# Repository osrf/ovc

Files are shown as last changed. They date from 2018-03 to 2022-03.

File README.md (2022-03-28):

# Open Vision Computer (OVC)

Here is an outdated-but-maybe-interesting [overview presentation of the project](https://docs.google.com/presentation/d/1NCimNJTRP6g3ESWhmaqi4t3dOprq7Yvne_JLeCTt3io/edit?usp=sharing) (March 2018).

This repo contains hardware, firmware, and software for an open-source embedded
vision system: the Open Vision Computer (OVC). The goal is to connect state of
the art open hardware with open firmware and software. There are a few revs:

 * ovc0: three Python1300 imagers, an Artix-7 FPGA, DRAM, and USB3 via a Cypress FX3 controller.
 * ovc1: two Python1300 imagers, a Jetson TX2 (6x ARMv8, GPU, etc.) connected to a Cyclone-V GT FPGA over PCIe.
 * [ovc2](doc/ovc2a/README.md): two Python1300 imagers, a Jetson TX2 (6x ARMv8, GPU, etc.) connected to a Cyclone 10 GX FPGA over PCIe Gen 2.0 x4
 * ovc3: three ON Semi AR0144CS imagers, USB Type-C peripheral, Trenz TE0820 module with Xilinx Zynq UltraScale+, RAM, flash, etc. Up to four optional external camera boards, each of which add a pair of AR0144CS imagers.
 * ovc4: A Jetson Xavier NX carrier board with an NXP MCU, USB Type-C interface and six Picam compatible connectors.
 * ovc5 (current work): based on Zynq UltraScale+ modules from Enclustra, with up to six external MIPI camera boards. Both Zynq USB SuperSpeed (5 Gbps) transceivers connect to an onboard USB-SS+ (10 Gbps) hub controller IC, which multiplexes them upstream via a USB type-C connector. Also has three Qwiic/STEMMA connectors and some random FPGA GPIO for low-speed expansion.

# Where do I find stuff

Each camera family has its own directory in this repository that contains its relevant hardware, firmware, and software.

# Hardware Design

We are using the very latest KiCAD: the nightly development builds.
Installation instructions are here: https://www.kicad.org/download/ubuntu/

Once you have installed `kicad-nightly` on your machine, then you will
need to set up the repos as follows:

```
mkdir ~/hw
cd ~/hw
git clone ssh://git@github.com/osrf/osrf_hw
git clone ssh://git@github.com/osrf/ovc
```

Add the following line to your .bashrc file to set the KIWORKSPACE environment variable to point at your hardware folder:

```
export KIWORKSPACE=~/hw
```

Then you should be able to view the latest developments:
```
cd ~/hw/ovc/ovc5/hardware/carrier
kicad-nightly ovc5.kicad_pro
```

---

#### Software License
[Apache Version 2.0](https://github.com/osrf/ovc/blob/master/LICENSE)

#### Hardware License
[CERN-OHL-P](https://github.com/osrf/ovc/blob/master/LICENSE_HARDWARE)

#### Documentation License
<br />This work is licensed under a <a rel="license" href="http://creativecommons.org/licenses/by/4.0/">Creative Commons Attribution 4.0 International License</a>.

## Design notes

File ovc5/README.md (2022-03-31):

# ovc5

The OVC5 is basically a 6 port USB3 Gen 2 (10 Gbps) hub with the following devices:
* 2x USB3 Gen 1 (5 Gbps) ethernet over USB devices, assigned to subnets 10.0.1.x and 10.0.2.x, connected to the Zynq and used to stream the imagers in parallel.
* 2x USB3 Gen 2 (10 Gbps) ports available for connection to third party devices, currently because of hardware quirks they are one USB A (on the top connector) and one USB C.
* 1x USB2 device connected to the onboard FTDI chip for serial debugging of the Zynq.
* 1x unused port (not routed).
* 3x Extra connectors following the STEMMA / QWIIC standard for quick integration of external devices.

It is also fully modular and any configuration of sensors can be plugged to the MIPI connectors, they will be detected at runtime and streamed over USB, provided a driver has been written for them, a reference driver is provided for the PI camera v2 based on IMX219.
The idea is that OVC5 can be a single sensor integration center for mobile robot applications (i.e. robot heads) which can synchronize and stream up to 10 Gbps of heterogeneous data coming from a variety of sensors over a single USB connection. Since OVC5 is a USB hub and exposes two downstream ports while only using one, it actually increases the number of ports available to whatever processing system it connects to, rather than decreasing it.

## Directory Summary
* __Hardware__: PCB schematic and layout is here. This project uses `kicad-nightly`.
* __Firmware__: FPGA source is located here. This project uses the Xilinx Ultrascale+ chipset. Vivado is used to design and export the bitstream that executes on the FPGA.
* __Scripts__: These are convenience scripts for automating large portions of the setup and run-time process.
* __Software__: Software that runs on the host and the arm core to pass sensor information.

## Setup Process
1. After assembling OVC5, use the [provisioning script](https://github.com/osrf/ovc/blob/master/ovc5/scripts/install_sd.sh) to generate an SD card image. This can then be loaded into the OVC5 device port.
2. Connect power and (optionally ethernet) to the device. The ethernet should be connected to the same LAN as your computer.
3. Connect the OVC5 to a USB3 Super Speed (preferably 10Gbps capable) port. This will provide the correct bandwidth for streaming high resolution/framerate images. Because of a quirk in the USB hub chip and its flexconnect feature not quite working yet, you will need to connect using a USB 3 A-A cable to the _bottom_ connector of the USB A stack (the one closer to the PCB).
4. Wait a minute or two and run `ssh root@zynq.local`. You may also attempt to ping it until it responds.
    * The default password, as defined in the provisioning script, is `temppwd`.
5. USB Ethernet should be already up (you can check by running `ip a` on your host machine. If it isn't you can initialize it manually by running the startup script located in the home directory [`startup.sh`](https://github.com/osrf/ovc/blob/master/ovc5/scripts/startup.sh)
6. Use `git` to clone in the latest OVC version. Now compile the [camera device driver](https://github.com/osrf/ovc/tree/master/ovc5/software/camera_device_driver).
7. On the host machine, compile [`libovc`](https://github.com/osrf/ovc/tree/master/ovc5/software/libovc) and the [camera host driver](https://github.com/osrf/ovc/tree/master/ovc5/software/camera_host_driver). This can be accomplished using the [`Makefile`](https://github.com/osrf/ovc/blob/master/ovc5/software/Makefile).
    * __NOTE__: the makefile `all` target compiles the camera driver as well. This is just to sanity check when not editing on an OVC device. Remove `device_driver` from all or install `i2c-tools` to not fail this build step.

## Execution
1. On the host machine, run `make run_host`. This creates a server for OVC5 to connect to.
2. On OVC5 (via ssh), run (from software) `./camera_device_driver/build/ovc5_driver`. This connects to the host server and immediately starts streaming sensor data.
3. To stop execution, use `ctrl + C`. Always stop execution on the device first otherwise sensors will not be reset properly. This can cause abnormal behavior in the following execution (unless power is reset or the script is properly exited in the following execution).

## Renders
ovc5b_rendering

## Pictures
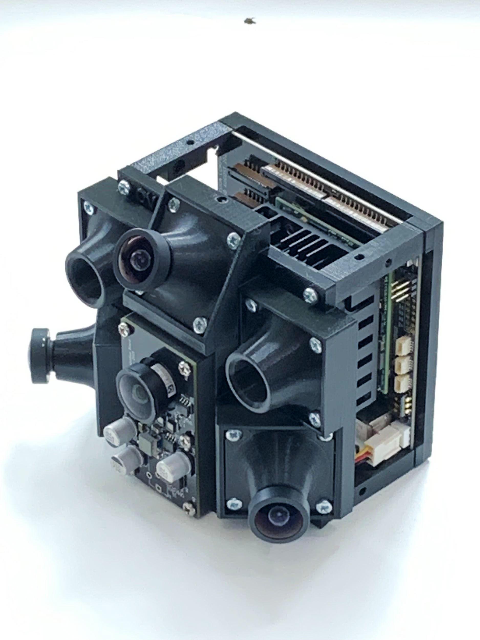
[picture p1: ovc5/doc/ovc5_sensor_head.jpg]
ovc5 sensor_head


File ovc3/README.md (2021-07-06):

# OVC 3 overview
OVC3 includes a Zynq Ultrascale+ SoC, with a quad core ARM application processor, two real time cores and FPGA fabric.
Currently the real time cores are not used, the quad core processor runs a full Ubuntu 18.04 distribution with ROS melodic and the FPGA fabric runs the interfaces to the imagers (through MIPI / I2C), the IMU (SPI) and the DMA to write data to external memory.

# Version notes

There are currently two versions of the OVC3
 - OVC3a: this is the old version of the OVC3. **Do not use unless you know what you are doing**. The firmware does not support this board, and you may damage your hardware.
 - OVC3b: most recent version of the OVC3. Changes compared to OVC3a:
   - Various hardware fixes. See `ovc/ovc3/hardware/ovc3a/ovc3a/camera/FIXME`
   - VectorNav carrier is mounted in the front of the platform.
   - More GPIO for the backpack.

## Setup

OVC 3 is running a full Ubuntu distribution and a ROS node in itself.
On startup, it will configure itself as a USB ethernet gadget with a static IP of 10.0.1.1 and ia DHCP server that will assign an IP of 10.0.1.2 to the connected host, it will then look for a ROS master in 10.0.1.2, once it is found it will start publishing images, IMU data, corner features and calibration data.

**The board should automatically assign an IP to your machine**, however if this doesn't work you can manually configure your PC to have a static IP.
To do so, edit your /etc/network/interfaces file and add the following:

~~~~
allow-hotplug enp9s0u1
iface enp9s0u1 inet static
  address 10.0.1.2
  netmask 255.255.255.0
  mtu 13500
  pre-up sleep 5 # Hack to wait for ovc networking to restart
~~~~

Please note, the name of the interface (enp9s0u1 in the example) might be different on your machine, to find out the interface name plug the OVC, wait for it to boot up and run

`ip a`

on your machine.

## Calibrating the sensor

The OVC is running a camera_info_manager, hence it exposes services to calibrate the camera and store the parameters in non volatile memory (they will be saved in the calibration subfolder of the driver).

To calibrate run the following command for the two monochrome sensors:

`rosrun camera_calibration cameracalibrator.py --size 8x6 --square 0.072 right:=/ovc/right/image_raw left:=/ovc/left/image_raw right_camera:=/ovc/right left_camera:=/ovc/left`

And the following for the RGB sensor:

`rosrun camera_calibration cameracalibrator.py --size 8x6 --square 0.072 image:=/ovc/rgb/image_raw -c rgb camera:=/ovc/rgb`

With the size and square parameters adapted to your checkerboard.

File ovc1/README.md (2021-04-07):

# ovc1

#### Update source tree
```
cd ~/ovc
git pull
```

#### Compile kernel module
```
cd ~/ovc/software/ovc1/ovc_module
make
```

#### Flash FPGA i/o image and reconfigure FPGA
The OVC1 uses a configuration microcontroller to set up the FPGA I/O ring to
allow PCIe-based configuration. This is great because it's super-fast, but it's
a bit more complicated because the FPGA image lives partly in the
microcontroller flash memory, and partly in the TX2 filesystem. As such, there
are a multiple steps to updating the FPGA image. Fortunately, the FPGA I/O
image should only change infrequently. Note that the microcontroller-flash
script only needs to be run when the FPGA I/O image changes; most updates
affect only the FPGA core, not the I/O ring.

```
cd ~/scripts
./flash_fpga_config.sh
./reconfigure_fpga.sh
```

#### Compile ROS package (userland)
```
mkdir -p ~/ros/src
ln -s ~/ovc/software/ovc1/ros/ovc ~/ros/src
cd ~/ros
catkin build
```

# Software development

For a typical software-development session (unless you need to re-flash and reconfigure the FPGA) you just need to load the kernel module. We'll automate this eventually, once it gets more stable, but for now (to avoid boot loops) let's leave the module-loading as a manual step...
```
~/scripts/init_fpga.sh
```
That script will load the OVC kernel module, configure the FPGA core using the blob in `~/ovc/firmware/ovc1/fpga/stable/ovc.core.rbf`, and re-load the OVC module to allocate DMA buffers.

Then, you can run the ROS image streamer and feature-visualizer nodes:

Terminal 1:
```
roscore
```

Terminal 2:
```
cd ~/ros
source devel/setup.bash
rosrun ovc ovc_node
```

Terminal 3:
```
rosrun ovc corner_viewer
```

I'm usually shelling into the camera and run "Terminal 3" on my workstation,
setting `ROS_MASTER_URI` as needed to point to the camera (adjust the camera
hostname as needed, if you have changed it from the default `tegra-ubuntu`):
```
export ROS_MASTER_URI=http://ovc.local:11311
rosrun ovc corner_viewer
```

#### Re-flashing MCU (uncommon)
In the event that the MCU is somehow horribly messed up and needs a total
re-flash, you can do the following actions to restore it, using the handy
`stm32flash` program. Unfortunately, because we're using a relatively new
MCU (STM32L452) we need to build it from souce, but it's not hard:
```
mkdir ~/mcu
cd ~/mcu
git clone https://git.code.sf.net/p/stm32flash/code stm32flash
cd stm32flash
make
```

First, we need to do a "button dance" in order to boot the MCU into its
bootloader. Note that the buttons are tiny. Be sure to ground yourself using
either a wrist-strap or diligently touching the HDMI connector shield before
risking unloading your body's static charge into the tiny components near
the buttons!
 * press and hold the `MCU_RESET` button
 * press and hold the `MCU_BOOT` button
 * release `MCU_RESET`
 * release `MCU_BOOT`
If done correctly, the MCU LED should light up. You can verify that the MCU
is in bootloader mode by querying it with `stm32flash`:
```
~/mcu/stm32flash/stm32flash /dev/ttyTHS1
```
If the MCU is alive and in bootloader mode, that command should print out some
information about the memory banks of the STM32.

Now, we can restore the MCU flash bank. First, make sure your checkout of the
`ovc` repo is up-to-date. On a TX2 shell:
```
cd ~/ovc
git pull
```
There should be a MCU firmware blob sitting in `~/ovc/firmware/ovc1/mcu/stable`
that we will now flash to the MCU:
```
~/mcu/stm32flash/stm32flash -v -w ~/ovc/firmware/ovc1/mcu/stable/ovc1_mcu.bin /dev/ttyTHS1
```
Once that operation has completed, you can push the `MCU_RESET` button and then
flash the FPGA I/O ring configuration:
```
~/ovc/software/ovc1/scripts/flash_fpga_config.sh
```
Then you should be able to configure the FPGA:
```
~/ovc/software/ovc1/scripts/reconfigure_fpga.sh
```
If all goes well, `lspci` should show the FPGA connected as device `1234:5678`

Hooray!

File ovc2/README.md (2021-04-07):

# ovc2

On the OVC2, the TX2 simply configures the FPGA over SPI. Because there are
no flash memories outside the TX2, the update process is considerably simpler
than on the OVC1.

#### Update source tree
```
cd ~/ovc
git pull
```

#### Compile kernel module
```
cd ~/ovc/software/ovc2/modules/ovc2_core
make
cd ~/ovc/software/ovc2/modules/ovc2_cfg
make
```
In case there is a compilation error for ovc2_core, try
```
cd /usr/src/linux-headers-4.4.38-tegra/
sudo make modules_prepare
```

#### Compile ROS package (userland)
```
mkdir -p ~/ros/src
ln -s ~/ovc/software/ovc2/ros/ovc2 ~/ros/src
cd ~/ros
catkin build
```

# how do I run stuff

For convenience, the `~/.bashrc` of the default `nvidia` user adds
`~/ovc/software/ovc2/scripts` to `$PATH`. Create a link for the `ovc2a.rbf` file (located at `~/ovc/firmware/ovc2/stable`) at the home folder.

Typically, all you need to run is the `ovc2_reconfigure` script, which does
the following:
 * unloads modules which use PCIe
 * loads the `ovc2_cfg` module, which creates a device node `/dev/ovc2_cfg` to expose a configuration interface to userland
 * writes the FPGA configuration from userland to the `/dev/ovc2_cfg` device, which in turn uses the TX2 SPI interface to configure the FPGA
 * loads the `pcie_tegra` module, which enumerates the PCIe bus and finds our newly-configured FPGA on it
 * loads the `ovc2_core` module, which provides a userland driver for ovc2 on three device nodes: `/dev/ovc2_core` `/dev/ovc2_cam` `/dev/ovc2_imu`

For a typical software-development session, you typically just type
`ovc2_reconfigure` and it's all automatic.

Then, you can run the ROS image streamer and feature-visualizer nodes:

Terminal 1:
```
roscore
```

Terminal 2:
```
cd ~/ros
source devel/setup.bash
rosrun ovc2 ovc2_node
```

Terminal 3:
```
rosrun ovc2 corner_viewer
```

I'm usually shelling into the camera, so "Terminal 1" and "Terminal 2" are
remote shells on the camera, and "Terminal 3" is running locally on my
workstation, setting `ROS_MASTER_URI` as needed to point to the camera (adjust
the camera hostname as needed):

```
export ROS_MASTER_URI=http://ovc2a3.local:11311
rosrun ovc corner_viewer
```

#### Powering Down

For reasons unknown at the moment, if you try to power down the TX2 without
first unloading the `ovc2_core` kernel module, the system will hang during
the shutdown process, requiring you to then hold the TX2 power button down
until the PMIC finally does a hard-shutdown.

If you run this script instead:
```
ovc2_poweroff
```
It will first unload the `ovc2_core` module and then run `poweroff`. It just
saves one step to type `ovc2_poweroff` instead.

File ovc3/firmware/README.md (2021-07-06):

## Getting started
In order to get the OVC up and running you will need to set up the boot medium, choosing between eMMC and SD card. We have observed better performance and reliability from the embedded eMMC module so it is suggested. SD boot should be used for the first setup and eventual recovery if it becomes impossible to boot from eMMC.

The first step suggested is to create an Ubuntu SD card that can be used to boot the module, and to flash the eMMC and onboard QSPI flash.
All the necessary files can be found [here](https://drive.google.com/drive/u/0/folders/1-6HdKNJr4VVOgUUyit0nssR-HQKv6Tt5). You will need the files:
- `SD images/image.ub`
- `SD images/boot.bin`
- `Flash images/rootfs.tar.gz`

### Creating the recovery SD card
* Follow the [Xilinx guide](https://xilinx-wiki.atlassian.net/wiki/spaces/A/pages/18841655/Prepare+Boot+Medium) to partition the SD card, then copy the image.ub and BOOT.bin files in the SD images into the boot partition.
* Extract the rootfs.tar.gz archive into the root partition (assuming the root was mounted under /media):
`tar -xvpzf rootfs.tar.gz -C /media/root --numeric-owner`.

Now it should be possible to boot through the SD card.

### Flashing the QSPI and eMMC
The rootfs image includes a script that will run on boot and will check the position of the user DIP switches and, if the flashing configuration is selected (booting from SD card - pin 2 HIGH and flashing enabled, pin 4 LOW) it will flash the eMMC with the latest bootable images available in the shared folder.
For the process to be successful, it is necessary that the OVC is connected to the internet, it is configured for DHCP on the ethernet port so connecting the Ethernet port to your router should be enough.

On SD boot the LEDs next to the RGB camera will be used to communicate to the user the status of the update in the following sequence:
1. Only red LED turned on: Flashing mode was detected, waiting for internet connection and downloading files from shared folder.
2. Red and green LEDs turned on: Images downloaded, flashing. Can take quite long (up to 30 minutes in our experiments).
3. Only green LED turned on: Flashing completed, when this happens flip the switch 4 back to HIGH and the board should poweroff (green LED turning off).

### Booting from eMMC
If the above process is successful it should be possible to boot from the onboard QSPI and eMMC without the need to have an SD card. Remove the SD card, flip switch 2 for eMMC boot (LOW) and turn on the board.
If the red LED on the trenz module turns off boot was successful and it should be possible to use the module.

Keep an eye on the shared drive for changes in boot images and rootfs for new features!

## Accessing the board
If anything goes wrong it might be useful to access the board, this can be done in two ways: 
 - Through the root linux console (exposed in the expansion pin header in the back of the board). You may use the `vectornav_carrier` board, which already has a USB-UART bridge.
 **Important: do not start the OVC with the root console connection enabled. It may halt the FSBL. Connect the USB after booting the OVC**.
 - Through SSH
   1. SSH from the usb ethernet interface: `ssh ubuntu@10.0.1.1`
   2. Connect the board to your router and ssh through host name `ssh ubuntu@arm.local`
   3. Same as above but use the IP that you should be able to see in your router control panel.

## Hacking the board and firmware generation
This folder contains all the source files needed to build the project, except the root file system itself (which is a custom version of Ubuntu 18.04 for the armv7 architecture and is only available in the shared drive).

The Vivado project including all the FPGA design can be found in the `test_board` folder, while the Petalinux project containing the kernel and device-tree customizations can be found in the `os` folder. Follow the instructions in `test_board/README.md` to generate the images.

## Board version pinout
**The pinout of the OVC3a is incompatible with the pinout of the OVC3b**. The
table below explains the differences:

|PIN |TE0820 PIN|FPGA PIN|OVC 3A |OVC 3B |
|---|---|---|---|---|
|JB1.69|B66 L24 P |C9 |BONUS1_RESET  |BONUS4_EXTCLK |
|JB1.71|B66 L24 N |B9 |BONUS1_FLASH  |BONUS4_SCL0 |
|JB1.79|B66 L21 P |A7 |AUX0 |BONUS4_SDA0 |
|JB1.81|B66 L21 N |A6 |AUX1 |BONUS4_SCL1 |
|JB1.85|B66 L19 N |A5 |NC |BONUS4_SDA1 |
|JB1.87|B66 L19 P |B5 |NC |BONUS4_FLASH  |
|JB1.97|B66 L9 N  |A3 |AUX2 |BONUS4_RESET  |
|JB1.99|B66 L9P |B3 |AUX 3 |BONUS4_TRIGGER|
|JB2.76|B64 L10 P |AG6 |BONUS4_EXTCLK |BONUS1_RESET  |
|JB2.78|B64 L10 N |AG5 |BONUS4_SCL0 |BONUS1_FLASH  |
|JB2.85|B64 L6 P  |AB6 |BONUS4_SDA0 |FRONT_AUX0 |
|JB2.87|B64 L6 N  |AC6 |BONUS4_SCL1 |FRONT_AUX1 |
|JB2.90|B64 T0 |AD6 |BONUS4_SDA1 |FRONT_AUX5 |
|JB2.91|B64 L24 P |AF1 |BONUS4_RESET  |FRONT_AUX2 |
|JB2.93|B64 L24 N |AG1 |BONUS4_FLASH  |FRONT_AUX3 |
|JB2.99|B64_T1 |AH6 |BONUS4_TRIGGER|FRONT_AUX4 |
|JB3.41|B65 L5 P  |R7 |NC |GPIO18 |
|JB3.43|B65 L5 N  |T7 |NC |GPIO19 |

## GPIO exposed in Linux
GPIO are exposed in Linux, and may be modified using the `/sys/class/gpio/`
folder. **GPIO start with 338**. See [this
page](https://xilinx-wiki.atlassian.net/wiki/spaces/A/pages/18842398/Linux+GPIO+Driver). 
There are two GPIOs: MIO and EMIO.

### MIO
MIO starts at 26. For our board, this corresponds to 364.

The following table provides the mapping between the MIO GPIO and the exposed
Linux system file.

|ZYNQ PIN|Linux GPIO|I/O |FPGA PIN |
|---|---|---|---|
|MIO26 |gpio364 |IO Pullup |LED1 |
|MIO27 |gpio365 |IO Pullup |LED0 |
|MIO28 |gpio366 |IO Pullup |LED3 |
|MIO29 |gpio367 |IO Pullup |LED2 |
|MIO30 | |IO Pullup |ROOT RX |
|MIO31 | |IO Pullup |ROOT TX |
|MIO32 | |IO Pullup |USB SCL - STUSB4500  |
|MIO33 | |IO Pullup |USB SDA - STUSB4500  |
|MIO38 | |IO Pullup |USB SCL - SI5338 |
|MIO39 | |IO Pullup |USB SDA - SI5338 |

### EMIO
EMIO starts at 78. For our board thus, GPIO[0] corresponds to gpio416.

The following table provides the mapping between the EMIO GPIO and the exposed
Linux system file, as well as the current mapping for OVC3B.

|ZYNQ PIN|Linux GPIO|I/O |FPGA PIN |
|---|---|---|---|
|EMIO0 |gpio416 |Input |DIP_SWITCH |
|EMIO1 |gpio417 |Input |FRONT_AUX4 (VN sync) |
|EMIO2 |gpio418 |Input |GPIO0 |
|EMIO3 |gpio419 |Input |GPIO2 |
|EMIO4 |gpio420 |Input |GPIO3 |
|EMIO5 |gpio421 |Output  |GPIO6 |
|EMIO6 |gpio422 |Output  |GPIO4 |
|EMIO7 |gpio423 |Output  |GPIO5 |
|EMIO8 |gpio424 |Output  |GPIO10 |
|EMIO9 |gpio425 |Output  |GPIO12 |
|EMIO10  |gpio426 |Output  |GPIO13[3] |
|EMIO11  |gpio427 |Output  |GPIO13[2] |
|EMIO12  |gpio428 |Output  |GPIO13[1] |
|EMIO13  |gpio428 |Output  |GPIO13[0] |

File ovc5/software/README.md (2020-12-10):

# OVC5 software

The first quest is to set up a microSD card to boot the Zynq chip.
Because the Zynq has a complex many-tiered boot process that starts with on-chip ROM, the microSD card must be set up very carefully to match what the first-stage ROM loader needs to see when it boots.
The following sections will walk through all of these steps exactly.

## Set up microSD card partitions

This guide follows along a [Xilinx guide](https://xilinx-wiki.atlassian.net/wiki/spaces/A/pages/18841655/Prepare+Boot+Medium) which has more details.

First make very very very very sure that you know the device name of your SD card when it's plugged into your host machine.
Mine shows up as `/dev/sdc` but this will depend on how many disks are in your machine.
These instructions will use `/dev/sdX` to prevent accidental copy-paste-pray from utterly destroying your filesystem; you must replace `/dev/sdX` with the actual device name for your microSD card.
The easiest way is usually to insert the card, then run `dmesg | tail` and read a few lines to see what's going on.

Let's blow away the partition table:

```
sudo dd if=/dev/zero of=/dev/sdX bs=1024 count=1
```

Now let's create some partitions:
```
sudo fdisk /dev/sdX
```

Here are the steps within `fdisk` to create the partitions we need:
* `n` create new partition
* `p` primary partition
* `1` first partition
* `[ENTER]` select automatic first available starting position for this partition
* `+200M` set size to 200 megabytes

* `n` create another new partition
* `p` primary parition
* `2` second partition
* `[ENTER]` select automatic next available starting position for this partition
* `[ENTER]` select automatic maximum available size for this partition

* `a` toggle bootable flag
* `1` partition 1

* `t` change partition type
* `1` partition 1
* `c` set to FAT32 (LBA)

* `t` change partition type
* `2` partition 2
* `83` the magic number for a Linux partition

Now you can type `p` in the `fdisk` terminal to print the partition table.
It should look something like this, but depending on the size of your microSD card, the numbers may vary somewhat:
```
Command (m for help): p
Disk /dev/sdc: 29.74 GiB, 31914983424 bytes, 62333952 sectors
Disk model: SD/MMC
Units: sectors of 1 * 512 = 512 bytes
Sector size (logical/physical): 512 bytes / 512 bytes
I/O size (minimum/optimal): 512 bytes / 512 bytes
Disklabel type: dos
Disk identifier: 0xb5acc679

Device     Boot  Start      End  Sectors  Size Id Type
/dev/sdc1  *      2048   411647   409600  200M  c W95 FAT32 (LBA)
/dev/sdc2       411648 62333951 61922304 29.5G 83 Linux
```

If all looks well, type `w` to write the partition table and exit `fdisk`

## Set up microSD card filesystems

As before, you'll need to substitute the exact device name on your system in place of `/dev/sdX` in the following terminal snippets.

First, a FAT32 filesystem named `boot` in the first partition:
```
sudo mkfs.vfat -F 32 -n boot /dev/sdX1
```

Next, an `ext4` filesystem named `root` in the second partition:
```
sudo mkfs.ext4 -L root /dev/sdX2
```

## Populate the boot partition
Mount the boot partition and copy in the magic `boot.bin` file, which contains the first stage (FSBL) and second stage (u-boot) bootloader images and various helper files.
Then we'll install the u-boot script `boot.scr` and finally the actual kernel image `image.ub`
Adjust paths/filenames as needed for your setup:
```
sudo mkdir -p /mnt/boot
sudo mount /dev/sdX1 /mnt/boot
sudo cp boot.bin /mnt/boot/
sudo cp boot.scr /mnt/boot/
sudo cp image.ub /mnt/boot/
sudo umount /mnt/boot
```

## Create root filesystem
Let's create a debian userland:
```
sudo mount /dev/sdX2 /mnt/zynqroot
sudo apt install qemu-user-static debootstrap debian-archive-keyring schroot
sudo apt-key add /usr/share/keyrings/debian-archive-keyring.gpg
sudo qemu-debootstrap --arch=arm64 --keyring /usr/share/keyrings/debian-archive-keyring.gpg --variant=buildd buster /mnt/zynqroot http://ftp.debian.org/debian
```

Now we need to go inside the userland and configure some stuff.
We'll use `schroot` following along from [this doc](http://logan.tw/posts/2017/01/21/introduction-to-qemu-debootstrap/)
```
echo "[arm64-debian]
description=Debian Buster (arm64)
directory=/mnt/zynqroot
root-users=$(whoami)
users=$(whoami)
type=directory" | sudo tee /etc/schroot/chroot.d/arm64-debian
```
IMPORTANT!!! You have to go into `/etc/schroot/default/nssdatabases` and comment out the following lines, in order to be able to set root password, create user, etc., inside the chroot:
```
#passwd
#shadow
#group
```

Now, let's enter the debian userland we're creating and install some stuff:
```
schroot -c arm64-debian -u root
echo zynq > /etc/hostname
passwd  # now enter a root password
apt install vim locales openssh-server ifupdown net-tools iputils-ping avahi-autoipd avahi-daemon haveged i2c-tools rsyslog
dpkg-reconfigure locales  # this is interactive; en_US.UTF-8 was number 158 for me
# append ttyPS0 to /etc/securetty
# append this to /etc/network/interfaces:
#   auto lo eth0
#   allow-hotplug eth0
#   iface lo inet loopback
#   iface eth0 inet dhcp
```

Allow root login via password by editing this file:
```
vim /etc/ssh/sshd_config
```
Change the line `PermitRootLogin` so that it looks like:
```
PermitRootLogin yes
```
Also, must uncomment `PasswordAuthentication yes`
```
PasswordAuthentication yes
```

Now exit `schroot`:
```
exit
```

Unmount the rootfs:
```
sudo umount /mnt/zynqroot
```

You should now be able to put the microSD card in the ST1 board and it should boot to a working userland.

TODO: fix a few minor things at some point:
* `/etc/debian_chroot` should probably be removed from the filesystem
* `/etc/hosts` should have an entry for the hostname (zynq)

## Installing OVC5 software

Let's create a user account on the device (substitute your desired username for USERNAME):
```
ssh root@zynq.local
apt install sudo
adduser USERNAME
usermod -aG adm,sudo,plugdev,i2c USERNAME
exit
ssh-copy-id USERNAME@zynq.local
```

Now we can shell into our new user account, create some keys, and install things:
```
ssh USERNAME@zynq.local
apt install python3-smbus git
ssh-keygen
cat ~/.ssh/id_rsa.pub
# log in to GitHub and add this key to your account, if you like convenience
git clone ssh://git@github.com/osrf/ovc
```

## Petalinux magic

```
# change system block diagram as needed
# run synthesis
# open schematic as needed and map schematic pins to physical pins
# File->Export->Hardware... then choose "Pre-Synthesis" (the default)
# copy hardware description into petalinux project directory
# otherwise, if you actually have a template: petalinux-create -t project -n awesome --template TEMPLATE.bsp
petalinux-config --get-hw-description
petalinux-build
```

#### fix for u-boot failures due to old template

Just for now... we have to edit the u-boot emmc.patch to allow the patch to succeed for drivers/mmc/sdhci.c  as a temporary workaround, just copy the expected line in the patch file into the source line in sdhci.c, which will allow the patch to succeed (with a warning).

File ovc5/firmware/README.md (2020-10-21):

# OVC5

Currently this concept is based on an Enclustra Mercury+ [XU9](https://www.enclustra.com/en/products/system-on-chip-modules/mercury-xu9/) module:
* Xilinx [XCZU4CG-1FBVB900E](https://www.xilinx.com/products/silicon-devices/soc/zynq-ultrascale-mpsoc.html) UltraScale+ MPSoC FPGA
  * dual-core ARM Cortex-A53 (64-bit)
  * dual-core ARM Cortex-R5 (32-bit)
  * two GbE interfaces
  * two USB 3.0 interfaces
  * two USB 2.0 interfaces (dual-role)
  * lots of low-speed peripherals for the ARM cores
  * 16 high-speed GTH transceivers (16 Gbit)
* 2 GB DDR4 ECC SDRAM for FPGA PS, 72-bit width
* 2 GB DDR4 SDRAM for FPGA PL, 64-bit width
* lots of "normal" I/O
* 64 MB QSPI flash
* 16 GB eMMC flash

### MIPI RX
The XU9 module's Zynq UltraScale+ FPGA is capable of "native" MIPI CSI reception without needing any external resistor networks.

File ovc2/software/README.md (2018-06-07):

IMU UART shows up in TX2 userland as /dev/ttyTHS2

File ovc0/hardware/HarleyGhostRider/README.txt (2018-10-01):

Project: harley_ghost_rider, rev. A
=====================
PCB Fabrication notes:
=====================
* Lead time: 4 days
* Fab quantity: full panel yield (presumably this will be 20 or so?)
* Board outline is a rectangle, 1.301" x 1.397"
* 10 layers
* micro-vias between the outermost layers (layers 1+2, and layer 9+10).
* All other vias are through-vias.
* 62 mil PCB thickness
* Copper weights are not critical (everything is relatively low-power). However, impedances are important due to DDR3 and other high-speed traces.
* stackup was started using the included "stackup.pdf" report generated by Sierra's "HDI Stackup Planner" website. We do require the following impedances for these trace widths and layer pairs (+/- 10%)
  * layer 1:  signal, 5mil traces => 50 ohm
  * layer 2:  solid ground plane
  * layer 3:  signal, 5mil traces => 50 ohm
  * layer 4:  signal, 5mil traces => 50 ohm
  * layer 5:  split power planes
  * layer 6:  split power planes
  * layer 7:  some planes and some 5mil traces => 50 ohm
  * layer 8:  signal, 5mil traces => 50 ohm
  * layer 9:  solid ground plane
  * layer 10: signal, 5mil traces => 50 ohm

* Minimum trace/space is 5mil.
* All holes plated
* Minimum via-drill 7 mil, minimum via-pad 13 mil
* Minimum micro-via drill 6 mil, minimum micro-via pad 13 mil
* FR4 material
* HASL finish
* Green soldermask both sides
* White silkscreen both sides

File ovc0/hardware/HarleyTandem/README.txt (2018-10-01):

Project: harley_tandem, rev. B
(This is a trinocular camera sensor board.)

=============================
PCB Fabrication notes:
=============================
* Lead time: 4 days
* Board outline is a rectangle with a rectangular protrusion on the north side.
* Bounding box is 9.40" x 1.54"
* 6 layers:
  * layer 1 = signal with 7-mil 50-ohm traces relative to layer 2
  * layer 2 = full plane
  * layer 3 = mixed (signal and partial planes)
  * layer 4 = mixed (signal and partial planes)
  * layer 5 = full plane
  * layer 6 = signal with 7-mil 50-ohm traces relative to layer 5
* Controlled stackup, using the included "harley_tandem_stackup_rev_b.pdf" report
  generated by Sierra's "HDI Stackup Planner" website. PLEASE NOTE however that
  I was unable to generate the report I wanted from the website; we want 7-mil
  traces on the outer layers (1 & 6) to be 50 ohm +/- 10% with respect to the
  planes on layers 2 & 5. This will likely need a slightly different stackup
  than that shown on the report.
  * 61mil PCB thickness.
  * 7mil traces on outer layer (1 & 6) need to be 50 ohm +/- 10% with respect to
    the planes on layers 2 & 5. The dielectric thickness between
    layers 1&2 and 5&6 will likely need to be slightly thicker than shown on
    the report to get within 10% (or better) of 50mil impedance.
* Layer thicknesses as specified in the stackup report: { 1, 1, 0.5, 0.5, 1, 1 }
* Minimum trace/space is 5mil.
* All holes plated
* Minimum via-drill 8 mil, minimum via-pad 16 mil. Most vias are >= 24mil
* FR4 material
* HASL finish
* Green soldermask both sides
* White silkscreen both sides
* RoHS processing is fine but not necessary; these are laboratory prototypes.

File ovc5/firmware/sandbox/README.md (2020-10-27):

# Prerequisites

Download Xilinx Vivado WebPack 2020.1:
https://www.xilinx.com/support/download.html

On Ubuntu 20.04, you have to play some games to install Vivado.
[This forum thread](https://forums.xilinx.com/t5/Installation-and-Licensing/Xilinx-Unified-Installer-2020-1-Exception-in-thread-quot-SPLASH/td-p/1114416) describes the issue and what to (temporarily) stuff in `/etc/os-release` so that the installer doesn't crash.
This will be fixed in Vivado 2020.2, but anyway for the time being, this somewhat "interesting" method of temporarily faking `/etc/os-release` works to get it installed on Ubuntu 20.04.

I found it necessary to install this on my machine. YMMV:
```
sudo apt install libtinfo5
```

Install cable drivers (substitute your Xilinx location as needed)
```
cd $HOME/xilinx/Vivado/2020.1/data/xicom/cable_drivers/lin64/install_script/install_drivers
sudo cp *.rules /etc/udev/rules.d
```

Now let's install `nMigen` to make our lives more joyous:
```
pip3 install --user 'git+https://github.com/nmigen/nmigen.git#egg=nmigen[builtin-yosys]'
```

And some analysis stuff:
```
sudo apt install iverilog gtkwave
```

# Goal

Use nMigen to create a minimal MAC that blasts 10G UDP broadcast packets out a SFP+ interface.

```
git submodule init
git submodule update
```

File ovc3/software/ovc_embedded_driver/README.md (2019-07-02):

# ovc_embedded_driver

This is the ROS node that runs on the embedded Ubuntu on the OVC3 to interface between imagers / IMU and any additional hardware and the host system.
Currently it offers the following capabilities:

* Configuration and initialization of ICM-20948 IMU through SPI.
* Configuration of imagers through I2C.
* Synchronization between the two and timestamping.
* Configuration of FAST FPGA corner detector.
* Streaming of all data to ROS topics (IMU, images and corners).

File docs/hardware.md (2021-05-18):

---
layout: default
---

## Hardware and Firmware

The design files for both hardware and firmware can be found in the [main OVC repository](https://github.com/osrf/ovc).

Each OVC version has its own subdirectory with firmware, hardware and software, for example OVC5 files can be found [here](https://github.com/osrf/ovc/tree/master/ovc5).

[KiCad](http://kicad-pcb.org/) is recommended for the hardware schematics files.

[back](./)

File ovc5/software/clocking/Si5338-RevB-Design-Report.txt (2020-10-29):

Overview
========
Part:               Si5338
Project File:
Created By:         ClockBuilder Pro v2.45 [2020-07-16]
Timestamp:          2020-10-29 15:34:49 GMT+08:00

Design Rule Check
=================
Errors:
- No errors

Warnings:
- No warnings

Design
======
Universal Hardware Input Pins:
   P3: CLKIN
   P4: I2C_LSB

Inputs:
    IN3: 100 MHz Single-Ended

Outputs:
   CLK0: Unused
   CLK1: Unused
   CLK2: Unused
   CLK3: 156.25 MHz LVDS 3.3 V 

Frequency Plan
==============
Fpfd = 25 MHz
Fvco = 2.5 GHz

P dividers:
   P0  = 4
   P1  = Unused
M = 100
N dividers:
   N0:
      Unused
   N1:
      Unused
   N2:
      Unused
   N3:
      Value: 16
      CLK3: 156.25 MHz [ 156 + 1/4 MHz ], Error: 0 ppm

R dividers:
   R0 = Unused
   R1 = Unused
   R2 = Unused
   R3 = 1

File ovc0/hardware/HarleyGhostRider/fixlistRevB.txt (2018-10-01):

**Design**
 * LDO footprint is wrong. Chose one of the 6 different suitable components and retroute accordingly
 * FX3 RST RC couple is wrong. Move C from 2.5V to GND
 * Swap I2C lines for flash memory
 * create cutout in ground plane underneath FX3 SS capacitors, as described on p.17 here: 
   http://www.cypress.com/file/139936/download   consider tweaking layout on the east side
   of the capacitors to try to balanace lengths a bit more, if possible... but there is a
   tradeoff between length-skew matching and the number of bends, and I'm not sure which
   is more important in a case like this. I suspect length matching might be more important
   because on p.18 of that document they say that the SS lines need to be within 0.12mm (!),
   which is sort of amazing.
 * check USB-HS lines; p.20 of that document seems to want somewhat different rules than we have
   currently implemented on the USB-HS traces, such as 90-ohm differential trace impedances.
   Not sure though.
 * that document also says to use an "LC circuit" to connect USB3 cable shield to GND. The FX3
   development kit (DVK) schematics show an 0805 ferrite bead BLM21PG221SN1D being used in series
   with the inbound +5V line, which might help reduce noise somewhat. Also, they show a 100nF
   capacitor in parallel with another BLM21PG221SN1D to connect the shield to GND. I guess that's
   the LC circuit they were describing.
 * debug header test points for MONITOR1 would be nice (for dual/triple-slope timing). Doesn't
   need to go back to GhostRider; just oscilloscope probe points on the imager board

**BOM only**
 * Change oscillator frequency from 48MHz to 100MHz (ASMB-100-LY-T) https://github.com/osrf/opencam/blob/master/hardware/Harley/HarleyGhostRider/HarleyGhostRider.csv#L45

**HarleyTandem**
 * series termination resistor needed for the SCLK tree leaving the translator IC. 50 ohm seemed to work OK. Not sure what it should really be.
 * add local LDO's for the imagers to reduce noise. Might need/want a 4v switching supply to feed the LDO's to save some power consumption.

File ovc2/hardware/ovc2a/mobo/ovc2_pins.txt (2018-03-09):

PCIE x2 = 4 pairs + clock pair = 10 wires
5 Passive Serial config = { DCLK, DATA, nCONFIG, nSTATUS, CONF_DONE }
20 power/ground = at least 10 ground, 4 12VDC, 2x 5VDC, 1x 1v8, 2x 3v3
misc i/o: power-good (enable), discharge

need at least 35. Let's go with 40

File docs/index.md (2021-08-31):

---
layout: default
---

# The Open Vision Computer

The Open Vision Computer (OVC) was designed to support high speed, vision
guided autonomous drone flight. In particular our aim was to develop a system
that would be suitable for relatively small-scale flying platforms where size,
weight, power consumption and computational performance were all important
considerations. Our recently submitted manuscript describes the primary features of our OVC
system and explains how they are used to support fully autonomous indoor
and outdoor exploration and navigation operations on our Falcon 250
quadrotor platform. This manuscript can be found on
[arXiv](https://arxiv.org/abs/1809.07674v1).

## OVC1
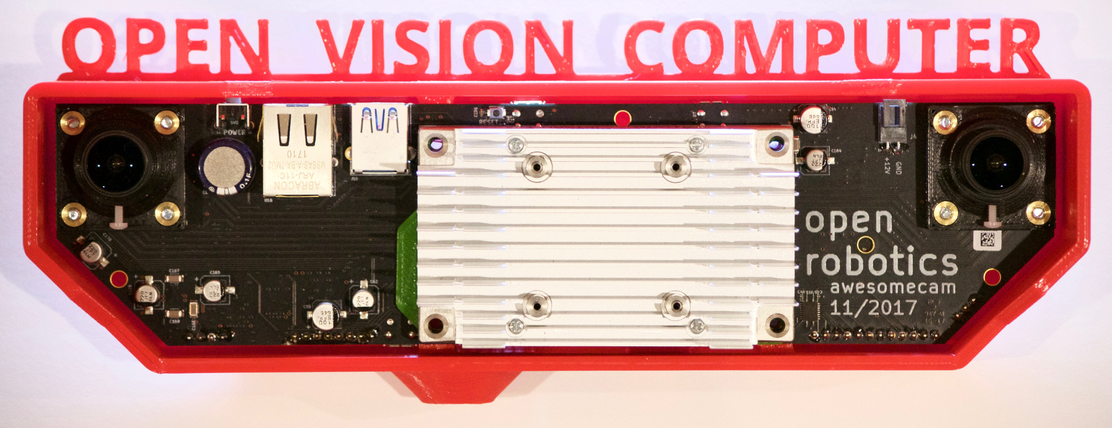
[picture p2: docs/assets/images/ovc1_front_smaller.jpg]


## OVC2
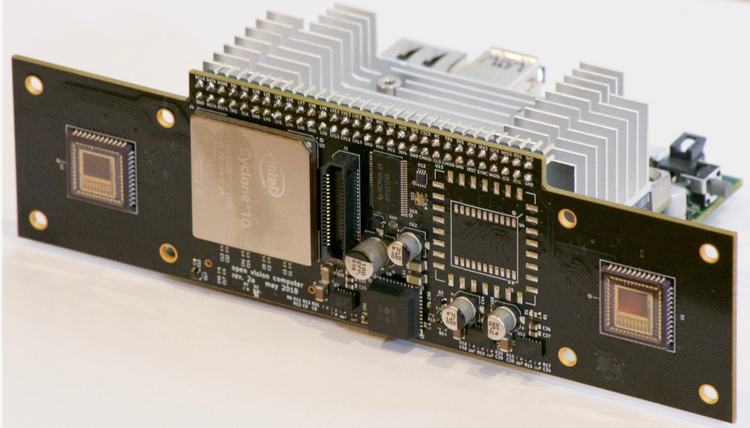
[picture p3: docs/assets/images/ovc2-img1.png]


## OVC3
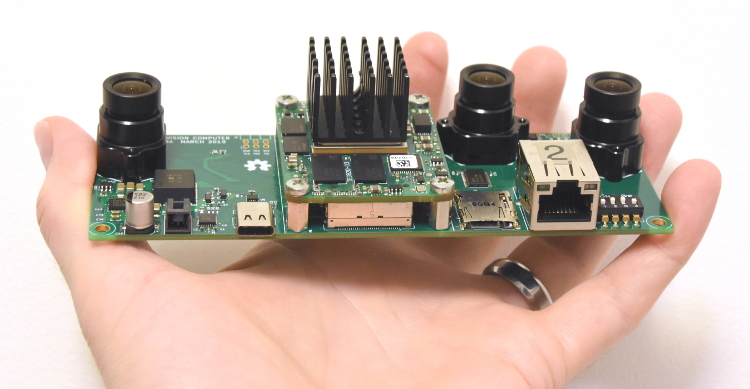
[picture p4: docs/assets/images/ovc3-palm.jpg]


## OVC4
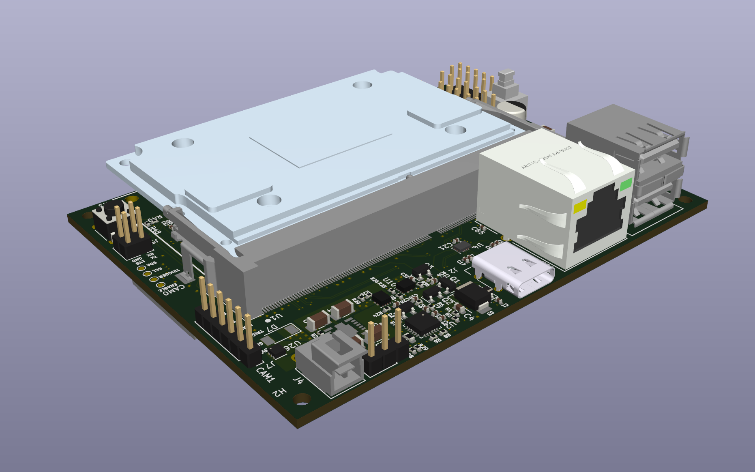
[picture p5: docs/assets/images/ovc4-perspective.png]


## OVC5
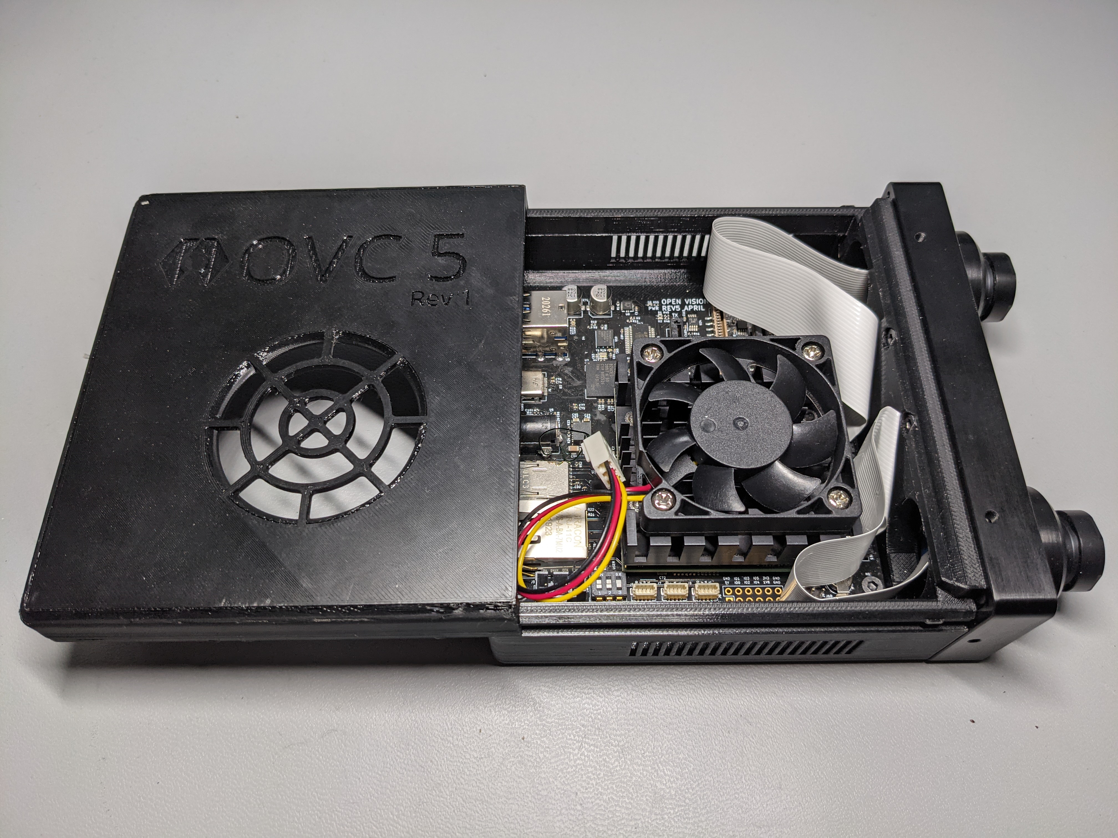
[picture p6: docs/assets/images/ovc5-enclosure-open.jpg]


## [Software Resources](./software.html)

We have made many of our software repositories publicly available, and have been
successfully used on our OVC platforms. We currently have many vision related
tools such as stereo camera rectification, GPU accelerated depth estimation,
deep learning based object segmentation etc.

## [Hardware Resources](./hardware.html)

All resources required to manufacture and assemble these devices is publicly
available on our GitHub repository.

## Media

#### The Open Vision Computer
A brief walkthrough video of the features of the OVC, and it's application to
unmanned aerial vehicles such as the Fast Lightweight Autonomy Falcon 250.
(https://www.youtube.com/watch?v=dMxgNf8cXkI)

#### DARPA Fast Lightweight Autonomy
Project overview of the DARPA Fast Lightweight Autonomy programme, featuring our
unmanned aerial vehicle platform powered by the Open Vision Computer.
(https://www.youtube.com/watch?v=vDYy3L9nvLk)

### Falcon 250 with the OVC
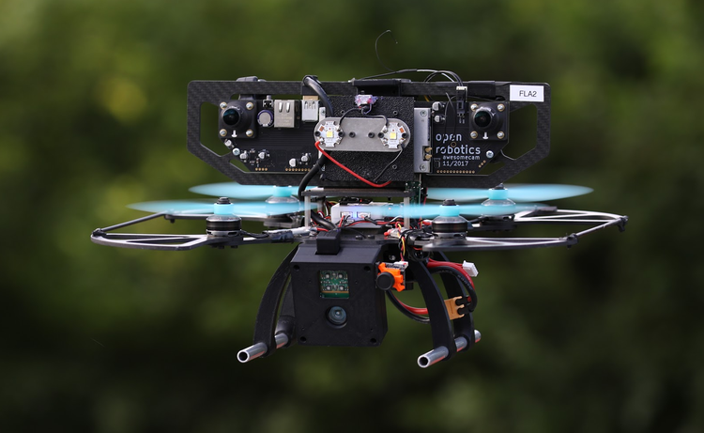
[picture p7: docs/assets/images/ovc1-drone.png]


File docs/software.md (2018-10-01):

---
layout: default
---

## Software

We have a collection of repositories to support the OVC for various computer
vision and robotics related tasks,

### Real-time Semantic Segmentation
<ul>
<li><a href="https://github.com/ShreyasSkandanS/ss_segmentation.git">GitHub</a></li>
<li>Type: ROS | Python | PyTorch</li>
<li>Details: This package is based on ERFNet, a semantic segmentation deep learning
network architecture. We have packaged together a quick and simple way to train
this model on two classes for fast and accurate object segmentation. This
package is designed to work on the OVC platform and we have achieved accurate
object detection results at 10Hz at half the original camera resolution.</li>
</ul>

### Stereo Image Splitter
<ul>
<li><a
href="https://github.com/ShreyasSkandan/splitter.git">GitHub</a></li>
<li>Type: ROS | C++ | OpenCV</li>
<li>Details: This is a simple but useful ROS node to de-couple the single
stacked, synchronized images into two individual synchronized image streams for
both individual imagers.</li>
</ul>

### Stereo Image Rectifier
<ul>
<li><a href="https://github.com/ShreyasSkandanS/stereo_fisheye_rectify.git">GitHub</a></li>
<li>Type: ROS | C++ | OpenCV</li>
<li>Details: For our robotics related applications, we use a pair of wide-angle
lenses for our cameras. This package performs a fisheye rectification of input
images, either in the vertically concatenated stacked format or as synchronized
separate image streams.</li>
</ul>

### GPU Accelerated Dense Stereo Disparity Estimation
<ul>
<li><a
href="https://github.com/ShreyasSkandanS/cuda_sgm_ros.git">GitHub</a></li>
<li>Type: ROS | C++ | OpenCV</li>
<li>Details: A ROS node of the Semi-Global Matching algorithm implemented originally by
Hernandez et. al with a few modifications and a ROS front-end. Performs dense
stereo depth estimation, with point cloud, disparity image and regular 8bit
disparity image topics.</li>
</ul>

### Stereo Visual Inertial Odometry

<ul>
<li>Coming soon..</li>
</ul>

### Multicamera Calibration
<ul>
<li>Coming soon..</li>
</ul>

[back](./)

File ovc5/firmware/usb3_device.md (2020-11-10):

# USB3 SuperSpeed device mode on XU9

There's a lot going on here.
The USB3 device (Type B) connector is J600 on the ST1 board.
The SuperSpeed lanes are routed through a pair of MUXes, U700 and U703, which are controlled by the `USB_MODE0` and `USB_MODE1` DIP switches, respectively.

### `USB_MODE0` set to OFF
With `USB_MODE0` set to `OFF`, the `USB_MODE0` signal is HIGH, which means that the `USBD_SS*` lanes route to port C on U700, which is called `USBMOD_SS*`.
This becomes module pins A136/A140 (TX) and A137/A141 (RX).
These pins are unconnected on the XU9 module.

### `USB_MODE0` set to ON
With `USB_MODE0` set to `ON`, the `USB_MODE0` signal is LOW, which means that the `USBD_SSTX` lanes route to port B on U700, which is called `USBD0_SSTX`.
The `USBD0_SS*` lanes then route to U703.

#### `USB_MODE1` set to OFF
If the `USB_MODE1` DIP switch is OFF, then those signals become `USB0_SS*` and route to the module on pins B32/B36 (RX) and B29/B33 (TX).
Those module pins become FPGA pins H27/H28 (`MGTPS_RX2`) and J25/J26 (`MGTPS_TX2`)

#### `USB_MODE1` set to ON
TBD...

### Clocking
There is a 100 MHz GTR clock on K23/K24 this is `PS_MGTREFCLK2`.

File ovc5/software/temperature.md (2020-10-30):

# temperature notes

raw = `cat /sys/bus/iio/devices/iio\:device0/in_temp0_ps_temp_raw`
offset = `cat /sys/bus/iio/devices/iio\:device0/in_temp0_ps_temp_offset`
scale = `cat /sys/bus/iio/devices/iio\:device0/in_temp0_ps_temp_scale`

temperature = (raw + offset) * scale / 1000

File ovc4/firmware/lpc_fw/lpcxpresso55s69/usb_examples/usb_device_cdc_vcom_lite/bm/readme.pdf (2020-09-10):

## Overview

The Virtual COM project is a simple demonstration program based on the MCUXpresso SDK. It is enumerated as a COM port, which the users can open using terminal tools, such as TeraTerm. The demo echoes back any character it receives. The purpose of this demo is to show how to build a device of USB CDC class and to provide a simple project for further development.

## System Requirement

Hardware requirements

- Mini/micro USB cable
- USB A to micro AB cable
- Hardware (Tower module/base board, and so on) for a specific device
- Personal Computer

Software requirements

- The project files are in:

<MCUXpresso_SDK_Install>/boards/<board>/usb_examples/usb_device_cdc_vcom/<rtos>/<toolchain>.

For lite version, the project files are in:

<MCUXpresso_SDK_Install>/boards/<board>/usb_examples/usb_device_cdc_vcom_lite/<rtos>/<toolchain>.

Note

The <rtos> is Bare Metal or FreeRTOS OS.

## Getting Started

Hardware Settings

Note

Set the hardware jumpers (Tower system/base module) to default settings.

Prepare the example

1. Download the program to the target board.
2. Connect the target board to the external power source (the example is self-powered).
3. Either press the reset button on your board or launch the debugger in your IDE to begin running the demo.
4. Connect a USB cable between the PC host and the USB device port on the board.

Note

For detailed instructions, see the appropriate board User’s Guide.

## Run the example in Windows

1. A COM port is enumerated in the Device Manager. If it prompts for CDC driver installation, see the next chapter to install the CDC driver.
2. Open the COM port in a terminal tool, such as Tera Term.

3. Type characters. The characters are echoed back from the COM port.

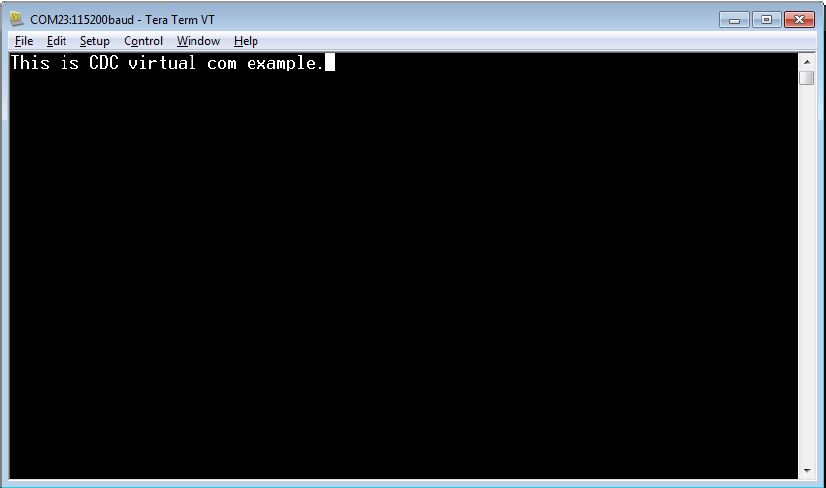
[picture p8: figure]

Figure 1: Run virtual com example

Note

- Because there is no dynamic detection between the host and the device, the COM port must be closed from the terminal tool prior to unplugging the CDC device. Otherwise, the CDC device won’t get recognized next time when plugging in with the COM port still opened.
- If no HW FLOW CONTROL is needed, let the variable start_transactions always be TRUE.
- If the terminal shows ’serial port number failure’, check the ’DTR’ item in terminal configuration window or set the variable s_cdcVcom.startTransactions always be true in code.

## Run the example in Linux/Android

Ubuntu X86 Linux PC

Steps:

1. Connect CDC device to the PC.
2. In the terminal window, run

# ls /dev/tty∗

Then ’/dev/ttyACM0’ is found.

3. In the terminal window, run

# minicom -s

4. To configure the ttyACM0 as the default console and other configurations, run

# minicom

The ttyACM0 can be opened successfully and user can input characters by using the minicom.

i.MX 6DQ board with Yocto rootfs

Steps:

1. Enable the ACM feature and rebuild the kernel.
| Symbol: | USB_ACM [=y] |
| Type : | tristate |
| Prompt: | USB Modem (CDC ACM) support |
| Location: | |

| -> Device Drivers |

| -> USB support (USB_SUPPORT [=y]) |

| (1) -> Support for Host-side USB (USB [=y])

2. Bring up i.MX board with the rebuilt kernel.
3. Plug in the CDC device to the i.MX board.
4. In the i.MX board.

# ls /dev/tty∗

The /dev/ttyACM0 is found.

5. In the i.MX board, a pipe is used to read and write to ttyACM0 because the minicom is not available for yactor rootfs.

# cat /dev/ttyACM0 >> read1 &

# echo "Hello World" > /dev/ttyACM0

# fg

Ctrl+c to interrupt the progress

# vi read1

Result: "Hello world" is in read1.

## Keep alive feature

For SOCs which support the keep alive feature, this example can also be used to demonstrate such feature.
The following steps show how to run it on Windows OS.
1. Check the FSL_FEATURE_USB_KHCI_KEEP_ALIVE_ENABLED macro in <soc>_feature.h to see if the SOC support the keep alive feature.
2. Define USB_DEVICE_CONFIG_KEEP_ALIVE_MODE to 1 in usb_device_config.h.
3. Build the example and run.
4. Open the Debug UART port and Virtual Com port.
5. Wait for a while to ensure that the device has entered into low power mode.
6. Type some characters in the Virtual Com port to exit from the low power mode.

Below is the run-time picture of the keep alive example.

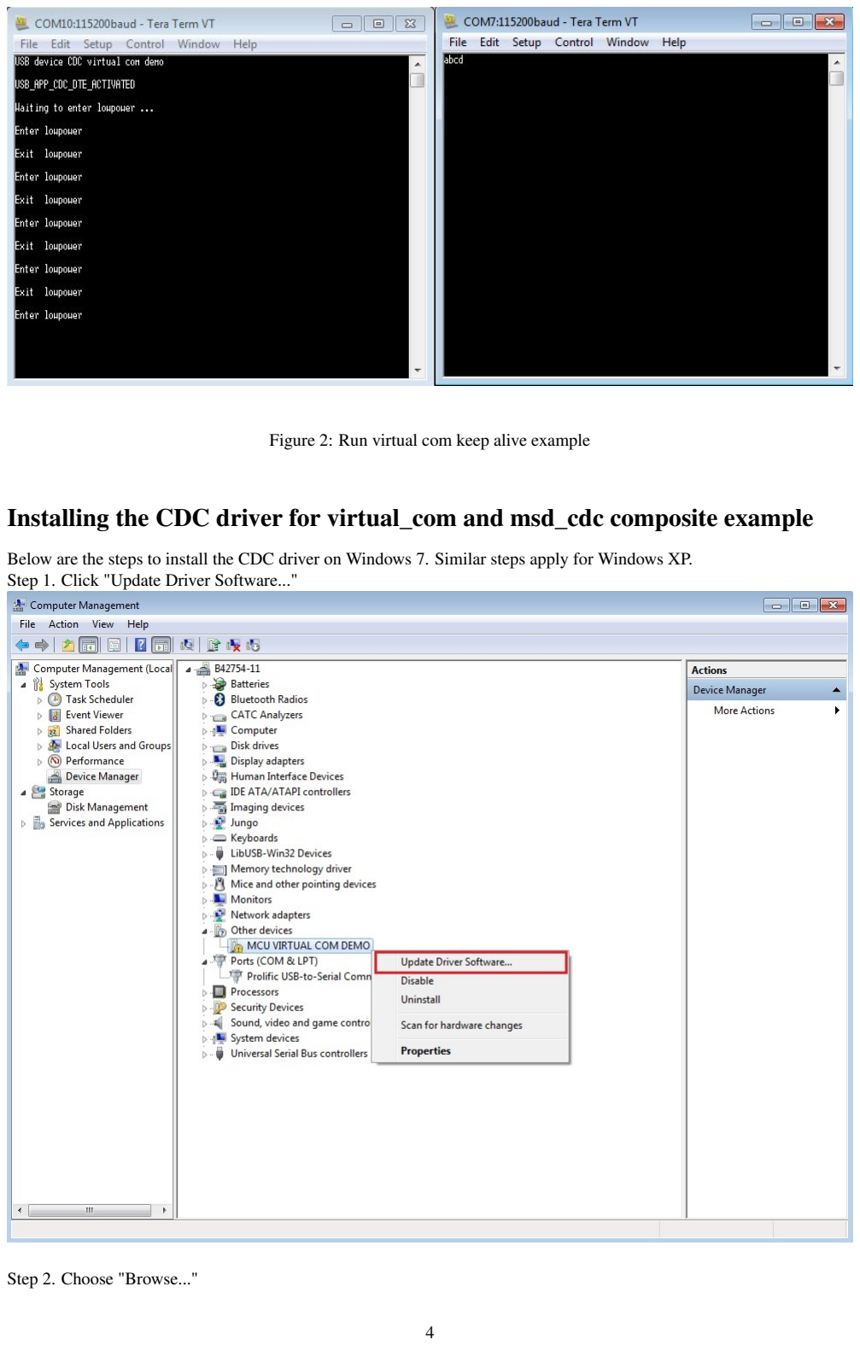
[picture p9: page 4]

Figure 2: Run virtual com keep alive example

## Installing the CDC driver for virtual_com and msd_cdc composite example

Below are the steps to install the CDC driver on Windows 7. Similar steps apply for Windows XP.
Step 1. Click "Update Driver Software..."
Step 2. Choose "Browse..."

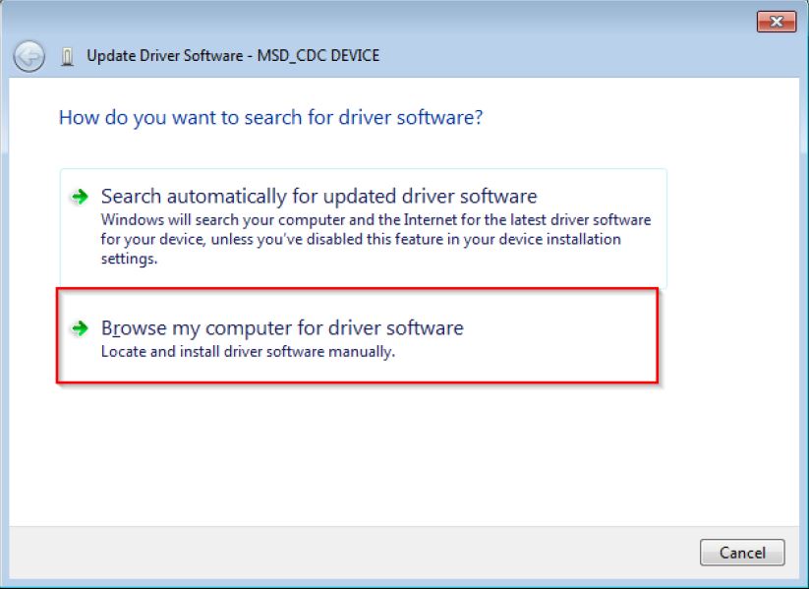
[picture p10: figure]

Step 3. Select "Let me pick..."

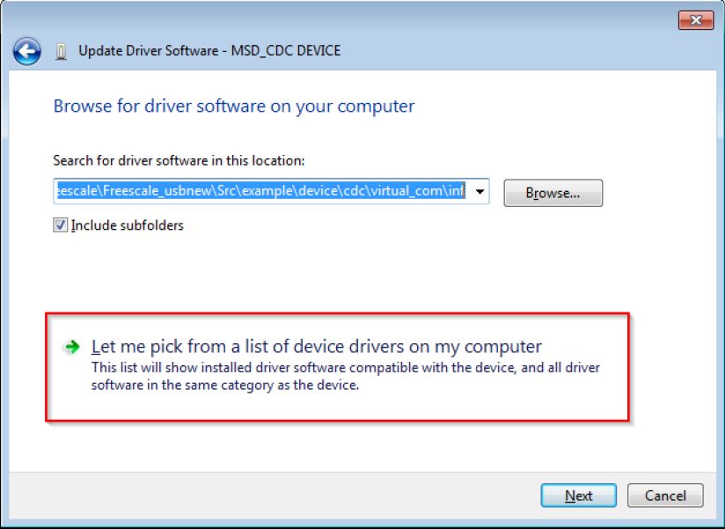
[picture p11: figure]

Step 4. Navigate to your CDC driver location. <install_dir>\boards\<board>\usb_examples\usb_device_cdc_vcom\inf or
<install_dir>\boards\<board>\usb_examples\usb_device_cdc_vcom_lite\inf

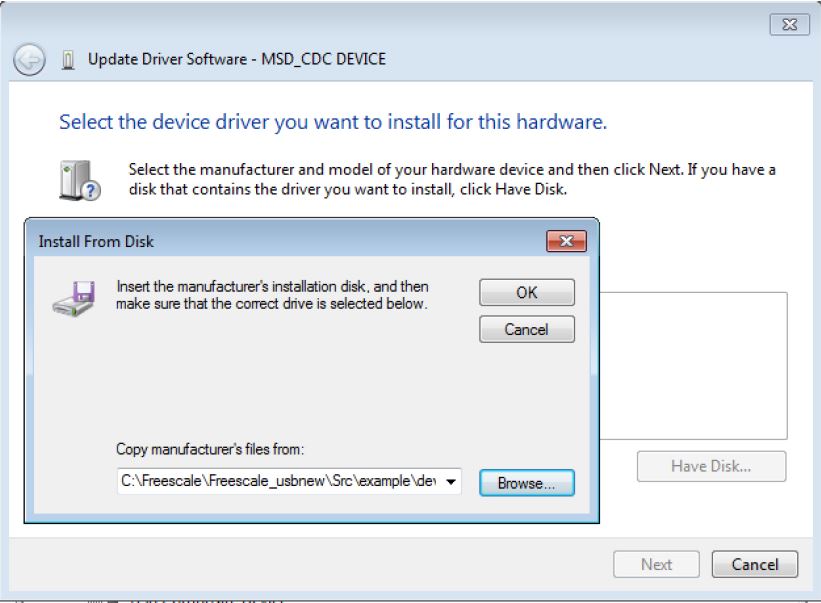
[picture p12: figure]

Step 5. Press "Next".

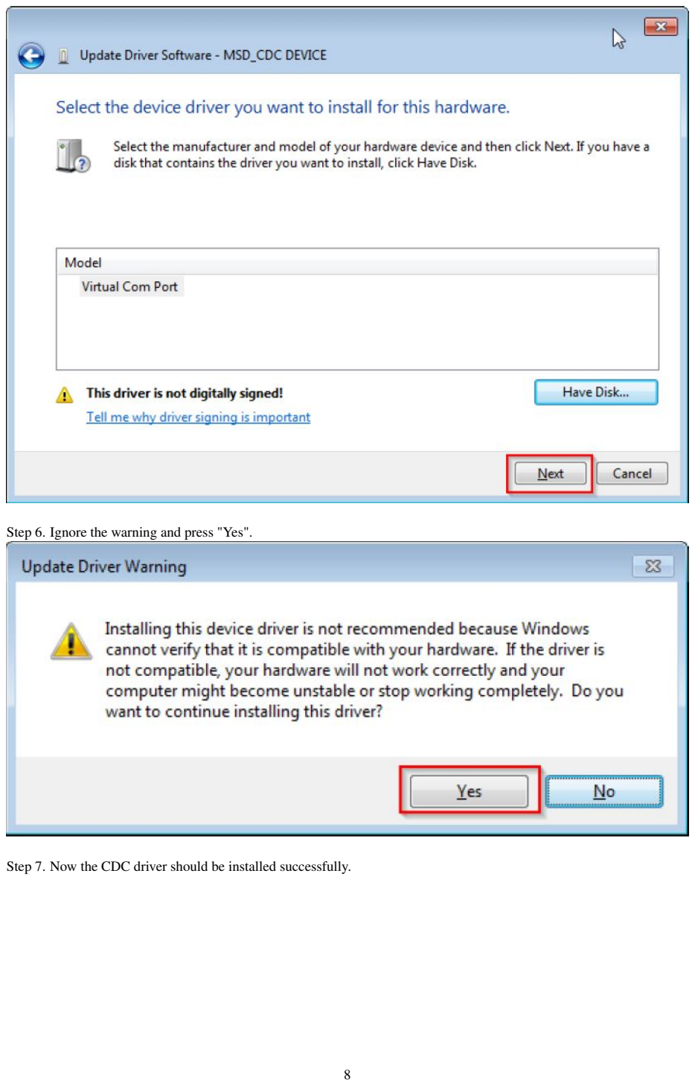
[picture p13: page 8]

Step 6. Ignore the warning and press "Yes".
Step 7. Now the CDC driver should be installed successfully.

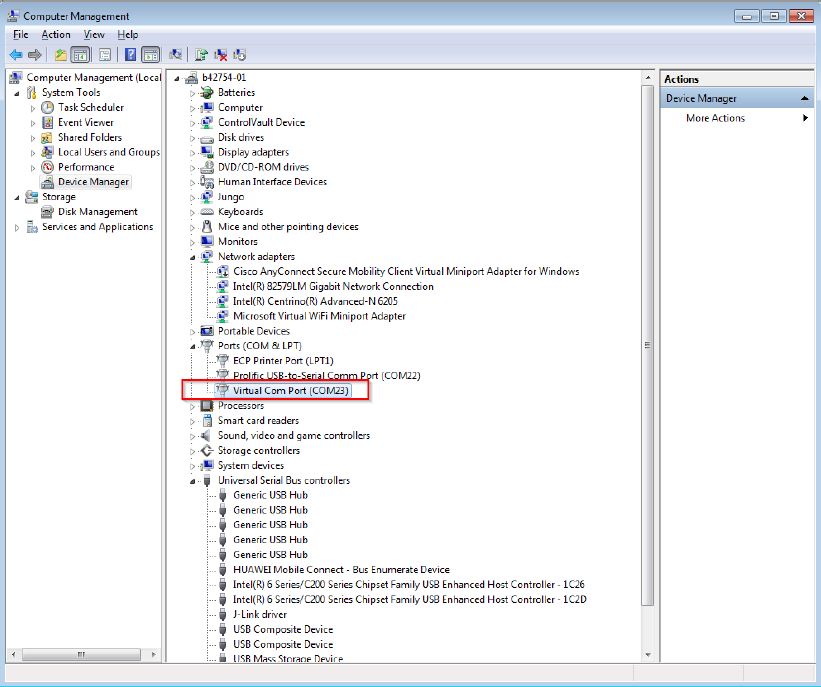
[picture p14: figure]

- If a driver signature issue occurs on Windows 8 OS, see the link,

Disabling Driver Signature on Windows 8 (https://learn.sparkfun.com/tutorials/disabling-driver-signature-on-windows-8/disabling-signed-driver-enforcement-on-windows-8)

- To enable driver signing on Windows OS, see the link,

– Driver Signing

– Practical Windows Code and Driver Signing (http://www.davidegrayson.com/signing/#howto)

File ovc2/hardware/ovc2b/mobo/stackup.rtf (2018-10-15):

Stack up
| Layer | Info | Thickness
| TOP | ====================================== | 0.5+Plating
| | PP IT-158B 106+1080 | 5.272(mil)
| L2 | ====================================== | 1 Oz
| | Core IT-158 0.45 | 17.716(mil)
| L3 | ====================================== | 1 Oz
| | PP IT-158B 1080+2116 | 6.664 (mil)
| L4 | ====================================== | 1 Oz
| | Core IT-158 0.45 | 17.716(mil)
| L5 | ====================================== | 1 Oz
| | PP IT-158B 106+1080 | 5.272(mil)
| L6 | ====================================== | 0.5+Plating
111
Finish thickness: | 62.992(6.299/-6.299) mil | 1.6(+0.16/-0.16) MM
Press thickness: | 59.016mil | 1.499 MM
Material: | IT-158 | IT-158
| Layer | Ref. layer | Impedance Performance | Width/space | Impedance value by client(OHM) | Adjustment width/space | Impedance value(OHM) | H1 | Er1 | H2 | Er2
| L1/L6 | L2/L5 | Difference | 7/8 | 100+/-10% | 6.8/8.2 | 98.2 | 5.272 | 4.1
| L1/L6 | L2/L5 | Difference | 8/6 | 85+/-10% | 7.7/6.3 | 86.6 | 5.272 | 4.1

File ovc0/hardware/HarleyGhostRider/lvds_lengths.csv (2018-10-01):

Signal name | Length on GhostRider | Length on sensor board | Total trace length(mm)
Python3_clk_return+ | 9.729 | 154.318 | 164.047
Python3_clk_return- | 9.738 | 154.318 | 164.056
Python3_DOUT1+ | 12.244 | 155.804 | 168.048
Python3_DOUT1- | 12.249 | 155.804 | 168.053
Python3_DOUT0+ | 9.292 | 163.617 | 172.909
Python3_DOUT0- | 9.292 | 163.617 | 172.909
Python3_DOUT3- | 6.78 | 147.153 | 153.933
Python3_DOUT3+ | 6.744 | 147.153 | 153.897
Python3_SYNC- | 7.752 | 144.342 | 152.094
Python3_SYNC+ | 7.752 | 144.342 | 152.094
Python3_DOUT2+ | 5.71 | 149.319 | 155.029
Python3_DOUT2- | 5.71 | 149.319 | 155.029
Python2_clk_return- | 10.571 | 73.762 | 84.333
Python2_clk_return+ | 10.644 | 73.762 | 84.406
Python2_SYNC- | 12.318 | 82.098 | 94.416
Python2_SYNC+ | 12.333 | 82.098 | 94.431
Python2_DOUT2+ | 12.39 | 81.039 | 93.429
Python2_DOUT2- | 12.41 | 81.039 | 93.449
Python2_DOUT0- | 14.856 | 82.017 | 96.873
Python2_DOUT0+ | 14.785 | 82.017 | 96.802
Python2_DOUT1- | 10.105 | 80.674 | 90.779
Python2_DOUT1+ | 10.105 | 80.674 | 90.779
Python2_DOUT3- | 8.712 | 75.303 | 84.015
Python2_DOUT3+ | 8.668 | 75.303 | 83.971
Python1_clk_return- | 8.155 | 58.684 | 66.839
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

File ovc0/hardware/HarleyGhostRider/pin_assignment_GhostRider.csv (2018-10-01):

Python3_clk_return+ | R15
Python3_clk_return- | P15
Python3_DOUT1+ | L13
Python3_DOUT1- | M13
Python3_DOUT0+ | L16
Python3_DOUT0- | L15
Python3_DOUT3- | T18
Python3_DOUT3+ | R18
Python3_SYNC- | U17
Python3_SYNC+ | U18
Python3_DOUT2+ | L18
Python3_DOUT2- | M18
Python3_CS# | B12
Python2_clk_return- | G16
Python2_clk_return+ | H16
Python2_SYNC- | J14
Python2_SYNC+ | H15
Python2_DOUT2+ | H17
Python2_DOUT2- | G17
Python2_DOUT0- | J13
Python2_DOUT0+ | K13
Python2_DOUT1- | J18
Python2_DOUT1+ | J17
Python2_DOUT3- | F18
Python2_DOUT3+ | G18
Python2_CS# | A11
Python1_clk_return- | F16
Python1_clk_return+ | F15
Python1_DOUT3+ | A16
Python1_DOUT3- | A15
Python1_DOUT2+ | B18
Python1_DOUT2- | A18
Python1_DOUT1+ | B16
Python1_DOUT1- | B17
Python1_DOUT0+ | E18
Python1_DOUT0- | D18
Python1_SYNC+ | A14
Python1_SYNC- | A13
Python1_CS# | B14
Python_RST# | D9 | #reset for all imagers
Python_Trigger | C15 | #trigger for all imagers
Python_lvds_clk- | C14
Python_lvds_clk+ | D14
FPGA_Signal1 | D17
FPGA_Signal2 | E16
FPGA_Signal3 | C17
FPGA_Signal4 | D15
FPGA_Signal5 | F14
FPGA_Signal6 | C10
FPGA_Signal7 | C12
IMU_TX1 | A8
IMU_RX1 | B8

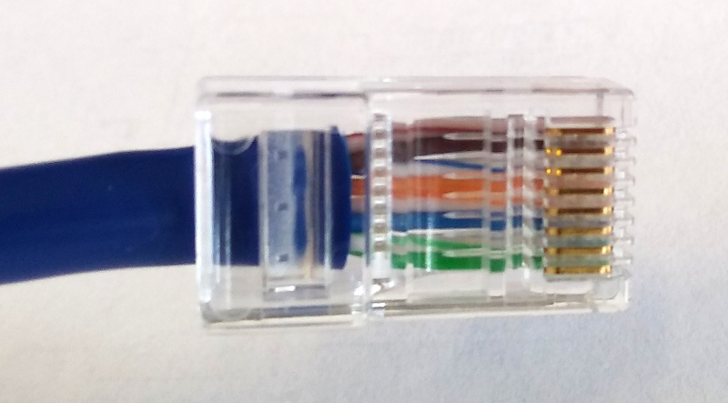
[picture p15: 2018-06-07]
ovc2/doc/ovc2a/ovc2a_non_standard_ethernet_pinout.jpg

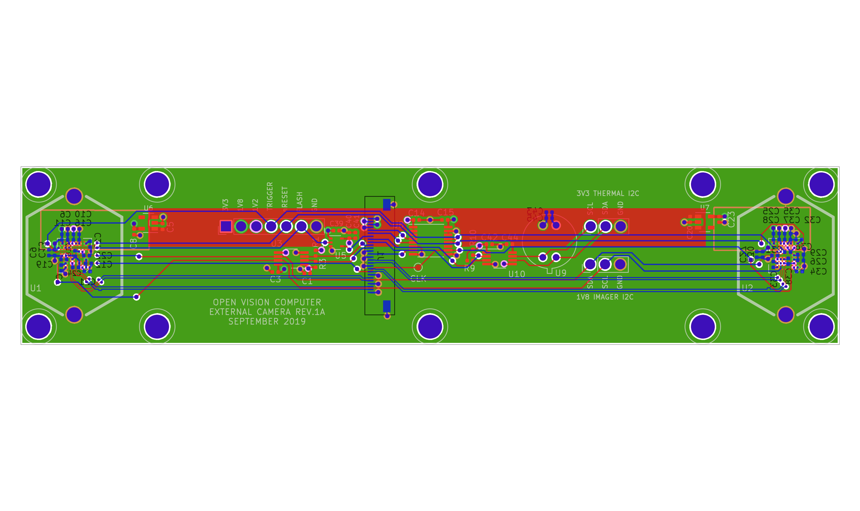
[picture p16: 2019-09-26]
ovc3/hardware/ovc3a/ovc3a/external_camera/external_camera_2d.png

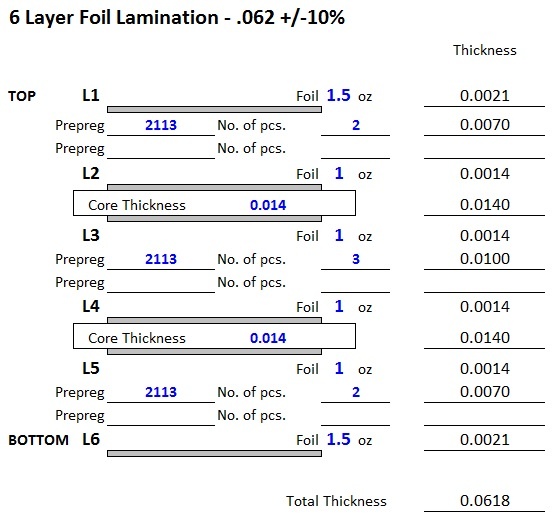
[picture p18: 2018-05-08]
ovc2/hardware/ovc2a/mobo/stackup.jpg

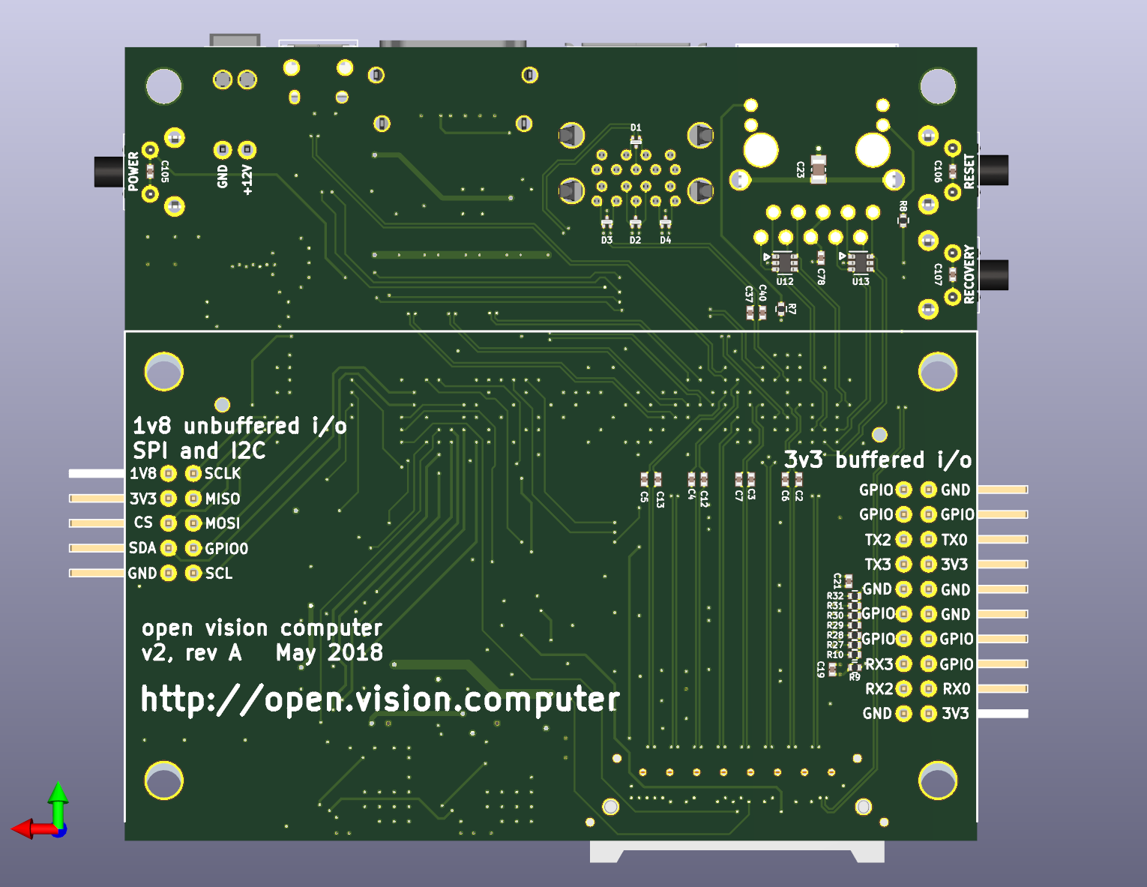
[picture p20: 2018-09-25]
ovc2/doc/ovc2a/ovc2a_mobo_bottom.png

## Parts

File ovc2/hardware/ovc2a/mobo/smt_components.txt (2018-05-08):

1nf 0402: KEMET C0402C102K5RACTU digikey # 399-1032
10nf 0402: TDK C1005X7S2A103K050BB digikey # 445-5199
100nf 0402: Taiyo Yuden TMK105BJ104KV-F  digikey # 587-1456
100nf 0603: KEMET C0603X104M3RACTU  mouser #
1uf 0402: Taiyo Yuden LMK105BJ105KV-F  digikey # 587-1454
10uf 0603: Murata ZRB18AR61E106ME01L  digikey # 490-10991
33uf 1206: TDK C3216X5R1C336M160AB  digikey #445-6002

0 ohm 0402: Panasonic ERJ-2GE0R00X  digikey # P0.0J
10 ohm 0402: Panasonic ERJ-2RKF10R0X  digikey # P10.0L
499 ohm 0402: Panasonic ERJ-2RKF4990X digikey # P499L
10k ohm 0402: Panasonic ERJ-2RKF1002X digikey # P10.0KL
100k ohm 0402: Panasonic ERJ-2RKF1003X digikey # P100KL
10M ohm 0402: Panasonic ERJ-2GEJ106X  digikey # P10MJ

600 ohm 0402 ferrite: Murata BLM15AG601SN1D  digikey # 490-1006

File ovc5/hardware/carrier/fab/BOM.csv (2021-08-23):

Component | References | Value | Footprint | D1N | D1PN | MFN | MPN | Quantity Per PCB
1 | C1 C8 C10 C18 C19 C25 C26 C27 C32 C33 C34 C35 C40 C41 C42 C43 C44 C49 C50 C51 C68 C70 C74 C75 C76 C77 C78 C79 C80 C81 C82 C83 C84 C85 C86 C87 C88 C89 C91 C92 C98 C101 C107 C116 C118 C119 C120 | 100n | C_0201_0603Metric | Digikey | 1292-1161-1-ND | Walsin | 0201X104K160CT | 47
2 | C4 | 10p | C_0402_1005Metric | Digikey | 587-1947-1-ND | Taiyo Yuden | UMK105CG100DV-F | 1
3 | C93 C94 | 10u | C_1206_3216Metric | Digikey | 1276-6736-1-ND | Samsung | CL31A106MBHNNNE | 2
4 | C69 C71 | 150u | C_Elec_6.3x7.7 | Digikey | EEE-FN1C151UP | Panasonic | 10-EEE-FN1C151UPCT-ND | 2
5 | C22 C24 C28 C29 C30 C31 C36 C37 C38 C39 C45 C46 C47 C48 C52 C53 C54 | 1n | C_0201_0603Metric | Digikey | 490-16360-1-ND | Murata Electronics | GRM033R71E102JA01D | 17
6 | C2 C9 C90 C121 | 1u | C_0402_1005Metric | Digikey | 1276-1076-1-ND | Samsung | CL05A105KP5NNNC | 4
7 | C3 C5 C6 C7 C23 C72 C73 C95 C96 C97 | 22u | C_0603_1608Metric | Digikey | 1276-6504-1-ND | Samsung | CL10A226MPCNUBE | 10
8 | C102 C103 | 2n2 | C_0402_1005Metric | Digikey | 1276-1532-1-ND | Samsung | CL05B222JB5NNNC | 2
9 | C20 C21 | 4u7 | C_0402_1005Metric | Digikey | 587-3408-1-ND | Taiyo Yuden | LMK105BBJ475MVLF | 2
10 | CONN1 CONN2 | Conn_Dummy |  | Digikey | H122323-ND | Hirose | FX10A-168P-SV(71) | 2
11 | D3 D4 D5 | D_TVS_Dual_AAC | TPD2EUSB30x | Digikey | 296-25509-1-ND | TI | TPD2EUSB30DRTR | 3
12 | D1 D8 | LED_Small | LED_0402_1005Metric | Digikey | 475-3445-1-ND | OSRAM | LT VH9G-Q2OO-25-1 | 2
13 | D2 D6 | LED_Small | LED_0402_1005Metric | Digikey | 475-3112-1-ND | OSRAM | LB QH9G-N1OO-35-1 | 2
14 | D7 | LED_Small | LED_0402_1005Metric | Digikey | 475-3429-1-ND | OSRAM | LR VH9F-P2R1-1-Z | 1
15 | FB1 FB2 | MH2029-100Y | L_0805_2012Metric | Digikey | MH2029-100YCT-ND | Bourns | MH2029-100Y | 2
16 | J2 | AUX_PWR | BarrelJack_CUI_PJ-102AH_Horizontal | Digikey | CP-102AH-ND | CUI Devices | PJ-102AH | 1
17 | J10 | Conn_01x02 | ELNA_DSK-3R3H224U-HL | Digikey | 604-1020-1-ND | Elna | DSK-3R3H224U-HL | 1
18 | J11 | Conn_01x03 | PinHeader_1x03_P2.54mm_Vertical | Digikey | 732-5316-ND | Würth Elektronik | 61300311121 | 1
19 | J9 | Conn_01x03 | Molex_KK-254_AE-6410-03A_1x03_P2.54mm_Vertical | Digikey | WM4201-ND | Molex | 22232031 | 1
20 | J5 J7 J8 | Conn_01x04 | JST_SH_BM04B-SRSS-TB_1x04-1MP_P1.00mm_Vertical | Digikey | 455-1790-1-ND | JST | BM04B-SRSS-TB(LF)(SN) | 3
21 | J6 | Conn_02x06_Odd_Even | PinHeader_2x06_P2.54mm_Vertical | DNP | DNP | DNP | DNP | 1
22 | J4 | JTAG | PinHeader_2x03_P2.54mm_Vertical | Digikey | 1849-PR20203VBDN-ND | METZ Connect | PR20203VBDN | 1
23 | J3 | Micro_SD_Card_Det_Hirose_DM3AT | microSD_HC_Hirose_DM3AT-SF-PEJM5 | Mouser | 798-DM3AT-SF-PEJM540 | Hirose | DM3AT-SF-PEJM5(40) | 1
24 | J1 | USB_C_Receptacle | Amphenol_12402056E512A | Digikey | 732-9618-1-ND | Wurth | 632723300011 | 1
25 | LOGO1 | Logo_Open_Hardware_Large | OSHW-Symbol_13.4x12mm_SilkScreen | DNP | DNP | DNP | DNP | 1
26 | Q1 | Q_NMOS_GSD | SOT-23 | Digikey | SSM3K2615RLFCT-ND | Toshiba Semiconductor and Storage | SSM3K2615R,LF | 1
27 | R57 R58 R59 R70 | 100k | R_0402_1005Metric | Digikey | YAG3515CT-ND | Yageo | YAG3515CT-ND | 4
28 | R17 R23 R26 R28 R52 R61 R62 R63 R64 R67 R68 R69 | 10k | R_0402_1005Metric | Digikey | YAG3436CT-ND | Yageo | AC0402FR-0710KL | 12
29 | R21 R22 | 110R | R_0603_1608Metric | Digikey | P110JCT-ND | Panasonic | ERJ-2GEJ111X | 2
30 | R65 | 12k | R_0402_1005Metric | Digikey | YAG3441CT-ND | Yageo | AC0402FR-0712KL | 1
31 | R20 R42 R43 R44 R60 | 200k | R_0201_0603Metric | Digikey | YAG5170CT-ND | Yageo | AC0201FR-07200KL | 5
32 | R5 R29 | 20k | R_0402_1005Metric | Digikey | 311-20.0KLRCT-ND | Yageo | RC0402FR-0720KL | 2
33 | R45 R46 R53 R54 R55 | 220R | R_0402_1005Metric | Digikey | 541-10394-1-ND | Vishay Dale | RCS0402220RFKED | 5
34 | R18 R24 | 2k4 | R_0402_1005Metric | Digikey | P2.4KDECT-ND | Panasonic | ERA-2AED242X | 2
35 | R30 R31 R32 R33 R34 R35 | 2k4 | R_0402_1005Metric | Digikey | P2.4KDECT-ND | Panasonic | ERA-2AED242X | 6
36 | R36 R37 R38 R39 R40 R41 | 2k4 | R_0402_1005Metric | Digikey | P2.4KDECT-ND | Panasonic | ERA-2AED242X | 6
37 | R47 R48 R49 R50 R51 | 2k4 | R_0402_1005Metric | Digikey | P2.4KDECT-ND | Panasonic | ERA-2AED242X | 5
38 | R2 | 348k | R_0402_1005Metric | Digikey | 2019-RK73H1ETTP3483FCT-ND | KOA Speer | RK73H1ETTP3483F | 1
39 | R3 | 357k | R_0402_1005Metric | Digikey | YAG3129CT-ND | YAGEO | RC0402FR-07357KL | 1
40 | R6 R7 R10 R19 | 4.7k | R_0402_1005Metric | Digikey | P17228CT-ND | Panasonic Electronic Components | ERJ-PA2F4701X | 4
41 | R13 R15 | 43k | R_0402_1005Metric | Digikey | 311-2291-1-ND | Yageo | RT0402DRE0743KL | 2
42 | R1 R4 R9 R11 R25 R27 | 47k | R_0402_1005Metric | Digikey | 311-47.0KLRCT-ND | Yageo | RC0402FR-0747KL | 6
43 | R14 R16 | 49.9k | R_0402_1005Metric | Digikey | 311-2296-1-ND | Yageo | RT0402DRE0749K9L | 2
44 | R8 | JMP | R_0603_1608Metric | Digikey | 541-0.0SBCT-ND | Vishay Dale | CRCW06030000Z0EAHP | 1
45 | SW2 | Reset_Hardware | SW_SPST_EVQP7C | Digikey | P16765CT-ND | Panasonic Electronic Components | EVQ-P7C01P | 1
46 | SW3 | Reset_Software | SW_SPST_EVQP7C | Digikey | P16765CT-ND | Panasonic Electronic Components | EVQ-P7C01P | 1
47 | SW1 | SW_DIP_x03 | SW_DIP_SPSTx03_Slide_6.7x9.18mm_W6.73mm_P2.54mm_LowProfile_JPin | Digikey | 563-CFS-0300TACT-ND | Nidec Copal Electronics | CFS-0300TA | 1
48 | U11 | ARJ11C-MBSAS-A-BA-7MU2 | ARJ11C-MBSAS-A-BA-7MU2 | Digikey | ARJ11C-MBSAS-A-BA-7MU2-ND | Abracon | ARJ11C-MBSAS-A-BA-7MU2 | 1
49 | U18 | EMC2101-ACZL-TR | TSSOP-8_3x3mm_P0.65mm | Digikey | EMC2101-ACZL-CT-ND | Microchip Technology | EMC2101-ACZL-TR | 1
50 | U9 | EN5339QI | Converter_DCDC_Intel_QFN-24_4x6mm_P0.65mm_ThermalVias | Digikey | 544-2854-1-ND | Intel | EN5339QI | 1
51 | U12 | FT231XQ | QFN-20-1EP_4x4mm_P0.5mm_EP2.5x2.5mm | RS | 7570045P | FTDI Chip | FT231XQ-R | 1
52 | U1 | Mercury_XU5_4CG-4EV-5EV | Mercury_XU5 | DNP | DNP | DNP | DNP | 1
53 | U3 U4 U15 | PICAM_Expandable_Reversed | AMPHENOL_SFW22S | Digikey | 609-1158-1-ND | Amphenol | SFW22S-2STE1LF | 3
54 | U14 U16 U17 | PICAM_Reversed | AMPHENOL_SFW15S | Digikey | 609-1148-1-ND | Amphenol | SFW15S-2STE1LF | 3
55 | U6 | TPS2121 | Texas_VQFN-HR-12_2x2.5_Pitch0.5mm | Digikey | 296-53410-1-ND | TI | TPS2121RUXR | 1
56 | U8 | TPS2561 | VSON-10-1EP_3x3mm_P0.5mm_EP1.65x2.4mm_ThermalVias | Digikey | 296-37670-1-ND | TI | TPS2561DRCR | 1
57 | U7 | TPSM53604RDA | Texas_B3QFN-14-1EP_5x5.5mm_P0.65mm_ThermalVia | Digikey | 296-TPSM53604RDARCT-ND | TI | TPSM53604RDAR | 1
58 | U13 | TXS02612 | TI_RTW0024B | Digikey | 296-23869-1-ND | TI | TXS02612RTWR | 1
59 | U5 | USB3_A_Dual_Stacked | USB3_A_Dual_Stacked | Digikey | WM10420-ND | Molex | 484060003 | 1
60 | U21 | USB7216C | Microchip_USB7216C | Digikey | 150-USB7216C/KDX-ND | Microchip Technology | USB7216C/KDX | 1
61 | X1 | ASCO | Oscillator_SMD_Abracon_ASCO-4Pin_1.6x1.2mm | Digikey | 535-12075-1-ND | Abracon LLC | ASCO-25.000MHZ-EK-T3 | 1
Component Groups: | 61
Component Count: | 200
Fitted Components: | 200
Number of PCBs: | 1
Total components: | 200
Schematic Version:
Schematic Date:
PCB Variant: | ['default']
BoM Date: | Wed 18 Aug 2021 02:23:01 PM PDT
Schematic Source: | ovc5.kicad_sch
KiCad Version: | Eeschema 5.99.0-unknown-ca42f31bb5~131~ubuntu20.04.1

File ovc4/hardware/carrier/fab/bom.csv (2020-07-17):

Component | Quantity Per PCB | References | Value | Footprint | MFN | MPN | D1N | D1PN | voltage
1 | 41 | C9 C10 C11 C12 C13 C15 C16 C17 C18 C19 C20 C21 C28 C32 C33 C34 C37 C38 C39 C42 C44 C46 C47 C48 C49 C50 C51 C52 C53 C54 C56 C58 C59 C60 C61 C65 C69 C70 C71 C72 C73 | 100n | C_0402_1005Metric | Samsung | CL05F104ZO5NNNC | Digikey | 1276-1004-1-ND
2 | 4 | C23 C24 C35 C36 | 100u | C_1206_3216Metric | TDK | C3216X5R1A107M160AC | Digikey | 445-6007-1-ND
3 | 2 | C25 C27 | 10u | C_1206_3216Metric | KEMET | C1206C106M3PACTU | Digikey | 399-8153-1-ND
4 | 2 | C30 C67 | 10u | C_0805_2012Metric | Kemet | C0805C106K8PACTU | Digikey | 399-4925-1-ND
5 | 2 | C43 C57 | 10u | C_0603_1608Metric | Murata | GRM188R61A106KE69J | Digikey | 490-14372-1-ND
6 | 1 | C8 | 10u | C_0402_1005Metric | Murata | GRM155C80J106ME11J | Digikey | 490-18210-1-ND
7 | 4 | C5 C6 C40 C41 | 18p | C_0402_1005Metric | Yageo | CC0402JRNPO9BN180 | Digikey | 311-1415-1-ND
8 | 9 | C1 C2 C3 C7 C14 C22 C26 C29 C66 | 1u | C_0402_1005Metric | Samsung | CL05A105KA5NQNC | Digikey | 1276-1445-1-ND
9 | 1 | C62 | 2u2 | C_0402_1005Metric | Murata | GRM155R61A225KE95D | Digikey | 490-10451-1-ND
10 | 1 | C63 | 470u | CP_Elec_6.3x7.7 | Panasonic | EEE-FTJ471XAP | Digikey | P15096CT-ND
11 | 1 | C45 | 47p | C_0402_1005Metric | Kemet | C0402C470K5GACTU | Digikey | 399-7796-1-ND
12 | 4 | C31 C55 C64 C68 | 47u | C_1206_3216Metric | Murata | GRM31CR61A476KE15L | Digikey | 490-9673-1-ND
13 | 1 | C4 | 4u7 | C_0603_1608Metric | Samsung | CL10A475KA8NQNC | Digikey | 1276-1900-1-ND | 25V
14 | 6 | CAM0 CAM1 CAM2 CAM3 CAM4 CAM5 | PICAM | AMPHENOL_SFW15R | Amphenol | SFW15R-1STE1LF | Digikey | 609-1905-1-ND
15 | 1 | D6 | D | D_0402_1005Metric | Comchip | CDBQR0130L | Digikey | 641-1271-1-ND
16 | 2 | D4 D5 | D_TVS_x2_AAC | TPD2EUSB30x | TI | TPD2EUSB30DRTR | Digikey | 296-25509-1-ND
17 | 1 | D2 | ESDA25W | SOT-23 | ST | ESDA25W | Digikey | 497-6689-1-ND
18 | 1 | D7 | PMEG3030EP,115 | D_SOD-128 | Nexperia | PMEG3030EP,115 | Digikey | 1727-5324-1-ND
19 | 1 | D1 | SDMK0340L-7-F | D_SOD-323 | Diodes Inc | SDMK0340L-7-F | Digikey | SDMK0340L-FDICT-ND
20 | 1 | D3 | SMBJ22A | D_SMB | Bourns | SMBJ22A | Digikey | SMBJ22ABCT-ND
21 | 1 | J10 | Conn_01x02 | ELNA_DSK-3R3H224U-HL | Elna | DSK-3R3H224U-HL | Digikey | 604-1020-1-ND
22 | 1 | J3 | Conn_01x02 | PinHeader_1x02_P2.54mm_Vertical | Harwin | 952-2262-ND | Digikey | 952-2262-ND
23 | 1 | J4 | Conn_01x02 | Molex_Nano-Fit_105313-xx02_1x02_P2.50mm_Horizontal | Molex | 1053131302 | Digikey | WM15141-ND
24 | 3 | J1 J6 J9 | Conn_01x03 | PinHeader_1x03_P2.54mm_Vertical | Wurth | CONN HEADER VERT 3POS 2.54MM | Digikey | 732-5316-ND
25 | 1 | J11 | Conn_01x04 | PinHeader_1x04_P1.27mm_Vertical | Adam Tech | HPH1-B-04-UA | Digikey | 2057-HPH1-B-04-UA-ND
26 | 1 | J12 | Conn_01x04 | PinHeader_1x04_P2.54mm_Vertical | Wurth | 61300411121 | Digikey | 732-5317-ND
27 | 1 | J7 | Conn_01x06 | PinHeader_1x06_P2.54mm_Vertical | Amphenol | 68000-406HLF | Digikey | 609-3263-ND
28 | 1 | J8 | Conn_02x05_Odd_Even | PinHeader_2x05_P2.54mm_Vertical | Sullins | PPTC052LFBN-RC | Digikey | S6105-ND
29 | 1 | J5 | ISP_UART | PinHeader_2x02_P2.54mm_Vertical | Harwin | M20-9760246 | Digikey | 952-1772-ND
30 | 1 | J2 | USB_C_Receptacle | USB_C_Receptacle_Wurth_632723300011 | Wurth | 632723300011 | Digikey | 732-9618-1-ND
31 | 3 | L3 L4 L5 | 4u7 | L_0805_2012Metric | Murata | LQM2MPN4R7MG0L | Digikey | 490-12073-1-ND
32 | 1 | LOGO1 | Logo_Open_Hardware_Large | OSHW-Logo2_7.3x6mm_SilkScreen
33 | 1 | MCU_SWD1 | Conn_ARM_JTAG_SWD_10 | PinHeader_2x05_P1.27mm_Vertical | Amphenol | 20021111-00010T4LF | Digikey | 609-3712-ND
34 | 2 | Q3 Q4 | 2N7002 | SOT-23 | Nexperia | 2N7002,215 | Digikey | 1727-2764-1-ND
35 | 2 | Q1 Q2 | SI2369DS | SOT-23 | Vishay | SI2369DS-T1-GE3 | Digikey | SI2369DS-T1-GE3CT-ND
36 | 1 | R9 | 100R | R_0402_1005Metric | Panasonic | ERA-2AED101X | Digikey | P100DECT-ND
37 | 7 | R3 R5 R7 R8 R13 R15 R39 | 100k | R_0402_1005Metric | Panasonic | ERA-2AED104X | Digikey | P100KDECT-ND
38 | 9 | R11 R12 R14 R18 R19 R22 R31 R37 R38 | 10k | R_0402_1005Metric | Panasonic | ERA-2AED103X | Digikey | P10KDECT-ND
39 | 2 | R32 R33 | 110R | R_0603_1608Metric | Panasonic | ERA-3AEB111V | Digikey | P110DBCT-ND
40 | 1 | R36 | 162k | R_0402_1005Metric | Panasonic | ERJ-2RKF1623X | Digikey | P162KLCT-ND
41 | 1 | R34 | 1M | R_0402_1005Metric | Yageo | RC0402FR-071ML | Digikey | 311-1.00MLRCT-ND
42 | 1 | R10 | 1k | R_0603_1608Metric | Rohm | ESR03EZPJ102 | Digikey | RHM1.0KDCT-ND
43 | 1 | R2 | 1k | R_0402_1005Metric | Panasonic | ERJ-2RKF1001X | Digikey | P1.00KLCT-ND
44 | 3 | R20 R25 R27 | 20k | R_0402_1005Metric | Panasonic | ERA-2AED203X | Digikey | P20KDECT-ND
45 | 3 | R6 R24 R30 | 22k | R_0402_1005Metric | Panasonic | ERJ-2RKF2202X | Digikey | P22.0KLCT-ND
46 | 15 | R23 R28 R29 R40 R41 R42 R43 R44 R45 R46 R47 R48 R49 R50 R51 | 2k4 | R_0402_1005Metric | Panasonic | ERA-2AED242X | Digikey | P2.4KDECT-ND
47 | 1 | R35 | 340k | R_0402_1005Metric | Panasonic | ERJ-2RKF3403X | Digikey | P340KLCT-ND
48 | 1 | R1 | 470R | R_0402_1005Metric | Panasonic | ERJ-2RKF4700X | Digikey | P470LCT-ND
49 | 2 | R21 R26 | 4k7 | R_0402_1005Metric | Panasonic | ERJ-2RKF4701X | Digikey | P4.70KLCT-ND
50 | 1 | R4 | 649R | R_0402_1005Metric | Panasonic | ERA-2AEB6490X | Digikey | P649DCCT-ND
51 | 1 | SW1 | SW_DPDT_x2 | TL2230 | E-Switch | TL2230OAF140 | Digikey | EG6032-ND
52 | 1 | SW2 | SW_Push | SW_PUSH_6mm_H5mm | TE Connectivity | 1825910-7 | Digikey | 450-1804-ND
53 | 1 | U6 | 74AHC1G08 | SOT-353_SC-70-5 | TI | SN74AHC1G08DCKR | Digikey | 296-8743-1-ND
54 | 1 | U22 | 74LVC1G34 | SOT-23-5 | TI | SN74LVC1G34DBVR | Digikey | 296-17893-1-ND
55 | 1 | U21 | ARJ11C-MBSAS-A-BA-7MU2 | ARJ11C-MBSAS-A-BA-7MU2 | Abracon | ARJ11C-MBSAS-A-BA-7MU2 | Digikey | ARJ11C-MBSAS-A-BA-7MU2-ND
56 | 1 | U3 | CY7C65642-28LTXC | QFN-28-1EP_5x5mm_P0.5mm_EP3.35x3.35mm | Cypress | CY7C65642-28LTXC | Digikey | 428-3149-ND
57 | 2 | U9 U11 | EN5322QI | Converter_DCDC_Intel_QFN-24_4x6mm_P0.65mm_ThermalVias | Intel | EN5322QI | Digikey | 544-2849-1-ND
58 | 1 | U4 | HD3SS3202 | TI_R_PUQFN_N16 | TI | HD3SS3202IRSVT | Digikey | 296-52295-1-ND
59 | 1 | U25 | ICM42688 | LGA-14_3x2.5mm_P0.5mm_LayoutBorder3x4y | TDK Invensense | ICM-42688-P | Digikey | 1428-ICM-42688-PCT-ND
60 | 1 | U1 | Jetson_Nano | TE_2309413-1 | TE Connectivity | 2309413-1 | Digikey | A126764CT-ND
61 | 1 | U5 | LM3526-L | SO-8_3.9x4.9mm_P1.27mm | TI | LM3526MX-L/NOPB | Digikey | LM3526MX-L/NOPBCT-ND
62 | 1 | U20 | LPC55S66JBD100 | QFP-100-1EP_3.21x3.21mm_14x14_Pitch0.5mm | NXP | LPC55S69JBD100K | Digikey | 568-15313-ND
63 | 1 | U24 | SN74AUP1T34DCK | SOT-353_SC-70-5 | TI | SN74AUP1T34DCKR | Digikey | 296-34900-1-ND
64 | 1 | U23 | SN74LVC1G04 | SOT-353_SC-70-5 | TI | SN74LVC1G04DCKR | Digikey | 296-11600-1-ND
65 | 2 | U12 U19 | SN74LVC1T45DBV | SOT-23-6 | TI | SN74LVC1T45DBVR | Digikey | 296-16843-1-ND
66 | 1 | U2 | STUSB4500 | QFN-24-1EP_4x4mm_P0.5mm_EP2.7x2.7mm | ST | STUSB4500LQTR | Digikey | 497-STUSB4500LQCT-ND
67 | 2 | U8 U10 | TPS2121 | Texas_VQFN-HR-12_2x2.5_Pitch0.5mm | TI | TPS2121RUXR | Digikey | 296-53410-1-ND
68 | 1 | U7 | TPSM53604 | TI_B3QFN | TI | TPSM53604RDAR | Digikey | 296-TPSM53604RDARCT-ND
69 | 1 | U26 | TVS2200DRV | WSON-6-1EP_2x2mm_P0.65mm_EP1x1.6mm | TI | TVS2200DRVR | Mouser | 595-TVS2200DRVR
70 | 1 | U18 | USBA_DUAL | USBA_DUAL_HOR | Amphenol | 72309-8034BLF | Digikey | 609-1040-ND
71 | 1 | Y1 | 12MHz | Crystal_SMD_5032-2Pin_5.0x3.2mm | Kyocera | CX5032GB12000H0HPQZ1 | Digikey | 1253-1375-1-ND
72 | 1 | Y2 | 16MHz | Crystal_SMD_5032-2Pin_5.0x3.2mm | Kyocera | CX5032GB16000H0PESZZ | Digikey | 478-4362-1-ND
Component Groups: | 72
Component Count: | 181
Fitted Components: | 181
Number of PCBs: | 1
Total components: | 181
Schematic Version:
Schematic Date:
PCB Variant: | ['default']
BoM Date: | Mon Jun 22 18:16:15 2020
Schematic Source: | ovc4.kicad_sch
KiCad Version: | Eeschema 5.99.0-unknown-ad69e44~101~ubuntu18.04.1

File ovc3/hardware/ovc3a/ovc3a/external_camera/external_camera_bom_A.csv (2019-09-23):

Component | Quantity Per PCB | References | Value | Footprint | MFN | MPN | D1N | D1PN
1 | 29 | C1 C3 C11 C12 C13 C14 C15 C16 C17 C18 C19 C21 C22 C24 C28 C29 C30 C32 C33 C34 C35 C36 C37 C38 C39 C40 C42 C43 C44 | 100n | C_0402_1005Metric | Samsung | CL05F104ZO5NNNC | Digikey | 1276-1004-1-ND
2 | 9 | C6 C7 C9 C10 C25 C26 C27 C31 C41 | 10u | C_0402_1005Metric | Samsung | CL05A106MP8NUB8 | Digikey | 1276-6830-1-ND
3 | 5 | C5 C8 C20 C23 C45 | 1u | C_0402_1005Metric | Samsung | CL05A105KA5NQNC | Digikey | 1276-1445-1-ND
4 | 2 (DNF) | J2 J3 | DNP | LENS_HOLDER_20MM_PT-LH010M | DNP | DNP | DNP | DNP
5 | 1 (DNF) | J4 | DNP | PinHeader_1x07_P2.54mm_Vertical | DNP | DNP | DNP | DNP
6 | 2 (DNF) | J5 J6 | DNP | PinHeader_1x03_P2.54mm_Vertical | DNP | DNP | DNP | DNP
7 | 1 | J1 | FFC | MOLEX_505110_2691 | Molex | 5051102691 | Digikey | WM24281CT-ND
8 | 4 | R1 R3 R9 R10 | 2k2 | R_0402_1005Metric | Yageo | RC0402FR-072K2L | Digikey | 311-2.20KLRCT-ND
9 | 2 | U1 U2 | AR0144CS | BGA-72_9x8_5.545x5.565mm | ON Semiconductor | AR0144CSSC00SUKA0-CPBR2 | Digikey | AR0144CSSC00SUKA0-CPBR2OS-ND
10 | 1 (DNF) | U9 | DNP | Melexis_TO-39 | DNP | DNP | DNP | DNP
11 | 2 | U6 U7 | LP5907MFX-2.8 | SOT-23-5 | Texas Instruments | LP5907MFX-2.8/NOPB | Digikey | 296-39063-1-ND
12 | 1 | U5 | SN74AUP1T34DCK | SOT-353_SC-70-5 | Texas Instruments | SN74AUP1T34DCKR | Digikey | 296-34900-1-ND
13 | 1 | U8 | SN74AXC4T245PWR | TSSOP-16_4.4x5mm_P0.65mm | Texas Instruments | SN74AXC4T245PWR | Digikey | 296-53472-1-ND
14 | 2 | U3 U10 | TCA9803 | VSSOP-8_3.0x3.0mm_P0.65mm | Texas Instruments | TCA9803DGKR | Digikey | 296-47829-1-ND
Component Groups: | 14
Component Count: | 62
Fitted Components: | 56
Number of PCBs: | 1
Total components: | 56
Schematic Version: | A
Schematic Date: | 2019-07-10
PCB Variant: | ['default']
BoM Date: | Mon 23 Sep 2019 04:11:05 PM +08
Schematic Source: | /home/luca/hw/ovc/hardware/ovc3a/external_camera/external_camera.sch
KiCad Version: | Eeschema 5.99.0-unknown-bba949c~100~ubuntu18.04.1

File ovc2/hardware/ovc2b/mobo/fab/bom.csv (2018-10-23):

# Bill of Materials for 'ovc2_mobo' rev.B
# Schematic date: Mon 15 Oct 2018 12:31:14 PM +08
Line Item | Quantity | Designator | Value | Tolerance | Thermal | Voltage | Manufacturer | Manufacturer Part Number | Distributor | Distributor Part Number | Substitution OK?
1 | 1 | C1 | 80m | 20% |  |  | Seiko | XH414HG-IV01E | digikey | 728-1050 | no
2 | 36 | C2,C3,C4,C5,C6,C7,C8,C11,C12,C13,C18,C19,C20,C21,C25,C26,C27,C28,C29,C30,C31,C32,C34,C36,C37,C40,C42,C48,C51,C56,C57,C58,C59,C105,C106,C107 | 100n | 20% | X5R | 25 V | TDK | C1005X5R1E104K050BC | Element14 | 2525021 | yes
3 | 12 | C9,C24,C49,C91,C92,C93,C96,C97,C98,C99,C103,C104 | 10u | 20% | X5R | 25 V | Murata | ZRB18AR61E106ME01L | Element14 | 2469398 | yes
4 | 2 | C10,C50 | 68u | 20% | JB | 10 V | TDK | C3216JB1A686M160AC | digikey | 445-11687 | yes
5 | 2 | C14,C16 | 33u | 20% | JB | 25 V | TDK | CL31X226KAHN3NE | digikey | 445-11710 | yes
6 | 8 | C15,C17,C41,C44,C47,C52,C55,C162 | 22u | 20% | X5R | 25 V | TDK | C2012X5R1E226M125AC | Element14 | 2525137 | yes
7 | 5 | C22,C33,C35,C43,C102 | 1u | 10% | X5R | 25 V | TDK | C1005X5R1E105K050BC | digikey | 445-9066 | yes
8 | 1 | C23 | 100p | 10% | X7R | 1000 V | KEMET | C0805X101KDRACTU | digikey | 399-5825 | yes
9 | 2 | C38,C45 | 470p | 10% | C0G | 50 V | TDK | CGA2B2C0G1H471J050BA | digikey | 445-5604 | yes
10 | 2 | C39,C46 | 22p | 10% | C0G | 50 V | Kemet | C0402C220K5GACTU | Element14 | 2581028 | yes
11 | 1 | C53 | 1u | 10% | X7S | 100 V | TDK | C2012X7S2A105K125AB | digikey | 445-5205 | yes
12 | 1 | C54 | 47n | 10% | X7R | 25 V | TDK | C1005X7R1E473K050BC | Element14 | 1907263 | yes
13 | 1 | C78 | 10n | 10% | X7S | 100 V | TDK | C1005X7S2A103K050BB | Element14 | 2525065 | yes
14 | 1 | C94 | 100u | 20% |  | 25 V | Nichicon | UCL1E101MCL1GS | digikey | 493-3937 | yes
15 | 1 | C101 | 2u2 | 10% | X5R | 25 V | Taiyo Yuden | TMK107ABJ225KA-T | digikey | 587-2909 | yes
16 | 6 | D1,D2,D3,D4,D5,D6 | TPD2EUSB30A |  |  |  | TI | TPD2EUSB30ADRTR | digikey | 296-28153 | yes
17 | 2 | D7,D8 | LED_Small |  |  |  | ON Semi | ESD9X5.0ST5G | digikey | ESD9X5.0ST5GOS | yes
18 | 1 | D10 | BAT54ALT1G |  |  |  | ON Semi | BAT54ALT1G | digikey | BAT54ALT1GOS | yes
19 | 1 | D11 | BAT54CW-7-F |  |  |  | Diodes Inc | BAT54CW-7-F | digikey | BAT54CW-FDI | yes
20 | 2 | FB1,FB12 | 220 |  |  |  | Murata | BLM18KG221SN1D | digikey | 490-5255 | yes
21 | 8 | FB3,FB4,FB5,FB6,FB7,FB8,FB9,FB10 | 600 | 1% |  |  | Panasonic | BLM15AG601SN1D | digikey | 490-1006 | yes
22 | 3 | FB19,FB20,FB21 | 30 |  |  |  | TDK | MPZ1608S300ATAH0 | digikey | 445-1562 | yes
23 | 1 | J1 | SPI/I2C |  |  |  | Amp FCI | 68021-210HLF | digikey | 609-3410 | yes
24 | 1 | J2 | SAMTEC QRF8-RA |  |  |  | Samtec | QRF8-026-01-L-RA-GP | digikey | SAM9773 | no
25 | 1 | J3 | USB_OTG |  |  |  | Amp FCI | 10103594-0001LF | digikey | 609-4050 | yes
26 | 1 | J4 | POWER |  |  |  | Molex | 105313-1302 | digikey | WM15141 | no
27 | 1 | J5 | GPIO |  |  |  | Amp FCI | 68021-220HLF | digikey | 609-3347 | yes
28 | 1 | J6 | HDMI_TYPE_A |  |  |  | Amp FCI | 10029449-111RLF | digikey | 609-4614 | no
29 | 1 | J7 | USB |  |  |  | Molex | 48406-0003 | digikey | WM10420 | no
30 | 1 | J8 | FAN |  |  |  | Molex | 53047-0410 | digikey | WM1733 | yes
31 | 1 | J11 | Micro_SD_Card_Det_Hirose_DM3AT |  |  |  | Hirose | DM3AT-SF-PEJM5 | digikey | HR1964 | yes
32 | 2 | Q1,Q2 | Q_NMOS_GSD |  |  |  | Diodes Inc | DMN2041L-7 | digikey | DMN2041L-7DI | yes
33 | 3 | Q3,Q10,Q11 | NTR4003NT1G |  |  |  | ON Semi | NTR4003NT1G | digikey | NTR4003NT1GOS | yes
34 | 3 | Q4,Q7,Q8 | NTS4001NT1G |  |  |  | ON Semi | NTS4001NT1G | digikey | NTS4001NT1GOS | yes
35 | 1 | Q6 | MMBT4403 |  |  |  | ON Semi | KST4403MTF | digikey | KST4403MTF | yes
36 | 15 | R1,R9,R10,R11,R27,R28,R29,R30,R31,R32,R33,R41,R46,R47,R48 | 10k | 1% |  |  | Panasonic | ERJ-2RKF1002X | digikey | P10.0KL | yes
37 | 2 | R2,R4 | 51k | 1% |  |  | Panasonic | ERJ-2RKF5102X | digikey | P51.0KL | yes
38 | 1 | R3 | 11k3 | 1% |  |  | Panasonic | ERJ-2RKF1132X | digikey | P11.3KL | yes
39 | 1 | R5 | 6k98 | 1% |  |  | Panasonic | ERJ-2RKF6981X | digikey | P6.98KL | yes
40 | 2 | R6,R56 | 47 |  |  |  | Panasonic | ERJ-3EKF47R0V | digikey | P47.0H | yes
41 | 2 | R7,R8 | 681 | 1% |  |  | Panasonic | ERJ-2RKF6810X | digikey | P681L | yes
42 | 8 | R12,R13,R14,R15,R16,R17,R18,R19 | 499 | 1% |  |  | Panasonic | ERJ-2RKF4990X | digikey | P499L | yes
43 | 1 | R20 | 0 | 1% |  |  | Panasonic | ERJ-2GE0R00X | digikey | P0.0J | yes
44 | 5 | R21,R22,R23,R24,R25 | 10 | 1% |  |  | Panasonic | ERJ-2RKF10R0X | digikey | P10.0L | yes
45 | 3 | R26,R38,R51 | 47k | 1% |  |  | Panasonic | ERJ-2RKF4702X | digikey | P47.0KL | yes
46 | 2 | R34,R35 | 4R99 | 1% |  |  | Vishay | CRCW08054R99FKEAHP | digikey | 541-4.99T | yes
47 | 1 | R36 | 487k | 1% |  | 100 V | Panasonic | ERJ-6ENF4873V | digikey | P487KC | yes
48 | 1 | R37 | 18k9 | 1% |  |  | Panasonic | ERJ-2RKF1872X | digikey | P18.7KL | yes
49 | 1 | R39 | 402k | 1% |  |  | Panasonic | ERJ-2RKF4023X | digikey | P402KL | yes
50 | 1 | R40 | 5k6 | 1% |  |  | Panasonic | ERJ-2RKF5601X | digikey | P5.60KL | yes
51 | 1 | R42 | 100 | 1% |  |  | Panasonic | ERJ-2RKF1000X | digikey | P100L | yes
52 | 4 | R43,R49,R52,R53 | 100k | 1% |  |  | Panasonic | ERJ-2RKF1003X | digikey | P100KL | yes
53 | 1 | R44 | 330 | 1% |  |  | Panasonic | ERJ-2RKF3300X | digikey | P330L | yes
54 | 1 | R50 | 10M | 1% |  |  | Panasonic | ERJ-2GEJ106X | digikey | P10MJ | yes
55 | 1 | R55 | 100 |  |  |  | Panasonic | ERJ-3EKF1000V | digikey | P100H | yes
56 | 2 | U1,U14 | MPM3630 |  |  |  | Monolithic Power | MPM3630GQV-P | digikey | 1589-1253 | no
57 | 1 | U2 | TPS26600PWP |  |  |  | TI | TPS26600PWP | digikey | 296-47292 | no
58 | 1 | U3 | Jetson |  |  |  | Samtec | SEAM-50-03.5-S-08-2-A-K-TR | samtec | SEAM-50-03.5-S-08-2-A-K-TR | no
59 | 2 | U4,U5 | SN74AVC8T245 |  |  |  | TI | SN74AVC8T245PWR | digikey | 296-19100 | no
60 | 1 | U6 | TLV733P |  |  |  | TI | TLV73318PDBVR | digikey | 296-40669 | yes
61 | 1 | U7 | NCP380LSN10AAT1G |  |  |  | ON Semi | NCP380LSN05AAT1G | digikey | NCP380LSN05AAT1GOS | yes
62 | 1 | U8 | IP4786CZ32 |  |  |  | Nexperia | IP4786CZ32Y | digikey | 1727-2149 | no
63 | 1 | U9 | TXS0108EPW |  |  |  | TI | TXS0108EPWR | digikey | 296-23011 | no
64 | 2 | U10,U11 | TPS2069C |  |  |  | TI | TPS2069CDBVT | digikey | 296-35605 | yes
65 | 2 | U12,U13 | SP3002-04JTG |  |  |  | Littelfuse | SP3002-04JTG | digikey | F2916 | yes
66 | 1 | U18 | ARJ11C-MBSAS-A-BA-7MU2 |  |  |  | Abracon | ARJ11C-MBSAS-A-BA-7MU2 | digikey | ARJ11C-MBSAS-A-BA-7MU2 | no
67 | 2 | SW1,SW3 | SW_Push |  |  |  | OMRON | B3U-3000P-B | Element14 | 1333656 | yes
68 | 1 | SW2 | SW_Push |  |  |  | C&K | PTS645VH58-2LFS | digikey | CKN9120 | yes

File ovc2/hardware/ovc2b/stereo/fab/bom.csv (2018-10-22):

# Bill of Materials for 'ovc2_stereo' rev.2b
# Schematic date: Mon 22 Oct 2018 04:51:45 PM +08
Line Item | Quantity | Designator | Footprint | Value | Tolerance | Thermal | Voltage | Manufacturer | Manufacturer Part Number | Distributor | Distributor Part Number | Substitution OK?
1 | 53 | C1,C2,C3,C6,C12,C13,C14,C16,C17,C22,C27,C28,C41,C45,C46,C47,C48,C49,C50,C51,C61,C77,C78,C79,C80,C81,C82,C83,C84,C85,C86,C87,C88,C89,C91,C92,C93,C94,C95,C96,C121,C123,C125,C126,C128,C129,C131,C146,C147,C154,C155,C183,C184 | Capacitor_SMD:C_0402_1005Metric | 100n | 20% | X5R | 25 V | TDK | CGA2B3X7R1E104K050BB | digikey | 445-6902 | yes
2 | 4 | C4,C7,C38,C60 | Capacitor_SMD:C_1206_3216Metric | 22u | 10% | X5R | 25 V | Samsung | CL31A226KAHNNNE | digikey | 1276-3047 | yes
3 | 1 | C5 | Capacitor_SMD:C_0402_1005Metric | 100n | DNP | DNP | DNP | DNP | DNP | DNP | DNP | DNP
4 | 3 | C8,C34,C39 | Capacitor_SMD:C_0402_1005Metric | 470p | 10% | X5R | 50 V | Yageo | CC0402KRX7R9BB471 | digikey | 311-1028 | yes
5 | 3 | C9,C35,C40 | Capacitor_SMD:C_0402_1005Metric | 22p | 10% | C0G | 16 V | Kemet | C0402C220K5GACTU | digikey | 399-7775 | yes
6 | 10 | C10,C11,C15,C19,C36,C37,C42,C43,C52,C188 | Capacitor_SMD:C_0603_1608Metric | 22u | 20% | X5R | 6.3 V | Samsung | CL10A226MQ8NRNC | digikey | 1276-1193 | yes
7 | 4 | C18,C75,C118,C143 | Capacitor_SMD:C_0402_1005Metric | 10n | 20% | X5R | 25 V | Samsung | CL05B103KA5NNNC | digikey | 1276-1057 | yes
8 | 12 | C20,C21,C23,C24,C137,C138,C139,C140,C141,C142,C153,C182 | Capacitor_SMD:C_0402_1005Metric | 22n | 10% | X7R | 16 V | Taiyo Yuden | EMK105B7223KV-F | digikey | 587-1224 | yes
9 | 4 | C25,C26,C144,C145 | Capacitor_SMD:C_0402_1005Metric | 47n | 10% | X7R | 25 V | Murata | GCM155R71C473KA37D | digikey | 490-6042 | yes
10 | 4 | C29,C148,C156,C185 | Capacitor_SMD:C_0402_1005Metric | 220n | 10% | X7R | 6.3 V | Taiyo Yuden | JMK105B7224KV-F | digikey | 587-2475 | yes
11 | 4 | C30,C149,C157,C186 | Capacitor_SMD:C_0402_1005Metric | 470n | 10% | X5R | 6.3 V | TDK | CGA2B3X7S1A474M050BB | digikey | 445-16101 | yes
12 | 13 | C31,C66,C67,C68,C69,C90,C130,C132,C133,C134,C150,C158,C187 | Capacitor_SMD:C_0402_1005Metric | 1u | 20% | X5R | 10 V | Samsung | CL05A105MP5NNNC | digikey | 1276-1448 | yes
13 | 16 | C32,C33,C55,C56,C57,C65,C74,C76,C116,C117,C119,C120,C124,C127,C151,C152 | Capacitor_SMD:C_0402_1005Metric | 4u7 | 10% | X5R | 6.3 V | TDK | C1005X5R0J475K050BC | digikey | 445-5947 | yes
14 | 3 | C44,C62,C168 | Capacitor_SMD:CP_Elec_5x5.9 | 220u | 20% |  | 6.3 V | Panasonic | EEE-FT0J221AR | digikey | P15078 | yes
15 | 7 | C53,C54,C63,C64,C111,C114,C159 | Capacitor_SMD:C_1206_3216Metric | 100u | 20% | X5R | 6.3 V | Murata | GRM31CR60J107ME39L | digikey | 490-4539 | yes
16 | 1 | C58 | Capacitor_SMD:C_0402_1005Metric | 3n3 | 5% | X7R | 25 V | Samsung | CL05B332JA5NNNC | digikey | 1276-1547 | yes
17 | 1 | C59 | Capacitor_SMD:CP_Elec_6.3x7.7 | 100u | 20% |  | 25 V | Panasonic | EEE-FPE101XAP | digikey | PCE4546 | yes
18 | 8 | C70,C71,C72,C73,C110,C112,C113,C115 | Capacitor_SMD:C_0402_1005Metric | 10u | 20% | X5R | 6.3 V | Samsung | CL05A106MQ5NUNC | digikey | 1276-1451 | yes
19 | 1 | D1 | LED_SMD:LED_0402_1005Metric | LED_Green |  |  |  | Kingbright | APHHS1005LCGCK | digikey | 754-2121 | yes
20 | 1 | D2 | LED_SMD:LED_0402_1005Metric | LED_Red |  |  |  | Kingbright | APHHS1005SURCK | digikey | 754-1104 | yes
21 | 1 | D3 | Diode_SMD:D_0402_1005Metric | ESD9X5.0ST5G |  |  |  | ON Semi | ESD9X5.0ST5G | digikey | ESD9X5.0ST5GOSDKR | no
22 | 9 | FB1,FB2,FB11,FB13,FB22,FB23,FB24,FB25,FB26 | Resistor_SMD:R_0402_1005Metric | 60 |  |  |  | Murata | BLM15PX600SN1D | digikey | 490-11023 | yes
23 | 1 | J1 | Connectors_OSRF:SAMTEC_ERF8-020 | HIGH-SPEED EXP |  |  |  | Samtec | ERF8-020-05.0-S-DV-K | digikey | SAM8619 | no
24 | 1 | J2 | Samtec:SAMTEC_QRM8-026-02.0-L-D-A-GP | Samtec QRM8 |  |  |  | Samtec | QRM8-026-02.0-L-D-A-GP | digikey | SAM11585 | no
25 | 10 | J3,J4,J5,J6,J7,J8,J9,J10,J12,J13 | Connector_PinHeader_2.54mm:PinHeader_1x05_P2.54mm_Vertical | AUXIO |  |  |  | DNP | DNP | DNP | DNP | DNP
26 | 1 | J11 | Connector_Molex:Molex_PicoBlade_53047-0810_1x04_P1.25mm_Vertical | FAN |  |  |  | Molex | 530470410 | digikey | WM1733 | yes
27 | 7 | Q1,Q2,Q3,Q4,Q5,Q6,Q14 | Package_TO_SOT_SMD:SOT-323_SC-70 | NTS4001NT1G |  |  |  | ON Semi | NTS4001NT1G | digikey | NTS4001NT1GOS | no
28 | 2 | R1,R7 | Resistor_SMD:R_0402_1005Metric | 470 | 1% |  |  | Panasonic | ERJ-2RKF4700X | digikey | P470L | yes
29 | 12 | R2,R3,R4,R5,R6,R8,R14,R22,R23,R24,R26,R30 | Resistor_SMD:R_0402_1005Metric | 10k | 1% |  |  | Panasonic | ERJ-2RKF1002X | digikey | P10.0KL | yes
30 | 1 | R9 | Resistor_SMD:R_0402_1005Metric | 1M | 1% |  |  | Panasonic | ERJ-2RKF1004X | digikey | P1.00ML | yes
31 | 1 | R10 | Resistor_SMD:R_0402_1005Metric | 2k87 | 0.1% |  |  | Panasonic | ERA-2AEB2871X | digikey | P2.87KDC | yes
32 | 4 | R11,R12,R15,R18 | Resistor_SMD:R_0402_1005Metric | 51k | 0.1% |  |  | Panasonic | ERA-2AEB513X | digikey | P51KDC | yes
33 | 1 | R13 | Resistor_SMD:R_0402_1005Metric | 71k5 | 0.1% |  |  | Panasonic | ERA-2AEB7152X | digikey | P71.5KDC | yes
34 | 1 | R16 | Resistor_SMD:R_0402_1005Metric | 11k3 | 0.1% |  |  | Panasonic | ERA-2AEB1132X | digikey | P11.3KDC | yes
35 | 3 | R17,R20,R21 | Resistor_SMD:R_0805_2012Metric | 5R1 | 1% |  |  | Vishay | CRCW08054R99FKEAHP | digikey | 541-4.99T | yes
36 | 1 | R19 | Resistor_SMD:R_0402_1005Metric | 25k5 | 0.1% |  |  | Panasonic | ERA-2AEB2552X | digikey | P25.5KDC | yes
37 | 3 | R25,R32,R61 | Resistor_SMD:R_0402_1005Metric | 100 | 1% |  |  | Panasonic | ERJ-2RKF1000X | digikey | P100L | yes
38 | 1 | R27 | Resistor_SMD:R_0402_1005Metric | 100k | 1% |  |  | Panasonic | ERJ-2RKF1003X | digikey | P100KL | yes
39 | 2 | R31,R39 | Resistor_SMD:R_0402_1005Metric | 2k | 1% |  |  | Panasonic | ERJ-2RKF2001X | digikey | P2.00KL | yes
40 | 2 | R34,R36 | Resistor_SMD:R_0402_1005Metric | 1k | 1% |  |  | Panasonic | ERJ-2RKF1001X | digikey | P1.00KL | yes
41 | 2 | R35,R62 | Resistor_SMD:R_0402_1005Metric | 47k | 1% |  |  | Panasonic | ERJ-2RKF4702X | digikey | P47.0KL | yes
42 | 2 | R56,R57 | Resistors_SMD:R_0603 | 47 |  |  |  | Yageo | RC0603FR-0747RL | digikey | 311-47.0HR | yes
43 | 2 | R58,R60 | Resistors_SMD:R_0603 | 1k |  |  |  | Yageo | ERJ-3EKF1001V | digikey | P1.00KH | yes
44 | 2 | U1,U2 | ONSemi:ONSEMI-LCC48-1.016 | NOIP1SN1300A-QDI |  |  |  | ON Semi | NOIP1SN1300A | Avnet | NOIP1SN1300A-QTI | no
45 | 1 | U3 | BGA:INTEL_F672 | 10CXyyy_F672 |  |  |  | Intel | 10CX220YF672E6G | digikey | 544-3426 | no
46 | 2 | U4,U15 | IMU:VN-100 | VN-100 |  |  |  | DNP | DNP | DNP | DNP | DNP
47 | 5 | U5,U10,U12,U18,U19 | Housings_SSOP:VSSOP-8_2.3x2mm_Pitch0.5mm | SN74LVC2T45 |  |  |  | TI | SN74LVC2T45DCUR | digikey | 296-17014 | no
48 | 3 | U6,U7,U16 | DCDC:MPM3630 | MPM3630 |  |  |  | Monolithic Power | MPM3630GQV-P | digikey | 1589-1253 | no
49 | 1 | U8 | DCDC:TI_RVQ_42 | LMZ31707 |  |  |  | TI | LMZ31707RVQT | digikey | 296-37136 | no
50 | 1 | U9 | Sensor_Motion:InvenSense_QFN-24_3x3mm_P0.4mm | ICM20948 |  |  |  | TDK | ICM-20948 | digikey | 1428-1123 | no
51 | 1 | U11 | LED_RGB:APA102_2020 | led_dotstar_micro |  |  |  | Adafruit | 3341 | digikey | 1528-1826 | no
52 | 2 | U13,U20 | Package_SO:TSSOP-24_4.4x7.8mm_P0.65mm | SN74AVC8T245 |  |  |  | TI | SN74AVC8T245PWR | digikey | 296-19100 | no
53 | 1 | U14 | Housings_SSOP:TSSOP-16_4.4x5mm_Pitch0.65mm | SN74AVC4T245 |  |  |  | TI | SN74AVC4T245PWR | digikey | 296-18056 | no
54 | 1 | U17 | TO_SOT_Packages_SMD:SOT-353_SC-70-5 | 74LVC1G34 |  |  |  | TI | SN74LV1T34DCKR | digikey | 296-37177 | no
55 | 1 | X1 | Oscillators:Oscillator_SMD_Abracon_ASE-4pin_3.2x2.5mm | ASEMB-100MHz |  |  |  | Abracon | ASEMB-100.000MHZ-LY-T | digikey | 535-11083 | no

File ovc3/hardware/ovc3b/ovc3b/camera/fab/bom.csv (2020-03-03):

# Bill of Materials for 'ovc3' rev.a
# Schematic date: Tue Mar 3 14:26:17 2020
Line Item | Quantity | Designator | Footprint | Value | Tolerance | Thermal | Voltage | Manufacturer | Manufacturer Part Number | Distributor | Distributor Part Number | Substitution OK?
1 | 9 | C1,C2,C3,C16,C17,C20,C21,C52,C67 | Capacitor_SMD:C_0402_1005Metric | 1u |  |  |  | Samsung | CL05A105KA5NQNC | Digikey | 1276-1445-1-ND
2 | 55 | C4,C5,C6,C7,C8,C10,C11,C12,C13,C14,C15,C26,C27,C28,C29,C30,C31,C36,C37,C38,C39,C40,C41,C44,C47,C48,C49,C50,C51,C53,C54,C55,C56,C57,C58,C59,C60,C61,C62,C63,C64,C65,C66,C69,C70,C71,C72,C73,C74,C80,C81,C84,C85,C86,C87 | Capacitor_SMD:C_0402_1005Metric | 100n |  |  |  | Murata | GRM155R61H104KE19D | Digikey | 490-11917-1-ND
3 | 1 | C9 | Capacitor_SMD:C_0402_1005Metric | 3n3 |  |  |  | Samsung | CL05B332KB5NNNC | Digikey | 1276-1552-1-ND
4 | 1 | C18 | Capacitor_SMD:CP_Elec_6.3x7.7 | 680u |  |  |  | Panasonic | EEE-FTJ681XAP | Digikey | P15097TR-ND
5 | 1 | C19 | Capacitor_SMD:C_0603_1608Metric | 4u7 |  |  |  | Samsung | CL10A475KA8NQNC | Digikey | 1276-1900-1-ND
6 | 13 | C22,C23,C24,C25,C32,C33,C34,C35,C42,C43,C45,C46,C68 | Capacitor_SMD:C_0402_1005Metric | 10u |  |  |  | Samsung | CL05A106MP8NUB8 | Digikey | 1276-6830-1-ND
7 | 2 | C75,C76 | Capacitor_SMD:C_0603_1608Metric | 22u |  |  |  | Murata | GRM188R60J226MEA0D | Digikey | 490-7611-1-ND
8 | 1 | C77 | Capacitor_SMD:C_1206_3216Metric | 100u |  |  |  | Murata | GRM31CR60J107ME39K | Digikey | 490-7217-1-ND
9 | 2 | C78,C82 | Capacitor_SMD:C_1206_3216Metric | 22u |  |  |  | Samsung | CL31A226KAHNNNE | Digikey | 1276-3047-1-ND
10 | 2 | C79,C83 | Capacitor_SMD:C_1206_3216Metric | 47u |  |  |  | Samsung | CL31A476MQHNNNE | Digikey | 1276-1167-1-ND
11 | 2 | D1,D7 | LED_SMD:LED_0402_1005Metric | LED |  |  |  | Vishay | VLMS1500-GS08 | Digikey | VLMS1500-GS08CT-ND
12 | 3 | D2,D3,D8 | LED_SMD:LED_0402_1005Metric | LED |  |  |  | Lumex Opto | SML-LX0402SUGC-TR | Digikey | 67-1881-1-ND
13 | 1 | D4 | Package_TO_SOT_SMD:SOT-23 | ESD7002WTT1G |  |  |  | ON Semiconductor | ESD7002WTT1G | Digikey | ESD7002WTT1GOSCT-ND
14 | 1 | D5 | Diode_SMD:D_SMB | SMBJ22A |  |  |  | Bourns | SMBJ22A | Digikey | SMBJ22ABCT-ND
15 | 1 | D6 | Diode_SMD:D_SOD-323 | SDMK0340L-7-F |  |  |  | Diodes Inc | SDMK0340L-7-F | Digikey | SDMK0340L-FDICT-ND
16 | 1 | D9 | Diode_SMD:D_SOD-128 | PMEG3030EP | 115 |  |  |  | Nexperia | PMEG3030EP | 115 | Digikey | 1727-5324-1-ND
17 | 6 | J1,J2,J4,J5,J11,J12 | LensHolder:LENS_HOLDER_20MM_PT-LH010M | MIDDLE_LENS |  |  |  | DNP | DNP | DNP | DNP
18 | 1 | J3 | USB:USB_C_Receptacle_Wurth_632723300011 | USB_C_Receptacle |  |  |  | Wurth | 632723300011 | Digikey | 732-9618-1-ND
19 | 1 | J6 | Connector_PinHeader_2.00mm:PinHeader_2x08_P2.00mm_Vertical | FRONT_PACK |  |  |  | NRPN082PAEN-RC | Sullins | Digikey | S5801-08-ND
20 | 1 | J7 | Connector_Card:microSD_HC_Hirose_DM3BT-DSF-PEJS | Micro_SD_Card_Det_Hirose_DM3BT |  |  |  | Hirose | DM3BT-DSF-PEJS | Digikey | HR1942CT-ND
21 | 1 | J8 | Connector_Molex:Molex_Nano-Fit_105313-xx02_1x02_P2.50mm_Horizontal | AUX_PWR |  |  |  | Molex | 1053131302 | Digikey | WM15141-ND
22 | 4 | J9,J10,J13,J14 | Connectors_OSRF:MOLEX_505110_2691 | BONUS1 |  |  |  | Molex | 5051102691 | Digikey | WM24281CT-ND
23 | 1 | CONN1 | undefined | Trenz_conn_dummy |  |  |  | Samtec | LSHM-130-04.0-L-DV-A-S-K-TR | Digikey | SAM9034CT-ND
24 | 2 | CONN2,CONN3 | undefined | Trenz_conn_dummy |  |  |  | Samtec | LSHM-150-04.0-L-DV-A-S-K-TR | Digikey | SAM9033CT-ND
25 | 2 | Q1,Q2 | Package_TO_SOT_SMD:SOT-23 | SI2369DS |  |  |  | Vishay | SI2369DS-T1-GE3 | Digikey | SI2369DS-T1-GE3CT-ND
26 | 3 | R1,R4,R6 | Resistor_SMD:R_0402_1005Metric | 100k |  |  |  | Panasonic | ERA-2AED104X | Digikey | P100KDECT-ND
27 | 9 | R2,R3,R12,R13,R21,R22,R26,R32,R34 | Resistor_SMD:R_0402_1005Metric | 10k |  |  |  | Panasonic | ERA-2AED103X | Digikey | P10KDECT-ND
28 | 2 | R5,R28 | Resistor_SMD:R_0402_1005Metric | 22k |  |  |  | Panasonic | ERJ-2RKF2202X | Digikey | P22.0KLCT-ND
29 | 1 | R7 | Resistor_SMD:R_0402_1005Metric | 100R |  |  |  | Panasonic | ERA-2AED101X | Digikey | P100DECT-ND
30 | 1 | R8 | Resistor_SMD:R_0603_1608Metric | 1k |  |  |  | Panasonic | ERJ-PA3F1001V | Digikey | P1.0KBYCT-ND
31 | 6 | R9,R16,R17,R18,R19,R20 | Resistor_SMD:R_0402_1005Metric | 2k2 |  |  |  | Panasonic | ERJ-2RKF2201X | Digikey | P2.20KLCT-ND
32 | 1 | R10 | Resistor_SMD:R_0402_1005Metric | 90k9 |  |  |  | Panasonic | ERA-2AEB9092X | Digikey | P90.9KDCCT-ND
33 | 1 | R11 | Resistor_SMD:R_0402_1005Metric | 316R |  |  |  | Panasonic | ERJ-2RKF3160X | Digikey | P316LCT-ND
34 | 5 | R14,R15,R23,R29,R30 | Resistor_SMD:R_0402_1005Metric | 330R |  |  |  | Panasonic | ERJ-2GEJ331X | Digikey | P330JCT-ND
35 | 1 | R24 | Resistor_SMD:R_0402_1005Metric | 470 |  |  |  | Panasonic | ERJ-2RKF4700X | Digikey | P470LCT-ND
36 | 2 | R25,R27 | Resistor_SMD:R_0402_1005Metric | 1k |  |  |  | Panasonic | ERJ-2RKF1001X | Digikey | P1.00KLCT-ND
37 | 2 | R31,R33 | Resistor_SMD:R_0402_1005Metric | 143k |  |  |  | KOA Speer | RN73H1ETTP1433B50 | Digikey | 2019-RN73H1ETTP1433B50CT-ND
38 | 2 | U1,U2 | ONSemi:BGA-72_9x8_5.545x5.565mm | AR0144CS |  |  |  | ON Semiconductor | AR0144CSSM00SUKA0-CPBR2 | Digikey | AR0144CSSM00SUKA0-CPBR2OS-ND
39 | 1 | U3 | Sensor_Motion:InvenSense_QFN-24_3x3mm_P0.4mm | ICM-20948 |  |  |  | TDK InvenSense | ICM-20948 | Digikey | 1428-1123-1-ND
40 | 1 | U4 | ONSemi:BGA-72_9x8_5.545x5.565mm | AR0144CS |  |  |  | ON Semiconductor | AR0144CSSC00SUKA0-CPBR2 | Digikey | AR0144CSSC00SUKA0-CPBR2OS-ND
41 | 1 | U5 | Package_DFN_QFN:QFN-24-1EP_4x4mm_P0.5mm_EP2.7x2.7mm | STUSB4500 |  |  |  | STMicroelectronics | STUSB4500QTR | Mouser | 511-STUSB4500QTR
42 | 1 | U6 | USB:TI_R_PUQFN_N16 | HD3SS3202 |  |  |  | Texas Instruments | HD3SS3202IRSVR | Digikey | 296-51121-1-ND
43 | 1 | U7 | DCDC:TI_RVQ_42 | LMZ31707 |  |  |  | Texas Instruments | LMZ31707RVQR | Digikey | 296-37921-1-ND
44 | 1 | U8 | Package_SO:TSSOP-16_4.4x5mm_P0.65mm | SN74AXC4T245 |  |  |  | Texas Instruments | SN74AXC4T245PWR | Digikey | 296-53472-1-ND
45 | 1 | U9 | Ethernet:ARJ11C-MBSAS-A-BA-7MU2 | ARJ11C-MBSAS-A-BA-7MU2 |  |  |  | Abracon | ARJ11C-MBSAS-A-BA-7MU2 | Mouser | 815-RJ1CMBSASABA7MU2
46 | 2 | U10,U12 | Package_TO_SOT_SMD:SOT-23-5 | LP5907MFX-2.8 |  |  |  | Texas Instruments | LP5907MFX-2.8/NOPB | Digikey | 296-39063-1-ND
47 | 1 | U11 | TI:Texas_VQFN-HR-12_2x2.5_Pitch0.5mm | TPS2121 |  |  |  | Texas Instruments | TPS2121RUXR | Digikey | 296-53410-1-ND
48 | 1 | U13 | WQFN:TI_RTW0024B | TXS02612 |  |  |  | Texas Instruments | TXS02612RTWR | Digikey | 296-23869-1-ND
49 | 1 | U14 | Package_SON:WSON-6-1EP_2x2mm_P0.65mm_EP1x1.6mm | TVS1800DRV |  |  |  | TI | TVS1800DRVR | Digikey | 296-52186-1-ND
50 | 1 | U15 | DCDC:Converter_DCDC_Intel_QFN-24_4x6mm_P0.65mm_ThermalVias | EN5322QI |  |  |  | Intel | EN5322QI | Digikey | 544-2849-1-ND
51 | 1 | U16 | Package_SO:TSSOP-24_4.4x7.8mm_P0.65mm | SN74AXCH8T245 |  |  |  | Texas Instruments | SN74AXCH8T245PWR | Digikey | 296-50281-1-ND
52 | 2 | U17,U18 | Package_SO:VSSOP-8_3.0x3.0mm_P0.65mm | TCA9803 |  |  |  | Texas Instruments | TCA9803DGKR | Digikey | 296-47829-1-ND
53 | 1 | SW1 | Button_Switch_SMD:SW_DIP_SPSTx04_Slide_6.7x11.72mm_W8.61mm_P2.54mm_LowProfile | SW_DIP_x04 |  |  |  | Wurth | 418121270804 | Digikey | 732-6963-1-ND

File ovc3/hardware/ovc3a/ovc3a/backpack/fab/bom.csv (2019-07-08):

# Bill of Materials for 'OVC BACKPACK' rev.A
# Schematic date: Mon Jul 8 23:24:45 2019
Line Item | Quantity | Designator | Footprint | Value | Manufacturer | Manufacturer Part Number
1 | 5 | C1,C4,C5,C8,C23 | Capacitor_SMD:C_0603_1608Metric | 10u | Murata | GRM188R61A106KE69D
2 | 19 | C2,C3,C6,C7,C9,C10,C11,C12,C13,C14,C15,C16,C17,C18,C19,C21,C24,C25,C26 | Capacitor_SMD:C_0603_1608Metric | 100n | Samsung | CL10B104KO8NNNC
3 | 2 | C20,C22 | Capacitor_SMD:C_0603_1608Metric | 47p | Murata | GCM1885C2A470JA16D
4 | 1 | D1 | LED_SMD:LED_0603_1608Metric | RXLED | Lite-On | LTST-C191KRKT
5 | 1 | D2 | LED_SMD:LED_0603_1608Metric | TXLED | Lite-On | LTST-C191KGKT
6 | 2 | FB1,FB2 | Resistor_SMD:R_0603_1608Metric | ferrite | Murata | BLM18KG601SN1D
7 | 1 | J1 | Connector_Molex:Molex_Nano-Fit_105313-xx05_1x05_P2.50mm_Horizontal | GPIO1 | Molex | WM15144-ND
8 | 1 | J2 | Connector_PinHeader_1.27mm:PinHeader_2x15_P1.27mm_Vertical | TO_CAMERA | Amphenol/FCI | 20021111-00030T4LF
9 | 5 | J3,J6,J7,J8,J9 | DNP | DNP | DNP | DNP
10 | 1 | J4 | Connector_Molex:Molex_Nano-Fit_105313-xx03_1x03_P2.50mm_Horizontal | RS232 | Molex | WM15142-ND
11 | 1 | J5 | Connector_USB:USB_Micro-B_Wuerth_629105150521_CircularHoles | USB_B_Micro | Wurth | 629105150521
12 | 2 | R1,R2 | Resistor_SMD:R_0603_1608Metric | 27R | Yageo | RC0603FR-0727RL
13 | 2 | R3,R4 | Resistor_SMD:R_0603_1608Metric | 270R | Yageo | RC0603FR-07270RL
14 | 2 | R5,R6 | Resistor_SMD:R_0603_1608Metric | 10k | Yageo | RC0603FR-0710KL
15 | 2 | U1,U9 | DNP | DNP | DNP | DNP
16 | 2 | U2,U3 | Package_SO:SOIC-16W_7.5x10.3mm_P1.27mm | ISOW7842 | Texas Instruments | ISOW7842DWER
17 | 1 | U4 | Package_SO:TSSOP-16_4.4x5mm_P0.65mm | MAX3221E | Texas Instruments | MAX3221EIPWR
18 | 2 | U5,U6 | Package_SO:TSSOP-24_4.4x7.8mm_P0.65mm | SN74AXCH8T245 | Texas Instruments | SN74AXCH8T245PWR
19 | 1 | U7 | Package_SO:VSSOP-8_2.3x2mm_P0.5mm | SN74AVCH2T45 | Texas Instruments | SN74AVCH2T45DCUT
20 | 1 | U8 | Package_SO:SSOP-16_3.9x4.9mm_P0.635mm | FT230XS | FTDI | FT230XS-R

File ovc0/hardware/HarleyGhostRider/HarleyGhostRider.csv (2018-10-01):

Line item # | Qty | Designator | Value | MFN | MFP | D1 | D1PN | D1PL | D2 | D2PN | D2PL
1 | 1 | U1 | xc7a100tcsg324pkg | Xilinx | XC7A100T-2CSG324I | digikey | 122-1881 | http://www.digikey.com/product-detail/en/XC7A100T-2CSG324I/122-1881-ND/3925808 | _ | _ | _
2 | 1 | U3 | TPS72718DSET | Texas Instruments | TPS72718DSET | digikey | 296-25192 | http://www.digikey.com/product-detail/en/texas-instruments/TPS72718DSET/296-25192-1-ND/2171357 | mouser | _ | _
3 | 1 | U8 | IC10pins | Littelfuse Inc | SP3010-04UTG | digikey | F3507 | http://www.digikey.com/product-detail/en/SP3010-04UTG/F3507CT-ND/2297266 | mouser | _ | _
4 | 1 | U6 | MT41K128M16 | Micron | MT41K128M16JT-125:K | arrow | MT41K128M16JT-125:K | https://www.arrow.com/en/products/mt41k128m16jt-125ktr/micron-technology | mouser | _ | _
5 | 4 | FB1;FB2;FB3;FB4 | 600 | TDK | MPZ1608S601ATA00 | digikey | 445-2205 | http://www.digikey.com/product-detail/en/MPZ1608S601ATA00/445-2205-1-ND/765103 | mouser | _ | _
6 | 2 | U2;U7 | LTM4622 | Linear | LTM4622EY#PBF | digikey | LTM4622EY#PBF | http://www.digikey.com/product-detail/en/LTM4622EY%2523PBF/LTM4622EY%2523PBF-ND/5965236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 | mouser | _ | _
7 | 1 | J1 | USB_3.1_microB | Amphenol Commercial Products | GSB443133HR | digikey | GSB443133HR | http://www.digikey.com/product-detail/en/GSB443133HR/GSB443133HRCT-ND/4936161 | mouser | _ | _
8 | 1 | R2 | 80.6 | Panasonic | ERJ-1GEF80R6C | digikey | P80.6AB | http://www.digikey.com/product-detail/en/ERJ-1GEF80R6C/P80.6ABCT-ND/1467375 | mouser | _ | _
9 | 1 | R15 | 6.04k | Panasonic | ERJ-1GEF6041C | digikey | P6.04KABTR | https://www.digikey.com/product-detail/en/ERJ-1GEF6041C/P6.04KABTR-ND/1467094 | mouser | _ | _
10 | 1 | R11 | 240 | Panasonic | ERJ-1GEF2400C | digikey | P240AB | http://www.digikey.com/product-detail/en/ERJ-1GEF2400C/P240ABDKR-ND/575358 | mouser | _ | _
11 | 1 | J3;P2 | CONN_02X02 | DNP | DNP | digikey | DNP | DNP | mouser | DNP | DNP
12 | 2 | R24;R25 | R | DNP | DNP | digikey | DNP | DNP | mouser | _ | _
13 | 1 | P1 | CONN_02X50 | Hirose | DF40C-100DP-0.4V(51) | digikey | H11614 | http://www.digikey.com/product-detail/en/DF40C-100DP-0.4V%2851%29/H11614CT-ND/1969494 | mouser | 798-DF40C100DP0.4V51 | http://www.mouser.com/ProductDetail/Hirose-Electric/DF40C-100DP-04V51/
14 | 1 | U9 | CYUSB3014 | Cypress | CYUSB3014-BZXC | digikey | 428-3182 | http://www.digikey.com/product-detail/en/CYUSB3014-BZXC/428-3182-ND/3679585 | mouser | 727-CYUSB3014-BZXC | http://www.mouser.fr/ProductDetail/Cypress-Semiconductor/CYUSB3014-BZXC/?qs=xP2cAaN2A3Wt%252bQariFLwRg%3d%3d
15 | 1 | R10 | 90.9k | Vishay | CRCW040290K9FKED | digikey | 541-90.9KL | http://www.digikey.com/product-detail/en/CRCW040290K9FKED/541-90.9KLCT-ND/1183346 | mouser | _ | _
16 | 1 | R13 | 60.4k | Vishay | CRCW040260K4FKED | digikey | 541-60.4KL | http://www.digikey.com/product-detail/en/CRCW040260K4FKED/541-60.4KLCT-ND/1183326 | mouser | _ | _
17 | 1 | R8 | 48.7k | Vishay | CRCW040248K7FKED | digikey | 541-48.7KL | http://www.digikey.com/product-detail/en/CRCW040248K7FKED/541-48.7KLCT-ND/1183315 | mouser | _ | _
18 | 2 | R20;R22 | 200 | Vishay | CRCW0402200RFKED | digikey | 541-200L | http://www.digikey.com/product-detail/en/CRCW0402200RFKED/541-200LCT-ND/1183041 | mouser | _ | _
19 | 1 | R9 | 19.1k | Vishay | CRCW040219K1FKED | digikey | 541-19.1KL | http://www.digikey.com/product-detail/en/CRCW040219K1FKED/541-19.1KLTR-ND/1178151 | mouser | _ | _
20 | 3 | R1;R19;R21 | 4.7k | Vishay | CRCW02014K70FKED | digikey | 541-4.70KAAB | http://www.digikey.com/product-detail/en/CRCW02014K70FKED/541-4.70KAABCT-ND/1968253 | mouser | _ | _
21 | 1 | R12 | 2k | Vishay | CRCW02012K00FNED | digikey | 541-2.00KAB | http://www.digikey.com/product-detail/en/CRCW02012K00FNED/541-2.00KABCT-ND/2720672 | mouser | _ | _
22 | 1 | R16 | 200 | Vishay | CRCW0201200RFKED | digikey | 541-200AAB | http://www.digikey.com/product-detail/en/CRCW0201200RFKED/541-200AABCT-ND/1968199 | mouser | _ | _
23 | 1 | R23 | 1M | Vishay | CRCW02011M00FNED | digikey | 541-1.00MAB | http://www.digikey.com/product-detail/en/CRCW02011M00FNED/541-1.00MABTR-ND/1178507 | mouser | _ | _
24 | 2 | R6;R7 | 1k | Vishay | CRCW02011K00FNED | digikey | 541-1.00KAB | http://www.digikey.com/product-detail/en/CRCW02011K00FNED/541-1.00KABCT-ND/1183599 | mouser | _ | _
25 | 3 | R3;R17;R18 | 10k | Vishay | CRCW020110K0FNED | digikey | 541-10.0KABTR | http://www.digikey.com/product-detail/en/CRCW020110K0FNED/541-10.0KABTR-ND/1178493 | mouser | _ | _
26 | 1 | C104 | 100u | TDK | C3216X5R0J107M160AB | digikey | 445-6008 | http://www.digikey.com/product-detail/en/C3216X5R0J107M160AB/445-6008-1-ND/2444049 | mouser | _ | _
27 | 8 | C29;C33;C64;C65;C105;C118;C131;C148 | 47u | TDK | C2012X5R1A476M125AC | digikey | 445-8239 | http://www.digikey.com/product-detail/en/C2012X5R1A476M125AC/445-8239-1-ND/2812081 | mouser | _ | _
28 | 4 | C61;C74;C82;C102 | 22u | TDK | C2012X5R0J226K125AB | digikey | 445-7679 | http://www.digikey.com/product-detail/en/C2012X5R0J226K125AB/445-7679-1-ND/2733751 | mouser | _ | _
29 | 2 | C2;C47 | 10u | TDK | C1608X5R1A106M080AC | digikey | 445-6853 | http://www.digikey.com/product-detail/en/tdk-corporation/C1608X5R1A106M080AC/445-6853-1-ND/2619215 | mouser | _ | _
30 | 1 | C126 | 4.7n | TDK | C1005X7S2A472K050BB | digikey | 445-6026 | http://www.digikey.com/product-detail/en/C1005X7S2A472K050BB/445-6026-1-ND/2444067 | mouser | _ | _
31 | 5 | C1;C3;C44;C48;C160 | 10n | TDK | C1005X7R1C103K050BA | digikey | 445-1262 | http://www.digikey.com/product-detail/en/C1005X7R1C103K050BA/445-1262-1-ND/567728 | mouser | _ | _
32 | 16 | C106;C107;C109;C110;C113;C114;C127;C129;C132;C133;C141;C142;C143;C145;C152;C154 | 4.7u | TDK | C1005X5R0J475K050BC | digikey | 445-5947 | http://www.digikey.com/product-detail/en/C1005X5R0J475K050BC/445-5947-1-ND/2443987 | avnet | 810-C1005X5R0J475K | http://www.mouser.fr/ProductDetail/TDK/C1005X5R0J475K050BC/?qs=NRhsANhppD%2frOmlfBttPRA%3d%3d
33 | 1 | C90 | 2.2u | TDK | C1005X5R0J225K050BC | digikey | 445-6847 | http://www.digikey.com/product-detail/en/C1005X5R0J225K050BC/445-6847-1-ND/2619209 | mouser | _ | _
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

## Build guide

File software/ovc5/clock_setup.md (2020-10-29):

# Clocking

### 10G PCS/PMA reference clock

We need a 156.25 MHz clock for the XGMII transceiver logic, which eventually feeds high-speed serial lanes from MGT BB TX3/RX3 on FPGA pins K6P/K5N (TX) and J4P/J3N (RX) to the SFP+ connector on the ST1 carrier board via module pins C63/C65 and C66/C68.
The XU9 module itself doesn't have an oscillator connected to the UltraScale+ GTH reference clock pins; instead, they bring those pins down to the carrier board.
On the ST1 carrier board, there is a [Si5338B-B-GMR](https://www.silabs.com/documents/public/data-sheets/Si5338.pdf) clock generator IC that has a single-ended 100M clock feeding pin `IN3`.
We need to generate a 156.25 Mhz differential clock on the Si5338B `CLK3 A/B` pins, which become `CLK_REF2 P/N` on the ST1, which becomes `MGT_BB_REFCLK0` on the XU9 board, finally going to FPGA pins L8P/L7N.

The Si5338B `I2C_LSB` pin is LOW on the ST1 board.

The chip is complex and generating a register set is most easily done with their GUI, [ClockBuilder Pro](https://www.silabs.com/products/development-tools/software/clockbuilder-pro-software) but unfortunately SiLabs has chosen (bizarrely) not to make a Linux version of this program, at least at time of writing in October 2020.
I made a noble attempt to get it working under `wine` with various combinations of Windows architecture (32/64 bit) and emulated Windows versions, but it would crash whenever you tried to actually open up a wizard and set inputs/outputs, etc., and I gave up. Great sadness.

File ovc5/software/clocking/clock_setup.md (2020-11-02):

# Clocking

### 10G PCS/PMA reference clock

We need a 156.25 MHz clock for the XGMII transceiver logic, which eventually feeds high-speed serial lanes from MGT BB TX3/RX3 on FPGA pins K6P/K5N (TX) and J4P/J3N (RX) to the SFP+ connector on the ST1 carrier board via module pins C63/C65 and C66/C68.
The XU9 module itself doesn't have an oscillator connected to the UltraScale+ GTH reference clock pins; instead, they bring those pins down to the carrier board.
On the ST1 carrier board, there is a [Si5338B-B-GMR](https://www.silabs.com/documents/public/data-sheets/Si5338.pdf) clock generator IC that has a single-ended 100M clock feeding pin `IN3`.
We need to generate a 156.25 Mhz differential clock on the Si5338B `CLK3 A/B` pins, which become `CLK_REF2 P/N` on the ST1, which becomes `MGT_BB_REFCLK0` on the XU9 board, finally going to FPGA pins L8P/L7N.

The Si5338B `I2C_LSB` pin is LOW on the ST1 board.

The chip is complex and generating a register set is most easily done with their GUI, [ClockBuilder Pro](https://www.silabs.com/products/development-tools/software/clockbuilder-pro-software) but unfortunately SiLabs has chosen (bizarrely) not to make a Linux version of this program, at least at time of writing in October 2020.
I made a noble attempt to get it working under `wine` with various combinations of Windows architecture (32/64 bit) and emulated Windows versions, but it would crash whenever you tried to actually open up a wizard and set inputs/outputs, etc., and I gave up. Great sadness. Fortunately a kind colleague with a Windows machine loaded up ClockBuilder Pro and generated the registers.

### instantiating the PCS/PMA subsystem
Unfortunately the clock routes for this output of the clock generator on the ST1 are fully buried underneath the XU9 module, so it seems that we have to instantiate the PCS/PMA subsystem on the Zynq in order to route it back out another pin.
The SFP+ interface goes to FPGA transceiver pads K6/K5 and J3/J4, which is labeled as "Quad 224" in the pinout PDF. Our clock in L7/L8 also goes to this quad.
The 10G/25G block IP configuration tool wants the quad defined in XY, not quad number.
If I'm parsing Figure 1-8 correctly in UG1075 (page 48), it appears that Quad 224 is Quad X0Y1, with channels X0Y4-X0Y7, so TX3/RX3 in that quad is X0Y7.

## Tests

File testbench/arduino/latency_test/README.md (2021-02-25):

# latency tester

This is a little Arduino gadget using the [Adafruit Feather M4 Express board](https://learn.adafruit.com/adafruit-feather-m4-express-atsamd51)

It just measures the time between and stop triggers, and prints the elapsed number of milliseconds to the virtual serial port.
The start trigger can be any of:
 * sending the character `A` (upper-case `A`) from the host to the device over the virtual serial port (for example, `/dev/ttyACM0`)
 * voltage on the `A0` pin above 1.0v (do not exceed the chip's max voltage of 3.3v)

The stop trigger is:
 * sending the character `a` (lower-case `a`) from the host to the device over the virtual serial port.

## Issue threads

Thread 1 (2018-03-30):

Data Samples / Further Documentation

mjshiggins, 2018-03-30:
Hello! I'm sorry to leave this as an issue, but it seems like it might be the best place for others to find information if they are searching later, rather than resorting to email.

Are there any ROS bags available for download with captured data from the OVC2? I'm extremely interested in exploring this platform. I've looked through the OSRF website and other standard places, but I can't seem to find more info.

codebot, 2018-03-30:
Greetings, thanks for getting in touch.

I just added a [link to an overview presentation](https://docs.google.com/presentation/d/1NCimNJTRP6g3ESWhmaqi4t3dOprq7Yvne_JLeCTt3io/edit?usp=sharing) from last week to the README doc.

The device is very very fresh, so we haven't published any representative datasets yet. What kind of data would you like to see? Car, drone, etc.?

mjshiggins, 2018-03-30:
Thank you for the presentation, it's massively helpful to understand where the project is at now. Would I be correct in assuming the future direction is to integrate the IMU data to publish odometry and/or point clouds natively, similar to the ZED or the VI-Sensor (before they took it off the market when they were acquired)? Or is it meant to be a testbed for more traditional CV tasks, implemented on the FPGA?

codebot, 2018-03-30:
I'd say both :+1:

We're certainly interested in getting visual-inertial odometry running on the device, as well as publishing point clouds (i.e. ROS PointCloud2 messages). And yes over time, after careful profiling, deciding what steps of common pipelines can be ported over to the FPGA. This is a relatively painful process, so we're trying to be deliberate about choosing what to port.

We did AST corner detection first just because it's used in lots of software algorithms and was one of the longest processing steps in our pipeline (even with clever implementations like in OpenCV). Other upcoming candidates include image pyramid and gradients. Basically stuff that touches every pixel and only requires "local" buffering (e.g., AST only requires a 7-row rolling buffer) are good candidates, since FPGA's are relatively limited in SRAM... at least when compared to the GB's of DRAM available on a beefy computer module like the TX2.

To help both of these factors, we're considering bumping up to the new Cyclone 10 GX FPGA for the next rev, ideally over PCIe x4. That should give enough memory bandwidth to allow simultaneously writing the raw images, scaling pyramid, and horizontal/vertical gradients. That chip also has fun new features like hardware 32-bit floating-point support in the DSP blocks. But we're still working through all the ramifications of using it; it's pretty different in some ways (i/o banks, etc.) and going to a x4 link would require a relatively big 27mm FPGA package, which is kind of a bummer.

mjshiggins, 2018-03-30:
Awesome. Very, very cool. I'll stop littering your issue board with discussion, and I'll keep a close eye on this! I've been waiting for a VI successor for far too long.

Closed 2018-03-30.

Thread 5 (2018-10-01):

Manufacturing

andre-nguyen, 2018-10-01:
Hi there,

Are there any plans for osrf to have a manufacturing partner to build/sell/distribute this project? Alternatively, is anyone here looking into manufacturing these?

Cheers,

codebot, 2018-10-01:
Greetings

At the moment we are currently fixing a few known bugs in the design that we discovered in the "A" revision of ovc2. We will probably make a few to verify that those bugs are fixed and no further rework is required. Currently working on the longer-range plans; nothing is fully decided yet. Cheers

Closed 2018-10-01.

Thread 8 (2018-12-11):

oh noes, error reading IMU!

chenste, 2018-12-11:
Hello,

We are getting the following error from the OVC1 when we are trying to launch the driver:

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

We have not seen this error before. Do you have any idea on what would be causing it?

Best,
Steven

codebot, 2018-12-11:
Only on a single device? Happens every time or only sometimes? Happens even
after a full cold boot?

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

chenste, 2018-12-12:
Thanks for the response. It happened when we plugged in a VLP-16 into it, and also by itself. This also happens after a full cold boot.

We originally did not have this problem and was able to launch the driver, but had to replace the lens mounts. After we replaced the lens mounts, we now get this error every time. We have run the reconfigure_fpga.sh and init_fpga.sh scripts in separate boots but still have this error.

codebot, 2018-12-12:
Interesting. Was it powered when the VLP-16 was pluged in, or unpowered? I'm hoping static discharge didn't zap anything during the lens mount exchange, but it sounds suspicious.

Any chance that the new lens mounts or VLP wiring could be somehow shorting some pins or connector headers? If everything other than power+ethernet is unplugged, does anything change? If not, how about removing lens mounts?

Otherwise, the next level of debug would be to probe the IMU header (on bottom edge of board, underneath "AWESOMECAM") with a logic analyzer or oscilloscope and see if stuff is happening there. During the driver node startup, you should see some SPI traffic as it configures a few register settings, and after driver node startup, ideally you would see a 200 Hz pulse train on the `SYNC_OUT` pin and regular SPI traffic on {CS, SCK, MOSI, MISO} as it polls the readings.

The goal is just to try to figure out if the problem is "upstream" or "downstream" of the IMU.

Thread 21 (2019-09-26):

irregular IMU time stamps on ovc 0 and ovc 1

berndpfrommer, 2019-09-26:
When looking over the imu time stamps recorded for a data set, it looks like the time stamps are not all equally spaced. The IMU ran at 200Hz, so one would expect 0.005s between consecutive imu messages. But that's not what we are seeing.

For the Falcam, the recording was done on an Intel i5 laptop. It was reasonably busy, but not excessively, and I don't recall warnings about message drops from the rosbag record. Drivers and rosbag record were all running on the same host.

These are the timestamp-to-timestamp differences observed for the Falcam, aka ovc 0

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

Same, but now for the OVC1. Here, the driver was running on the TX2 which was connected via ethernet cable to the recording laptop.

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

Do you have any explanation as to why we are seeing time stamps like this? Could it be CPU load on the host that is running the driver? The OVC1 data is harder to explain, with what appears to be 400Hz spacing between some data.

codebot, 2019-09-26:
That's surprising. For the ovc0 case, I don't really know what's going on since I haven't been in that codebase for a while. If the host machine is fully unloaded, does this still occur? If you increase the priority of the driver-node process, does it get better performance?

For the ovc1 case, I haven't gathered data in that specific configuration before (usually I've saved the rosbags right on the TX2) but I suspect that at least some of the issues could be due to the ROS1 publisher missing messages. To bound the problem a bit, it would be interesting to try the experiment again on a fully unloaded recording laptop and see if anything is different. The publishers in that node currently only have a queue size of 2, since it was assumed that having "fresher" data is better than (eventually) getting all samples: https://github.com/osrf/ovc/blob/master/software/ovc1/ros/ovc/ovc_node.cpp#L138  You could try increase the queue to say 10 or 20 and see if you have fewer drops.

The really-small timesteps might be due to race conditions when the driver node adjusts the FPGA clock offset every second. Since the FPGA clock is not synced to the host clock, every 1 second the host driver adjusts its offset, and in between those 1-second steps it uses the FPGA clock to interpolate:
https://github.com/osrf/ovc/blob/master/software/ovc1/ros/ovc/ovc.cpp#L547-L550
We could be smarter in there about being more careful with time jumps. I thought this was working OK, but perhaps there are gremlins lurking in here:
https://github.com/osrf/ovc/blob/master/software/ovc1/ros/ovc/ovc.cpp#L728-L737

I am surprised at the number of 400 Hz offsets. I don't really have a good guess as to what's happening there, since the IMU is configured at startup to 200 Hz mode:
https://github.com/osrf/ovc/blob/master/software/ovc1/ros/ovc/ovc.cpp#L143

On another front, we are hoping that ovc3 can "fix" many/most of these problems because of the much tighter coupling between Linux and the FPGA portion on the Zynq chip. Is that data looking better?

berndpfrommer, 2019-09-26:
Morgan, super fast reply as always :)

As I no longer work at UPenn, doing more experiments with the ovcs is not easy. But luckily I have some bags for IMU calibration that have zero load (just recorded /imu). They also run a lot longer (one is 10h+).

For the Falcam, drivers and recording where obviously run on the laptop. The picture looks very different now (notice different y-range!): no more skips, but a few that are close to to 133Hz (0.0075). It's basically again 0.005 + 0.0025

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

For the OVC1, I happened to record on the TX2 as well, i.e. no load on the ethernet during recording, just on the SSD. Again, a totally different picture then before.

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

Not sure what to say other than "it's caused by load". Looking back over the ovc1 data from my first post: I forgot to mention that the TX2 in this scenario was running VIO and the fairly CPU greedy picoflexx driver, but not the planner. Still it's fair to say that the CPU was loaded probably around 3+ cores average.

BTW the VIO seemed to not care much about the noisy/missing time stamps, which is why I didn't notice them in the first place.

graphic-zhang, 2019-12-06:
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

HI, have you successful run VIO on this ovc, is this the best device for VIO ?

berndpfrommer, 2019-12-06:
Yes, the VIO works great on the ovc. You can find datasets and examples here:

https://daniilidis-group.github.io/grasp_multicam/

All taken with either the Falcam (ovc 0) or OVC 1.

graphic-zhang, 2019-12-07:
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
awesome,thank you very much.

Closed 2020-03-02.

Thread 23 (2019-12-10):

mechanical design files (ovc3a)

jpaulos, 2019-12-10:
Do simple mechanical drawings (dimensions, camera centers, hole placement) exist for either the ovc3a board or perhaps a reference design housing which would have the same information?

I can manually click around and extract this information from the KiCAD project -- is there a better way?

If such a document were created, where should it live in the repository?

luca-della-vedova, 2019-12-12:
Hi @jpaulos !

For now there is no such document. I think the easiest way to get basic information about the board (dimensions, hole placement, cameras baseline etc.) is to use the "Add dimension" feature of kicad.
If you wanted to create a document for this I would probably add all the dimensions to a custom layer then print the PCB by excluding all the unnecessary ones (i.e. copper), you should get a reasonable 2d drawing.

If you want 3d information instead, you might want to export the 3d model of the board as a step file and use a CAD software to edit it (i.e. freecad). We used the latter way in the past to verify board stacks and it works quite well.

Cheers,
/Luca

jpaulos, 2019-12-13:
Thanks for the tip about the "Add dimension" tool, through it seems like the ability to snap to centers that aren't on-grid is limited. I ended up doing this with a pencil.

Closed 2020-04-13.

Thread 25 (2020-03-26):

Some problems about ovc3b

ZiwangZhang, 2020-03-26:
Hi,
We want to reproduce the ovc3b but I have some problem on the hardware of ovc3b as following. I need your help.
1. I can not open the kiCAD project of ovc3b. It report that the project file is created by a newer version kiCAD. However, my kiCAD is the newest version.
2. The project lack of libraries. Can you provide all files, including PCB files, schematic diagram and libraries?

Thanks for your responding.

luca-della-vedova, 2020-03-26:
Hi!

We use kicad-nightly and you would also need to add the osrf_hw repository, the instructions on the bottom of the readme under Hardware should be up to date, did you try them?
I noticed that we forgot to add a step to add the KIWORKSPACE environment variable, just fixed it.

Cheers,
/Luca

ZiwangZhang, 2020-03-28:
Hi Luca,
Thanks for your suggestions again. I solve my problem. I still have two problem and need your answer.

1. I want to know that if there are some special requirement on the production process of PCB?
2. How can I get the plate layer order from PCB file to provide for manufacturer?

luca-della-vedova, 2020-03-29:
Hi Ziwang,

The main requirements (i.e. minimum via size, trace width etc.) are in the README in the fab subfolder of every archive. You can get the layer order from the kicad project (the layers are ordered in it).

Jingjing1219, 2020-03-29:
Hi Luca,

I have a question, there are two PCB board folders under the ovc3b folder, and there is no fab subfolder in the vectornav_carrier file, so how do we know the main requirements of vectornav_carrier board?

codebot, 2020-03-29:
We did not (yet) fabricate the `vectornav_carrier` board. It is much, much simpler than the "main" camera board. It's only needed if you want a "standard" Xilinx JTAG header, a VectorNav IMU, and a built-in USB-UART chip for the Linux root console. You can use hand-made adapters in the meantime.

I would suggest first just fabricating the `camera` board and only making `vectornav_carrier` after working out the bugs on the `camera` board, in case the bug-fixing requires major changes that could cascade into the `vectornav_carrier` board. I don't expect that to be the case, but hardware development is always tricky to predict.

Jingjing1219, 2020-03-30:
Hi,
Thank you for you reply.
I have questions about the second board vectornav_carrier.
What is the connection between the  vectornav_carrier board  and the camera board ?
If we only make the camera board, can we complete vision guided autonomous drone flight?

Best regards
Jing

luca-della-vedova, 2020-03-31:
The vectornav board is connected through a pin header that you can see in the left of the board, between the camera and the FPGA module.
Regarding autonomous flight it really depends on many factors and hardware is only one of them, the OVCs have been used in autonomous drones before, having a better IMU helps but might not be necessary depending on your scenarios, algorithms, etc.

Jingjing1219, 2020-04-06:
Hi,
What is the specific model of TE0820 in OVC3b camera board? We need to purchase TE0820, but there are too many types. We don't know which model to choose.

luca-della-vedova, 2020-04-06:
The model we are using is [the one based on the 03-EG class of FPGA](https://shop.trenz-electronic.de/en/TE0820-03-3BE21FA-MPSoC-Module-with-Xilinx-Zynq-UltraScale-ZU3EG-1E-2-GByte-DDR4-SDRAM-4-x-5-cm)

Closed 2020-04-13.

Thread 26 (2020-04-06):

About the camera used in ovc3b

Winifred-oss, 2020-04-06:
Hi,
We are trying to reproduce the ovc3b these days. The  project ovc3b provide us the lens holder PT-LH010M and the CMOS image sensor AR0144CS. However, we still don't know the version of the camera lens. Can you share the information about the camera lens with us?

Waiting for your reply!

luca-della-vedova, 2020-04-06:
Hi!

This is one of the questions where the answer is "it depends", I recommend thinking about your application and whether you need a wide field of view or a good range. Those lenses are very cheap so you can buy a few and play with them to see what works best.
Just make sure you buy a lens which is for the imager format!

Cheers,
/Luca

Closed 2020-04-10.

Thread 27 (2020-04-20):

The question about TE0820 in OVC3b.

Jingjing1219, 2020-04-20:
Hi,
The model you used in the ovc3b camera board TE0820-03-3BE21FA is no longer available. I want to know if it can be replaced with 4DE21FA without changing the circuit (because our PCB board has been made, only this chip is missing.)

Cheers,
Jingjing

luca-della-vedova, 2020-04-20:
That module seems to use the 4EV version of the FPGA, you can but you would need to rebuild your bitfiles for this chip and wouldn't be able to use the prebuilt ones (since for now we only support the 3EG chip).

Jingjing1219, 2020-04-20:
Many thanks.
And sorry, we don’t know FPGA at present, and we need follow-up learning (such as rebuild the bitfiles). So, is there a perfect alternative model for TE0820-03-3BE21FA?

luca-della-vedova, 2020-04-20:
The [TE0821](https://shop.trenz-electronic.de/en/TE0821-01-3BE21FA-MPSoC-Module-with-Xilinx-Zynq-UltraScale-ZU3EG-1-2-GByte-DDR4-SDRAM-4-x-5-cm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) is basically the same module

Jingjing1219, 2020-04-20:
Sorry, I want to confirm, do you mean we can use TE0821-01-3BE21FA instead of TE0820-03-3BE21FA without changing the circuit?
Or should we wait until TE0820-03-3BE21FA is available?
Many thanks.

luca-della-vedova, 2020-04-20:
I'm not sure on the top of my head (would double check their specs) but I think they are basically the same module

Jingjing1219, 2020-04-20:
Many thanks.

Closed 2020-04-20.

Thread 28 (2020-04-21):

About the vision algorithm

Winifred-oss, 2020-04-21:
We find many repositories in https://osrf.github.io/ovc/software.html can not be open, such as Real-time Semantic Segmentation, Stereo Image Splitter, GPU Accelerated Dense Stereo Disparity Estimation. More about the visual algorithms used in your experiment  [The Open Vision Computer: An Integrated Sensing and Compute System for Mobile Robots](https://arxiv.org/abs/1809.07674v1) are also not found in  http://open.vision.computer.
Thus, we wonder if  we could get your visual algorithm to duplicate your experiment (vision-based autonomous navigation of uav) after our hardware is finished?
Looking forward to your reply.

luca-della-vedova, 2020-04-22:
Hi,

I'm not sure what happened to the algorithm repos, they were developed by the people at the GRASP lab in University of Pennsylvania, as you can see from the paper however, most of the algorithms run on the ARM cores, meaning that they would be able to run with any ROS compatible camera.
The main benefit of the OVC for that application was the feature extraction happening in FPGA which, being one of the most computationally expensive tasks, made the pipeline much faster.
In general however autonomous navigation is a _hard task_ especially in a UAV and I personally think there isn't any quick and easy way to implement it.
I would recommend starting from each building block and studying the available options, then trying to assemble them one by one.
The camera (i.e. OVC) is only one of the blocks.

Good luck!

iandouglas96, 2020-04-22:
As luca noted, currently the autonomy pipeline described in the paper is not open-sourced (and it is not in a state such that it could be easily integrated anyway).  The state estimation portion is, and is available here: https://github.com/KumarRobotics/msckf_vio, though it is not specific to the ovc.  The planner and controller are not publicly available.

Closed 2020-05-04.

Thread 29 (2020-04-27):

request for information

AndreV84, 2020-04-27:
Hi Guys,
I am working on the integration of ROS [ moveit, rviz, etc] with Nvidia IsaaC SDK/ Jetson devices. I was advised to study your project as it uses nvidia hardware.
Could you let me know if your project supports nvidia jetson Xavier AGX/ nvidia jetson NXm nvidia jetson Nano hardware. please?
If it supports - is there a guide how to implement ovc with it? ovc3? ovc4?
Regards & Thanks

luca-della-vedova, 2020-04-27:
Hi!

We are working literally right now on OVC4 which will be based on the Xavier NX module.
Since the module is very new the development is still in its early stage but you can keep an eye on the repo and follow as it progresses.
We used OVC3 with Xavier AGX previously, OVC3 is just a USB 3 device so it should work on any Linux machine as long as it runs ROS on Linux and has the driver for USB networking (Ubuntu does by default).

/Luca

AndreV84, 2020-04-27:
Dear Luca,
Thank you for your response.
Could you point to some detailed guidelines on how to implement OVC 4m given I am totally a newbie with that particular project but have had extensive jetson experience before? Which hardware components will be required to construct the platform? Which custom software implementations will need to be made?
What is the extent of complexity for a new user to repeat your steps to implement ovc at their side?
Previously I used to follow up nvidia jetbot assembly and configuration.
Is ovc something like that? In term of complexity? https://github.com/NVIDIA-AI-IOT/jetbot/wiki Will ovc be much more difficult to implement from scratch for a newbie who never used ovc before? could you point out to documents to start getting familiar with the project, please?

luca-della-vedova, 2020-04-27:
OVC4 literally started a few weeks ago, right now the hardware itself is
still in the design stage. Until we finish the design it will not be
possible to build it (unless you finish the design yourself, but it's not
an easy task).
After finishing the hardware design we would need to go into firmware (i.e.
kernel modules for the cameras) and software (i.e. the ROS driver), before
all those steps are done I doubt it can be useful to an end user.

Once it is done I expect all you would need to do is fabricate the PCB (if
you are not sure how to do that you can outsource it to an external
company), buy a Xavier NX module and assemble everything together.
I expect it to be not too bad for someone who is familiar with Linux and
the Nvidia tools but can't be sure until the design is finished.

Apologies if I can't be more precise but we are still defining what OVC4
will look like since it's very early.

On Mon, Apr 27, 2020 at 9:14 PM Andrey Volodin <notifications@github.com>
wrote:

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

poudyalbot, 2020-05-01:
Will it support Jetson Nano.....
And will the camera and imu be hardware synchronised.

luca-della-vedova, 2020-05-02:
Hi!

Yes the cameras will be hardware synchronised (it's the main feature we are
building it for). Regarding Nano compatibility, we are designing for Xavier
NX which is mostly pin compatible. I expect you should be able to use most
features with Nano (except maybe some of the cameras since iirc the new
module supports more cameras in parallel.

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

poudyalbot, 2020-05-07:
Thank you for ur quick reply.
Looking forward to this project.

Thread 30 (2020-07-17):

Raspberry piv2 camera

poudyalbot, 2020-07-17:
Dear sir it seems like the ovc v4 is using Sony imx219 sensor so it is a rolling shutter camera won't it affect running visual odometry algorithms or visual inertial how do you solve the issue of rolling shutter or is my knowledge about this tech and camera very vague.
I hope you will reply
Thank you

luca-della-vedova, 2020-07-17:
Hi!

The rolling shutter problem cannot really be solved. We designed OVC4 using the Pi camera connector just for compatibility reasons but the software / firmware and kernel module are designed to allow easy interchanging of different camera modules so anyone can design their own with their imager of choice (we are testing on a few other imagers internally as well).

codebot, 2020-07-17:
Greetings! As @luca-della-vedova said, the connector on OVC4 is intended to allow easy swapping of imager modules. There is a complex tradeoff in the imager design space that the various chip companies have to perform. This is a complex topic but here is my current understanding:

Global-shutter imagers are great for fast-moving scenes, because you actually image the entire scene at the same, which is an assumption of many visual odometry algorithms. Unfortunately, global-shutter designs have to pay a relatively high tradeoff cost for that capability.

Because the imager chip has a finite number of analog-to-digital converters (sometimes 1, sometimes 8 on fancier chips, etc.), and the analog pixel charges have to be shuttled one-at-a-time row-wise and then column-wise through the on-chip analog-to-digital converter(s), analog charge storage and charge-gating (i.e. the equivalent of a capacitor and a transistor of some sort) within the pixel is required if "true" global-shutter behavior is required. This reduces the fraction of the pixel that can be allocated for its primary function: sensing light! This results in reduced low-light sensitivity, higher noise, etc. It can be compensated for by increasing the pixel sizes, but then you end up with either lower spatial resolution or a larger chip area (and therefore cost). Because the overwhelming majority of the world's image sensor applications don't care about global-shutter, it's tough for vendors to see a market for global-shutter designs, since going to global-shutter makes the design perform worse in basically every other metric! The applications that really truly require global shutter tend to be less cost sensitive (i.e. higher-end machine vision) so at the end of the day you end up with either mass-market rolling-shutter chips or niche-market expensive global-shutter chips :man_shrugging:

Anyway, that was a lot of words. Short version: we're hoping that the swappable imager modules on OVC4 will allow exploration of this tradeoff space to best match the imager capabilities to each application's requirements. Cheers!

poudyalbot, 2020-07-18:
Thank you for quick reply.

Closed 2022-08-15.

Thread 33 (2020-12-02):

Information request on OVC3 device configuration.

Han-sok, 2020-12-02:
Hello,

I am currently working on your OVC3, more specifically "OPEN VISION COMPUTER REV 3A (MARCH 2019)"
I have a board with me.

My plan is to develop an FPGA system to perform my own application, but it looks like OVC3 does not have JTAG connectivity.
When I tried to connect USB-C port to the PC, Vivado's hardware manager did not detect any device.
**What are the available options to configure FPGA if I want to load my logic design to OVC3?**

I read Trenz's specsheet and manual and found this.
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
According to this, only boot from SD/flash(eMMC) is possible. (Assuming you are using default firmware in CPLD.)
If that's true, **what are the available debug options to probe signals in the FPGA?**

I am not asking for specific tutorial for any of these question.
(Though if you can briefly explain me how to do that it would be appreciated.)

**Also I want to know how this switch is mapped to the boot mode selection functionality.**
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
Clearly, JTAGEN is for selecting a USB connection to either FPGA/CLPD.
MODE is for SD/eMMC selection.
NOSEQ looks like doing the same functionality that is specified in the above screenshot.
(Selecting JTAG mode when the firmware in the last column is installed I guess?)
But then, what is the USER pin used for?

So my question is...
1. Information on available FPGA configuration options.
2. Information on available debug options.
3. Information on mode switch.

Thank you!

Best regards,
Han-sok

luca-della-vedova, 2020-12-02:
Hi Han-sok!

> My plan is to develop an FPGA system to perform my own application, but it looks like OVC3 does not have JTAG connectivity.
> When I tried to connect USB-C port to the PC, Vivado's hardware manager did not detect any device.
> What are the available options to configure FPGA if I want to load my logic design to OVC3?

The OVC3 does have JTAG connectivity, it is brought out to the J6 pin header so you would need a programmer (such as the [Xilinx Platform Cable](https://www.xilinx.com/products/boards-and-kits/hw-usb-ii-g.html) and connect the wires to the pin header.
In alternative if you are running Linux onboard you can use the sysfs interface to program the FPGA with your bitfile (it is usually what I do), or just embed the bitfile in your BOOT.bin bootable image.

> If that's true, what are the available debug options to probe signals in the FPGA?

Currently the only way to probe signals is by having the Xilinx programmer I mentioned above connected to the JTAG pins.

> But then, what is the USER pin used for?

The USER pin is used for GPIO and is exported to Linux. One of the main uses is for flashing the OVC, there is a script that runs on boot in the Ubuntu image that reads the USER pin and depending on its position will reflash the OVC (download the latest binaries and overwrite the rootfs / bootable images stored in the eMMC / QSPI flash). The pin has this functionality only when booting from SD card though, so if you are booting from eMMC you can feel free to use it for your own applications.

Cheers!
/Luca

Han-sok, 2020-12-02:
Thank you so much for a quick response, Luca.

I see. But I have one more thing I want to ask.
I check the board but J6 does not have a pin connector attached. So, do I need to solder the pin connecter on my own? Or is it a different pin by any chance? I attached a photo for your reference.
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

Best,
Han-sok

Han-sok, 2020-12-02:
Oh! I found it.

There's another small J6 tag on the other side of the device.
So this is the one you were talking about, right?
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

Best,
Han-sok

fcladera, 2020-12-02:
yes!

Han-sok, 2020-12-03:
Got it. Thank you for the clarification. I will populate the pins with socket first and get back to you if I have any problem.

fcladera, 2021-08-28:
@Han-sok can we close this?

Han-sok, 2021-08-30:
Sure. Please do so.

Thank you

Best regards,
Han-sok

On Sun, Aug 29, 2021 at 5:51 AM Fernando Cladera ***@***.***>
wrote:

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

Closed 2021-08-30.

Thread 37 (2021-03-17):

Throttled image rate using ROS

augustebleu, 2021-03-17:
Hello,

I recently cloned the OVC3b module with great success. However, when I connect the module to my laptop with USB-C, the image rate is lower than what I get on the OVC (15-20Hz instead of 33Hz). Have you ever experienced such a result? I would like to avoid compressing the image to avoid additional latency.

I really appreciate the effort put into this project.
Thank you !

luca-della-vedova, 2021-03-17:
Hi!

First of all how many cameras are you trying to subscribe to in parallel? You might reach bandwidth issues if you are running a lot of those and your USB is not fast enough.
We had some issues of laptops USB controllers not being fast enough, can you run:
`iperf3 -s` on your laptop and
`iperf3 -c <your_laptop_ip>` on the OVC
and report the results? Ideally you should get something in the 2.7-3.2Gbps range but I have seen laptops go as low as 1.6Gbps. This is the maximum bandwidth that you have over USB and you can use it together with the image size and frame rate to see if you are being bandwidth limited or not.

augustebleu, 2021-03-17:
Luca, thank you so much for your help.

> First of all how many cameras are you trying to subscribe to in parallel? You might reach bandwidth issues if you are running a lot of those and your USB is not fast enough.

The three cameras and the IMU work simultaneously. But on the laptop side, I only tried to subscribe to one camera.

Here is the result of the command line on laptop side:
```
-----------------------------------------------------------
Server listening on 5201
-----------------------------------------------------------
Accepted connection from 10.0.1.1, port 43302
[  5] local 10.0.1.2 port 5201 connected to 10.0.1.1 port 43304
[ ID] Interval           Transfer     Bandwidth
[  5]   0.00-1.00   sec  43.3 MBytes   364 Mbits/sec          
[  5]   1.00-2.00   sec  45.4 MBytes   381 Mbits/sec          
[  5]   2.00-3.00   sec  45.5 MBytes   382 Mbits/sec          
[  5]   3.00-4.00   sec  45.1 MBytes   378 Mbits/sec          
[  5]   4.00-5.00   sec  45.5 MBytes   382 Mbits/sec          
[  5]   5.00-6.00   sec  45.5 MBytes   382 Mbits/sec          
[  5]   6.00-7.00   sec  45.1 MBytes   378 Mbits/sec          
[  5]   7.00-8.00   sec  45.5 MBytes   382 Mbits/sec          
[  5]   8.00-9.00   sec  45.5 MBytes   382 Mbits/sec          
[  5]   9.00-10.00  sec  45.0 MBytes   378 Mbits/sec          
[  5]  10.00-10.04  sec  2.03 MBytes   380 Mbits/sec          
- - - - - - - - - - - - - - - - - - - - - - - - -
[ ID] Interval           Transfer     Bandwidth
[  5]   0.00-10.04  sec  0.00 Bytes  0.00 bits/sec                  sender
[  5]   0.00-10.04  sec   453 MBytes   379 Mbits/sec                  receiver
```

You just pointed out the right problem I guess. The bandwidth result is much lower than what you mentioned.

I'm currently using a USB-C to USB-C cable, I'll try on a different hardware with various cables. I will keep you informed of the result.

luca-della-vedova, 2021-03-17:
Hi!

You are running at USB2 speed, I think the issue is that you might be using
one of those cables that is designed for charging devices and doesn't
actually have all the USB3 signal wires (this is usually done to cut
costs). Try to find a cable that is certified for USB3 and you should be
good to go!

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

augustebleu, 2021-03-18:
By trying with a brand new USB3.0 cable, on another computer, the problem is now solved!

Closed 2021-03-18.

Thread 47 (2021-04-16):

Additional Information About the OVC4

augustebleu, 2021-04-16:
First of all, I would like to thank the whole team for the great work done on this project.
I intend to reproduce the OVC4, I would like to get some feedback on the project.

- Do you consider this version mature enough to be used in the specified conditions (six picam synchronized with an IMU)?
- Have you noticed any particular issues during development or things you would like to see addressed in future releases (I am very curious to understand what drives your design preferences in each version)?
- It seems you are using the Argus sdk from Nvidia to fetch the image frames, did you observe any latency? (I had this kind of trouble with a Jetson TX2 & Argus in the past)
- How difficult would it be to modify the project to integrate a camera such as the OV9281 1MP from Arducam?

codebot, 2021-04-16:
Greetings

Our development effort is currently focused on OVC5, which is based on Zynq UltraScale+. We decided to move away from Argus/NVIDIA precisely due to latency issues as you mentioned, for which we could not seem to find a solution or workaround. Our current Zynq-based design overlaps image reception with image transmission to the USB3 host, resulting in sub-frame latency. We built the prototype OVC5 using frankenstein devkits, but a custom board is currently in fabrication, as shown here: https://github.com/osrf/ovc/tree/master/ovc5

As for integrating new camera types, we have deliberately used the 2-lane FFC MIPI pinout made popular by Raspberry Pi (and friends) to make that as easy as possible. It looks like that Arducam module also uses the same pinout, so it should "just work", at least electrically. Software-wise, you'll need to chase down the required register settings. This can range from "easy" to "very difficult" depending on imager documentation access and/or available open-source code to follow along.

Cheers

luca-della-vedova, 2021-04-16:
Hi!

To add to a few points:

>     * Do you consider this version mature enough to be used in the specified conditions (six picam synchronized with an IMU)?

You should be able to get six picams (I only tried 2 personally) but they won't be synchronized. Picam v2 (or even the HQ one if I remember correctly) don't have a dedicated pin for hardware synchronization.

>
>     * Have you noticed any particular issues during development or things you would like to see addressed in future releases (I am very curious to understand what drives your design preferences in each version)?

The designs have usually been driven by requirements of people we worked with, for example the first prototypes were for drone applications, hence global shutter imagers and full integration (a single PCB with imagers / computational device) were desirable to reduce weight and size.
For OVC4 / OVC5 we are trying to make a prototyping platforms that can be used with as many easily acquirable sensors as possible. As @codebot mentioned the Picam pinout is as close as a standard in MIPI FFC connectors we will get, with both Raspberry PIs and Jetson platforms using it a lot of vendors provide sensors with that pinout.
The code is also structured to allow flexibility, with a `SensorManager` object that probes all the I2C buses at runtime and detects which imager has been connected, then proceeds to configure them through imager specific instructions. Previous OVCs were all "locked" into a single imager.

>     * It seems you are using the Argus sdk from Nvidia to fetch the image frames, did you observe any latency? (I had this kind of trouble with a Jetson TX2 & Argus in the past)

Yes again as mentioned this was the main reason we moved away from the platform, depending on the configuration there was a 2-3 frames latency (compared to less than one frame in OVC5), which is too high for many robotics applications.

>     * How difficult would it be to modify the project to integrate a camera such as the OV9281 1MP from Arducam?

As @codebot mentioned, if they are electrically compatible, the main difficulty is in finding the configuration since imagers are usually a very protected market.
As shown in the [header's copyright notice](https://github.com/osrf/ovc/blob/master/ovc4/software/ovc4_driver/include/ovc4_driver/cameras/picam_v2.hpp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), The picam driver was developed starting from the NVIDIA Linux kernel fork, where they have a header file with a list of sensor modes (resolution / FPS) and the corresponding sets of I2C instructions.
I had a quick look at their kernel fork and I could find a similar file for OV9281, which makes me think the integration should be reasonably simple.

augustebleu, 2021-04-16:
@codebot @luca-della-vedova
Your answers are pretty clear and well explained, thank you!

I have a better understanding of the intent of recent developments. I was able to clone the OVC3 and it is a good example of a very versatile device.

I have another question for you. In my particular case I would like to take advantage of a platform with a GPU for a robotic application. My goals are also to use a global shutter camera and to reduce the latency as much as possible. That's why I will look towards the OVC2.

Are there similar challenges observed while designing the OVC2 (delay, design flaws, etc.)?

Sorry if we are going off topic, but I think that this information could be useful to others as well.

codebot, 2021-04-16:
The reason we moved to offboard camera modules in OVC4, OVC5 was that it's a huge benefit to be able to mix-and-match imager chips later and to experiment with and modify the baseline by changing how the sensor boards are mechanically mounted.

OVC1, OVC2, OVC3 all use image sensors that are soldered to the board. This is convenient (no cables), but if you ever want to change either the image sensor or the baseline... you can't.

I'd strongly suggest going with OVC5 and streaming data to an offboard GPU via USB-C. Embedded GPU's are neat, but nothing beats a "real" GPU on a full-size PCIe card, if you have the space. Note that embedded GPU's like NVIDIA TX2 generally use a custom socket pinout, so you can't really upgrade it, unless the GPU module vendor happens to produce an upgraded module that keeps the connector identical. That has happened "sometimes" in the past, but it's totally out of your control. In contrast, a USB-C connection to a host is industry-standard, and you're guaranteed to be able to get a faster GPU next year.

augustebleu, 2021-04-19:
Your explanations are quite useful. I am closing the subject since the question has been answered.  Thank you.

Closed 2021-04-19.

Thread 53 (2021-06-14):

OVC3 jumbo frames may cause unstabilities

fcladera, 2021-06-14:
Documenting the issue so I don't forget to look into it.

OVC3 is currently configured to use jumbo frames in its ethernet interface:
```
ubuntu@arm:~$ cat /etc/dhcp/dhcpd.conf | grep -n 13500
45:  option interface-mtu 13500;
```

This can cause some instabilities: the interface stops sending data in an unpredictable way. Commenting this line solves the issue.

luca-della-vedova, 2021-06-15:
Interesting, never noticed it before. I remember setting that number as high as possible since the lower it was the lower the performance of the USB ethernet was.
I'd suggest running a benchmark with `iperf3` to see if it significantly affects performance and whether the tradeoff is acceptable for your application.

fcladera, 2021-06-15:
Hi @luca-della-vedova. Yes, I also noticed that this behavior depends significantly on the computer the OVC is connected to. I have observed that some computers are able to communicate and transmit simple messages, such as ssh commands (less than MTU?). But things get unstable when we start transmitting images and the connection just hangs.

As you suggested, it may be interesting to get some benchmarks on this issue.

luca-della-vedova, 2021-07-06:
Hi @fcladera

I was probing around the documentation of the Xilinx tools and found out that in the 2021.1 version of the tools released just a few weeks ago, I saw that in the [changelog](https://xilinx-wiki.atlassian.net/wiki/spaces/A/pages/1850179585/2021.1+Release+Notes+for+Open+Source+Components) (under Linux kernel bugfixes) there is an entry:
`Fixed USB3.0 RNDIS Gadget issue when MTU value is set to 15300.`

I wonder if it could help, upgrading the tools to 2021.1 would bring that fix in but if that is too daunting it should be possible to just get the relevant patch and add it to the kernel compilation recipe in the petalinux project

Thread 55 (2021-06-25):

OVC5b fixes

codebot, 2021-06-25:
- [ ] mounting holes for the XU5 are 180 degrees off
- [ ] DIP switch footprint is slightly too narrow, and the DIP switch interferes with the XU5 module if it's mounted currently (just needs to move ~2mm further away, and it will be fine)

codebot, 2021-06-25:
we'll track this elsewhere

Closed 2021-06-25.

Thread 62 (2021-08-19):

Implement Dynamic Message Passing with jsoncpp

gbalke, 2021-08-19:
Brought about by this suggestion: https://github.com/osrf/ovc/pull/61#issuecomment-898137828

I'm debating working on using JSON in #61 or another PR. Here's some sample code that I think I'll be basing the implementation off of:
```cpp
#include <jsoncpp/json/json.h>
#include <iostream>
#include <sstream>

int main() {
  Json::Value root;

  root["name"] = "my_name";
  Json::StreamWriterBuilder builder;
  builder["indentation"] = "";
  std::string output = Json::writeString(builder, root);

  std::cout << output << std::endl;
  std::stringstream ss(output);

  Json::CharReaderBuilder rbuilder;
  Json::Value root_read;
  std::string errs;
  Json::parseFromStream(rbuilder, ss, &root_read, &errs);

  std::cout << errs << std::endl;
  std::cout << root_read["name"] << std::endl;
}
```
Still not sure if I should change the serialization (struct vs an actual library). I could just replace the whole host -> client message with a length field followed by the JSON string. Something about it doesn't feel right but it would work... :shrug:

@luca-della-vedova thougths?

luca-della-vedova, 2021-08-19:
Length + JSON string sounds simple enough that it would work, the alternative would be sending JSON straight away I guess? But not sure if the library has convenient functions for "read from this socket and return when a whole JSON message has been received", if it doesn't it might be too much work.

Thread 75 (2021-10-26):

Color balance in RGB sensor (ovc3b)

fcladera, 2021-10-26:
We are facing an issue with the RGB sensor. In indoor environments, the colors in the images are ok, as shown by the following picture.
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
However, when we take the sensor outside, pictures look like these:
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
Yellow and green boxes are indistinguishable. This issue seems to be more than just white balancing the image.

Another example during data collection:
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

In the documentation, there are specific channel gains for each Bayer color channel. I tried modifying this, but I was not able to solve the problem.

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

Any hints are appreciated! Thanks!

fcladera, 2021-11-22:
Adding another IR filter to the sensor (in addition to the embedded one) helped significantly. The resulting image is a bit underexposed, but we can fix that afterwards. I think we can close this.

https://youtu.be/qeTmM421gXc
Left: without filter.
Right: with filter.

For reference, I used a 650nm 10mm filter glued to the lens.
https://www.amazon.com/Gzikai-10mmx1mm-Optical-Blocking-Glasses/dp/B07N2Z9NHL

codebot, 2021-11-23:
Wow, that is a very surprising result. Thanks so much for sharing this. I guess the original filter in the back of the lens just was not super effective? Naively, I thought "any" IR-cut filter in a lens was enough, but it's good to know that isn't necessarily true! Thanks again for sharing.

fcladera, 2021-11-23:
Yes. I am putting an order to test a few lenses with filters included, just to be on the safe side.

Closed 2021-11-22.

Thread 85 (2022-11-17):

A question about IMU in OVC5

aliamini87, 2022-11-17:
Hi
What would be the recommended method to attach an IMU to this board? Before this version, your designs usually includes some IMU integration. But in OVC5 it's unclear.
Another question:
Is the OVC5 in early stages or near to finish?
Thanks.

luca-della-vedova, 2022-11-18:
Hello!

OVC5 was more designed for camera usage and indeed lacks the usual "integrated IMU" feature that OVC1-3 had. We have a few I2C connectors that can be used to integrate external peripherals, the embedded linux comes preconfigured with I2C drivers for them.
The connectors follow the QWIIC pinout so you can buy any peripherals that follow it and attach it (i.e. [this](https://www.sparkfun.com/products/15335)).
OVC5 is pretty much completed and was fabricated and tested.

aliamini87, 2022-11-18:
So in OVC5 i2c port is attached to embedded linux part and not directly to FPGA.
So if I need a good synchronization between imu and cameras your recommendation will be OVC3?
It was wonderful if OVC5 has some serial interface for some sensors directly to FPGA.

luca-della-vedova, 2022-11-21:
Yea I think for out of the box hardware synchronization I'd recommend OVC3. The extra I2C ports are actually implemented in FPGA and the embedded Linux has drivers to use them but they could theoretically be used straight in FPGA, still with no hardware trigger pin the only synchronization could be a software one.
Theoretically it should be quite straightforward to change the layout of OVC5 and just add a cheap IMU the same way OVC3 has one, even reusing the exact same if you want to reuse different parts of the code, I'd say the main deciding factor is whether you want something that just works out of the box in a predefined configuration for stereo global shutter (OVC3) or something fully customizable that is a bit more bulky but can have arbitrary sets of imagers (OVC5).

aliamini87, 2022-11-21:
Thanks a lot for the detailed answer.
Actually I prefer the customizability of the OVC5 but synchronization between camera and imu is another key factor for me. In addition, I want to add some third party IMUs to this system and synchronize them with cameras. In this scenario, which platform do you suggest? If OVC5 is your answer, what level of experience is necessary to modify the OVC5 for this purpose?
Thanks a lot in advance?

luca-della-vedova, 2022-11-21:
If you want OVC5 you can go two ways:

* Customize the carrier board to have an integrated IMU, this requires a bit of hardware design but shouldn't be too hard, but it still doesn't address the core issue of external synchronized IMUs.
* Create your own module and customize the FPGA design would be my recommended approach. You could create a small PCB that has the same FFC connector as the 6 camera connectors (based on the Picam V2 pinout) and have your own custom pinout for IMUs or extension boards, I would recommend keeping 3.3V power and ground on the same pins but everything else can be pretty much your own, then you need to work at the BSP level to change the pins from "camera pins" to "I2C, SPI, UART, or whatever your IMU needs". Then you will lose one camera but you have to do much less hardware design.

I'd say you would need basic experience in PCB design to design a small module that can be connected to the OVC5 that mounts your IMU (you can take the PI cam v2 schematic as an inspiration) and a bit more advanced experience in Zynq systems and the Xilinx workflow to customize the BSP, adding the needed interface (i.e. SPI / UART for the IMUs that we integrated in OVC3) and writing the driver.

aliamini87, 2022-11-21:
Thanks a lot. I'll try to examine this.

Closed 2022-11-21.

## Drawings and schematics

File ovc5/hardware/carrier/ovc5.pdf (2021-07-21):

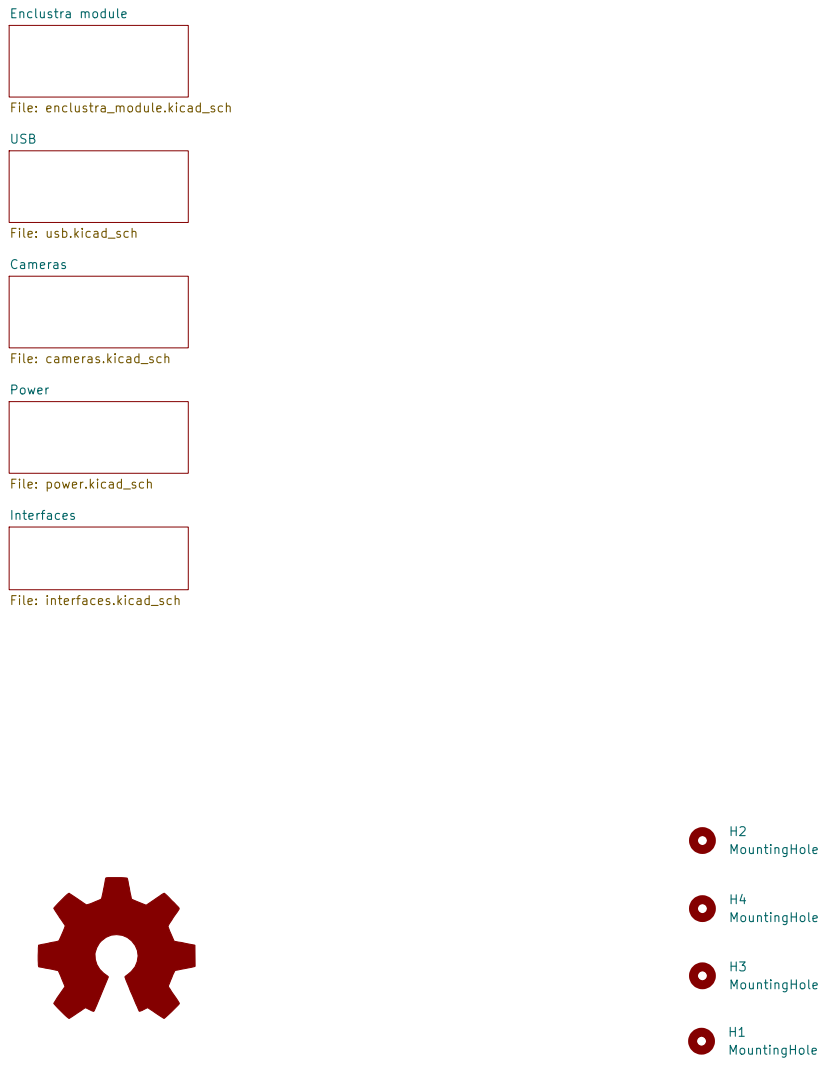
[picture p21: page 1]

Interfaces File: interfaces.kicad_sch Power File: power.kicad_sch USB

Cameras File: cameras.kicad_sch Enclustra module File: enclustra_module.kicad_sch

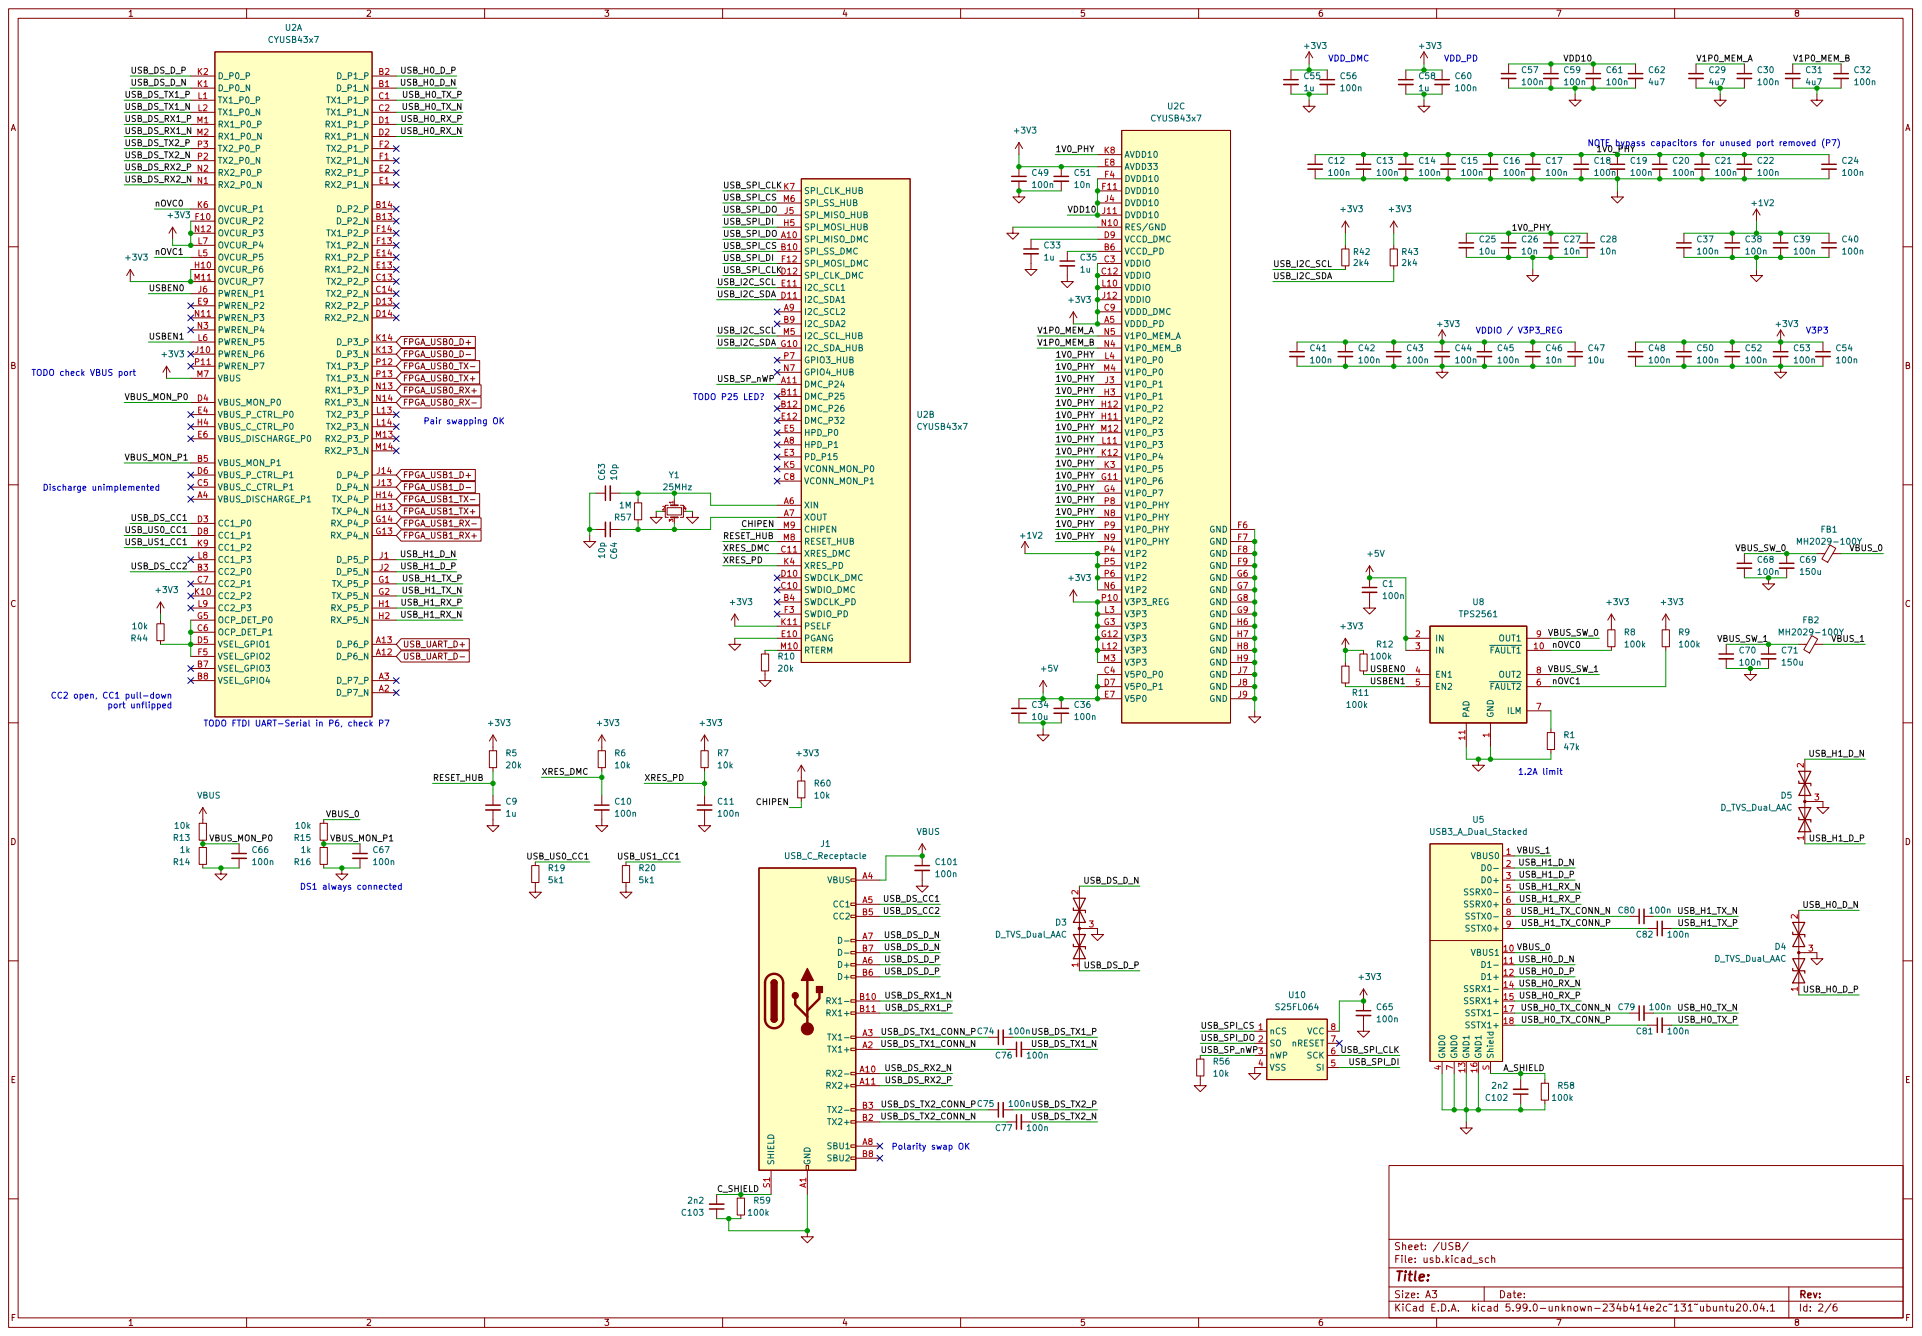
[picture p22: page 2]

NOTE bypass capacitors for unused port removed (P7)
1V0_PHY

File: usb.kicad_sch Sheet: /USB/

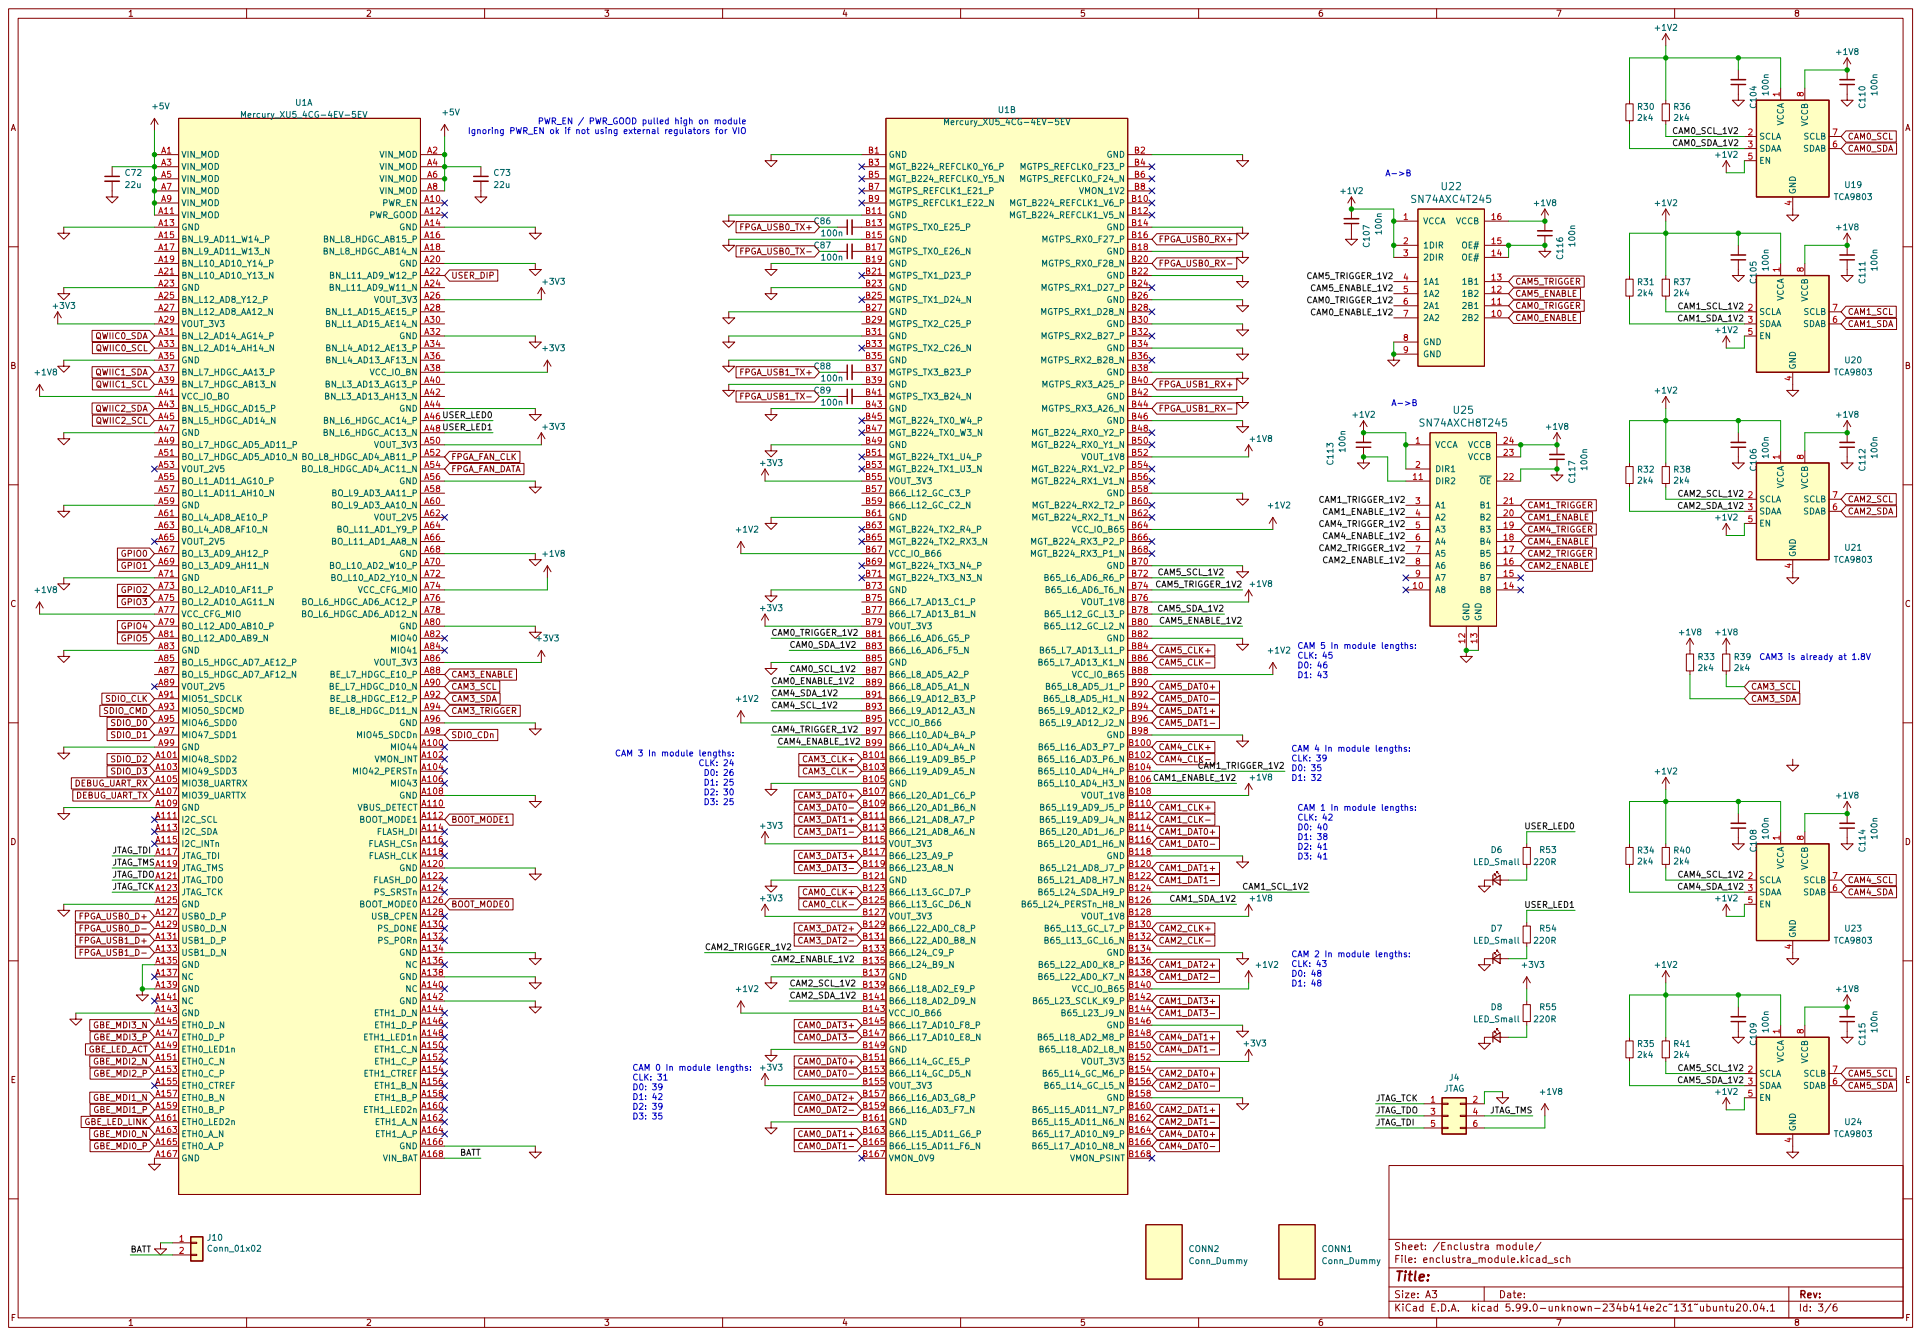
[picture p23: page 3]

Ignoring PWR_EN ok if not using external regulators for VIO

PWR_EN / PWR_GOOD pulled high on module

CAM 4 In module lengths: CLK: 39 D0: 35 D1: 32

CAM 2 In module lengths: CLK: 43 D0: 48 D1: 48

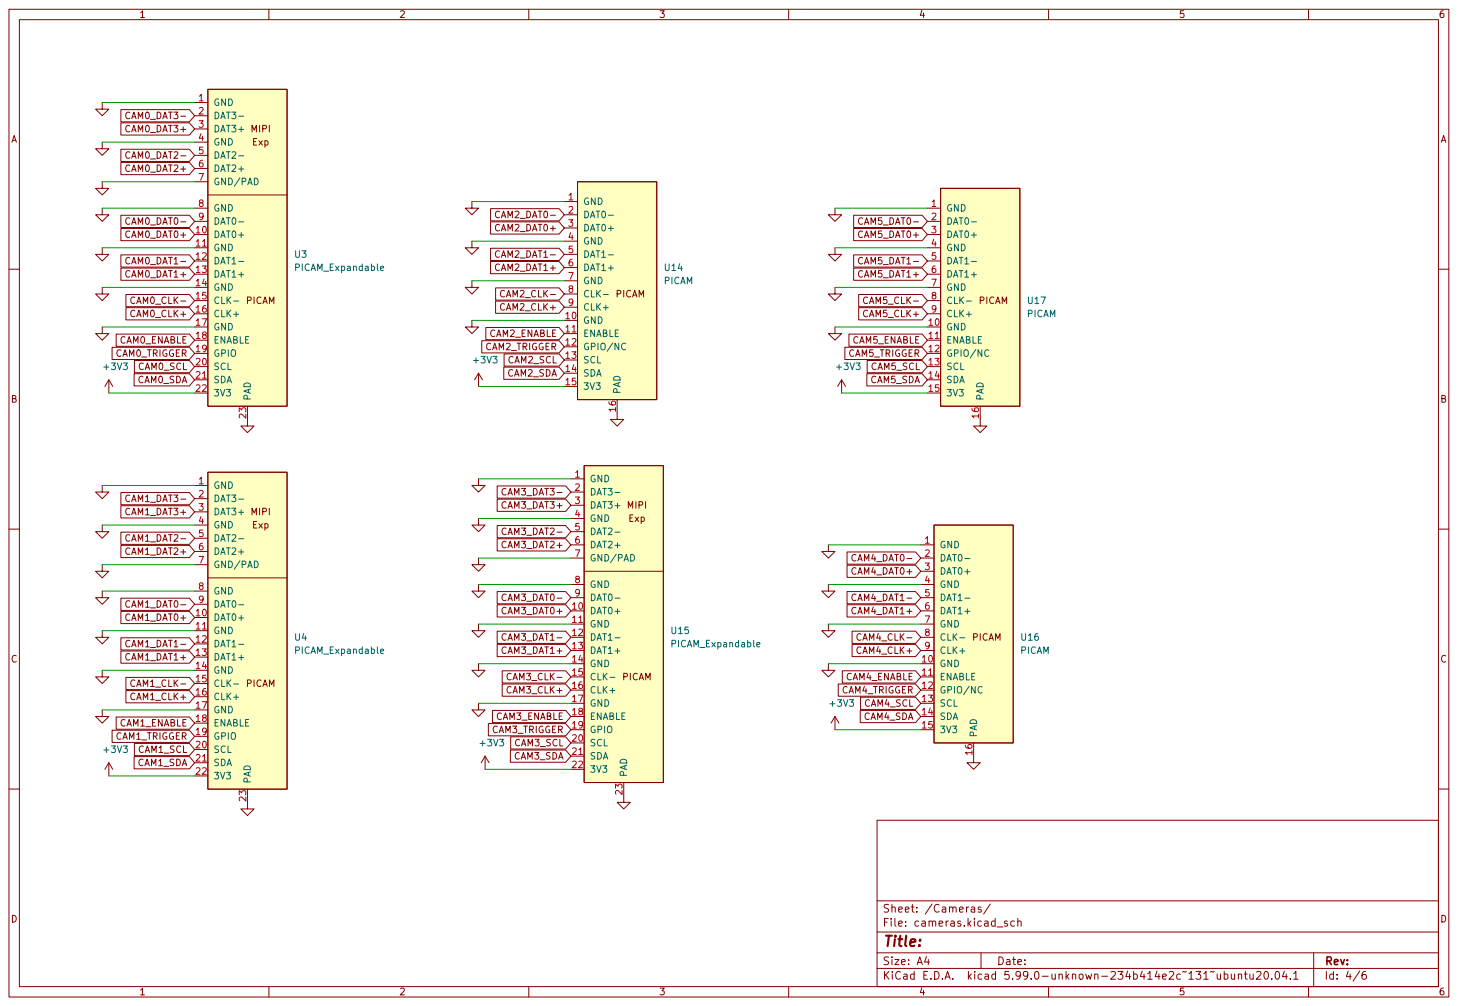
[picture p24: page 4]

File: cameras.kicad_sch Sheet: /Cameras/

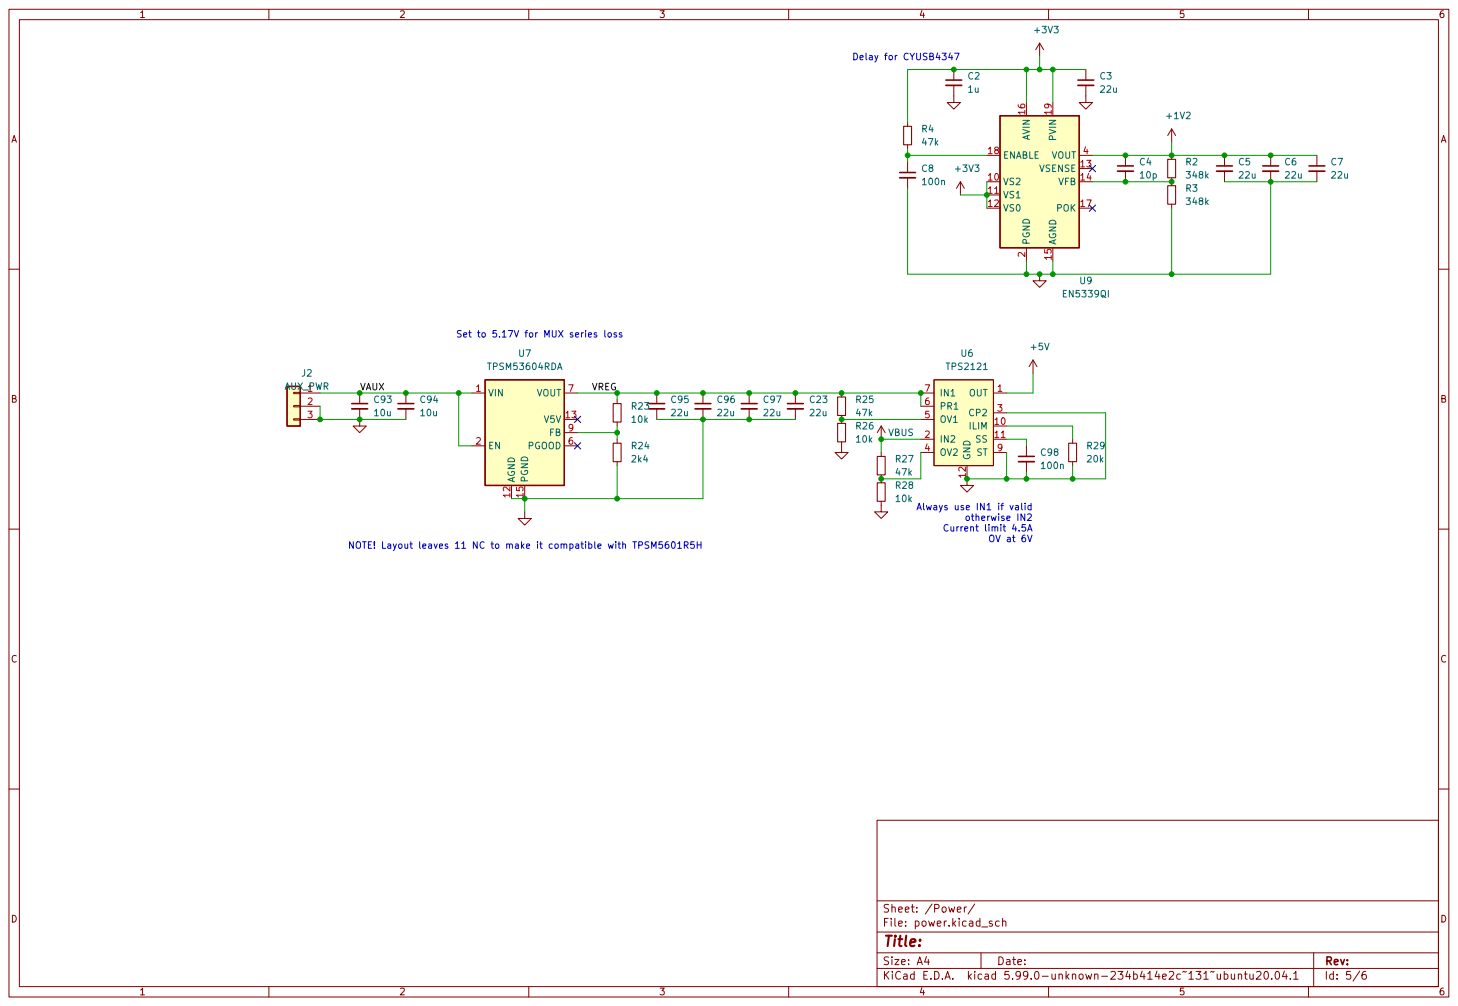
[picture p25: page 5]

Delay for CYUSB4347 Set to 5.17V for MUX series loss NOTE! Layout leaves 11 NC to make it compatible with TPSM5601R5H

Always use IN1 if valid
otherwise IN2 Current limit 4.5A OV at 6V

File: power.kicad_sch Sheet: /Power/
Id: 5/6 Title:

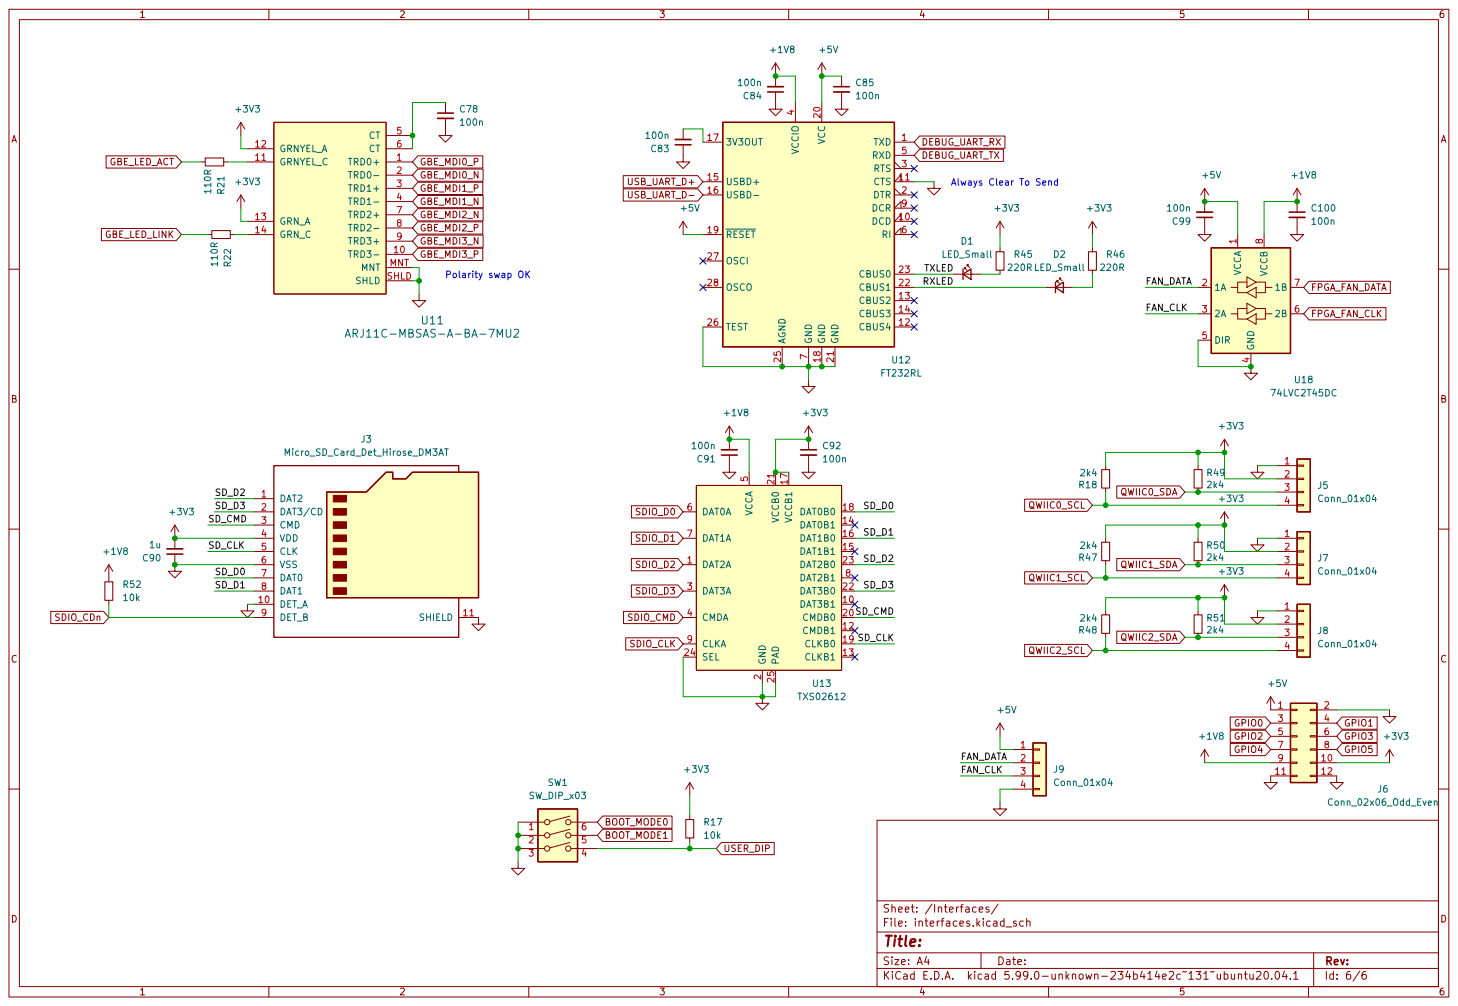
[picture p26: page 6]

2 CMDB0 20 VCCB0 21 DAT3B0 22 DAT2B0 23 SEL 24 PAD 25 DAT3A 3 CMDA 4 VCCA

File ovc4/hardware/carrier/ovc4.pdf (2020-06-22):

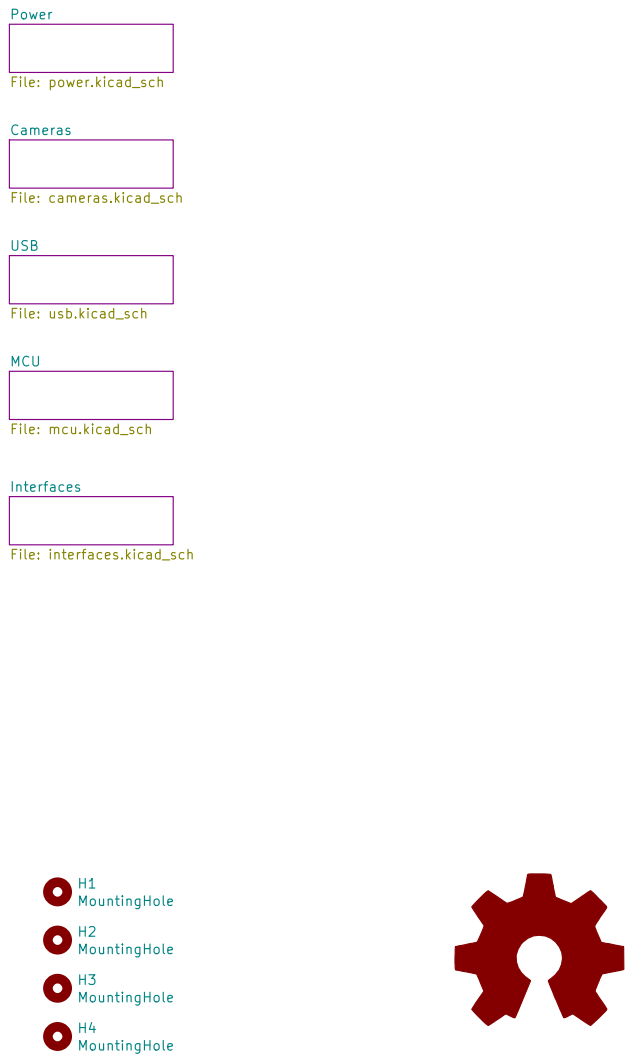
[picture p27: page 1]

File: mcu.kicad_sch Power File: power.kicad_sch USB

Interfaces File: interfaces.kicad_sch MCU

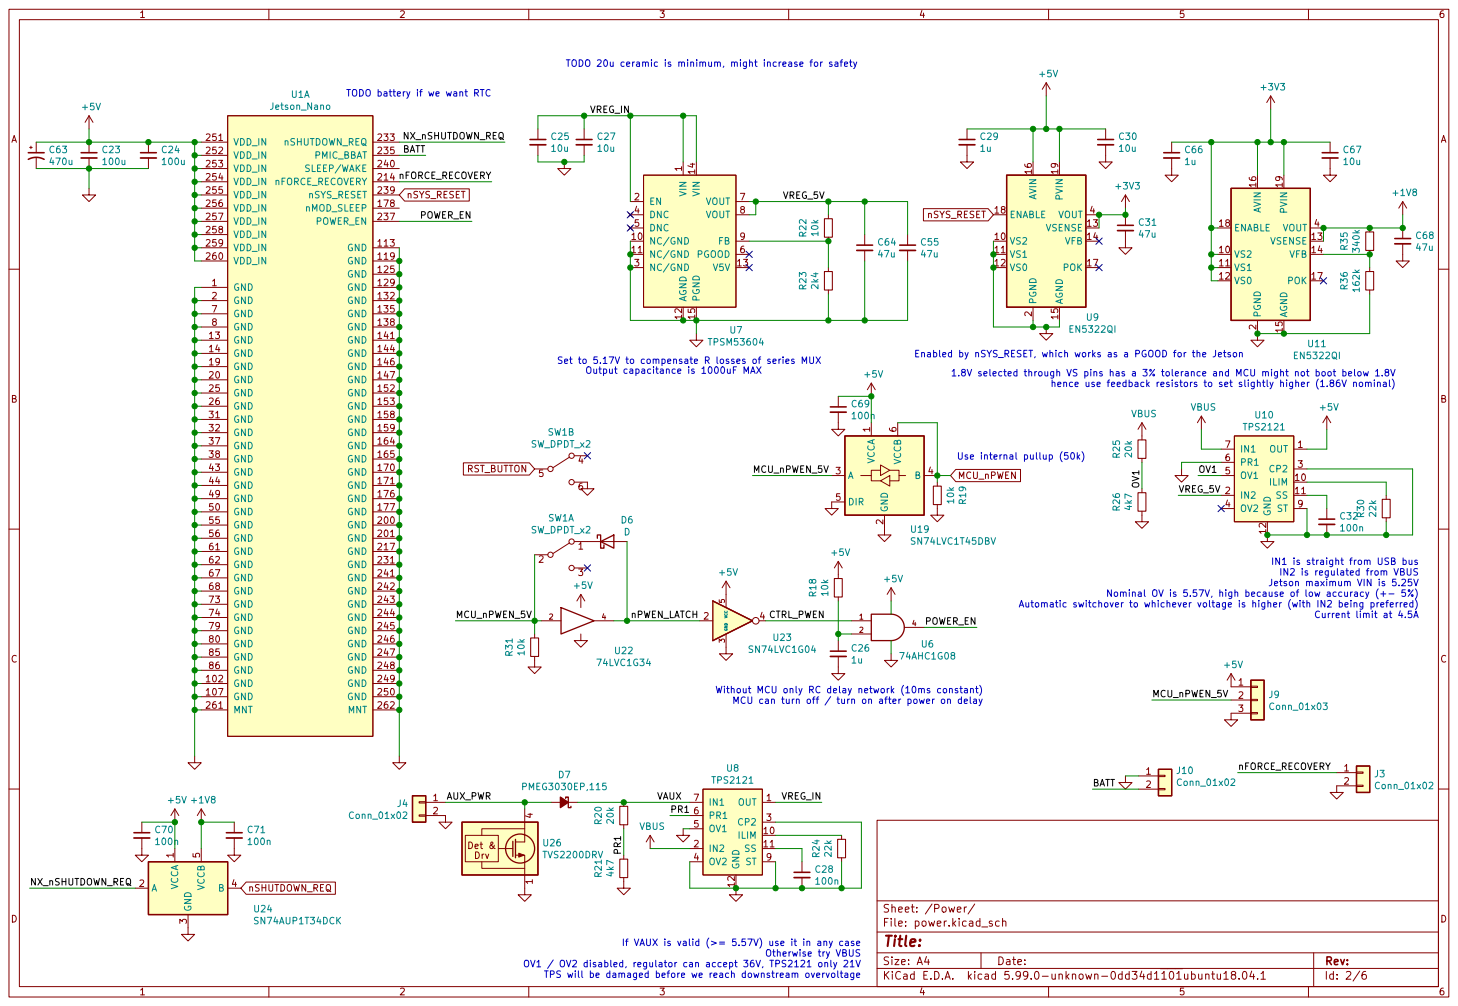
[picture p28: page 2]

TODO 20u ceramic is minimum, might increase for safety

TODO battery if we want RTC

1 NC/GND 10 NC/GND 11 AGND 12 V5V 13 VIN 14 PGND 15 EN 2 NC/GND 3 DNC 4 DNC 5 PGOOD 6 VOUT 7 VOUT 8 FB 9 U7 TPSM53604 R35 340k R36 162k OUT 1

Set to 5.17V to compensate R losses of series MUX
Output capacitance is 1000uF MAX

Enabled by nSYS_RESET, which works as a PGOOD for the Jetson

1.8V selected through VS pins has a 3% tolerance and MCU might not boot below 1.8V

hence use feedback resistors to set slightly higher (1.86V nominal)

IN1 is straight from USB bus
IN2 is regulated from VBUS

Jetson maximum VIN is 5.25V Nominal OV is 5.57V, high because of low accuracy (+- 5%)

Automatic switchover to whichever voltage is higher (with IN2 being preferred) Current limit at 4.5A Without MCU only RC delay network (10ms constant)

MCU can turn off / turn on after power on delay

If VAUX is valid (>= 5.57V) use it in any case

OV1 / OV2 disabled, regulator can accept 36V, TPS2121 only 21V
TPS will be damaged before we reach downstream overvoltage

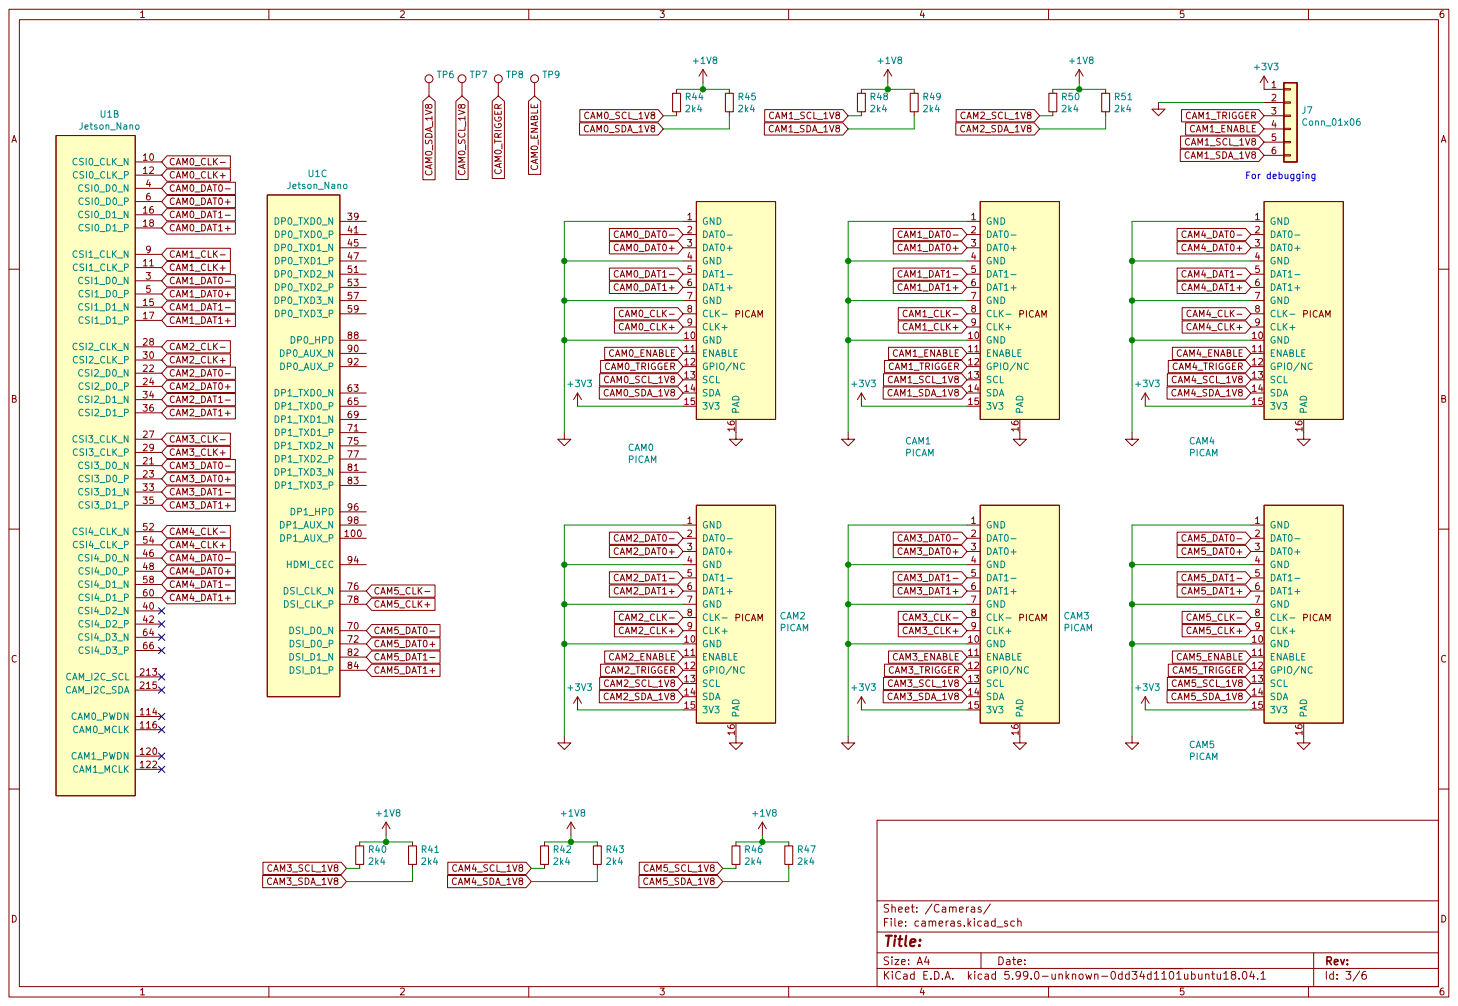
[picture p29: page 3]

File: cameras.kicad_sch Sheet: /Cameras/ +1V8

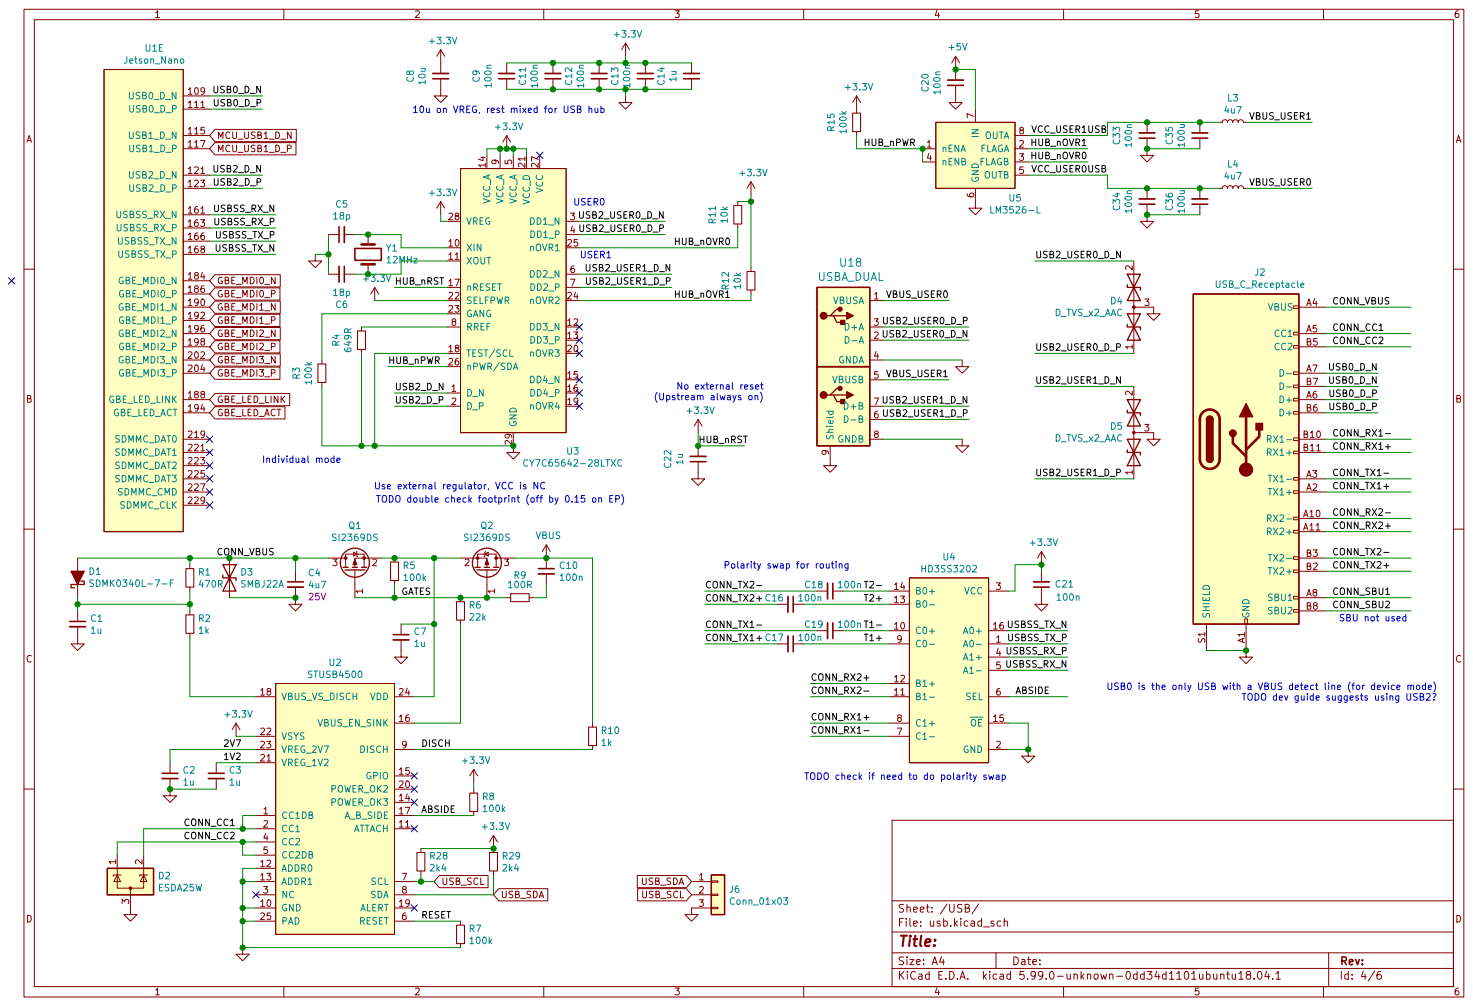
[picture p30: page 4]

10u on VREG, rest mixed for USB hub TODO double check footprint (off by 0.15 on EP)

Use external regulator, VCC is NC

Polarity swap for routing

USB0 is the only USB with a VBUS detect line (for device mode)

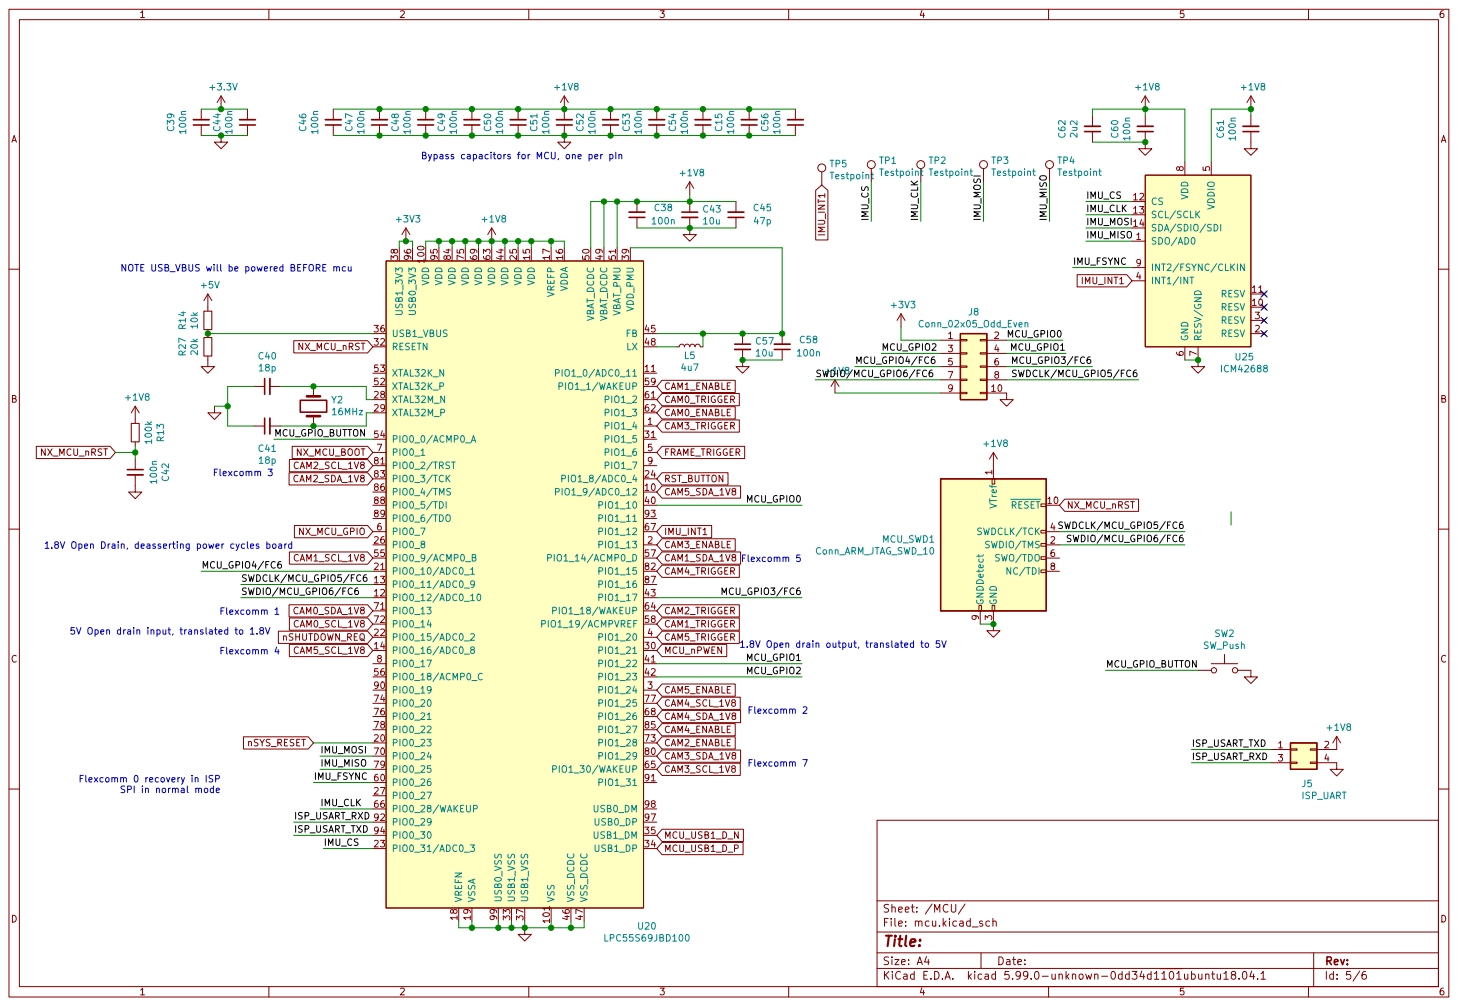
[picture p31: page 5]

3 SWDCLK/TCK 4 SWO/TDO 6 NC/TDI 8 GNDDetect 9 MCU_SWD1 Conn_ARM_JTAG_SWD_10 +1V8 SW2 SW_Push +3V3 C62 C60 100n 2u2 TP4 Testpoint TP3 Testpoint SDO/AD0 1 RESV 10 RESV 11 CS 12 SCL/SCLK 13 SDA/SDIO/SDI 14 RESV 2 RESV 3

1.8V Open Drain, deasserting power cycles board

5V Open drain input, translated to 1.8V

1.8V Open drain output, translated to 5V

Flexcomm 0 recovery in ISP

File: mcu.kicad_sch Sheet: /MCU/
Id: 5/6 Title:

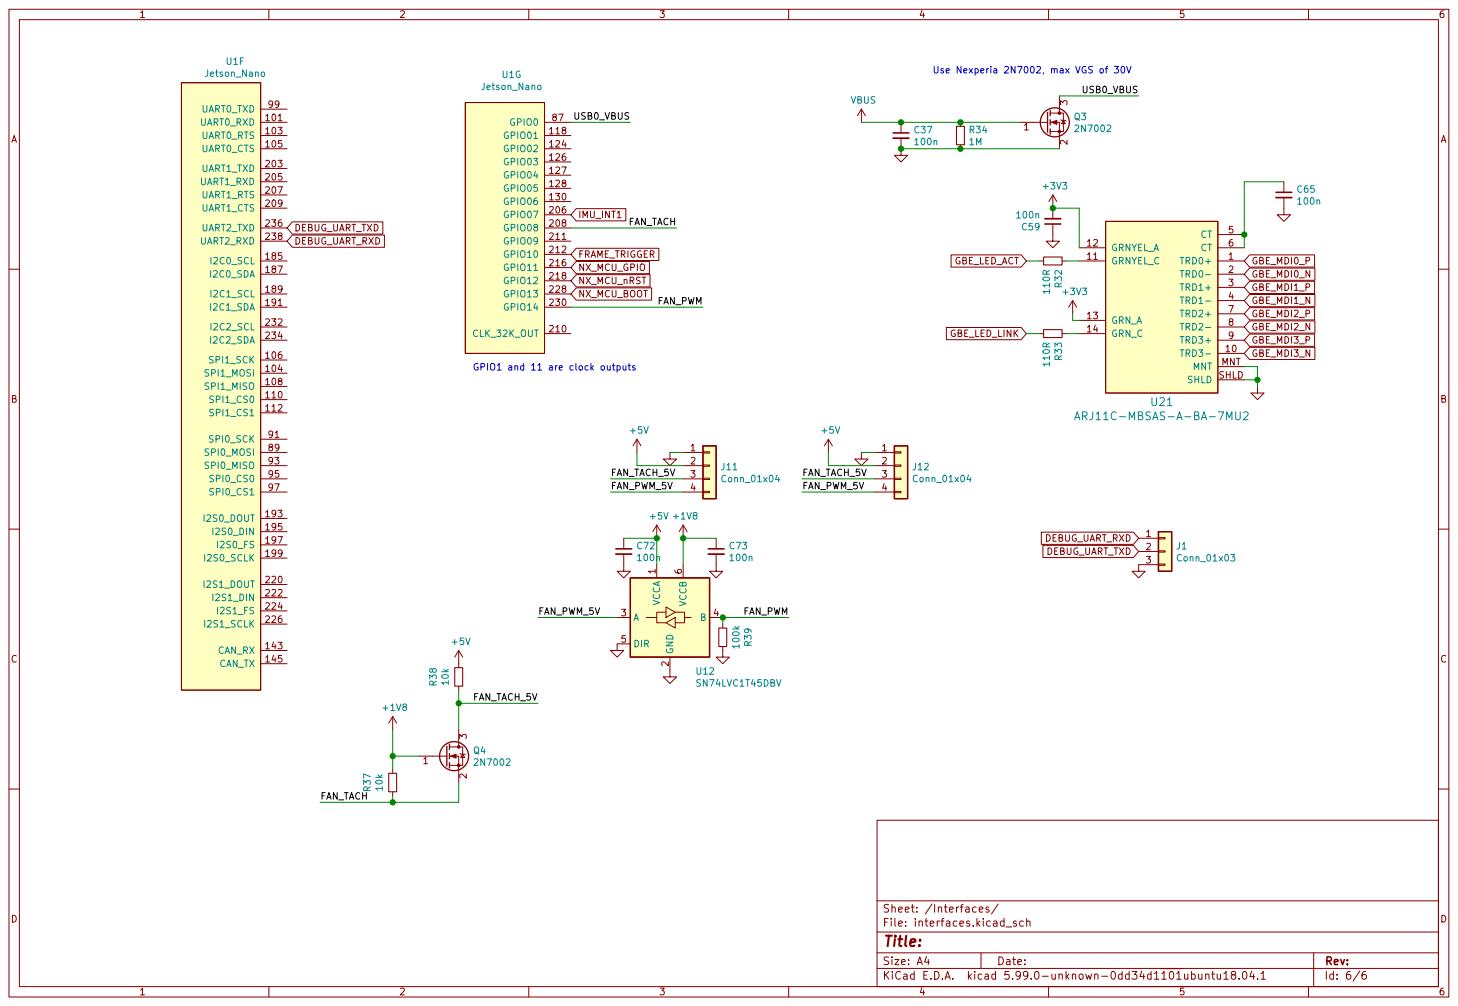
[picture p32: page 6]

Use Nexperia 2N7002, max VGS of 30V

GPIO1 and 11 are clock outputs

File: interfaces.kicad_sch Sheet: /Interfaces/ C72

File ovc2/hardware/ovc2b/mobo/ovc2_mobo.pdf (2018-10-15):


LED THIS DEVICE IS INTENDED ONLY
FOR R&D PROTOTYPING IN LAB
USE BY TRAINED PERSONNEL!

DO NOT RUN UNATTENDED!

53 | 54
55 | 56


off-board Heatsink and Fan 1234
J8FAN

assuming a constant discharge current of 2 microamp to run the RTC,
2v5 at full charge, and 1.65v at RTC power-off:

clock runtime = 80e-3 / 2e-6 * (2.5 - 1.65) / 60 / 60 = 9.4 hours.
(not sure how wrong all those assumptions are, but at least it's "hours")



5k6 sets current limiter to 2.14 amp RTN

3v3 when asserted analog voltage-drop detector

3 SW 4 SW 5 SW 6 OUT 7 OUT 8 OUT 9 U1 MPM3630 C46

3 SW 4 SW 5 SW 6 OUT 7 OUT 8 OUT 9 U14 MPM3630 C39

pull down PWR_BAD
while voltage is dropping
JETSON_PWR_BAD

assert DISCHARGE at around 8V while
voltage is dropping or PWR_EN

active discharge of all rails


VCC floated as per Littelfuse
Ethernet Protection Design Guide


TMDS_SYS_D1- | | TMDS_CON_D1-
TMDS_SYS_D1+ | | | TMDS_CON_D1+

HDMI_TXD0- | | | | | | | TMDS_SYS_D0- | | TMDS_CON_D0-

TMDS_SYS_D0+ | | | TMDS_CON_D0+
TMDS_SYS_CK- | | | | TMDS_CON_CK-
TMDS_SYS_CK+ | | | TMDS_CON_CK+

CEC | | CEC_CON

DDC_DAT_CON
HPDET_CON


1 2 D1 3 TPD2EUSB30A OUT 1 GND 2 FLT 3 EN 4

1 2 D6 3 TPD2EUSB30A SS SS VBUS 1 VBUS 10 D- 11 D+ 12 GND 13 SSRX- 14 SSRX+ 15 DRAIN 16 SSTX- 17 SSTX+ 18 D- 2 D+ 3 GND

7 SSTX- 8 SSTX+ 9 SHIELD MNT

NVIDIA devkit used APL3511CBI-TRG for USB power switch:
* SOT-23-5 package
* 75 mOhm
* 1A limit * active-high EN function
* active-low current-limit fault pin
* industrial temperature

USB2_EN doesn't seem to be
available on the TX. So we'll tie it high.



SDCARD_CD | SDCARD_D0
SDCARD_PWR_EN | SDCARD_D1


This is the boot console. CONSOLE_TX_1V8
CONSOLE_RX_1V8



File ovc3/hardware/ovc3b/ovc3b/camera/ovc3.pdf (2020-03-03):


File: imu.sch Sheet: misc

File: imagers.sch Sheet: imu

File: misc.sch Sheet: te0820

File: ovc3.sch Sheet: / Sheet: bonus_cameras




8 SDO/AD0 9U3 ICM-20948 GND GND

Id: 4/7 Title: File: imu.sch Sheet: /imu/


not enough easily-routed
high-voltage i/o for now,
so leaving the LEDs open...


ICM_SPI_CS_1V2 https://wiki.trenz-electronic.de/display/PD/TE0820+TRM

Bank 65 needs to be >1v5 for the Si5338

available MIPI clock: AC9, AD7, AG4, AE2, AG9, AG6, AD2, AD5 boot-select DIP switch

Id: 6/7 Title: File: te0820.sch Sheet: /te0820/


Switches to IN1 when IN1 > IN2 TPS2121 over-voltage cutoff set to 16 V

2 PGND 20 PGND 21 RT/CLK 22 AGND 23 DNC 24

Id: 7/7 Title: File: usb3.sch Sheet: /usb3/

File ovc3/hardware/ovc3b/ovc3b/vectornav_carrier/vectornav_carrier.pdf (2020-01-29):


8 SYNC_OUT 9 Vin 10 NC 20 GND 30 ENABLE 11 NRST 21 TX1 12 SYNC_IN 22 RX1 13 SPI_CS# 23 NC 14 NC 24 NC 15 NC 25 SPI_SCK 16 NC 26 SPI_MOSI 17 NC 27 GND 18 GND 28 SPI_MISO 19 NC 29 U1VN-100 C21

File: vectornav_carrier.sch Sheet: /
Id: 1/1 Title: ovc3b VectorNav Carrier

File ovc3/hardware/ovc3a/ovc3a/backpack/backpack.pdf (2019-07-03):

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

File: backpack.sch Sheet: / GND

2 GPSVBAT 3 G1/SDA/AN1/SV2 4 G2/SCL/AMN2 5 G6/RX1/MOSI/SV4 6 G7/TX1/MISO 7 G8/CS 8 G5/SCLK 9 G9/SV3 10 TIMEPULSE

INPUT OUTPUT OUTPUT OUTPUT OUTPUT
INPUT

INPUT OUTPUT OUTPUT OUTPUT

USB-UART for linux root console

Id: 1/1 Title: OVC BACKPACK

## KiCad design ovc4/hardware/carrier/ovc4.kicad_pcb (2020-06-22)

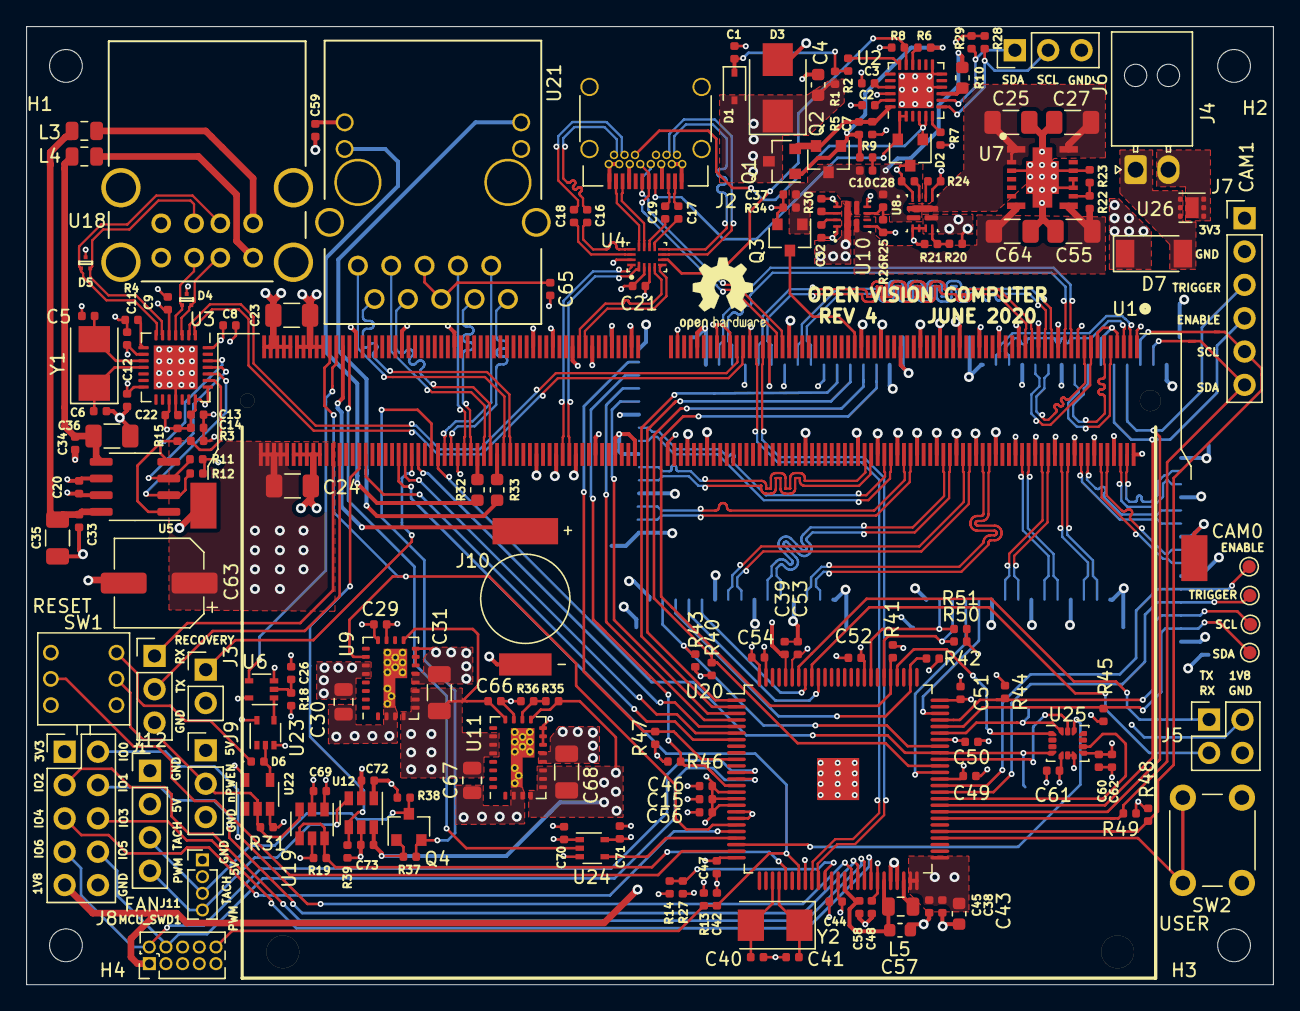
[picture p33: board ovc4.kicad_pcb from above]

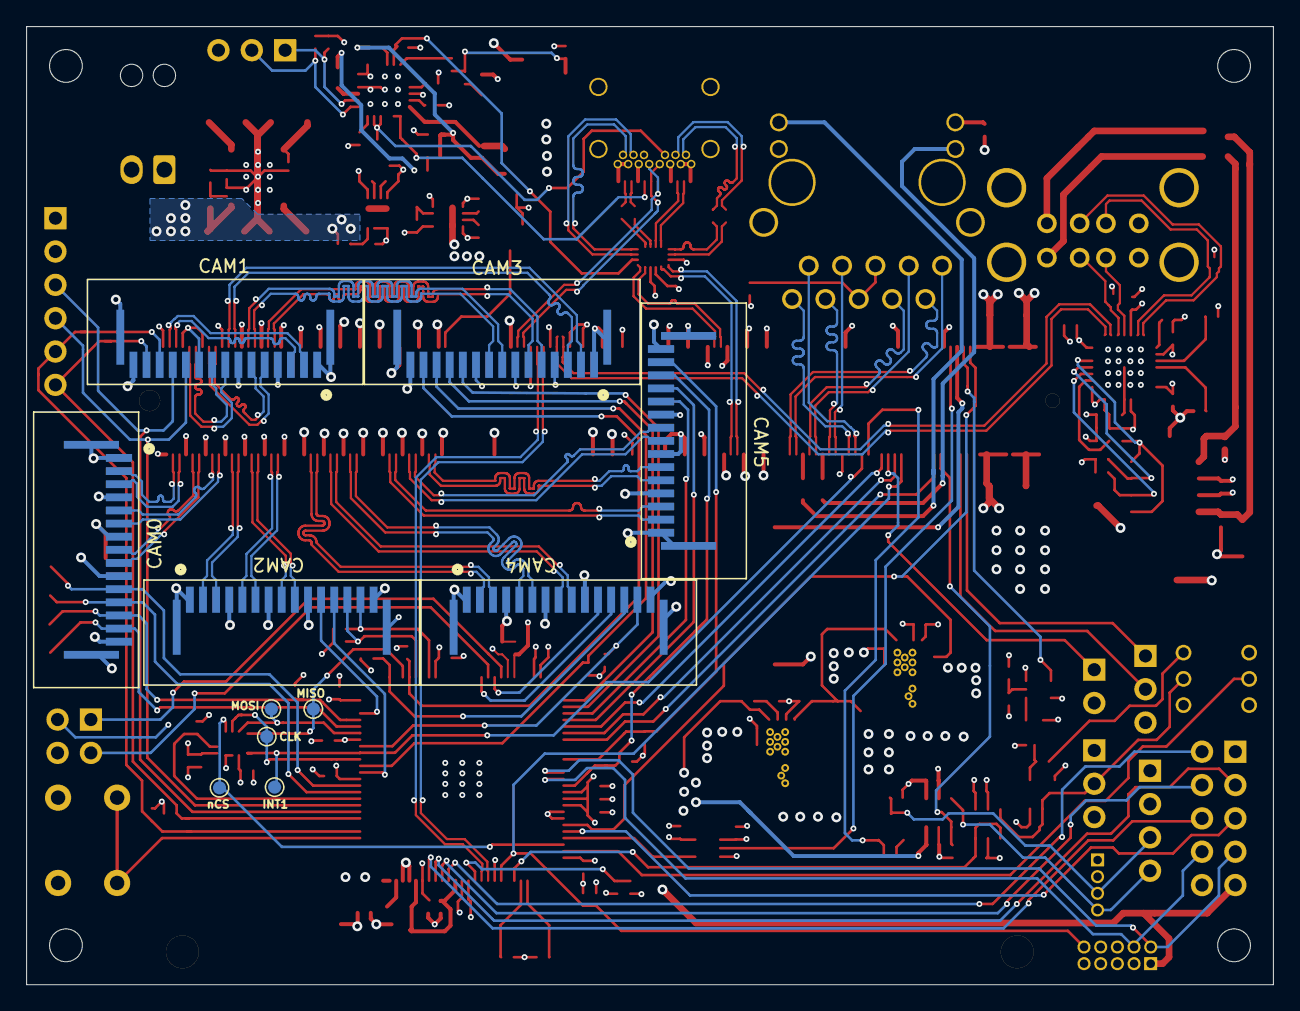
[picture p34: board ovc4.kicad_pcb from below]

Board: 6 copper layers, 95.0 x 73.0 mm, 194 parts (11 on the bottom side), 188 nets.

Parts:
C1, C2, C3, C7, C14, C22, C26, C29, C66: 1u; C_0402_1005Metric
C4: 4u7; C_0603_1608Metric
C5, C6, C40, C41: 18p; C_0402_1005Metric
C8: 10u; C_0402_1005Metric
C9, C10, C11, C12, C13, C15, C16, C17, C18, C19, C20, C21, C28, C32, C33, C34, C37, C38, C39, C42, C44, C46, C47, C48, C49, C50, C51, C52, C53, C54, C56, C58, C59, C60, C61, C65, C69, C70, C71, C72, C73: 100n; C_0402_1005Metric
C23, C24, C35, C36: 100u; C_1206_3216Metric
C25, C27: 10u; C_1206_3216Metric
C30, C67: 10u; C_0805_2012Metric
C31, C55, C64, C68: 47u; C_1206_3216Metric
C43, C57: 10u; C_0603_1608Metric
C45: 47p; C_0402_1005Metric
C62: 2u2; C_0402_1005Metric
C63: 470u; CP_Elec_6.3x7.7
CAM0, CAM1, CAM2, CAM3, CAM4, CAM5: PICAM; AMPHENOL_SFW15R
D1: SDMK0340L-7-F; D_SOD-323
D2: ESDA25W; SOT-23
D3: SMBJ22A; D_SMB
D4, D5: D_TVS_x2_AAC; TPD2EUSB30x
D6: D; D_0402_1005Metric
D7: PMEG3030EP,115; D_SOD-128
H1, H2, H3, H4: MountingHole; MountingHole_2.5mm
J1, J6, J9: Conn_01x03; PinHeader_1x03_P2.54mm_Vertical
J2: USB_C_Receptacle; USB_C_Receptacle_Wurth_632723300011
J3: Conn_01x02; PinHeader_1x02_P2.54mm_Vertical
J4: Conn_01x02; Molex_Nano-Fit_105313-xx02_1x02_P2.50mm_Horizontal
J5: ISP_UART; PinHeader_2x02_P2.54mm_Vertical
J7: Conn_01x06; PinHeader_1x06_P2.54mm_Vertical
J8: Conn_02x05_Odd_Even; PinHeader_2x05_P2.54mm_Vertical
J10: Conn_01x02; ELNA_DSK-3R3H224U-HL
J11: Conn_01x04; PinHeader_1x04_P1.27mm_Vertical
J12: Conn_01x04; PinHeader_1x04_P2.54mm_Vertical
L3, L4, L5: 4u7; L_0805_2012Metric
LOGO1: Logo_Open_Hardware_Large; OSHW-Logo2_7.3x6mm_SilkScreen
MCU_SWD1: Conn_ARM_JTAG_SWD_10; PinHeader_2x05_P1.27mm_Vertical
Q1, Q2: SI2369DS; SOT-23
Q3, Q4: 2N7002; SOT-23
R1: 470R; R_0402_1005Metric
R2: 1k; R_0402_1005Metric
R3, R5, R7, R8, R13, R15, R39: 100k; R_0402_1005Metric
R4: 649R; R_0402_1005Metric
R6, R24, R30: 22k; R_0402_1005Metric
R9: 100R; R_0402_1005Metric
R10: 1k; R_0603_1608Metric
R11, R12, R14, R18, R19, R22, R31, R37, R38: 10k; R_0402_1005Metric
R20, R25, R27: 20k; R_0402_1005Metric
R21, R26: 4k7; R_0402_1005Metric
R23, R28, R29, R40, R41, R42, R43, R44, R45, R46, R47, R48, R49, R50, R51: 2k4; R_0402_1005Metric
R32, R33: 110R; R_0603_1608Metric
R34: 1M; R_0402_1005Metric
R35: 340k; R_0402_1005Metric
R36: 162k; R_0402_1005Metric
SW1: SW_DPDT_x2; TL2230
SW2: SW_Push; SW_PUSH_6mm_H5mm
TP1, TP2, TP3, TP4, TP5, TP6, TP7, TP8, TP9: Testpoint; TestPoint_Pad_D1.0mm
U1: Jetson_Nano; TE_2309413-1
U2: STUSB4500; QFN-24-1EP_4x4mm_P0.5mm_EP2.7x2.7mm
U3: CY7C65642-28LTXC; QFN-28-1EP_5x5mm_P0.5mm_EP3.35x3.35mm
U4: HD3SS3202; TI_R_PUQFN_N16
U5: LM3526-L; SO-8_3.9x4.9mm_P1.27mm
U6: 74AHC1G08; SOT-353_SC-70-5
U7: TPSM53604; TI_B3QFN
U8, U10: TPS2121; Texas_VQFN-HR-12_2x2.5_Pitch0.5mm
U9, U11: EN5322QI; Converter_DCDC_Intel_QFN-24_4x6mm_P0.65mm_ThermalVias
U12, U19: SN74LVC1T45DBV; SOT-23-6
U18: USBA_DUAL; USBA_DUAL_HOR
U20: LPC55S69JBD100; QFP-100-1EP_3.21x3.21mm_14x14_Pitch0.5mm
U21: ARJ11C-MBSAS-A-BA-7MU2
U22: 74LVC1G34; SOT-23-5
U23: SN74LVC1G04; SOT-353_SC-70-5
U24: SN74AUP1T34DCK; SOT-353_SC-70-5
U25: ICM42688; LGA-14_3x2.5mm_P0.5mm_LayoutBorder3x4y
U26: TVS2200DRV; WSON-6-1EP_2x2mm_P0.65mm_EP1x1.6mm
Y1: 12MHz; Crystal_SMD_5032-2Pin_5.0x3.2mm
Y2: 16MHz; Crystal_SMD_5032-2Pin_5.0x3.2mm

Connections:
+1V8: C15.2, C38.2, C43.1, C45.2, C46.2, C47.2, C48.2, C49.2, C50.2, C51.2, C52.2, C53.2, C54.2, C56.2, C60.2, C61.2, C62.2, C68.1, C71.1, C73.1, J5.2, J8.9, MCU_SWD1.1 (VTref), Q4.1 (G), R13.2, R35.1, R37.1, R40.1, R41.1, R42.1, R43.1, R44.1, R45.1, R46.1, R47.1, R48.1, R49.1, R50.1, R51.1, U11.4 (VOUT), U11.5 (VOUT), U11.6 (VOUT), U11.7 (VOUT), U11.13 (VSENSE), U12.6 (VCCB), U20.15 (VDD), U20.16 (VDDA), U20.17 (VREFP), U20.25 (VDD), U20.44 (VDD), U20.49 (VBAT_DCDC), U20.50 (VBAT_DCDC), U20.51 (VBAT_PMU), U20.63 (VDD), U20.69 (VDD), U20.75 (VDD), U20.84 (VDD), U20.95 (VDD), U20.100 (VDD), U24.5 (VCCB), U25.5 (VDDIO), U25.8 (VDD)
+3V3: C8.2, C9.2, C11.2, C12.2, C13.2, C14.2, C21.2, C22.2, C31.1, C39.2, C44.2, C59.2, C66.1, C67.1, CAM0.15 (3V3), CAM1.15 (3V3), CAM2.15 (3V3), CAM3.15 (3V3), CAM4.15 (3V3), CAM5.15 (3V3), J7.1, J8.1, R8.1, R11.1, R12.1, R15.1, R28.1, R29.1, U2.22 (VSYS), U3.5 (VCC_A), U3.9 (VCC_A), U3.14 (VCC_A), U3.17 (nRESET), U3.21 (VCC_D), U3.22 (SELFPWR), U3.28 (VREG), U4.3 (VCC), U9.4 (VOUT), U9.5 (VOUT), U9.6 (VOUT), U9.7 (VOUT), U9.13 (VSENSE), U11.10 (VS2), U11.11 (VS1), U11.12 (VS0), U11.16 (AVIN), U11.18 (ENABLE), U11.19 (PVIN), U11.20 (PVIN), U20.38 (USB1_3V3), U20.96 (USB0_3V3), U21.12 (GRNYEL_A), U21.13 (GRN_A)
+5V: C20.2, C23.1, C24.1, C29.1, C30.1, C63.1, C69.1, C70.1, C72.1, J9.1, J11.2, J12.2, R14.1, R18.1, R38.1, U1.251 (VDD_IN), U1.252 (VDD_IN), U1.253 (VDD_IN), U1.254 (VDD_IN), U1.255 (VDD_IN), U1.256 (VDD_IN), U1.257 (VDD_IN), U1.258 (VDD_IN), U1.259 (VDD_IN), U1.260 (VDD_IN), U5.7 (IN), U6.5 (VCC), U9.16 (AVIN), U9.19 (PVIN), U9.20 (PVIN), U10.1 (OUT), U10.8 (OUT), U12.1 (VCCA), U19.1 (VCCA), U22.5 (VCC), U23.5 (VCC), U24.1 (VCCA)
/Interfaces/FAN_PWM: R39.2, U1.230 (GPIO14), U12.4 (B)
/Interfaces/FAN_PWM_5V: J11.4, J12.4, U12.3 (A)
/Interfaces/FAN_TACH: Q4.2 (S), R37.2, U1.208 (GPIO08)
/Interfaces/FAN_TACH_5V: J11.3, J12.3, Q4.3 (D), R38.2
/Interfaces/USB0_VBUS: Q3.3 (D), U1.87 (GPIO0)
/MCU/IMU_CLK: TP2.1, U20.66 (PIO0_28/WAKEUP), U25.13 (SCL/SCLK)
/MCU/IMU_CS: TP1.1, U20.23 (PIO0_31/ADC0_3), U25.12 (CS)
/MCU/IMU_FSYNC: U20.60 (PIO0_26), U25.9 (INT2/FSYNC/CLKIN)
/MCU/IMU_MISO: TP4.1, U20.79 (PIO0_25), U25.1 (SDO/AD0)
/MCU/IMU_MOSI: TP3.1, U20.70 (PIO0_24), U25.14 (SDA/SDIO/SDI)
/MCU/ISP_USART_RXD: J5.3, U20.92 (PIO0_29)
/MCU/ISP_USART_TXD: J5.1, U20.94 (PIO0_30)
/MCU/MCU_GPIO0: J8.2, U20.40 (PIO1_10)
/MCU/MCU_GPIO1: J8.4, U20.41 (PIO1_22)
/MCU/MCU_GPIO2: J8.3, U20.42 (PIO1_23)
/MCU/MCU_GPIO3/FC6: J8.6, U20.43 (PIO1_17)
/MCU/MCU_GPIO4/FC6: J8.5, U20.21 (PIO0_10/ADC0_1)
/MCU/MCU_GPIO_BUTTON: SW2.1, U20.54 (PIO0_0/ACMP0_A)
/MCU/SWDCLK/MCU_GPIO5/FC6: J8.8, MCU_SWD1.4 (SWDCLK/TCK), U20.13 (PIO0_11/ADC0_9)
/MCU/SWDIO/MCU_GPIO6/FC6: J8.7, MCU_SWD1.2 (SWDIO/TMS), U20.12 (PIO0_12/ADC0_10)
/Power/AUX_PWR: D7.2 (A), J4.1, U26.4 (IN), U26.5 (IN), U26.6 (IN)
/Power/BATT: J10.2, U1.235 (PMIC_BBAT)
/Power/CTRL_PWEN: U6.1, U23.4
/Power/MCU_nPWEN_5V: J9.2, R31.1, SW1.2 (B), U19.3 (A), U22.2
/Power/NX_nSHUTDOWN_REQ: U1.233 (nSHUTDOWN_REQ), U24.2 (A)
/Power/OV1: R25.2, R26.1, U10.5 (OV1)
/Power/POWER_EN: U1.237 (POWER_EN), U6.4
/Power/PR1: R20.2, R21.1, U8.6 (PR1)
/Power/VAUX: D7.1 (K), R20.1, U8.7 (IN1)
/Power/VREG_5V: C55.1, C64.1, R22.1, U7.7 (VOUT), U7.8 (VOUT), U10.2 (IN2)
/Power/VREG_IN: C25.1, C27.1, U7.1 (VIN), U7.2 (EN), U7.14 (VIN), U8.1 (OUT), U8.8 (OUT)
/Power/nFORCE_RECOVERY: J3.1, U1.214 (nFORCE_RECOVERY)
/Power/nPWEN_LATCH: D6.2 (A), U22.4, U23.2
/USB/1V2: C3.1, U2.21 (VREG_1V2)
/USB/2V7: C2.1, U2.23 (VREG_2V7)
/USB/ABSIDE: R8.2, U2.17 (A_B_SIDE), U4.6 (SEL)
/USB/CONN_CC1: D2.2 (K), J2.A5 (CC1), U2.1 (CC1DB), U2.2 (CC1)
/USB/CONN_CC2: D2.1 (K), J2.B5 (CC2), U2.4 (CC2), U2.5 (CC2DB)
/USB/CONN_RX1+: J2.B11 (RX1+), U4.8 (C1+)
/USB/CONN_RX1-: J2.B10 (RX1-), U4.7 (C1-)
/USB/CONN_RX2+: J2.A11 (RX2+), U4.12 (B1+)
/USB/CONN_RX2-: J2.A10 (RX2-), U4.11 (B1-)
/USB/CONN_TX1+: C17.2, J2.A2 (TX1+)
/USB/CONN_TX1-: C19.2, J2.A3 (TX1-)
/USB/CONN_TX2+: C16.2, J2.B2 (TX2+)
/USB/CONN_TX2-: C18.2, J2.B3 (TX2-)
/USB/CONN_VBUS: C4.1, D1.2 (A), D3.1 (A1), J2.A4 (VBUS), J2.A9 (VBUS), J2.B4 (VBUS), J2.B9 (VBUS), Q1.3 (D), R1.1
/USB/DISCH: R10.2, U2.9 (DISCH)
/USB/GATES: Q1.1 (G), Q2.1 (G), R5.2, R6.1, R9.2
/USB/HUB_nOVR0: R11.2, U3.25 (nOVR1), U5.3 (FLAGB)
/USB/HUB_nOVR1: R12.2, U3.24 (nOVR2), U5.2 (FLAGA)
/USB/HUB_nPWR: R15.2, U3.26 (nPWR/SDA), U5.1 (nENA), U5.4 (nENB)
/USB/RESET: R7.1, U2.6 (RESET)
/USB/T1+: C17.1, U4.9 (C0-)
/USB/T1-: C19.1, U4.10 (C0+)
/USB/T2+: C16.1, U4.13 (B0-)
/USB/T2-: C18.1, U4.14 (B0+)
/USB/USB0_D_N: J2.A7 (D-), J2.B7 (D-), U1.109 (USB0_D_N)
/USB/USB0_D_P: J2.A6 (D+), J2.B6 (D+), U1.111 (USB0_D_P)
/USB/USB2_D_N: U1.121 (USB2_D_N), U3.1 (D_N)
/USB/USB2_D_P: U1.123 (USB2_D_P), U3.2 (D_P)
/USB/USB2_USER0_D_N: D4.2 (A2), U3.3 (DD1_N), U18.2 (D-A)
/USB/USB2_USER0_D_P: D4.1 (A1), U3.4 (DD1_P), U18.3 (D+A)
/USB/USB2_USER1_D_N: D5.2 (A2), U3.6 (DD2_N), U18.7 (D+B)
/USB/USB2_USER1_D_P: D5.1 (A1), U3.7 (DD2_P), U18.6 (D-B)
/USB/USBSS_RX_N: U1.161 (USBSS_RX_N), U4.5 (A1-)
/USB/USBSS_RX_P: U1.163 (USBSS_RX_P), U4.4 (A1+)
/USB/USBSS_TX_N: U1.168 (USBSS_TX_P), U4.16 (A0+)
/USB/USBSS_TX_P: U1.166 (USBSS_TX_N), U4.1 (A0-)
/USB/VBUS_USER0: L4.2, U18.1 (VBUSA)
/USB/VBUS_USER1: L3.2, U18.5 (VBUSB)
/USB/VCC_USER0USB: C34.2, C36.2, L4.1, U5.5 (OUTB)
/USB/VCC_USER1USB: C33.2, C35.2, L3.1, U5.8 (OUTA)
CAM0_CLK+: CAM0.9 (CLK+), U1.12 (CSI0_CLK_P)
CAM0_CLK-: CAM0.8 (CLK-), U1.10 (CSI0_CLK_N)
CAM0_DAT0+: CAM0.3 (DAT0+), U1.6 (CSI0_D0_P)
CAM0_DAT0-: CAM0.2 (DAT0-), U1.4 (CSI0_D0_N)
CAM0_DAT1+: CAM0.6 (DAT1+), U1.18 (CSI0_D1_P)
CAM0_DAT1-: CAM0.5 (DAT1-), U1.16 (CSI0_D1_N)
CAM0_ENABLE: CAM0.11 (ENABLE), TP9.1, U20.62 (PIO1_3)
CAM0_SCL_1V8: CAM0.13 (SCL), R44.2, TP7.1, U20.72 (PIO0_14)
CAM0_SDA_1V8: CAM0.14 (SDA), R45.2, TP6.1, U20.71 (PIO0_13)
CAM0_TRIGGER: CAM0.12 (GPIO/NC), TP8.1, U20.61 (PIO1_2)
CAM1_CLK+: CAM1.9 (CLK+), U1.11 (CSI1_CLK_P)
CAM1_CLK-: CAM1.8 (CLK-), U1.9 (CSI1_CLK_N)
CAM1_DAT0+: CAM1.3 (DAT0+), U1.5 (CSI1_D0_P)
CAM1_DAT0-: CAM1.2 (DAT0-), U1.3 (CSI1_D0_N)
CAM1_DAT1+: CAM1.6 (DAT1+), U1.17 (CSI1_D1_P)
CAM1_DAT1-: CAM1.5 (DAT1-), U1.15 (CSI1_D1_N)
CAM1_ENABLE: CAM1.11 (ENABLE), J7.4, U20.59 (PIO1_1/WAKEUP)
CAM1_SCL_1V8: CAM1.13 (SCL), J7.5, R48.2, U20.55 (PIO0_9/ACMP0_B)
CAM1_SDA_1V8: CAM1.14 (SDA), J7.6, R49.2, U20.57 (PIO1_14/ACMP0_D)
CAM1_TRIGGER: CAM1.12 (GPIO/NC), J7.3, U20.58 (PIO1_19/ACMPVREF)
CAM2_CLK+: CAM2.9 (CLK+), U1.30 (CSI2_CLK_P)
CAM2_CLK-: CAM2.8 (CLK-), U1.28 (CSI2_CLK_N)
CAM2_DAT0+: CAM2.3 (DAT0+), U1.24 (CSI2_D0_P)
CAM2_DAT0-: CAM2.2 (DAT0-), U1.22 (CSI2_D0_N)
CAM2_DAT1+: CAM2.6 (DAT1+), U1.36 (CSI2_D1_P)
CAM2_DAT1-: CAM2.5 (DAT1-), U1.34 (CSI2_D1_N)
CAM2_ENABLE: CAM2.11 (ENABLE), U20.73 (PIO1_28)
CAM2_SCL_1V8: CAM2.13 (SCL), R50.2, U20.81 (PIO0_2/TRST)
CAM2_SDA_1V8: CAM2.14 (SDA), R51.2, U20.83 (PIO0_3/TCK)
CAM2_TRIGGER: CAM2.12 (GPIO/NC), U20.64 (PIO1_18/WAKEUP)
CAM3_CLK+: CAM3.9 (CLK+), U1.29 (CSI3_CLK_P)
CAM3_CLK-: CAM3.8 (CLK-), U1.27 (CSI3_CLK_N)
CAM3_DAT0+: CAM3.3 (DAT0+), U1.23 (CSI3_D0_P)
CAM3_DAT0-: CAM3.2 (DAT0-), U1.21 (CSI3_D0_N)
CAM3_DAT1+: CAM3.6 (DAT1+), U1.35 (CSI3_D1_P)
CAM3_DAT1-: CAM3.5 (DAT1-), U1.33 (CSI3_D1_N)
CAM3_ENABLE: CAM3.11 (ENABLE), U20.2 (PIO1_13)
CAM3_SCL_1V8: CAM3.13 (SCL), R40.2, U20.65 (PIO1_30/WAKEUP)
CAM3_SDA_1V8: CAM3.14 (SDA), R41.2, U20.80 (PIO1_29)
CAM3_TRIGGER: CAM3.12 (GPIO/NC), U20.1 (PIO1_4)
CAM4_CLK+: CAM4.9 (CLK+), U1.54 (CSI4_CLK_P)
CAM4_CLK-: CAM4.8 (CLK-), U1.52 (CSI4_CLK_N)
CAM4_DAT0+: CAM4.3 (DAT0+), U1.48 (CSI4_D0_P)
CAM4_DAT0-: CAM4.2 (DAT0-), U1.46 (CSI4_D0_N)
CAM4_DAT1+: CAM4.6 (DAT1+), U1.60 (CSI4_D1_P)
CAM4_DAT1-: CAM4.5 (DAT1-), U1.58 (CSI4_D1_N)
CAM4_ENABLE: CAM4.11 (ENABLE), U20.93 (PIO1_11)
CAM4_SCL_1V8: CAM4.13 (SCL), R42.2, U20.77 (PIO1_25)
CAM4_SDA_1V8: CAM4.14 (SDA), R43.2, U20.68 (PIO1_26)
CAM4_TRIGGER: CAM4.12 (GPIO/NC), U20.91 (PIO1_31)
CAM5_CLK+: CAM5.9 (CLK+), U1.78 (DSI_CLK_P)
CAM5_CLK-: CAM5.8 (CLK-), U1.76 (DSI_CLK_N)
CAM5_DAT0+: CAM5.3 (DAT0+), U1.72 (DSI_D0_P)
CAM5_DAT0-: CAM5.2 (DAT0-), U1.70 (DSI_D0_N)
CAM5_DAT1+: CAM5.6 (DAT1+), U1.84 (DSI_D1_P)
CAM5_DAT1-: CAM5.5 (DAT1-), U1.82 (DSI_D1_N)
CAM5_ENABLE: CAM5.11 (ENABLE), U20.3 (PIO1_24)
CAM5_SCL_1V8: CAM5.13 (SCL), R46.2, U20.14 (PIO0_16/ADC0_8)
CAM5_SDA_1V8: CAM5.14 (SDA), R47.2, U20.10 (PIO1_9/ADC0_12)
CAM5_TRIGGER: CAM5.12 (GPIO/NC), U20.4 (PIO1_20)
DEBUG_UART_RXD: J1.1, U1.238 (UART2_RXD)
DEBUG_UART_TXD: J1.2, U1.236 (UART2_TXD)
FRAME_TRIGGER: U1.212 (GPIO10), U20.5 (PIO1_6)
GBE_LED_ACT: R32.2, U1.194 (GBE_LED_ACT)
GBE_LED_LINK: R33.2, U1.188 (GBE_LED_LINK)
GBE_MDI0_N: U1.184 (GBE_MDI0_N), U21.2 (TRD0-)
GBE_MDI0_P: U1.186 (GBE_MDI0_P), U21.1 (TRD0+)
GBE_MDI1_N: U1.190 (GBE_MDI1_N), U21.4 (TRD1-)
GBE_MDI1_P: U1.192 (GBE_MDI1_P), U21.3 (TRD1+)
GBE_MDI2_N: U1.196 (GBE_MDI2_N), U21.8 (TRD2-)
GBE_MDI2_P: U1.198 (GBE_MDI2_P), U21.7 (TRD2+)
GBE_MDI3_N: U1.202 (GBE_MDI3_N), U21.10 (TRD3-)
GBE_MDI3_P: U1.204 (GBE_MDI3_P), U21.9 (TRD3+)
GND: C1.2, C2.2, C3.2, C4.2, C5.1, C6.2, C7.2, C8.1, C9.1, C11.1, C12.1, C13.1, C14.1, C15.1, C20.1, C21.1, C22.1, C23.2, C24.2, C25.2, C26.2, C27.2, C28.2, C29.2, C30.2, C31.2, C32.2, C33.1, C34.1, C35.1, C36.1, C37.2, C38.1, C39.1, C40.1, C41.1, C42.2, C43.2, C44.1, C45.1, C46.1, C47.1, C48.1, C49.1, C50.1, C51.1, C52.1, C53.1, C54.1, C55.2, C56.1, C57.2, C58.1, C59.1, C60.1, C61.1, C62.1, C63.2, C64.2, C65.2, C66.2, C67.2, C68.2, C69.2, C70.2, C71.2, C72.2, C73.2, CAM0.1 (GND), CAM0.4 (GND), CAM0.7 (GND), CAM0.10 (GND), CAM0.16 (PAD), CAM1.1 (GND), CAM1.4 (GND), CAM1.7 (GND), CAM1.10 (GND), CAM1.16 (PAD), CAM2.1 (GND), CAM2.4 (GND), CAM2.7 (GND), CAM2.10 (GND), CAM2.16 (PAD), CAM3.1 (GND), CAM3.4 (GND), CAM3.7 (GND), CAM3.10 (GND), CAM3.16 (PAD), CAM4.1 (GND), CAM4.4 (GND), CAM4.7 (GND)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
IMU_INT1: TP5.1, U1.206 (GPIO07), U20.67 (PIO1_12), U25.4 (INT1/INT)
MCU_USB1_D_N: U1.115 (USB1_D_N), U20.35 (USB1_DM)
MCU_USB1_D_P: U1.117 (USB1_D_P), U20.34 (USB1_DP)
MCU_nPWEN: R19.2, U19.4 (B), U19.6 (VCCB), U20.30 (PIO1_21)
NX_MCU_BOOT: U1.228 (GPIO13), U20.7 (PIO0_1)
NX_MCU_GPIO: U1.216 (GPIO11), U20.6 (PIO0_7)
NX_MCU_nRST: C42.1, MCU_SWD1.10 (~RESET~), R13.1, U1.218 (GPIO12), U20.32 (RESETN)
unnamed: C1.1, D1.1 (K), R1.2, R2.1
unnamed: C5.2, U3.10 (XIN), Y1.2
unnamed: C6.1, U3.11 (XOUT), Y1.1
unnamed: C7.1, Q1.2 (S), Q2.2 (S), R5.1, U2.24 (VDD)
unnamed: C10.2, R9.1
unnamed: C26.1, R18.2, U6.2
unnamed: C28.1, U8.11 (SS)
unnamed: C32.1, U10.11 (SS)
unnamed: C40.2, U20.28 (XTAL32M_N), Y2.2
unnamed: C41.2, U20.29 (XTAL32M_P), Y2.1
unnamed: C57.1, C58.2, L5.2, U20.39 (VDD_PMU), U20.45 (FB)
unnamed: C65.1, U21.5 (CT), U21.6 (CT)
unnamed: D6.1 (K), SW1.1 (A)
unnamed: L5.1, U20.48 (LX)
unnamed: R2.2, U2.18 (VBUS_VS_DISCH)
unnamed: R3.1, U3.23 (GANG)
unnamed: R4.1, U3.8 (RREF)
unnamed: R6.2, U2.16 (VBUS_EN_SINK)
unnamed: R14.2, R27.1, U20.36 (USB1_VBUS)
unnamed: R22.2, R23.1, U7.9 (FB)
unnamed: R24.1, U8.10 (ILIM)
unnamed: R30.1, U10.10 (ILIM)
unnamed: R32.1, U21.11 (GRNYEL_C)
unnamed: R33.1, U21.14 (GRN_C)
unnamed: R35.2, R36.1, U11.14 (VFB)
RST_BUTTON: SW1.5 (B), U20.24 (PIO1_8/ADC0_4)
USB_SCL: J6.2, R28.2, U2.7 (SCL)
USB_SDA: J6.1, R29.2, U2.8 (SDA)
VBUS: C10.1, C37.1, Q2.3 (D), Q3.1 (G), R10.1, R25.1, R34.1, U8.2 (IN2), U10.7 (IN1)
nSHUTDOWN_REQ: U20.22 (PIO0_15/ADC0_2), U24.4 (B)
nSYS_RESET: U1.239 (nSYS_RESET), U9.18 (ENABLE), U20.20 (PIO0_23)

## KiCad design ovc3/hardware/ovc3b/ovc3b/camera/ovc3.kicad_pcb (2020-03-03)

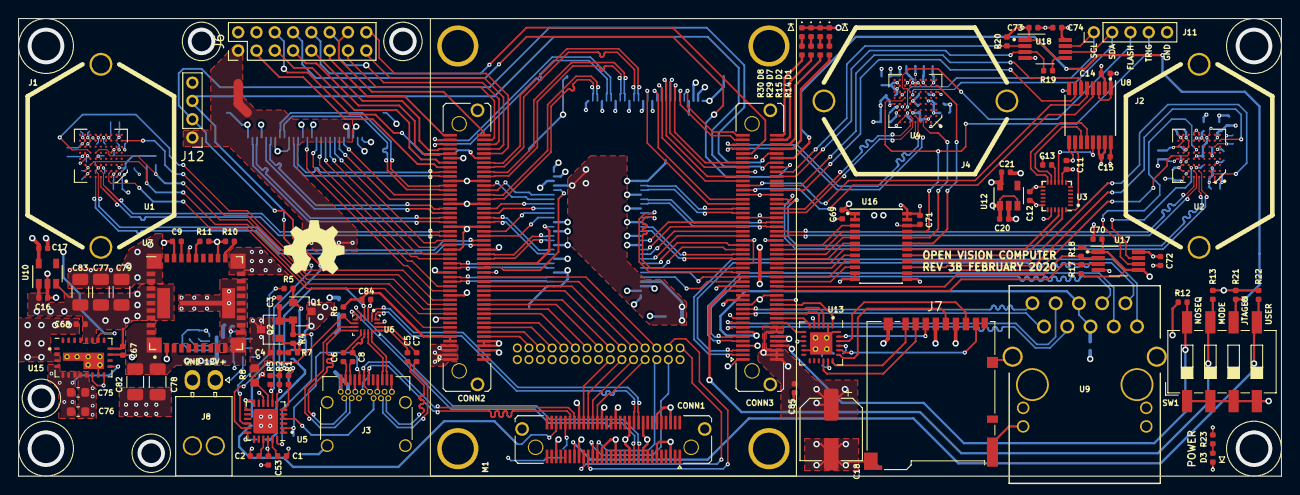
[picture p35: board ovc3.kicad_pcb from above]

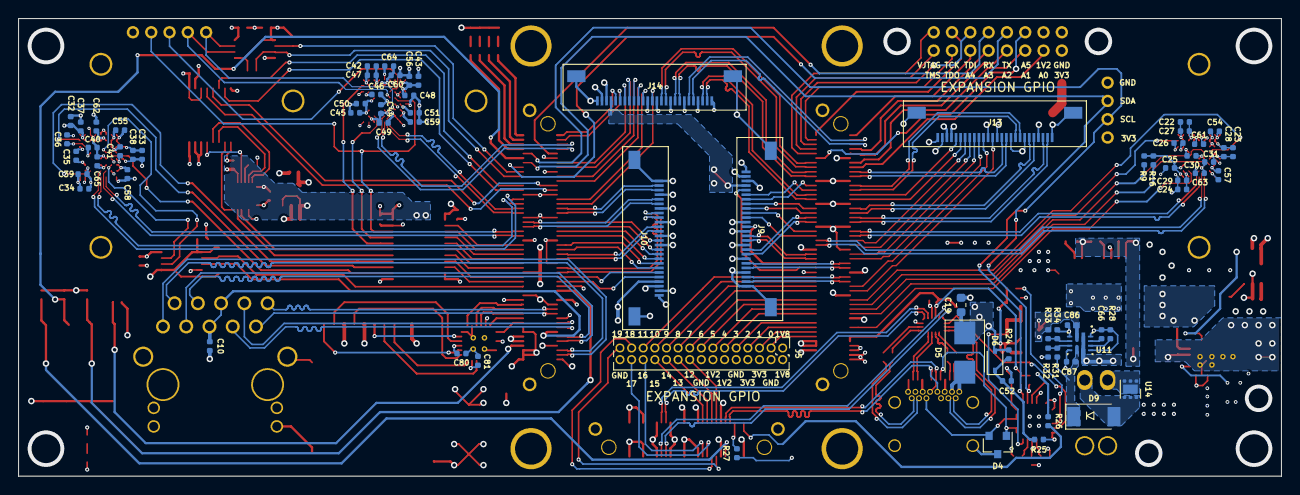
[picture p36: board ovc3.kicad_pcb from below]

Board: 6 copper layers, 138.0 x 50.0 mm, 167 parts (72 on the bottom side), 238 nets.

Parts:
C1, C2, C3, C16, C17, C20, C21, C52, C67: 1u; C_0402_1005Metric
C4, C5, C6, C7, C8, C10, C11, C12, C13, C14, C15, C26, C27, C28, C29, C30, C31, C36, C37, C38, C39, C40, C41, C44, C47, C48, C49, C50, C51, C53, C54, C55, C56, C57, C58, C59, C60, C61, C62, C63, C64, C65, C66, C69, C70, C71, C72, C73, C74, C80, C81, C84, C85, C86, C87: 100n; C_0402_1005Metric
C9: 3n3; C_0402_1005Metric
C18: 680u; CP_Elec_6.3x7.7
C19: 4u7; C_0603_1608Metric
C22, C23, C24, C25, C32, C33, C34, C35, C42, C43, C45, C46, C68: 10u; C_0402_1005Metric
C75, C76: 22u; C_0603_1608Metric
C77: 100u; C_1206_3216Metric
C78, C82: 22u; C_1206_3216Metric
C79, C83: 47u; C_1206_3216Metric
D1, D2, D3, D7, D8: LED; LED_0402_1005Metric
D4: ESD7002WTT1G; SOT-23
D5: SMBJ22A; D_SMB
D6: SDMK0340L-7-F; D_SOD-323
D9: PMEG3030EP,115; D_SOD-128
J1: LEFT_LENS; LENS_HOLDER_20MM_PT-LH010M
J2: RIGHT_LENS; LENS_HOLDER_20MM_PT-LH010M
J3: USB_C_Receptacle; USB_C_Receptacle_Wurth_632723300011
J4: MIDDLE_LENS; LENS_HOLDER_20MM_PT-LH010M
J5: LOW_SPEED_EXP; PinHeader_2x15_P1.27mm_Vertical
J6: FRONT_PACK; PinHeader_2x08_P2.00mm_Vertical
J7: Micro_SD_Card_Det_Hirose_DM3BT; microSD_HC_Hirose_DM3BT-DSF-PEJS
J8: AUX_PWR; Molex_Nano-Fit_105313-xx02_1x02_P2.50mm_Horizontal
J9: BONUS1; MOLEX_505110_2691
J10: BONUS2; MOLEX_505110_2691
J11: CAM2_TIMING_DEBUG; PinHeader_1x05_P2.00mm_Vertical
J12: I2C_DEBUG; PinHeader_1x04_P2.00mm_Vertical
J13: BONUS3; MOLEX_505110_2691
J14: BONUS4; MOLEX_505110_2691
LOGO1: Logo_Open_Hardware_Small; OSHW-Symbol_6.7x6mm_SilkScreen
M1: TE0820
Q1, Q2: SI2369DS; SOT-23
R1, R4, R6: 100k; R_0402_1005Metric
R2, R3, R12, R13, R21, R22, R26, R32, R34: 10k; R_0402_1005Metric
R5, R28: 22k; R_0402_1005Metric
R7: 100R; R_0402_1005Metric
R8: 1k; R_0603_1608Metric
R9, R16, R17, R18, R19, R20: 2k2; R_0402_1005Metric
R10: 90k9; R_0402_1005Metric
R11: 316R; R_0402_1005Metric
R14, R15, R23, R29, R30: 330R; R_0402_1005Metric
R24: 470; R_0402_1005Metric
R25, R27: 1k; R_0402_1005Metric
R31, R33: 143k; R_0402_1005Metric
SW1: SW_DIP_x04; SW_DIP_SPSTx04_Slide_6.7x11.72mm_W8.61mm_P2.54mm_LowProfile
U1, U2, U4: AR0144CS; BGA-72_9x8_5.545x5.565mm
U3: ICM-20948; InvenSense_QFN-24_3x3mm_P0.4mm
U5: STUSB4500; QFN-24-1EP_4x4mm_P0.5mm_EP2.7x2.7mm
U6: HD3SS3202; TI_R_PUQFN_N16
U7: LMZ31707; TI_RVQ_42
U8: SN74AXC4T245; TSSOP-16_4.4x5mm_P0.65mm
U9: ARJ11C-MBSAS-A-BA-7MU2
U10, U12: LP5907MFX-2.8; SOT-23-5
U11: TPS2121; Texas_VQFN-HR-12_2x2.5_Pitch0.5mm
U13: TXS02612; TI_RTW0024B
U14: TVS1800DRV; WSON-6-1EP_2x2mm_P0.65mm_EP1x1.6mm
U15: EN5322QI; Converter_DCDC_Intel_QFN-24_4x6mm_P0.65mm_ThermalVias
U16: SN74AXCH8T245; TSSOP-24_4.4x7.8mm_P0.65mm
U17, U18: TCA9803; VSSOP-8_3.0x3.0mm_P0.65mm

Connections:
3V3_VOUT: C84.2, M1.JB2.9, M1.JB2.11, R2.1, R3.1, R6.1, U6.3
+1V2: C14.1, C24.1, C26.1, C29.1, C31.1, C34.1, C36.1, C39.1, C41.1, C44.1, C46.1, C49.1, C51.1, C60.1, C61.1, C62.1, C63.1, C64.1, C65.1, C69.1, C70.1, C73.1, C75.1, C76.1, J5.12, J5.14, J6.4, J9.25, J10.25, J13.25, J14.25, M1.JB1.10, M1.JB1.12, M1.JB2.8, M1.JB2.10, R17.1, R18.1, R19.1, R20.1, U1.A3, U1.B2, U1.C5, U1.C6, U1.D8, U1.F2, U1.G4, U1.G5, U1.G6, U2.A3, U2.B2, U2.C5, U2.C6, U2.D8, U2.F2, U2.G4, U2.G5, U2.G6, U4.A3, U4.B2, U4.C5, U4.C6, U4.D8, U4.F2, U4.G4, U4.G5, U4.G6, U8.1, U8.3, U15.4, U15.5, U15.6, U15.7, U15.13, U16.1, U16.2, U17.1, U17.5, U18.1, U18.5
+1V8: C11.1, C15.1, C25.1, C30.1, C35.1, C40.1, C45.1, C50.1, C57.1, C58.1, C59.1, C71.1, C72.1, C74.1, J5.1, J5.2, J9.24, J10.24, J13.24, J14.24, M1.JB1.40, M1.JB2.6, R9.1, R13.1, R16.1, R21.1, R22.1, U1.A2, U1.B8, U1.C2, U1.C8, U1.E3, U2.A2, U2.B8, U2.C2, U2.C8, U2.E3, U3.8, U4.A2, U4.B8, U4.C2, U4.C8, U4.E3, U8.16, U15.18, U16.23, U16.24, U17.8, U18.8
+3V3: C12.1, C16.1, C18.1, C20.1, C53.1, C67.1, C68.1, C77.1, C79.1, C80.1, C81.1, C83.1, C85.1, J5.6, J5.8, J6.1, J7.4, J9.23, J10.23, J12.1, J13.23, J14.23, M1.JB1.2, M1.JB1.4, M1.JB1.6, M1.JB1.14, M1.JB1.16, M1.JB1.27, M1.JB2.1, M1.JB2.3, M1.JB2.5, M1.JB2.7, R12.1, R23.1, R27.1, U3.13, U5.22, U7.27, U7.34, U7.35, U7.36, U7.37, U7.38, U7.41, U10.1, U10.3, U12.1, U12.3, U13.5, U13.17, U13.21, U15.10, U15.12, U15.16, U15.19, U15.20
/imagers/CAM0_2V8: C17.1, C22.1, C23.1, C27.1, C28.1, C54.1, U1.F9, U1.G2, U1.G8, U1.H1, U1.H2, U1.H8, U1.H9, U10.5
/imagers/CAM1_2V8: C21.1, C32.1, C33.1, C37.1, C38.1, C42.1, C43.1, C47.1, C48.1, C55.1, C56.1, U2.F9, U2.G2, U2.G8, U2.H1, U2.H2, U2.H8, U2.H9, U4.F9, U4.G2, U4.G8, U4.H1, U4.H2, U4.H8, U4.H9, U12.5
/misc/LS_CLK: J7.5, U13.19
/misc/LS_CMD: J7.3, U13.23
/misc/LS_DAT0: J7.7, U13.22
/misc/LS_DAT1: J7.8, U13.20
/misc/LS_DAT2: J7.1, U13.18
/misc/LS_DAT3: J7.2, U13.16
/te0820/CAM1_EXTCLK_1V2: M1.JB1.42, U16.8
/te0820/CAM1_SCL_1V2: M1.JB1.34, R18.2, U17.2
/te0820/CAM1_SDA_1V2: M1.JB1.32, R17.2, U17.3
/te0820/CAM1_TRIG_1V2: M1.JB1.36, U16.10
/te0820/CAM1_nRESET_1V2: M1.JB1.38, U16.9
/te0820/CAM2_EXTCLK_1V2: M1.JB1.50, U16.4
/te0820/CAM2_SCL_1V2: M1.JB1.84, R20.2, U18.2
/te0820/CAM2_SDA_1V2: M1.JB1.82, R19.2, U18.3
/te0820/CAM2_TRIG_1V2: M1.JB1.52, U16.3
/te0820/CAM2_nRESET_1V2: M1.JB1.48, U16.5
/te0820/DIPSWITCH: M1.JB3.47, R22.2, SW1.5
/te0820/ICM_IMU_INT1_1V2: M1.JB1.77, U8.5
/te0820/ICM_SPI_CLK_1V2: M1.JB1.44, U16.7
/te0820/ICM_SPI_CS_1V2: M1.JB1.46, U16.6
/te0820/ICM_SPI_MISO_1V2: M1.JB1.75, U8.4
/te0820/ICM_SPI_MOSI_1V2: M1.JB1.76, U8.7
/te0820/ICM_SPI_SYNC_1V2: M1.JB1.78, U8.6
/te0820/JTAGEN: M1.JB1.90, R21.2, SW1.6
/te0820/MODE: M1.JB1.31, R13.2, SW1.7
/te0820/NOSEQ: M1.JB1.8, R12.2, SW1.8
/usb3/1V2: C2.1, U5.21
/usb3/2V7: C1.1, U5.23
/usb3/ABSIDE: R6.2, U5.17, U6.6
/usb3/AUX_PWR: D9.2, J8.1, U14.4, U14.5, U14.6
/usb3/CONN_CC1: D4.1, J3.A5, U5.1, U5.2
/usb3/CONN_CC2: D4.2, J3.B5, U5.4, U5.5
/usb3/CONN_RX1+: J3.B11, U6.8
/usb3/CONN_RX1-: J3.B10, U6.7
/usb3/CONN_RX2+: J3.A11, U6.12
/usb3/CONN_RX2-: J3.A10, U6.11
/usb3/CONN_TX1+: C6.2, J3.A2
/usb3/CONN_TX1-: C8.2, J3.A3
/usb3/CONN_TX2+: C5.2, J3.B2
/usb3/CONN_TX2-: C7.2, J3.B3
/usb3/CONN_VBUS: C19.1, D5.1, D6.2, J3.A4, J3.A9, J3.B4, J3.B9, Q1.3, R24.1
/usb3/DISCH: R8.2, U5.9
/usb3/GATES: Q1.1, Q2.1, R4.2, R5.1, R7.2
/usb3/PH: U7.10, U7.13, U7.14, U7.15, U7.16, U7.17, U7.18, U7.19, U7.42
/usb3/PWGND: C9.2, R10.2, R11.2, U7.2, U7.23, U7.29
/usb3/RESET: R1.1, U5.6
/usb3/T1+: C6.1, U6.9
/usb3/T1-: C8.1, U6.10
/usb3/T2+: C5.1, U6.13
/usb3/T2-: C7.1, U6.14
/usb3/VAUX: C87.1, D9.1, R31.1, U11.7
BONUS1_CLK0+: J9.2, M1.JB2.35
BONUS1_CLK0-: J9.3, M1.JB2.37
BONUS1_CLK1+: J9.8, M1.JB2.62
BONUS1_CLK1-: J9.9, M1.JB2.64
BONUS1_DAT0+: J9.5, M1.JB2.41
BONUS1_DAT0-: J9.6, M1.JB2.43
BONUS1_DAT1+: J9.11, M1.JB2.46
BONUS1_DAT1-: J9.12, M1.JB2.48
BONUS1_EXTCLK: J9.14, M1.JB2.44
BONUS1_FLASH: J9.20, M1.JB2.78
BONUS1_RESET: J9.21, M1.JB2.76
BONUS1_SCL0: J9.16, M1.JB2.56
BONUS1_SCL1: J9.18, M1.JB2.66
BONUS1_SDA0: J9.17, M1.JB2.58
BONUS1_SDA1: J9.19, M1.JB2.68
BONUS1_TRIGGER: J9.22, M1.JB2.42
BONUS2_CLK0+: J10.2, M1.JB1.67
BONUS2_CLK0-: J10.3, M1.JB1.65
BONUS2_CLK1+: J10.8, M1.JB1.39
BONUS2_CLK1-: J10.9, M1.JB1.41
BONUS2_DAT0+: J10.5, M1.JB1.62
BONUS2_DAT0-: J10.6, M1.JB1.60
BONUS2_DAT1+: J10.11, M1.JB1.47
BONUS2_DAT1-: J10.12, M1.JB1.45
BONUS2_EXTCLK: J10.14, M1.JB1.61
BONUS2_FLASH: J10.20, M1.JB1.49
BONUS2_RESET: J10.21, M1.JB1.37
BONUS2_SCL0: J10.16, M1.JB1.59
BONUS2_SCL1: J10.18, M1.JB1.55
BONUS2_SDA0: J10.17, M1.JB1.57
BONUS2_SDA1: J10.19, M1.JB1.51
BONUS2_TRIGGER: J10.22, M1.JB1.35
BONUS3_CLK0+: J13.2, M1.JB2.61
BONUS3_CLK0-: J13.3, M1.JB2.63
BONUS3_CLK1+: J13.8, M1.JB2.77
BONUS3_CLK1-: J13.9, M1.JB2.75
BONUS3_DAT0+: J13.5, M1.JB2.65
BONUS3_DAT0-: J13.6, M1.JB2.67
BONUS3_DAT1+: J13.11, M1.JB2.81
BONUS3_DAT1-: J13.12, M1.JB2.83
BONUS3_EXTCLK: J13.14, M1.JB2.31
BONUS3_FLASH: J13.20, M1.JB2.53
BONUS3_RESET: J13.21, M1.JB2.71
BONUS3_SCL0: J13.16, M1.JB2.33
BONUS3_SCL1: J13.18, M1.JB2.47
BONUS3_SDA0: J13.17, M1.JB2.45
BONUS3_SDA1: J13.19, M1.JB2.51
BONUS3_TRIGGER: J13.22, M1.JB2.73
BONUS4_CLK0+: J14.2, M1.JB2.72
BONUS4_CLK0-: J14.3, M1.JB2.74
BONUS4_CLK1+: J14.8, M1.JB2.82
BONUS4_CLK1-: J14.9, M1.JB2.84
BONUS4_DAT0+: J14.5, M1.JB2.95
BONUS4_DAT0-: J14.6, M1.JB2.97
BONUS4_DAT1+: J14.11, M1.JB2.86
BONUS4_DAT1-: J14.12, M1.JB2.88
BONUS4_EXTCLK: J14.14, M1.JB1.69
BONUS4_FLASH: J14.20, M1.JB1.87
BONUS4_RESET: J14.21, M1.JB1.97
BONUS4_SCL0: J14.16, M1.JB1.71
BONUS4_SCL1: J14.18, M1.JB1.81
BONUS4_SDA0: J14.17, M1.JB1.79
BONUS4_SDA1: J14.19, M1.JB1.85
BONUS4_TRIGGER: J14.22, M1.JB1.99
CAM0_CLK+: M1.JB2.55, U1.A5
CAM0_CLK-: M1.JB2.57, U1.B5
CAM0_D0+: M1.JB2.52, U1.A6
CAM0_D0-: M1.JB2.54, U1.B6
CAM0_EXTCLK_1V8: M1.JB2.15, U1.B3
CAM0_SCL_1V8: M1.JB2.21, R16.2, U1.C7
CAM0_SDA_1V8: M1.JB2.23, R9.2, U1.E6
CAM0_TRIG_1V8: M1.JB2.27, U1.E7
CAM0_nRESET_1V8: M1.JB2.25, U1.G1
CAM1_CLK+: M1.JB1.70, U2.A5
CAM1_CLK-: M1.JB1.72, U2.B5
CAM1_D0+: M1.JB1.58, U2.A6
CAM1_D0-: M1.JB1.56, U2.B6
CAM1_EXTCLK_1V8: U2.B3, U16.16
CAM1_SCL_1V8: U2.C7, U17.7
CAM1_SDA_1V8: U2.E6, U17.6
CAM1_TRIG_1V8: U2.E7, U16.14
CAM1_nRESET_1V8: U2.G1, U16.15
CAM2_CLK+: M1.JB1.95, U4.A5
CAM2_CLK-: M1.JB1.93, U4.B5
CAM2_D0+: M1.JB1.68, U4.A6
CAM2_D0-: M1.JB1.66, U4.B6
CAM2_EXTCLK_1V8: U4.B3, U16.20
CAM2_FLASH_1V8: J11.3, U4.F6
CAM2_SCL_1V8: J11.1, U4.C7, U18.7
CAM2_SDA_1V8: J11.2, U4.E6, U18.6
CAM2_TRIG_1V8: J11.4, U4.E7, U16.21
CAM2_nRESET_1V8: U4.G1, U16.19
ETH_VCC: C10.1, M1.JB1.13, U9.5, U9.6
FRONT_AUX0: J6.3, M1.JB2.85
FRONT_AUX1: J6.5, M1.JB2.87
FRONT_AUX2: J6.7, M1.JB2.91
FRONT_AUX3: J6.9, M1.JB2.93
FRONT_AUX4: J6.11, M1.JB2.99
FRONT_AUX5: J6.6, M1.JB2.90
GND: C1.2, C2.2, C3.2, C10.2, C11.2, C12.2, C13.2, C14.2, C15.2, C16.2, C17.2, C18.2, C19.2, C20.2, C21.2, C22.2, C23.2, C24.2, C25.2, C26.2, C27.2, C28.2, C29.2, C30.2, C31.2, C32.2, C33.2, C34.2, C35.2, C36.2, C37.2, C38.2, C39.2, C40.2, C41.2, C42.2, C43.2, C44.2, C45.2, C46.2, C47.2, C48.2, C49.2, C50.2, C51.2, C52.2, C53.2, C54.2, C55.2, C56.2, C57.2, C58.2, C59.2, C60.2, C61.2, C62.2, C63.2, C64.2, C65.2, C66.2, C67.2, C68.2, C69.2, C70.2, C71.2, C72.2, C73.2, C74.2, C75.2, C76.2, C77.2, C78.2, C79.2, C80.2, C81.2, C82.2, C83.2, C84.1, C85.2, C86.2, C87.2, D1.1, D2.1, D3.1, D4.3, D5.2, D7.1, D8.1, J1.1, J2.1, J3.A1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
GPIO0: J5.3, M1.JB2.12
GPIO1: J5.5, M1.JB2.14
GPIO2: J5.7, M1.JB2.16
GPIO3: J5.9, M1.JB2.18
GPIO4: J5.11, M1.JB2.22
GPIO5: J5.13, M1.JB2.24
GPIO6: J5.15, M1.JB2.26
GPIO7: J5.17, M1.JB2.28
GPIO8: J5.19, M1.JB2.32
GPIO9: J5.21, M1.JB2.34
GPIO10: J5.23, M1.JB2.36
GPIO11: J5.25, M1.JB2.38
GPIO12: J5.18, M1.JB3.44
GPIO13: J5.20, M1.JB3.42
GPIO14: J5.22, M1.JB3.40
GPIO15: J5.24, M1.JB3.38
GPIO16: J5.26, M1.JB3.37
GPIO17: J5.28, M1.JB3.39
GPIO18: J5.27, M1.JB3.41
GPIO19: J5.29, M1.JB3.43
ICM_IMU_INT1_1V8: U3.12, U8.12
ICM_IMU_SYNC_1V8: U3.11, U8.11
ICM_SPI_CLK_1V8: U3.23, U16.17
ICM_SPI_CS_1V8: U3.22, U16.18
ICM_SPI_MISO_1V8: U3.9, U8.13
ICM_SPI_MOSI_1V8: U3.24, U8.10
JTAG_TCK: J6.14, M1.JB2.100
JTAG_TDI: J6.12, M1.JB2.96
JTAG_TDO: J6.13, M1.JB2.98
JTAG_TMS: J6.15, M1.JB2.94
LED0: M1.JB1.94, R14.2
LED1: M1.JB1.96, R15.2
LED2: M1.JB1.98, R29.2
LED3: M1.JB1.100, R30.2
unnamed: C3.1, Q1.2, Q2.2, R4.1, U5.24
unnamed: C4.2, R7.1
unnamed: C9.1, U7.28
unnamed: C13.1, U3.10
unnamed: C52.1, D6.1, R24.2, R25.1
unnamed: C66.1, U11.11
unnamed: D1.2, R14.1
unnamed: D2.2, R15.1
unnamed: D3.2, R23.2
unnamed: D7.2, R29.1
unnamed: D8.2, R30.1
unnamed: M1.JB3.52, R27.2
unnamed: M1.JB3.56, R26.2
unnamed: R5.2, U5.16
unnamed: R10.1, U7.22
unnamed: R11.1, U7.26
unnamed: R25.2, U5.18
unnamed: R28.1, U11.10
unnamed: R31.2, R32.1, U11.5
unnamed: R33.2, R34.1, U11.4
PHY_MDI0_N: M1.JB1.5, U9.2
PHY_MDI0_P: M1.JB1.3, U9.1
PHY_MDI1_N: M1.JB1.11, U9.4
PHY_MDI1_P: M1.JB1.9, U9.3
PHY_MDI2_N: M1.JB1.17, U9.8
PHY_MDI2_P: M1.JB1.15, U9.7
PHY_MDI3_N: M1.JB1.23, U9.10
PHY_MDI3_P: M1.JB1.21, U9.9
ROOT_RX: J6.10, M1.JB1.91
ROOT_TX: J6.8, M1.JB1.86
SD_CLK: M1.JB1.28, U13.9
SD_CMD: M1.JB1.26, U13.1
SD_DAT0: M1.JB1.24, U13.3
SD_DAT1: M1.JB1.22, U13.4
SD_DAT2: M1.JB1.20, U13.6
SD_DAT3: M1.JB1.18, U13.7
USB2_D+: J3.A6, J3.B6, M1.JB3.48
USB2_D-: J3.A7, J3.B7, M1.JB3.50
USB3_RX+: M1.JB3.19, U6.4
USB3_RX-: M1.JB3.21, U6.5
USB3_TX+: M1.JB3.22, U6.16
USB3_TX-: M1.JB3.20, U6.1
USB_SCL: J12.2, M1.JB1.92, R2.2, U5.7
USB_SDA: J12.3, M1.JB1.88, R3.2, U5.8
VBUS: C4.1, C86.1, Q2.3, R8.1, R26.1, R33.1, U11.2
VCC: C78.1, C82.1, U7.1, U7.3, U7.11, U7.12, U7.39, U7.40, U11.1, U11.8
VCC_JTAG: J6.16, M1.JB2.92

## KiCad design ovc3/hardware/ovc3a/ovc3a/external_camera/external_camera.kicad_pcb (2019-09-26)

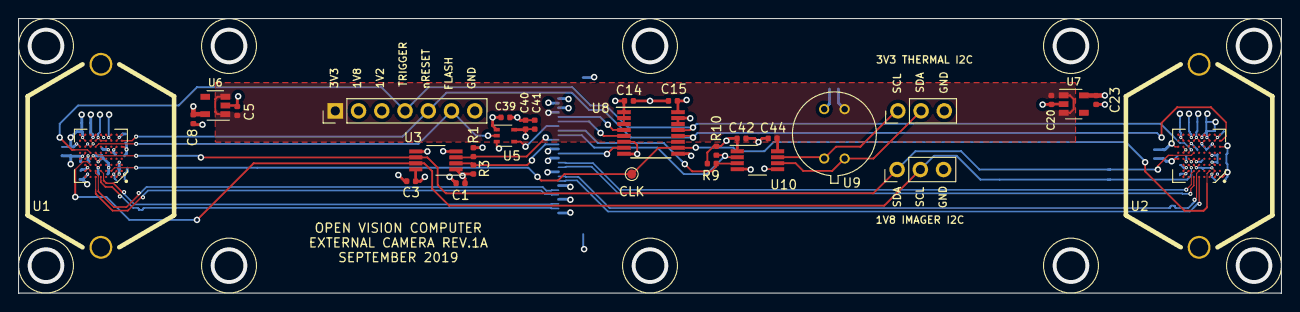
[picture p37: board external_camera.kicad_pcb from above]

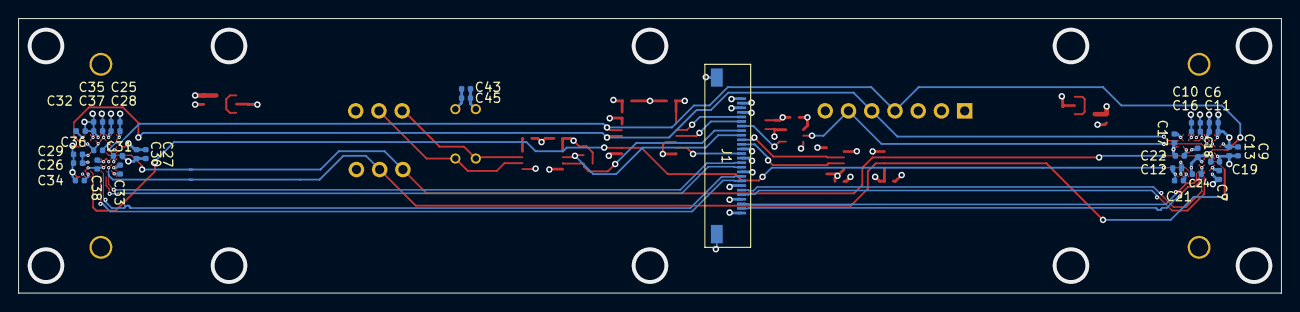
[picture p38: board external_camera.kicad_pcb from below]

Board: 6 copper layers, 138.0 x 30.0 mm, 63 parts (31 on the bottom side), 30 nets.

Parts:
C1, C3, C11, C12, C13, C14, C15, C16, C17, C18, C19, C21, C22, C24, C28, C29, C30, C32, C33, C34, C35, C36, C37, C38, C39, C40, C42, C43, C44: 100n; C_0402_1005Metric
C5, C8, C20, C23, C45: 1u; C_0402_1005Metric
C6, C7, C9, C10, C25, C26, C27, C31, C41: 10u; C_0402_1005Metric
J1: FFC; MOLEX_505110_2691
J2, J3: DNP; LENS_HOLDER_20MM_PT-LH010M
J4: DNP; PinHeader_1x07_P2.54mm_Vertical
J5, J6: DNP; PinHeader_1x03_P2.54mm_Vertical
R1, R3: 2k2; R_0402_1005Metric
R9, R10: DNP; R_0402_1005Metric
TP1: DNP; TestPoint_Pad_D1.0mm
U1, U2: AR0144CS; BGA-72_9x8_5.545x5.565mm
U3, U10: TCA9803; VSSOP-8_3.0x3.0mm_P0.65mm
U5: SN74AUP1T34DCK; SOT-353_SC-70-5
U6, U7: LP5907MFX-2.8; SOT-23-5
U8: SN74AXC4T245PWR; TSSOP-16_4.4x5mm_P0.65mm
U9: DNP; Melexis_TO-39

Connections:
+1V2: C1.1, C10.1, C14.1, C16.1, C19.1, C21.1, C22.1, C24.1, C31.1, C34.1, C35.1, C36.1, C37.1, C38.1, C40.1, C41.1, C42.1, J1.2, J4.3, R1.1, R3.1, R9.1, R10.1, U1.A3, U1.B2, U1.C5, U1.C6, U1.D8, U1.F2, U1.G4, U1.G5, U1.G6, U2.A3, U2.B2, U2.C5, U2.C6, U2.D8, U2.F2, U2.G4, U2.G5, U2.G6, U3.1, U3.5, U5.5, U8.1, U8.2, U8.3, U10.1, U10.5
+1V8: C3.1, C7.1, C12.1, C15.1, C18.1, C26.1, C29.1, C33.1, C39.1, J1.3, J4.2, U1.A2, U1.B7, U1.B8, U1.C2, U1.C8, U1.E3, U2.A2, U2.B8, U2.C2, U2.C8, U2.E3, U3.8, U5.1, U8.16
+3V3: C5.1, C20.1, C43.1, C44.1, C45.1, J1.4, J4.1, U6.1, U6.3, U7.1, U7.3, U9.2, U10.8
/CAM0_2V8: C6.1, C8.1, C9.1, C11.1, C13.1, C17.1, U1.F9, U1.G2, U1.G8, U1.H1, U1.H2, U1.H8, U1.H9, U6.5
/CAM1_2V8: C23.1, C25.1, C27.1, C28.1, C30.1, C32.1, U2.F9, U2.G2, U2.G8, U2.H1, U2.H2, U2.H8, U2.H9, U7.5
/EXTCLK_1V2: J1.13, U8.7
/EXTCLK_1V8: TP1.1, U1.B3, U2.B3, U8.10
/FLASH_1V2: J1.7, U5.4
/FLASH_1V8: J4.6, U1.F6, U5.2
/MIPI_CLK0+: J1.25, U1.A5
/MIPI_CLK0-: J1.24, U1.B5
/MIPI_CLK1+: J1.19, U2.A5
/MIPI_CLK1-: J1.18, U2.B5
/MIPI_DAT0+: J1.22, U1.A6
/MIPI_DAT0-: J1.21, U1.B6
/MIPI_DAT1+: J1.16, U2.A6
/MIPI_DAT1-: J1.15, U2.B6
/RESET_1V2: J1.6, U8.5
/RESET_1V8: J4.5, U1.G1, U2.G1, U8.12
/SCL0_1V2: J1.11, R3.2, U3.2
/SCL0_1V8: J5.2, U1.C7, U2.C7, U3.7
/SCL1_1V2: J1.9, R10.2, U10.2
/SCL1_3V3: J6.1, U9.4, U10.7
/SDA0_1V2: J1.10, R1.2, U3.3
/SDA0_1V8: J5.1, U1.E6, U2.E6, U3.6
/SDA1_1V2: J1.8, R9.2, U10.3
/SDA1_3V3: J6.2, U9.1, U10.6
/TRIGGER_1V2: J1.5, U8.4
/TRIGGER_1V8: J4.4, U1.E7, U2.E7, U8.13
GND: C1.2, C3.2, C5.2, C6.2, C7.2, C8.2, C9.2, C10.2, C11.2, C12.2, C13.2, C14.2, C15.2, C16.2, C17.2, C18.2, C19.2, C20.2, C21.2, C22.2, C23.2, C24.2, C25.2, C26.2, C27.2, C28.2, C29.2, C30.2, C31.2, C32.2, C33.2, C34.2, C35.2, C36.2, C37.2, C38.2, C39.2, C40.2, C41.2, C42.2, C43.2, C44.2, C45.2, J1.1, J1.12, J1.14, J1.17, J1.20, J1.23, J1.26, J1.27, J2.1, J3.1, J4.7, J5.3, J6.3, U1.A1, U1.A8, U1.D5, U1.D6, U1.D7, U1.D9, U1.E8, U1.F1, U1.F7, U1.F8, U1.G3, U1.G7, U1.H3, U1.H4, U1.H5, U1.H6, U1.H7, U2.A1, U2.A8, U2.B7, U2.D5, U2.D6, U2.D7, U2.D9, U2.E8, U2.F1, U2.F7, U2.F8, U2.G3, U2.G7, U2.H3, U2.H4, U2.H5, U2.H6, U2.H7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

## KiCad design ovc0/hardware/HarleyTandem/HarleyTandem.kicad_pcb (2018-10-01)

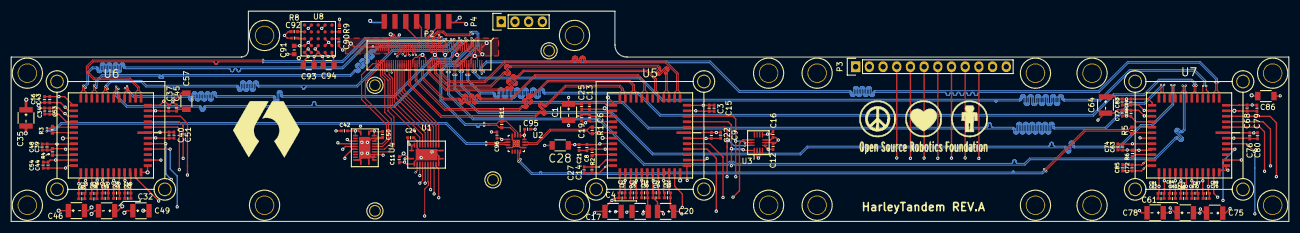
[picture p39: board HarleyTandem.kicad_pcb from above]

Board: 6 copper layers, 237.0 x 39.0 mm, 115 parts (1 on the bottom side), 91 nets.

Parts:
C1, C4, C17, C20, C32, C35, C46, C49, C61, C64, C75, C78: 100u; C_1210Polarized
C2, C5, C7, C10, C15, C19, C21, C22, C25, C27, C30, C33, C36, C38, C41, C45, C48, C51, C53, C54, C56, C59, C62, C65, C67, C70, C74, C77, C79, C80, C83, C85, C88: 4.7u; C_0402
C3, C6, C8, C11, C12, C16, C24, C34, C37, C39, C42, C50, C63, C66, C68: 100n; C_0402
C9, C13, C14, C18, C23, C26, C29, C31, C40, C43, C44, C47, C52, C55, C58, C60, C69, C72, C73, C76, C81, C84, C87, C89, C95, C96: 1u; C_0402
C28, C57, C86: 10u; C_1206
C90, C92: 10n; C_0402
C91: 10u; C_0603
C93, C94: 47u; C_0805
P1: CONN_02X07; CustomJTAG
P2: CONN_02X50; DF40C_100DS_0-4V
P3: CONN_01X12; Pin_Header_Straight_1x12
P4: CONN_01X04; Pin_Header_Straight_1x04
R1, R3, R5, R11: 100; R_0402
R2, R4, R6: 47k; R_0402
R8: 13.3k; R_0402
R9: 30.1k; R_0402
U1, U4: 74AVCH8T245-1EP; QFN-24-1EP-Pitch0.5-nonSquare
U2: SI53306; QFN-16-1EP_3x3mm_Pitch0.5mm
U3: ST_LSM6DS3; LGA14_2.5X3X0.86
U5, U6, U7: NOIP1SN1300A-QDI; LCC101.6P1422X1422X165-48
U8: LTM4622; LGA25_6.25X6.25X1.82

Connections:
+1V8: C3.1, C6.1, C8.1, C15.1, C16.1, C19.1, C21.1, C28.1, C34.1, C37.1, C39.1, C45.1, C48.1, C53.1, C57.1, C63.1, C66.1, C68.1, C74.1, C77.1, C79.1, C86.1, C94.2, P4.3, U3.8, U5.6, U5.22, U5.26, U6.6, U6.22, U6.26, U7.6, U7.22, U7.26, U8.D1, U8.E1
+2V5: C24.1, C50.1, C95.2, C96.1, P1.2, P2.81, P2.83, P2.85, P3.3, U1.23, U1.24, U2.1, U2.5, U2.16, U4.23, U4.24
+3V3: C1.1, C2.1, C4.1, C5.1, C7.1, C9.1, C10.1, C11.1, C12.1, C13.1, C14.1, C17.1, C18.1, C20.1, C22.1, C23.1, C25.1, C26.1, C27.1, C29.1, C30.1, C31.1, C32.1, C33.1, C35.1, C36.1, C38.1, C40.1, C41.1, C42.1, C43.1, C44.1, C46.1, C47.1, C49.1, C51.1, C52.1, C54.1, C55.1, C56.1, C58.1, C59.1, C60.1, C61.1, C62.1, C64.1, C65.1, C67.1, C69.1, C70.1, C72.1, C73.1, C75.1, C76.1, C78.1, C80.1, C81.1, C83.1, C84.1, C85.1, C87.1, C88.1, C89.1, C93.2, P3.2, P4.2, U1.1, U3.5, U4.1, U4.2, U5.1, U5.19, U5.29, U5.31, U5.33, U5.36, U5.38, U5.40, U6.1, U6.19, U6.29, U6.31, U6.33, U6.36, U6.38, U6.40, U7.1, U7.19, U7.29, U7.31, U7.33, U7.36, U7.38, U7.40, U8.A1, U8.B1
+5V: C91.2, P2.87, P2.89, P2.91, P2.93, P2.95, P2.97, P2.99, P3.1, P4.1, U8.A2, U8.B2, U8.B3, U8.D2, U8.D3, U8.E2
FPGA_JTAG_TCK: P1.6, P2.53
FPGA_JTAG_TDI: P1.10, P2.59
FPGA_JTAG_TDO: P1.8, P2.57
FPGA_JTAG_TMS: P1.4, P2.51
FPGA_Signal1: P2.63, P3.4
FPGA_Signal2: P2.65, P3.5
FPGA_Signal3: P2.69, P3.6
FPGA_Signal4: P2.71, P3.7
FPGA_Signal5: P2.73, P3.8
FPGA_Signal6: P2.75, P3.9
FPGA_Signal7: P2.77, P3.10
GND: C1.2, C2.2, C3.2, C4.2, C5.2, C6.2, C7.2, C8.2, C9.2, C10.2, C11.2, C12.2, C13.2, C14.2, C15.2, C16.2, C17.2, C18.2, C19.2, C20.2, C21.2, C22.2, C23.2, C24.2, C25.2, C26.2, C27.2, C28.2, C29.2, C30.2, C31.2, C32.2, C33.2, C34.2, C35.2, C36.2, C37.2, C38.2, C39.2, C40.2, C41.2, C42.2, C43.2, C44.2, C45.2, C46.2, C47.2, C48.2, C49.2, C50.2, C51.2, C52.2, C53.2, C54.2, C55.2, C56.2, C57.2, C58.2, C59.2, C60.2, C61.2, C62.2, C63.2, C64.2, C65.2, C66.2, C67.2, C68.2, C69.2, C70.2, C72.2, C73.2, C74.2, C75.2, C76.2, C77.2, C78.2, C79.2, C80.2, C81.2, C83.2, C84.2, C85.2, C86.2, C87.2, C88.2, C89.2, C90.2, C91.1, C92.2, C93.1, C94.1, C95.1, C96.2, P1.1, P1.3, P1.5, P1.7, P1.9, P1.11, P1.13, P2.1, P2.3, P2.5, P2.6, P2.7, P2.12, P2.13, P2.18, P2.19, P2.24, P2.25, P2.30, P2.31, P2.36, P2.37, P2.42, P2.43, P2.48, P2.49, P2.54, P2.60, P2.66, P2.72, P2.79, P2.86, P2.90, P3.11, P3.12, P4.4, R2.2, R4.2, R6.2, R8.2, R9.2, U1.2, U1.11, U1.12, U1.13, U1.22, U1.25, U2.4, U2.8, U2.13, U2.17, U3.2, U3.3, U3.6, U3.7, U4.11, U4.12, U4.13, U4.14, U4.15, U4.16, U4.21, U4.22, U4.25, U5.5, U5.20, U5.21, U5.25, U5.27, U5.30, U5.32, U5.34, U5.35, U5.37, U5.39, U5.42, U5.43, U5.48, U6.5, U6.20, U6.21, U6.25, U6.27, U6.30, U6.32, U6.34, U6.35, U6.37, U6.39, U6.42, U6.43, U6.48, U7.5, U7.20, U7.21, U7.25, U7.27, U7.30, U7.32, U7.34, U7.35, U7.37, U7.39, U7.42, U7.43, U7.48, U8.B5, U8.C1, U8.C2, U8.D5
IMU_CS#: P2.78, U1.16
IMU_CS#_3V3: U1.8, U3.12
unnamed: C90.1, U8.E3
unnamed: C92.1, U8.A3
unnamed: R2.1, U5.28
unnamed: R4.1, U6.28
unnamed: R6.1, U7.28
unnamed: R8.1, U8.A4
unnamed: R9.1, U8.E4
Python1_CS#: P2.82, U1.18
Python1_CS#_3V3: U1.6, U5.47
Python1_DOUT0+: P2.44, U5.9
Python1_DOUT0-: P2.46, U5.10
Python1_DOUT1+: P2.50, U5.11
Python1_DOUT1-: P2.52, U5.12
Python1_DOUT2+: P2.56, U5.13
Python1_DOUT2-: P2.58, U5.14
Python1_DOUT3+: P2.62, U5.15
Python1_DOUT3-: P2.64, U5.16
Python1_Monitor: P2.96, U4.18
Python1_Monitor_3V3: U4.6, U5.44
Python1_SYNC+: P2.68, U5.17
Python1_SYNC-: P2.70, U5.18
Python1_clk_return+: P2.38, U5.7
Python1_clk_return-: P2.40, U5.8
Python1_lvds_clk+: R1.2, U2.14, U5.24
Python1_lvds_clk-: R1.1, U2.15, U5.23
Python2_CS#: P2.84, U1.19
Python2_CS#_3V3: U1.5, U6.47
Python2_DOUT0+: P2.17, U6.9
Python2_DOUT0-: P2.15, U6.10
Python2_DOUT1+: P2.11, U6.11
Python2_DOUT1-: P2.9, U6.12
Python2_DOUT2+: P2.21, U6.13
Python2_DOUT2-: P2.23, U6.14
Python2_DOUT3+: P2.27, U6.15
Python2_DOUT3-: P2.29, U6.16
Python2_Monitor: P2.98, U4.19
Python2_Monitor_3V3: U4.5, U6.44
Python2_SYNC+: P2.35, U6.17
Python2_SYNC-: P2.33, U6.18
Python2_clk_return+: P2.39, U6.7
Python2_clk_return-: P2.41, U6.8
Python2_lvds_clk+: R3.2, U2.7, U6.24
Python2_lvds_clk-: R3.1, U2.6, U6.23
Python3_CS#: P2.80, U1.17
Python3_CS#_3V3: U1.7, U7.47
Python3_DOUT0+: P2.8, U7.9
Python3_DOUT0-: P2.10, U7.10
Python3_DOUT1+: P2.14, U7.11
Python3_DOUT1-: P2.16, U7.12
Python3_DOUT2+: P2.34, U7.13
Python3_DOUT2-: P2.32, U7.14
Python3_DOUT3+: P2.28, U7.15
Python3_DOUT3-: P2.26, U7.16
Python3_Monitor: P2.100, U4.20
Python3_Monitor_3V3: U4.4, U7.44
Python3_SYNC+: P2.22, U7.17
Python3_SYNC-: P2.20, U7.18
Python3_clk_return+: P2.4, U7.7
Python3_clk_return-: P2.2, U7.8
Python3_lvds_clk+: R5.2, U2.11, U7.24
Python3_lvds_clk-: R5.1, U2.12, U7.23
Python_RST#: P2.74, U1.14
Python_RST#_3V3: U1.10, U5.46, U6.46, U7.46
Python_Trigger: P2.76, U1.15
Python_Trigger_3V3: U1.9, U5.41, U6.41, U7.41
Python_lvds_clk+: P2.45, R11.2, U2.3
Python_lvds_clk-: P2.47, R11.1, U2.2
SPI_MISO: P2.94, U4.17
SPI_MISO_3V3: U3.1, U4.7, U5.3, U6.3, U7.3
SPI_MOSI: P2.92, U1.21
SPI_MOSI_3V3: U1.3, U3.14, U5.2, U6.2, U7.2
SPI_SCK: P2.88, U1.20
SPI_SCK_3V3: U1.4, U3.13, U5.4, U6.4, U7.4

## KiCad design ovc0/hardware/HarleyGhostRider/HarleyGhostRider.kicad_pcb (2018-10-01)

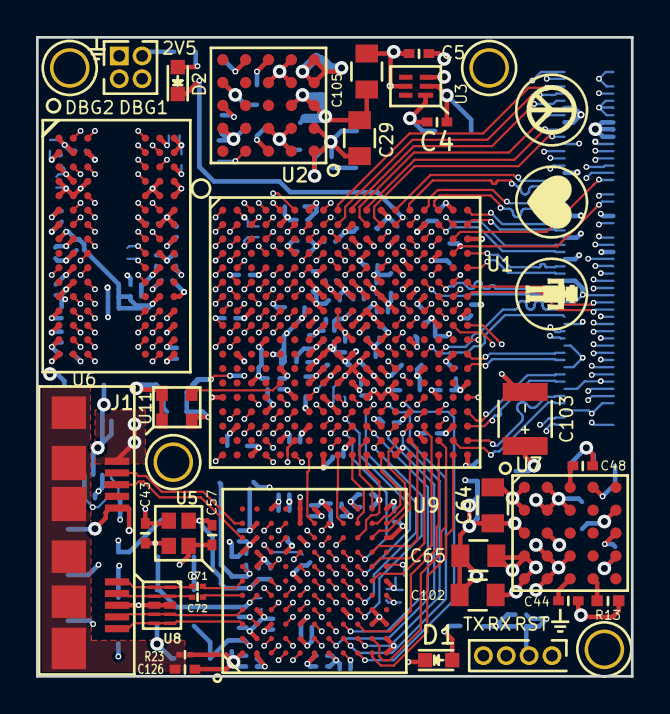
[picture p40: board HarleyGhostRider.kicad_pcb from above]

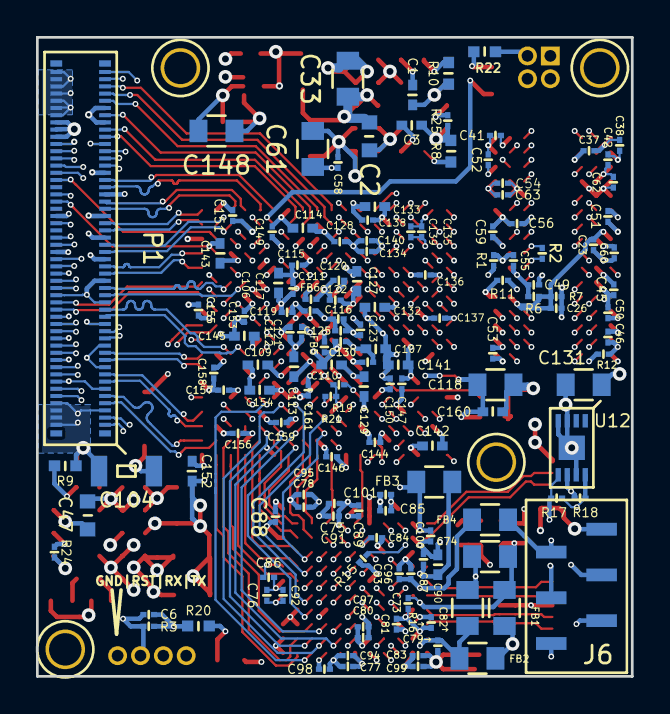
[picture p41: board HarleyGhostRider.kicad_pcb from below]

Board: 10 copper layers, 33.0 x 35.5 mm, 172 parts (141 on the bottom side), 210 nets.

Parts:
C1, C3, C44, C48, C160: 10n; C_0402
C2, C47: 10u; C_0603
C4, C5: 1u; C_0402
C6, C54, C56, C60, C111, C112, C115, C116, C117, C119, C120, C121, C122, C123, C124, C128, C130, C134, C135, C136, C137, C144, C146, C147, C149, C150, C151, C153, C155, C156, C157, C158, C159, C161: 470n; C_0201
C23, C58: 1u; C_0201
C26, C38, C42, C62, C63, C91, C92, C94, C95, C96, C97, C98, C99, C100, C101, C138, C139, C140: 10n; C_0201
C29, C33, C64, C65, C105, C118, C131, C148: 47u; C_0805
C37, C41, C45, C49, C51, C53: 2.2n; C_0201
C43, C57: 30p; C_0402
C46, C50, C52, C71, C72, C73, C75, C76, C77, C78, C79, C80, C81, C83, C84, C85, C86, C87, C88, C89, C93, C125: 100n; C_0201
C55: 3.3n; C_0201
C59: 4.7n; C_0201
C61, C74, C82, C102: 22u; C_0805
C90: 2.2u; C_0402
C103: 330u; C_1210Polarized
C104: 100u; C_1206
C106, C107, C109, C110, C113, C114, C127, C129, C132, C133, C141, C142, C143, C145, C152, C154: 4.7u; C_0402
C126: 4.7n; C_0402
D1: GREEN; LED_0603
D2: RED; LED_0603
FB1, FB2, FB3, FB4: 600; C_0805
FB5, FB6: 600; C_0201
J1: USB_3.1_microB; USB3_Micro-B
J3: CONN_01X04; Pin_Header_Straight_1x04_Pitch1.27mm
J6: CONN_01X06; GRPB061VWTC
P1: CONN_02X50; DF40C_100DP_0-4V
P2: CONN_02X02; Pin_Header_Straight_2x02_Pitch1.27mm
R1, R19, R21: 4.7k; C_0201
R2: 80.6; C_0201
R3, R17, R18: 10k; C_0201
R6, R7: 1k; C_0201
R8: 48.7k; R_0402
R9: 19.1k; R_0402
R10: 90.9k; R_0402
R11: 240; C_0201
R12: 2k; C_0201
R13: 60.4k; R_0402
R15: 6.04k; C_0201
R16: 200; C_0201
R20, R22: 200; R_0402
R23: 1M; C_0201
R24, R25: R; C_0201
U1: xc7a100tcsg324pkg; BGA324C80P18X18_1500X1500X150
U2, U7: LTM4622; LGA25_6.25X6.25X1.82
U3: TPS72718DSET; WSON6_15X15mm
U5: 8y-19.200MAAE; 8y
U6: MT41K128M16; WBGA96C80P6X16_800X1400X110
U8: IC10pins; 10-UFDFN
U9: CYUSB3014; BGA121C80P11X11_1000X1000X110
U11: OSCILLATOR; ASDMB
U12: 24LC128T-I/MNY; 8-TDFN_2x3_1EP

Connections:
+1V0: C33.2, C103.1, C104.1, C107.1, C110.1, C111.1, C113.1, C120.1, C121.1, C122.1, C123.1, C124.1, C127.1, C129.1, C130.1, C161.1, U1.F8, U1.F10, U1.G7, U1.G9, U1.G11, U1.H8, U1.J7, U1.J11, U1.K8, U1.L7, U1.L11, U1.M8, U1.M10, U1.N7, U1.N9, U1.N11, U2.D1, U2.E1
+1V2: C65.2, C76.1, C78.1, C81.1, C84.1, C86.1, C89.1, C92.1, C95.1, C98.1, C100.1, C102.1, FB1.1, FB2.1, FB3.1, U7.D1, U7.E1, U9.B10, U9.C3, U9.E9, U9.F11, U9.H1, U9.J11, U9.L5, U9.L7
+1V8: C5.1, C105.1, C106.1, C109.1, C112.1, C115.1, C117.1, C119.1, FB6.1, U1.F12, U1.H12, U1.K12, U1.M12, U3.5
+2V5: C4.1, C6.1, C64.2, C75.1, C77.1, C80.1, C83.1, C85.1, C88.1, C91.1, C94.1, C97.1, C99.1, C101.1, C114.1, C118.1, C128.1, C141.1, C142.1, C143.1, C144.1, C145.1, C146.1, C147.1, C148.1, C149.1, C150.1, C151.1, C152.1, C153.1, C154.1, C155.1, C156.1, C157.1, C158.1, C159.1, C160.1, FB4.1, J6.5, P1.82, P1.84, P1.86, P2.2, R3.1, R17.1, R18.1, R19.1, R20.1, R21.1, R22.1, U1.A17, U1.B10, U1.C13, U1.D16, U1.G15, U1.H18, U1.K4, U1.K14, U1.L17, U1.N3, U1.N13, U1.P6, U1.P8, U1.P11, U1.P12, U1.P13, U1.P16, U1.R9, U1.T2, U1.T12, U1.U5, U1.U15, U1.V8, U1.V18, U3.1, U3.3, U7.A1, U7.B1, U9.B1, U9.C11, U9.E3, U9.F1, U9.H4, U9.H11, U9.L9, U11.1, U11.4, U12.8
+5V: C2.2, C47.2, J1.1, P1.88, P1.90, P1.92, P1.94, P1.96, P1.98, P1.100, U2.A2, U2.B2, U2.B3, U2.D2, U2.D3, U2.E2, U7.A2, U7.B2, U7.B3, U7.D2, U7.D3, U7.E2, U9.E10, U9.E11
/Sheet56A15E50/AVDDQ: C87.1, C90.1, FB3.2, U9.A7
/Sheet56A15E50/CVDDQ: C93.1, C96.1, FB4.2, U9.B6
/Sheet56A15E50/USB_SS_TX+: C72.2, U9.A5
/Sheet56A15E50/USB_SS_TX-: C71.2, U9.A6
/Sheet56A15E50/VDDRX: C79.1, C82.1, FB2.2, U9.A2
/Sheet56A15E50/VDDTX: C73.1, C74.1, FB1.2, U9.B5
/Sheet56A15EBD/GND_ADC: FB5.1, U1.H9, U1.J9, U1.K10
Artix_FX3_CLK: U1.P3, U9.J6
DDR_A0: U1.G2, U6.N3
DDR_A1: U1.H5, U6.P7
DDR_A2: U1.G3, U6.P3
DDR_A3: U1.H2, U6.N2
DDR_A4: U1.J4, U6.P8
DDR_A5: U1.J2, U6.P2
DDR_A6: U1.G6, U6.R8
DDR_A7: U1.K1, U6.R2
DDR_A8: U1.H6, U6.T8
DDR_A9: U1.J3, U6.R3
DDR_A10: U1.F6, U6.L7
DDR_A11: U1.H4, U6.R7
DDR_A12: U1.G4, U6.N7
DDR_A13: U1.K2, U6.T3
DDR_BA0: U1.E1, U6.M2
DDR_BA1: U1.G1, U6.N8
DDR_BA2: U1.F1, U6.M3
DDR_CAS#: U1.C1, U6.K3
DDR_CKE: R1.1, U1.H1, U6.K9
DDR_CLK+: R2.1, U1.F4, U6.J7
DDR_CLK-: R2.2, U1.F3, U6.K7
DDR_DQL0: U1.B7, U6.E3
DDR_DQL1: U1.D8, U6.F7
DDR_DQL2: U1.C7, U6.F2
DDR_DQL3: U1.B6, U6.F8
DDR_DQL4: U1.E5, U6.H3
DDR_DQL5: U1.D7, U6.H8
DDR_DQL6: U1.E6, U6.G2
DDR_DQL7: U1.E7, U6.H7
DDR_DQSL+: U1.A6, U6.F3
DDR_DQSL-: U1.A5, U6.G3
DDR_DQSU+: U1.B1, U6.C7
DDR_DQSU-: U1.A1, U6.B7
DDR_DQU0: U1.B2, U6.D7
DDR_DQU1: U1.D4, U6.C3
DDR_DQU2: U1.B3, U6.C8
DDR_DQU3: U1.D5, U6.C2
DDR_DQU4: U1.B4, U6.A7
DDR_DQU5: U1.C4, U6.A2
DDR_DQU6: U1.A3, U6.B8
DDR_DQU7: U1.A4, U6.A3
DDR_ODT: U1.E2, U6.K1
DDR_RAS#: U1.C2, U6.J3
DDR_RST#: R12.2, U1.J5, U6.T2
DDR_VDD: C29.2, C37.1, C38.1, C41.1, C42.1, C45.1, C46.1, C49.1, C50.1, C51.1, C52.1, C53.1, C54.1, C55.1, C56.1, C58.1, C59.1, C60.1, C61.1, C62.1, C63.1, C131.1, C132.1, C133.1, C134.1, C135.1, C136.1, C137.1, C138.1, C139.1, C140.1, R6.1, R12.1, U1.A7, U1.C3, U1.D6, U1.F2, U1.G5, U1.J1, U2.A1, U2.B1, U6.A1, U6.A8, U6.B2, U6.C1, U6.C9, U6.D2, U6.D9, U6.E9, U6.F1, U6.G7, U6.H2, U6.H9, U6.K2, U6.K8, U6.N1, U6.N9, U6.R1, U6.R9
DDR_VREF: C23.1, C26.1, R6.2, R7.1, U6.H1, U6.M8
DDR_WE#: U1.D2, U6.L3
FLASH_SCL: R18.2, U9.D10, U12.6
FLASH_SDA: R17.2, U9.D9, U12.5
FPGA_CLK: U1.N5, U11.3
FPGA_DEBUG1: P2.4, U1.C9
FPGA_DEBUG2: P2.3, U1.D10
FPGA_JTAG_TCK: P1.54, U1.E10
FPGA_JTAG_TDI: P1.60, U1.E11
FPGA_JTAG_TDO: P1.58, U1.E13
FPGA_JTAG_TMS: P1.52, U1.E12
FPGA_LED: D2.1, U1.B13
FPGA_SS_CCLK: U1.E9, U9.D2
FPGA_SS_DIN: U1.K18, U9.D1
FPGA_SS_DONE: U1.P10, U9.C4
FPGA_SS_DOUT: U1.T16, U9.C1
FPGA_SS_INIT_B: R19.2, U1.P7, U9.D3
FPGA_SS_PROGRAM_B: R21.2, U1.P9, U9.D4
FPGA_Signal1: P1.64, U1.D17
FPGA_Signal2: P1.66, U1.E16
FPGA_Signal3: P1.70, U1.C17
FPGA_Signal4: P1.72, U1.D15
FPGA_Signal5: P1.74, U1.F14
FPGA_Signal6: P1.76, U1.C10
FPGA_Signal7: P1.78, U1.C12
FX3_A0: U1.T9, U9.H5
FX3_A1: U1.R11, U9.J5
FX3_DQ0: U1.V7, U9.F10
FX3_DQ1: U1.R3, U9.F9
FX3_DQ2: U1.R2, U9.F7
FX3_DQ3: U1.V4, U9.G10
FX3_DQ4: U1.T4, U9.G9
FX3_DQ5: U1.T3, U9.F8
FX3_DQ6: U1.V9, U9.H10
FX3_DQ7: U1.U6, U9.H9
FX3_DQ8: U1.V10, U9.J10
FX3_DQ9: U1.V11, U9.J9
FX3_DQ10: U1.U11, U9.K11
FX3_DQ11: U1.U13, U9.L10
FX3_DQ12: U1.V12, U9.K10
FX3_DQ13: U1.V14, U9.K9
FX3_DQ14: U1.T10, U9.J8
FX3_DQ15: U1.T5, U9.G8
FX3_DQ16: U1.U16, U9.K2
FX3_DQ17: U1.U12, U9.J4
FX3_DQ18: U1.V17, U9.K1
FX3_DQ19: U1.T14, U9.J2
FX3_DQ20: U1.V16, U9.J3
FX3_DQ21: U1.P14, U9.J1
FX3_DQ22: U1.R12, U9.H2
FX3_DQ23: U1.T11, U9.H3
FX3_DQ24: U1.P5, U9.F4
FX3_DQ25: U1.T13, U9.G2
FX3_DQ26: U1.R8, U9.G3
FX3_DQ27: U1.L14, U9.F3
FX3_DQ28: U1.U4, U9.F5
FX3_DQ29: U1.P18, U9.E1
FX3_DQ30: U1.V1, U9.E5
FX3_DQ31: U1.R16, U9.E4
FX3_FLAGA: U1.V6, U9.G7
FX3_FLAGB: U1.U9, U9.G6
FX3_FLAGC: U1.T15, U9.K6
FX3_FLAGD: U1.T8, U9.G5
FX3_JTAG_TCK: J6.1, U9.F6
FX3_JTAG_TDI: J6.2, U9.E7
FX3_JTAG_TDO: J6.4, U9.C10
FX3_JTAG_TMS: J6.3, U9.E8
FX3_LED/DEBUG: D1.1, U9.F2
FX3_PKT_END#: U1.R5, U9.H8
FX3_RST#: C6.2, J3.2, R3.2, U9.C5
FX3_SLCS#: U1.U14, U9.K8
FX3_SLOE#: U1.R10, U9.J7
FX3_SLRD#: U1.R6, U9.H7
FX3_SLWR#: U1.V15, U9.K7
FX3_UART_RX: J3.3, U9.D5
FX3_UART_TX: J3.4, U9.C2
GND: C1.2, C2.1, C3.2, C4.2, C5.2, C23.2, C26.2, C29.1, C33.1, C37.2, C38.2, C41.2, C42.2, C43.2, C44.2, C45.2, C46.2, C47.1, C48.2, C49.2, C50.2, C51.2, C52.2, C53.2, C54.2, C55.2, C56.2, C57.2, C58.2, C59.2, C60.2, C61.2, C62.2, C63.2, C64.1, C65.1, C73.2, C74.2, C75.2, C76.2, C77.2, C78.2, C79.2, C80.2, C81.2, C82.2, C83.2, C84.2, C85.2, C86.2, C87.2, C88.2, C89.2, C90.2, C91.2, C92.2, C93.2, C94.2, C95.2, C96.2, C97.2, C98.2, C99.2, C100.2, C101.2, C102.2, C103.2, C104.2, C105.2, C106.2, C107.2, C109.2, C110.2, C111.2, C112.2, C113.2, C114.2, C115.2, C116.2, C117.2, C118.2, C119.2, C120.2, C121.2, C122.2, C123.2, C124.2, C125.2, C126.2, C127.2, C128.2, C129.2, C130.2, C131.2, C132.2, C133.2, C134.2, C135.2, C136.2, C137.2, C138.2, C139.2, C140.2, C141.2, C142.2, C143.2, C144.2, C145.2, C146.2, C147.2, C148.2, C149.2, C150.2, C151.2, C152.2, C153.2, C154.2, C155.2, C156.2, C157.2, C158.2, C159.2, C160.2, C161.2, FB5.2, J1.5, J1.8, J3.1, J6.6, P1.2, P1.4, P1.5, P1.6, P1.8, P1.11, P1.14, P1.17, P1.20, P1.23, P1.26, P1.29, P1.32, P1.35, P1.38, P1.41, P1.44, P1.47, P1.50, P1.53, P1.59, P1.65, P1.71, P1.80, P1.85, P1.89, P2.1, R1.2, R7.2, R8.2, R9.2, R10.2, R11.2, R13.2, R15.2, R16.2, R23.2, R24.2, R25.2, U1.A2, U1.A12, U1.B5, U1.B15, U1.C8, U1.C18, U1.D1, U1.D11, U1.E4, U1.E8, U1.E14, U1.F7, U1.F9, U1.F11, U1.F17, U1.G8, U1.G10, U1.G12, U1.H3, U1.H7, U1.H11, U1.H13, U1.J6, U1.J8, U1.J10, U1.J12, U1.J16, U1.K7, U1.K9, U1.K11, U1.L2, U1.L8, U1.L9, U1.L10, U1.L12, U1.M5, U1.M7, U1.M9, U1.M11, U1.M15, U1.N8, U1.N10, U1.N12, U1.N18, U1.P1, U1.R4, U1.R14, U1.T7, U1.T17, U1.U10, U1.V3, U1.V13, U2.B5, U2.C1, U2.C2, U2.D5, U3.2, U5.2, U5.4, U6.A9, U6.B1, U6.B3, U6.B9, U6.D1, U6.D3, U6.D8, U6.E1, U6.E2, U6.E7, U6.E8, U6.F9, U6.G1, U6.G8, U6.G9, U6.J2, U6.J8, U6.L2, U6.M1, U6.M9, U6.P1, U6.P9, U6.T1, U6.T9, U7.B5, U7.C1, U7.C2, U7.D5, U8.3, U8.8, U9.A1, U9.A8, U9.B2, U9.B4, U9.B7, U9.B8, U9.B9, U9.D8, U9.E2, U9.E6, U9.G1, U9.G11, U9.K3, U9.K4, U9.L1, U9.L2, U9.L3, U9.L6, U9.L11, U11.2, U12.3, U12.4, U12.7, U12.EPAD
IMU_CS#: P1.77, U1.C16
unnamed: C1.1, U2.E3
unnamed: C3.1, U2.A3
unnamed: C43.1, U5.3, U9.C7
unnamed: C44.1, U7.E3
unnamed: C48.1, U7.A3
unnamed: C57.1, U5.1, U9.C6
unnamed: C116.1, C125.1, FB6.2, U1.H10
unnamed: C126.1, J1.SHLD, R23.1
unnamed: D1.2, R20.2
unnamed: D2.2, R22.2
unnamed: R8.1, U2.A4
unnamed: R9.1, U7.A4
unnamed: R10.1, U2.E4
unnamed: R11.1, U6.L8
unnamed: R13.1, U7.E4
unnamed: R15.1, U9.C8
unnamed: R16.1, U9.B3
unnamed: R24.1, U7.C5
unnamed: R25.1, U2.C5
Python1_CS#: P1.81, U1.B12
Python1_DOUT0+: P1.43, U1.E18
Python1_DOUT0-: P1.45, U1.D18
Python1_DOUT1+: P1.49, U1.B16
Python1_DOUT1-: P1.51, U1.B17
Python1_DOUT2+: P1.55, U1.B18
Python1_DOUT2-: P1.57, U1.A18
Python1_DOUT3+: P1.61, U1.A16
Python1_DOUT3-: P1.63, U1.A15
Python1_Monitor: P1.95, U1.A9
Python1_SYNC+: P1.67, U1.A14
Python1_SYNC-: P1.69, U1.A13
Python1_clk_return+: P1.37, U1.F15
Python1_clk_return-: P1.39, U1.F16
Python2_CS#: P1.83, U1.A11
Python2_DOUT0+: P1.18, U1.J18
Python2_DOUT0-: P1.16, U1.J17
Python2_DOUT1+: P1.12, U1.J13
Python2_DOUT1-: P1.10, U1.K13
Python2_DOUT2+: P1.22, U1.H17
Python2_DOUT2-: P1.24, U1.G17
Python2_DOUT3+: P1.28, U1.J14
Python2_DOUT3-: P1.30, U1.H15
Python2_Monitor: P1.97, U1.B8
Python2_SYNC+: P1.36, U1.F18
Python2_SYNC-: P1.34, U1.G18
Python2_clk_return+: P1.40, U1.H16
Python2_clk_return-: P1.42, U1.G16
Python3_CS#: P1.79, U1.B14
Python3_DOUT0+: P1.7, U1.U17
Python3_DOUT0-: P1.9, U1.U18
Python3_DOUT1+: P1.13, U1.T18
Python3_DOUT1-: P1.15, U1.R18
Python3_DOUT2+: P1.33, U1.L16
Python3_DOUT2-: P1.31, U1.L15
Python3_DOUT3+: P1.27, U1.L13
Python3_DOUT3-: P1.25, U1.M13
Python3_Monitor: P1.99, U1.A8
Python3_SYNC+: P1.21, U1.L18
Python3_SYNC-: P1.19, U1.M18
Python3_clk_return+: P1.3, U1.P15
Python3_clk_return-: P1.1, U1.R15
Python_RST#: P1.73, U1.D9
Python_Trigger: P1.75, U1.C15
Python_lvds_clk+: P1.46, U1.D14
Python_lvds_clk-: P1.48, U1.C14
SPI_MISO: P1.93, U1.B9
SPI_MOSI: P1.91, U1.A10
SPI_SCK: P1.87, U1.B11
SS_RX+: J1.10, U8.5, U8.6, U9.A3
SS_RX-: J1.9, U8.4, U8.7, U9.A4
SS_TX+: C72.1, J1.7, U8.2, U8.9
SS_TX-: C71.1, J1.6, U8.1, U8.10
USB_HS_D+: J1.3, U9.A9
USB_HS_D-: J1.2, U9.A10

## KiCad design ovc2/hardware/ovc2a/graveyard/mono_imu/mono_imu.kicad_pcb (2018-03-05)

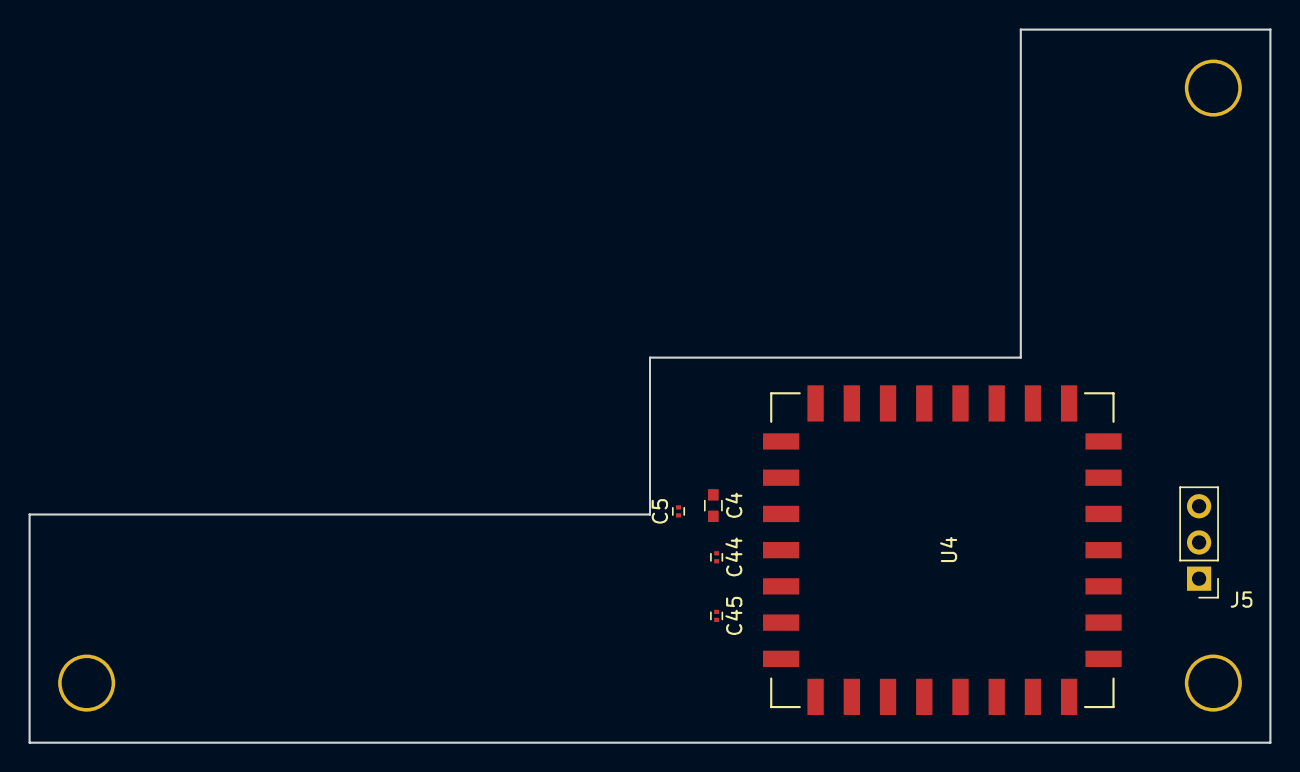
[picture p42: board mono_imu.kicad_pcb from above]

Board: 6 copper layers, 87.0 x 50.0 mm, 9 parts (0 on the bottom side), 4 nets.

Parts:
C4: 10u; C_0603
C5, C44, C45: 100n; C_0201
J5: IMU DEBUG; Pin_Header_Straight_1x03_Pitch2.54mm
M1, M2, M3: Conn_01x01; MountingHole_3.5mm
U4: VN-100

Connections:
+3V3: C4.1, C5.1, C45.1, U4.10
/imu/RX2: J5.1, U4.6
/imu/TX2: J5.2, U4.5
GND: C4.2, C5.2, C44.2, C45.2, J5.3, U4.1, U4.2, U4.3, U4.4, U4.18, U4.28, U4.30

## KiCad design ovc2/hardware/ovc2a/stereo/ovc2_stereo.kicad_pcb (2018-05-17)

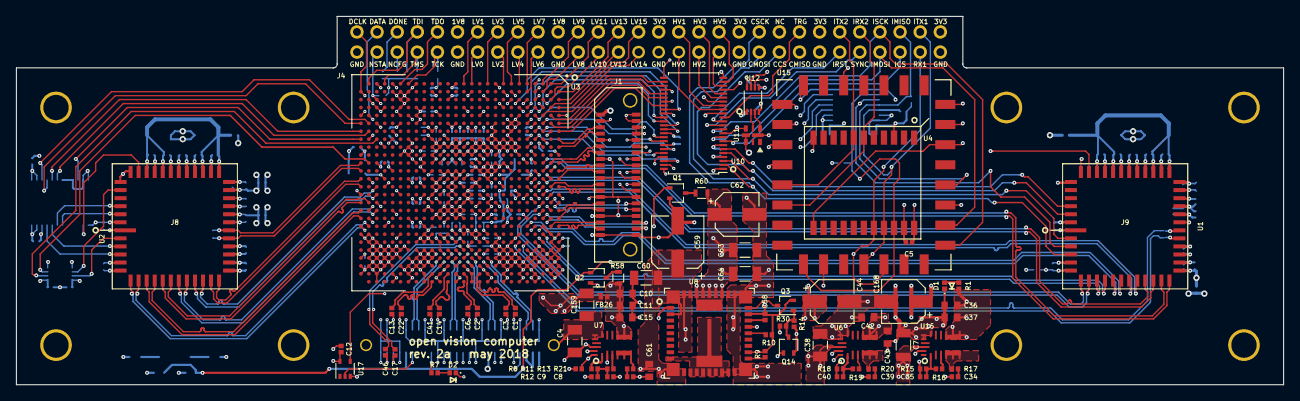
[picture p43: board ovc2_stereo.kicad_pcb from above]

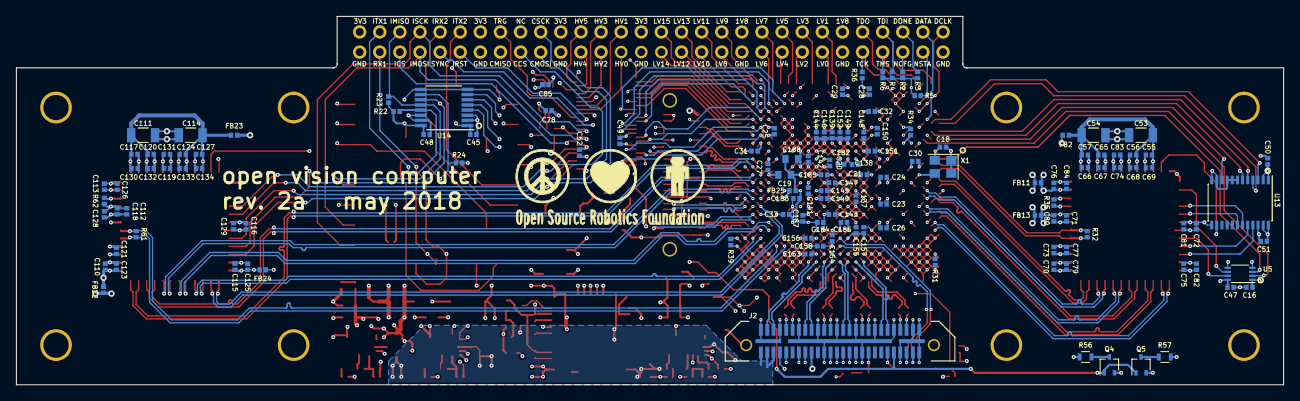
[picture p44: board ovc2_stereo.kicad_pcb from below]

Board: 6 copper layers, 160.0 x 46.5 mm, 217 parts (135 on the bottom side), 222 nets.

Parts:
C1, C2, C3, C5, C6, C12, C13, C14, C16, C17, C22, C27, C28, C41, C45, C46, C47, C48, C49, C50, C51, C52, C77, C78, C79, C80, C81, C82, C83, C84, C85, C121, C123, C125, C126, C128, C129, C131, C146, C147, C154, C155, C183, C184: 100n; C_0402_1005Metric
C4, C7, C38, C60: 22u; C_1206_3216Metric
C8, C34, C39: 470p; C_0402_1005Metric
C9, C35, C40: 22p; C_0402_1005Metric
C10, C11, C15, C36, C37, C42, C43: 22u; C_0603_1608Metric
C18, C75, C118, C143: 10n; C_0402_1005Metric
C19, C188: 47u; C_0603_1608Metric
C20, C21, C23, C24, C137, C138, C139, C140, C141, C142, C153, C182: 22n; C_0402_1005Metric
C25, C26, C144, C145: 47n; C_0402_1005Metric
C29, C148, C156, C185: 220n; C_0402_1005Metric
C30, C149, C157, C186: 470n; C_0402_1005Metric
C31, C66, C67, C68, C69, C130, C132, C133, C134, C150, C158, C187: 1u; C_0402_1005Metric
C32, C33, C55, C56, C57, C65, C74, C76, C116, C117, C119, C120, C124, C127, C151, C152: 4u7; C_0402_1005Metric
C44, C62, C168: 220u; CP_Elec_5x5.9
C53, C54, C63, C64, C111, C114, C159: 100u; C_1206_3216Metric
C58: 3n3; C_0402_1005Metric
C59: 100u; CP_Elec_6.3x7.7
C61: 100n; C_0603_1608Metric
C70, C71, C72, C73, C110, C112, C113, C115: 10u; C_0402_1005Metric
D1: LED_Red; LED_0402_1005Metric
D2: LED_Green; LED_0402_1005Metric
FB2, FB11, FB13, FB22, FB23, FB24, FB25, FB26: 60; R_0402_1005Metric
J1: HIGH-SPEED EXPANSION; SAMTEC_ERF8-020
J2: Samtec QRM8; SAMTEC_QRM8-026-02.0-L-D-A-GP
J4: LOW-SPEED EXPANSION; Pin_Header_Straight_2x30_Pitch2.54mm
J8, J9: LENS_HOLDER; LENS_HOLDER_30MM
Q1, Q2, Q3, Q4, Q5, Q14: NTS4001NT1G; SOT-323_SC-70
R1, R7: 330; R_0402_1005Metric
R2, R3, R4, R5, R6, R8, R14, R22, R23, R24, R30: 10k; R_0402_1005Metric
R9: 1M; R_0402_1005Metric
R10: 2k87; R_0402_1005Metric
R11, R12, R15, R18: 51k; R_0402_1005Metric
R13: 71k5; R_0402_1005Metric
R16: 11k3; R_0402_1005Metric
R17, R20, R21: 5R1; R_0402_1005Metric
R19: 25k5; R_0402_1005Metric
R31, R39: 2k; R_0402_1005Metric
R32, R61: 100; R_0402_1005Metric
R34, R36: 1k; R_0402_1005Metric
R35, R62: 47k; R_0402_1005Metric
R56, R57, R58, R60: 47; R_0603
U1, U2: NOIP1SN1300A-QDI; LCC101.6P1422X1422X165-48
U3: 10CXyyy_F672; INTEL_F672
U4: VN-100
U5, U12: SN74LVC2T45; VSSOP-8_2.3x2mm_Pitch0.5mm
U6, U7, U16: MPM3630
U8: LMZ31707; TI_RVQ_42
U10: SN74AVC16T245; TSSOP-48_6.1x12.5mm_Pitch0.5mm
U11: led_dotstar_micro; APA102_2020
U13: SN74AVC8T245; TSSOP-24_4.4x7.8mm_Pitch0.65mm
U14: SN74AVC4T245; TSSOP-16_4.4x5mm_Pitch0.65mm
U15: uIMU-2; DFP-22_0.5mmPitch_125x155mm
U17: 74LVC1G34; SOT-353_SC-70-5
X1: ASEMB-100MHz; Oscillator_SMD_Abracon_ASE-4pin_3.2x2.5mm
Z1: Logo_Open_Hardware_Small; OSHW-Symbol_6.7x6mm_SilkScreen
Z2: Logo_Open_Hardware_Small; OSRF_logo

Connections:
0V9: C62.1, C63.1, C64.1, C137.1, C138.1, C139.1, C140.1, C141.1, C142.1, C143.1, C144.1, C145.1, C146.1, C147.1, C148.1, C149.1, C150.1, C151.1, C152.1, R60.1, U3.K9, U3.K10, U3.K15, U3.K16, U3.K17, U3.L8, U3.L9, U3.L13, U3.L14, U3.L17, U3.L18, U3.M8, U3.M9, U3.M10, U3.M13, U3.M14, U3.M15, U3.M16, U3.N8, U3.N10, U3.N12, U3.N15, U3.N16, U3.N17, U3.N18, U3.P8, U3.P9, U3.P10, U3.P12, U3.P13, U3.P14, U3.P15, U3.P17, U3.P18, U3.R9, U3.R12, U3.R14, U3.R15, U3.R16, U3.R17, U3.T8, U3.T9, U3.T12, U3.T13, U3.T14, U3.T17, U3.T18, U3.U8, U3.U9, U3.U10, U3.U11, U3.U13, U3.U14, U3.U15, U3.U16, U3.U18, U8.27, U8.34, U8.35, U8.36, U8.37, U8.38, U8.41
1V03: C9.1, C10.1, C11.1, C15.1, FB26.2, R12.1, R58.1, U7.7, U7.8, U7.9
+1V8: C12.1, C16.1, C18.1, C20.1, C21.1, C23.1, C24.1, C25.1, C26.1, C27.1, C28.1, C29.1, C30.1, C31.1, C32.1, C33.1, C40.1, C42.1, C43.1, C44.1, C45.1, C49.1, C50.1, C85.1, FB13.2, FB24.2, FB25.2, J1.6, J1.8, J4.12, J4.22, R2.1, R3.1, R4.1, R5.1, R6.1, R18.1, R34.1, R57.1, U3.AA15, U3.AB12, U3.AB17, U3.C9, U3.D11, U3.D16, U3.E8, U3.E18, U3.F15, U3.L11, U3.L16, U3.R3, U3.T5, U3.T11, U3.T16, U3.U2, U3.V10, U3.V11, U3.V12, U3.W16, U3.Y13, U3.Y18, U5.1, U6.7, U6.8, U6.9, U10.1, U10.24, U10.31, U10.42, U12.8, U13.1, U13.2, U14.1, U17.5, X1.1, X1.4
+3V3: C5.1, C35.1, C36.1, C37.1, C47.1, C48.1, C51.1, C52.1, C168.1, FB2.2, FB11.2, FB22.2, FB23.2, J1.2, J1.4, J4.32, J4.40, J4.48, J4.60, R1.2, R15.1, R22.1, R23.1, R24.1, R56.1, U4.10, U5.8, U10.7, U10.18, U13.23, U13.24, U14.16, U15.3, U15.22, U16.7, U16.8, U16.9
+5V: C78.1, J1.1, J2.18, U11.1, U12.1
+12V: C4.1, C7.1, C38.1, C59.1, C60.1, C61.1, J2.2, J2.4, J2.6, R30.1, U6.16, U7.16, U8.1, U8.3, U8.11, U8.12, U8.39, U8.40, U16.16
/fpga_io/CAM1_CS_1V8: U3.D7, U10.44
/fpga_io/CAM1_MISO_1V8: U3.G3, U14.6
/fpga_io/CAM1_MOSI_1V8: U3.D8, U10.46
/fpga_io/CAM1_RST_1V8: U3.C7, U10.43
/fpga_io/CAM1_SCK_1V8: U3.E9, U10.47
/fpga_io/CAM1_TRG_1V8: U3.D4, U10.35
/fpga_io/CAM2_CS_1V8: U3.AE7, U13.6
/fpga_io/CAM2_MISO_1V8: U3.AD8, U5.2
/fpga_io/CAM2_MONITOR_1V8: U3.AE11, U5.3
/fpga_io/CAM2_MOSI_1V8: U3.AF6, U13.4
/fpga_io/CAM2_RST_1V8: U3.AF7, U13.5
/fpga_io/CAM2_SCK_1V8: U3.AE6, U13.3
/fpga_io/CAM2_TRG_1V8: U3.AF8, U13.10
/fpga_io/CLK100: U3.AC13, X1.3
/fpga_io/HSEXP8: J1.26, U3.D15
/fpga_io/HSEXP9: J1.24, U3.E15
/fpga_io/HSEXP10: J1.22, U3.D13
/fpga_io/HSEXP11: J1.20, U3.E14
/fpga_io/HSEXP12: J1.18, U3.D12
/fpga_io/HSEXP13: J1.16, U3.D14
/fpga_io/HSEXP14: J1.14, U3.E11
/fpga_io/HSEXP15: J1.12, U3.D10
/fpga_io/HSEXP16: J1.10, U3.C8
/fpga_io/HSEXP_0+: J1.37, U3.A19
/fpga_io/HSEXP_0-: J1.35, U3.B19
/fpga_io/HSEXP_1+: J1.38, U3.B18
/fpga_io/HSEXP_1-: J1.36, U3.C18
/fpga_io/HSEXP_2+: J1.31, U3.A18
/fpga_io/HSEXP_2-: J1.29, U3.A17
/fpga_io/HSEXP_3+: J1.32, U3.A16
/fpga_io/HSEXP_3-: J1.30, U3.B16
/fpga_io/HSEXP_4+: J1.25, U3.A14
/fpga_io/HSEXP_4-: J1.23, U3.B14
/fpga_io/HSEXP_5+: J1.17, U3.A12
/fpga_io/HSEXP_5-: J1.19, U3.A13
/fpga_io/HSEXP_6+: J1.13, U3.A11
/fpga_io/HSEXP_6-: J1.11, U3.B11
/fpga_io/HSEXP_7+: J1.7, U3.A9
/fpga_io/HSEXP_7-: J1.5, U3.A8
/fpga_io/IMU_CS_1V8: U3.C6, U10.41
/fpga_io/IMU_MISO_1V8: U3.F4, U14.5
/fpga_io/IMU_MOSI_1V8: U3.D5, U10.40
/fpga_io/IMU_NRST_1V8: U3.C3, U10.36
/fpga_io/IMU_SCK_1V8: U3.E5, U10.38
/fpga_io/IMU_SYNC_IN_1V8: U3.E4, U10.37
/fpga_io/IMU_SYNC_OUT_1V8: U3.H2, U14.7
/fpga_io/IMU_TX1_1V8: U3.E6, U14.4
/fpga_io/LED_CI_1V8: U3.D3, U12.6
/fpga_io/LED_CI_5V: U11.5, U12.2
/fpga_io/LED_DI_1V8: U3.D2, U12.7
/fpga_io/LED_DI_5V: U11.4, U12.3
/fpga_io/LSEXP_0: J4.13, U3.M1
/fpga_io/LSEXP_1: J4.14, U3.N1
/fpga_io/LSEXP_2: J4.15, U3.H1
/fpga_io/LSEXP_3: J4.16, U3.K1
/fpga_io/LSEXP_4: J4.17, U3.F1
/fpga_io/LSEXP_5: J4.18, U3.G1
/fpga_io/LSEXP_6: J4.19, U3.E2
/fpga_io/LSEXP_7: J4.20, U3.E1
/fpga_io/LSEXP_8: J4.23, U3.C2
/fpga_io/LSEXP_9: J4.24, U3.C1
/fpga_io/LSEXP_10: J4.25, U3.B3
/fpga_io/LSEXP_11: J4.26, U3.B1
/fpga_io/LSEXP_12: J4.27, U3.A3
/fpga_io/LSEXP_13: J4.28, U3.A2
/fpga_io/LSEXP_14: J4.29, U3.A4
/fpga_io/LSEXP_15: J4.30, U3.B4
/fpga_io/LSEXP_HV_0: J4.33, U10.16
/fpga_io/LSEXP_HV_0_1V8: U3.F3, U10.33
/fpga_io/LSEXP_HV_1: J4.34, U10.17
/fpga_io/LSEXP_HV_1_1V8: U3.A7, U10.32
/fpga_io/LSEXP_HV_2: J4.35, U10.19
/fpga_io/LSEXP_HV_2_1V8: U3.B6, U10.30
/fpga_io/LSEXP_HV_3: J4.36, U10.20
/fpga_io/LSEXP_HV_3_1V8: U3.A6, U10.29
/fpga_io/LSEXP_HV_4: J4.37, U10.22
/fpga_io/LSEXP_HV_4_1V8: U3.B5, U10.27
/fpga_io/LSEXP_HV_5: J4.38, U10.23
/fpga_io/LSEXP_HV_5_1V8: U3.C5, U10.26
/fpga_io/PCIE_RST_1V8: U3.AB8, U17.4
/fpga_pcie/GXB_TX_L0+: C22.2, U3.U26
/fpga_pcie/GXB_TX_L0-: C13.2, U3.U25
/fpga_pcie/GXB_TX_L1+: C14.2, U3.R26
/fpga_pcie/GXB_TX_L1-: C41.2, U3.R25
/fpga_pcie/GXB_TX_L2+: C6.2, U3.N26
/fpga_pcie/GXB_TX_L2-: C2.2, U3.N25
/fpga_pcie/GXB_TX_L3+: C1.2, U3.L26
/fpga_pcie/GXB_TX_L3-: C3.2, U3.L25
/fpga_pcie/REFCLK+: C17.2, U3.N22
/fpga_pcie/REFCLK-: C46.2, U3.N21
/fpga_power/RREF_BL: R31.1, U3.AF23
/fpga_power/RREF_TL: R39.1, U3.A21
/fpga_power/VCCA: C19.1, C182.1, C183.1, C184.1, C185.1, C186.1, C187.1, C188.1, FB25.1, U3.K20, U3.N11, U3.N13, U3.P20
/fpga_power/VCC_GXBL: C153.1, C154.1, C155.1, C156.1, C157.1, C158.1, C159.1, FB26.1, U3.K21, U3.K22, U3.M21, U3.M22, U3.P21, U3.P22, U3.T21, U3.T22
/imagers/CAM1_1V8: C112.1, C115.1, C118.1, C121.1, C125.1, C128.1, FB24.1, U1.6, U1.22, U1.26
/imagers/CAM1_3V3: C110.1, C113.1, C116.1, C119.1, C123.1, C126.1, C129.1, C131.1, FB22.1, U1.1, U1.19, U1.29, U1.36
/imagers/CAM1_VDDPIX: C111.1, C114.1, C117.1, C120.1, C124.1, C127.1, C130.1, C132.1, C133.1, C134.1, FB23.1, U1.31, U1.33, U1.38, U1.40
/imagers/CAM2_1V8: C71.1, C73.1, C75.1, C77.1, C80.1, C82.1, FB13.1, U2.6, U2.22, U2.26
/imagers/CAM2_3V3: C70.1, C72.1, C74.1, C76.1, C79.1, C81.1, C83.1, C84.1, FB11.1, U2.1, U2.19, U2.29, U2.36
/imagers/CAM2_VDDPIX: C53.1, C54.1, C55.1, C56.1, C57.1, C65.1, C66.1, C67.1, C68.1, C69.1, FB2.1, U2.31, U2.33, U2.38, U2.40
/power/AGND: C58.2, Q3.2, R9.2, R10.2, U8.2, U8.23, U8.29
/power/PG_GRP1: R8.2, U6.17, U7.18, U16.17
/power/PH: U8.10, U8.13, U8.14, U8.15, U8.16, U8.17, U8.18, U8.19, U8.42
/power/~PWR_EN_GRP1: Q3.1, Q14.3, R14.1, R30.2
CAM1_CLKIN+: R61.1, U1.23, U3.F21
CAM1_CLKIN-: R61.2, U1.24, U3.E21
CAM1_CLKOUT+: U1.7, U3.C17
CAM1_CLKOUT-: U1.8, U3.C16
CAM1_CS_3V3: J4.43, U1.47, U10.5
CAM1_DOUT0+: U1.9, U3.C21
CAM1_DOUT0-: U1.10, U3.C20
CAM1_DOUT1+: U1.11, U3.D19
CAM1_DOUT1-: U1.12, U3.E19
CAM1_DOUT2+: U1.13, U3.B15
CAM1_DOUT2-: U1.14, U3.C15
CAM1_DOUT3+: U1.15, U3.B13
CAM1_DOUT3-: U1.16, U3.C13
CAM1_MISO_3V3: J4.45, U1.3, U14.11
CAM1_MOSI_3V3: J4.41, U1.2, U10.3
CAM1_RST_3V3: U1.46, U10.6
CAM1_SCK_3V3: J4.42, U1.4, U10.2
CAM1_SYNC+: U1.17, U3.C11
CAM1_SYNC-: U1.18, U3.C12
CAM1_TRG_3V3: J4.46, U1.41, U10.14
CAM2_CLKIN+: R32.2, U2.24, U3.AF11
CAM2_CLKIN-: R32.1, U2.23, U3.AF12
CAM2_CLKOUT+: U2.7, U3.AF19
CAM2_CLKOUT-: U2.8, U3.AE19
CAM2_CS_3V3: U2.47, U13.18
CAM2_DOUT0+: U2.9, U3.AF18
CAM2_DOUT0-: U2.10, U3.AF17
CAM2_DOUT1+: U2.11, U3.AF16
CAM2_DOUT1-: U2.12, U3.AE16
CAM2_DOUT2+: U2.13, U3.AD17
CAM2_DOUT2-: U2.14, U3.AE17
CAM2_DOUT3+: U2.15, U3.AD15
CAM2_DOUT3-: U2.16, U3.AD14
CAM2_MISO_3V3: U2.2, U5.7
CAM2_MONITOR: U2.44, U5.6
CAM2_MOSI_3V3: U2.3, U13.20
CAM2_RST_3V3: U2.46, U13.19
CAM2_SCK_3V3: U2.4, U13.21
CAM2_SYNC+: U2.18, U3.AF13
CAM2_SYNC-: U2.17, U3.AF14
CAM2_TRG_3V3: U2.41, U13.14
DISCHARGE: J2.44, Q1.1, Q2.1, Q4.1, Q5.1
FPGA_CONFIG_DATA0: J2.30, J4.4, U3.AE5
FPGA_CONFIG_DCLK: J2.32, J4.2, U3.AF2
FPGA_CONF_DONE: J2.28, J4.6, R3.2, U3.AB1
FPGA_NCONFIG: J2.24, J4.5, R2.2, U3.Y5
FPGA_NSTATUS: J2.26, J4.3, R5.2, U3.AD3
FPGA_TCK: J4.9, R36.1, U3.Y1
FPGA_TDI: J4.8, R4.2, U3.AE1
FPGA_TDO: J4.10, U3.AA1
FPGA_TMS: J4.7, R6.2, U3.AC1
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

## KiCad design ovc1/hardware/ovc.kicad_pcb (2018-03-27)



Board: 6 copper layers, 230.0 x 56.0 mm, 379 parts (80 on the bottom side), 315 nets.

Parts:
C1: 100m; CP_Radial_D13.0mm_P5.00mm
C2, C3, C5, C6, C7, C13, C14, C15, C16, C17, C19, C20, C21, C22, C25, C26, C27, C28, C29, C30, C31, C32, C35, C37, C38, C40, C41, C44, C45, C46, C47, C52, C77, C79, C80, C81, C82, C83, C84, C100, C109, C121, C122, C123, C125, C126, C128, C129, C131, C146, C147, C154, C155, C175, C176, C183, C184, C189, C190: 100n; C_0201
C4, C9, C18, C24, C49, C91, C92, C93, C96, C97, C98, C99, C103, C104: 10u; C_0603
C8, C11, C34, C42, C48, C51, C61: 100n; C_0402
C10, C50, C53, C54, C63, C64, C111, C114, C163, C166, C167, C169: 100u; C_1206
C12, C75, C118, C143, C171: 10n; C_0201
C23: 100p; C_0805
C33, C43, C102, C150, C158, C179, C187: 1u; C_0402
C36, C39, C55, C56, C57, C65, C74, C76, C116, C117, C119, C120, C124, C127, C151, C152, C180, C181: 4u7; C_0402
C58, C78: 10n; C_0402
C59, C94: 100u; CP_Elec_6.3x7.7
C60, C85, C87, C135, C1103, C1104, C1105, C1109: 47u; C_1206
C62, C164, C165, C168, C170: 220u; CP_Elec_6.3x5.8
C66, C67, C68, C69, C130, C132, C133, C134: 1u; C_0201
C70, C71, C72, C73, C110, C112, C113, C115: 10u; C_0402
C86, C88, C108, C136, C1106, C1107, C1110: 4n7; C_0402
C89: 100n; C_0603
C90: 4u7; C_0603
C95, C149, C157, C178, C186: 470n; C_0402
C101: 2u2; C_0603
C105, C106, C107: 1n; C_0402
C137, C138, C139, C140, C141, C142, C153, C172, C182: 22n; C_0201
C144, C145, C173, C174: 47n; C_0201
C148, C156, C177, C185: 220n; C_0201
C159, C188: 100u; C_0805
C160: 22u; C_0603
C161, C162: 22u; C_0805
D1, D2, D3, D4, D5, D6, D7, D8: TPD2EUSB30A; TPD2EUSB30x
D9: RB521S30T1G; D_SOD-523
D10: BAT54ALT1G; SOT-23
D11: BAT54CW-7-F; SOT-323_SC-70
D12, D14: LED_Red; LED_0402
D13: LED_Green; LED_0402
FB1, FB12: 220; R_0603
FB2, FB11, FB13, FB22, FB23, FB24: 220; R_0402
FB3, FB4, FB5, FB6, FB7, FB8, FB9, FB10: 600; R_0201
FB15, FB16, FB17, FB18, FB19, FB20, FB21: 30; R_0603
FB25, FB26: 60; R_0402
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

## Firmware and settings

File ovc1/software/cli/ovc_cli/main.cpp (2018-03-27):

#include <cstdio>
#include <cstdlib>
#include <cstring>
#include <fcntl.h>  // open
#include <sys/ioctl.h>  // ioctl
#include <sys/mman.h>  // mmap
#include <signal.h>
#include <unistd.h>
#include "../ovc_module/ovc_ioctl.h"

int g_fd = 0;

bool g_done = false;
void sigint_handler(int signum)
{
  g_done = true;
}


void usage()
{
  printf("usage:  ovc_cli COMMAND [ARGUMENTS]\n");
  printf("  available commands:\n");
  printf("    pio_set IDX VAL\n");
  printf("    spi_read BUS REG\n");
  printf("    spi_write BUS REG VAL\n");
  printf("    configure_imagers\n");
  printf("    dma_test\n");
  printf("    read_data CHANNEL\n");
  printf("    bitslip CHANNEL\n");
  printf("    align\n");
  printf("    imu_read REG LEN\n");
  printf("    imu_configure\n");
  printf("    imu_stream\n");
  printf("    enable_reg_ram\n");
  printf("\n");
  exit(1);
}

int enable_reg_ram()
{
  struct ovc_ioctl_enable_reg_ram enable;
  enable.enable = 1;
  int rc = ioctl(g_fd, OVC_IOCTL_ENABLE_REG_RAM, &enable);
  printf("rc = %d\n", rc);
  return rc;
}

int spi_read(int argc, char **argv)
{
  if (argc < 4)
    usage();
  int bus = atoi(argv[2]);
  int reg = atoi(argv[3]);
  printf("spi_read(%d, %d)\n", bus, reg);
  struct ovc_ioctl_spi_xfer spi_xfer;  // __attribute__((aligned(16)));
  spi_xfer.dir = OVC_IOCTL_SPI_XFER_DIR_READ;
  spi_xfer.bus = bus;
  spi_xfer.reg_addr = reg;
  spi_xfer.reg_val = 0;
  int rc = ioctl(g_fd, OVC_IOCTL_SPI_XFER, &spi_xfer);
  printf("val = 0x%04x    rc = %d\n", (unsigned)spi_xfer.reg_val, rc);
  return 0;
}

int imu_read(int argc, char **argv)
{
  //printf("    imu_read REG LEN\n");
  if (argc < 4)
    usage();
  int reg = atoi(argv[2]);
  int len = atoi(argv[3]);
  printf("imu_read from register %d length %d\n", reg, len);
  struct ovc_ioctl_imu_txrx imu_txrx;
  imu_txrx.dir = OVC_IOCTL_IMU_TXRX_DIR_READ;
  imu_txrx.len = len;
  imu_txrx.reg_idx = reg;
  memset(imu_txrx.buf, 0, sizeof(imu_txrx.buf));
  int rc = ioctl(g_fd, OVC_IOCTL_IMU_TXRX, &imu_txrx);
  if (rc) {
    printf("unexpected rc: %d\n", rc);
    return rc;
  }
  for (int i = 0; i < len; i++)
    printf("%3d: 0x%02x\n", i, (unsigned)imu_txrx.buf[i]);
  printf("as int: %d\n", *((int32_t *)imu_txrx.buf));
  return 0;
}

int imu_configure()
{
  printf("imu_configure()\n");
  struct ovc_ioctl_imu_txrx imu_txrx;
  int rc = 0;
  /*
  // for now, just set the port to 115200 to show we can do something
  imu_txrx.dir = OVC_IOCTL_IMU_TXRX_DIR_WRITE;
  imu_txrx.len = 8;
  imu_txrx.reg_idx = 5;  // set baud rate
  memset(imu_txrx.buf, 0, sizeof(imu_txrx.buf));
  *((uint32_t *)(&imu_txrx.buf[0])) = 115200;
  int rc = ioctl(g_fd, OVC_IOCTL_IMU_TXRX, &imu_txrx);
  if (rc) {
    printf("unexpected rc: %d\n", rc);
    return rc;
  }
  */
  // disable async output
  imu_txrx.dir = OVC_IOCTL_IMU_TXRX_DIR_WRITE;
  imu_txrx.len = 8;
  imu_txrx.reg_idx = 6;  // synchronization control
  memset(imu_txrx.buf, 0, sizeof(imu_txrx.buf));
  // setting this register bytes 0-3 to zero will turn off async output
  imu_txrx.buf[4] = 1;  // serial port 1
  rc = ioctl(g_fd, OVC_IOCTL_IMU_TXRX, &imu_txrx);
  if (rc) {
    printf("unexpected ioctl rc: %d\n", rc);
    return rc;
  }

  // configure sync pins
  imu_txrx.dir = OVC_IOCTL_IMU_TXRX_DIR_WRITE;
  imu_txrx.len = 20;
  imu_txrx.reg_idx = 32;  // synchronization control
  memset(imu_txrx.buf, 0, sizeof(imu_txrx.buf));
  imu_txrx.buf[0] = 3;  // only count sync_in pulses, don't do anything else
  imu_txrx.buf[8] = 3;  // assert SYNC_OUT when attitude measurements are there
  imu_txrx.buf[9] = 1;  // positive-pulse on SYNC_OUT
  *((uint16_t *)(&imu_txrx.buf[10])) = 1;  // sync_out skip factor: 1 = 200 Hz
  *((uint32_t *)(&imu_txrx.buf[12])) = 100000;  // request 100 us pulse width
  rc = ioctl(g_fd, OVC_IOCTL_IMU_TXRX, &imu_txrx);
  if (rc) {
    printf("unexpected rc: %d\n", rc);
    return rc;
  }

  return 0;
}

int imu_stream()
{
  struct ovc_ioctl_imu_txrx imu_txrx;
  int rc = 0;
  // for debugging, slow it waaaaaaay down
  imu_txrx.dir = OVC_IOCTL_IMU_TXRX_DIR_WRITE;
  imu_txrx.len = 20;
  imu_txrx.reg_idx = 32;  // synchronization control
  memset(imu_txrx.buf, 0, sizeof(imu_txrx.buf));
  imu_txrx.buf[0] = 3;  // only count sync_in pulses, don't do anything else
  imu_txrx.buf[8] = 3;  // assert SYNC_OUT when attitude measurements are there
  imu_txrx.buf[9] = 1;  // positive-pulse on SYNC_OUT
  *((uint16_t *)(&imu_txrx.buf[10])) = 1;  // generate 200 syncs per second
  *((uint32_t *)(&imu_txrx.buf[12])) = 100000;  // request 100 us pulse width
  rc = ioctl(g_fd, OVC_IOCTL_IMU_TXRX, &imu_txrx);
  if (rc) {
    printf("unexpected rc: %d\n", rc);
    return rc;
  }

  struct ovc_ioctl_imu_set_mode imu_set_mode;
  imu_set_mode.mode = OVC_IOCTL_IMU_SET_MODE_AUTO;
  rc = ioctl(g_fd, OVC_IOCTL_IMU_SET_MODE, &imu_set_mode);
  if (rc) {
    printf("unexpected rc from ioctl set mode: %d\n", rc);
    return rc;
  }

  FILE *f = fopen("imu.txt", "w");
  printf("spinning... press Ctrl+C to stop...\n");
  while (!g_done) {
    usleep(10000);
    struct ovc_ioctl_imu_read imu_data;
    rc = ioctl(g_fd, OVC_IOCTL_IMU_READ, &imu_data);
    if (rc) {
      printf("unexpected rc from ioctl imu read: %d\n", rc);
      return rc;
    }
    fprintf(f, "%+7.3f %+7.3f %+7.3f %+7.3f %+7.3f %+7.3f "
      "%+7.3f %+7.3f %+7.3f %+7.3f "
      "%+7.6f %+7.6f %+7.6f "
      "%+7.3f %+7.3f\n",
      imu_data.accel[0], imu_data.accel[1], imu_data.accel[2],
      imu_data.gyro[0], imu_data.gyro[1], imu_data.gyro[2],
      imu_data.quaternion[0],
      imu_data.quaternion[1],
      imu_data.quaternion[2],
      imu_data.quaternion[3],
      imu_data.mag_comp[0], imu_data.mag_comp[1], imu_data.mag_comp[2],
      imu_data.pressure, imu_data.temperature);
      
    printf("==============\n");
    printf("accel: %.3f %.3f %.3f\n",
      imu_data.accel[0], imu_data.accel[1], imu_data.accel[2]);
    printf("gyro : %.3f %.3f %.3f\n",
      imu_data.gyro[0], imu_data.gyro[1], imu_data.gyro[2]);
    printf("quat : %.3f %.3f %.3f %.3f\n",
      imu_data.quaternion[0],
      imu_data.quaternion[1],
      imu_data.quaternion[2],
      imu_data.quaternion[3]);
    printf("mag  : %.3f %.3f %.3f\n",
      imu_data.mag_comp[0], imu_data.mag_comp[1], imu_data.mag_comp[2]);
    printf("pressure: %.3f\n", imu_data.pressure);
    printf("temperature: %.3f\n", imu_data.temperature);
  }
  fclose(f);

  printf("returning IMU SPI interface back to Linux host...\n");
  imu_set_mode.mode = OVC_IOCTL_IMU_SET_MODE_IDLE;
  rc = ioctl(g_fd, OVC_IOCTL_IMU_SET_MODE, &imu_set_mode);
  if (rc) {
    printf("unexpected rc from ioctl set mode: %d\n", rc);
    return rc;
  }
  printf("done.\n");

  return 0;
}

int spi_write(int argc, char **argv)
{
  if (argc < 5)
    usage();
  int bus = atoi(argv[2]);
  int reg = atoi(argv[3]);
  int val = atoi(argv[4]);
  printf("spi_write(%d, %d, %d)\n", bus, reg, val);
  struct ovc_ioctl_spi_xfer spi_xfer;
  spi_xfer.dir = OVC_IOCTL_SPI_XFER_DIR_WRITE;
  spi_xfer.bus = bus;
  spi_xfer.reg_addr = reg;
  spi_xfer.reg_val = val;
  int rc = ioctl(g_fd, OVC_IOCTL_SPI_XFER, &spi_xfer);
  printf("rc = %d\n", rc);
  return 0;
}

int dma_test(int argc, char **argv)
{
  //int dma_fd = open("/dev/ovc", O_RDONLY);
  uint8_t *dma = (uint8_t *)mmap(
    0, OVC_IOCTL_DMA_BUF_SIZE, PROT_READ, MAP_SHARED, g_fd, 0);
  printf("g_fd = %d, dma_ptr = %llx\n", g_fd, (unsigned long long)dma);

  struct ovc_ioctl_dma_start dma_start;
  dma_start.len = OVC_IOCTL_DMA_BUF_SIZE / 128;  //20608;
  dma_start.offset = 0x00;
  int rc = ioctl(g_fd, OVC_IOCTL_DMA_START, &dma_start);
  printf("ioctl rc = %d\n", rc);
  usleep(500000);
  for (int i = 0; i < 1024; i++) {
    printf("%02x ", dma[i]);
    if (i % 16 == 15)
      printf("\n");
  }
  FILE *f = fopen("img.bin", "wb");
  fwrite(dma, 1, 1280*1024, f);
  fclose(f);
  printf("wrote image dump file\n");
  return 0;
}

int read_data(int argc, char **argv)
{
  if (argc < 3)
    usage();
  struct ovc_ioctl_read_data read_data;
  read_data.camera = 0;
  read_data.channel = atoi(argv[2]);
  uint8_t prev_sync_data = 0;
  int nread = 0;
  while (nread < 10) {
    int rc = ioctl(g_fd, OVC_IOCTL_READ_DATA, &read_data);
    uint8_t sync_data = (uint8_t)(read_data.data >> 24);
    if (sync_data != prev_sync_data) {
      nread++;
      prev_sync_data = sync_data;
      uint8_t channel_data = (uint8_t)(read_data.data >> 16);
      printf("sync: 0x%02x channel %d: 0x%02x\n",
        (unsigned)sync_data, (int)read_data.channel, (unsigned)channel_data);
    }
  }
  return 0;
}

int align()
{
  // first we need to align the sync channel
  struct ovc_ioctl_read_data read_data;
  read_data.camera = 0;
  read_data.channel = 0;
  for (int imager_idx = 0; imager_idx < 2; imager_idx++) {
    printf("working on imager %d\n", imager_idx);
    read_data.channel = imager_idx * 4;
    uint8_t sync_data = 0;
    bool sync_ok = false;
    for (int attempt = 0; attempt < 100; attempt++) {
      int rc = ioctl(g_fd, OVC_IOCTL_READ_DATA, &read_data);
      sync_data = (uint8_t)(read_data.data >> 24);
      if (sync_data == 0x00)
        continue;  // this word isn't informative...
      if (sync_data != 0x0d &&
          sync_data != 0x0a &&
          sync_data != 0xe9 &&
          sync_data != 0xaa &&
          sync_data != 0xca &&
          sync_data != 0x4a &&
          sync_data != 0x16 &&
          sync_data != 0x05)
      {
        // we need to bitslip the sync channel
        struct ovc_ioctl_bitslip bs;
        bs.channels = (imager_idx == 0 ? 0x10 : 0x200);  // only sync lane
        printf("bitslip(0x%02x)  saw 0x%02x on imager %d sync lane\n",
          (unsigned)bs.channels, (unsigned)sync_data, imager_idx);
        int rc = ioctl(g_fd, OVC_IOCTL_BITSLIP, &bs);
        if (rc) {
          printf("oh noes, weird rc from bitslip ioctl: %d\n", rc);
          return 1;
        }
        usleep(100);  // wait for the bitslip to bang through all the widgets
      }
      else {
        sync_ok = true;
        printf("sync channel OK: 0x%02x\n", sync_data);
        break;
      }
    }
    if (!sync_ok) {
      printf("oh noes, couldn't align sync channel :(\n");
      return 1;
    }
    printf("sync channel aligned OK\n");
    for (int channel = 0; channel < 4; channel++) {
      read_data.channel = channel + imager_idx * 4;
      bool channel_ok = false;
      for (int attempt = 0; attempt < 10000; attempt++) {
        ioctl(g_fd, OVC_IOCTL_READ_DATA, &read_data);
        ioctl(g_fd, OVC_IOCTL_READ_DATA, &read_data);
        sync_data = (uint8_t)(read_data.data >> 24);
        if (sync_data == 0xe9) {
          //printf("found sync word\n");
          uint8_t channel_data = (uint8_t)(read_data.data >> 16);
          if (channel_data == 0xe9) {
            channel_ok = true;
            break;
          }
          // channel data wasn't the training word 0xe9, so let's shift it
          struct ovc_ioctl_bitslip bs;
          bs.channels = 1 << (channel + imager_idx * 5);
          printf("imager %d lane %d: found 0x%02x. bitslip(0x%02x)\n",
            (int)imager_idx, channel,
            (unsigned)channel_data, (unsigned)bs.channels);
          int rc = ioctl(g_fd, OVC_IOCTL_BITSLIP, &bs);
          if (rc) {
            printf("oh noes, weird rc from bitslip ioctl: %d\n", rc);
            return 1;
          }
          usleep(100);  // wait for the bitslip to bang through all the widgets
        }
      }
      if (!channel_ok) {
        printf("oh noes, couldn't align channel %d\n", channel);
        return 1;
      }
      printf("channel %d aligned OK\n", channel);
    }
  }
  return 0;
}

int bitslip(int argc, char **argv)
{
  if (argc < 3)
    usage();
  struct ovc_ioctl_bitslip bs;
  bs.channels = atoi(argv[2]);
  printf("bitslip(%d)\n", (int)bs.channels);
  int rc = ioctl(g_fd, OVC_IOCTL_BITSLIP, &bs);
  printf("rc = %d\n", rc);
  return 0;
}

int pio_set(int argc, char **argv)
{
  if (argc < 4)
    usage();
  int index = atoi(argv[2]);
  int value = atoi(argv[3]);
  printf("pio_set(%d, %d)\n", index, value);
  struct ovc_pio_set pio_set;
  pio_set.pio_idx = index;
  pio_set.pio_state = value;
  int rc = ioctl(g_fd, OVC_IOCTL_PIO_SET, &pio_set);
  printf("rc = %d\n", rc);
  return 0;
}

bool write_imager_reg(
  const uint8_t imager_idx,
  const uint32_t reg_idx,
  const uint32_t reg_val)
{
  struct ovc_ioctl_spi_xfer spi_xfer;
  spi_xfer.dir = OVC_IOCTL_SPI_XFER_DIR_WRITE;
  spi_xfer.bus = imager_idx;
  spi_xfer.reg_addr = reg_idx;
  spi_xfer.reg_val = reg_val;
  int rc = ioctl(g_fd, OVC_IOCTL_SPI_XFER, &spi_xfer);
  if (rc != 0) {
    printf("oh no! error setting spi register %d to 0x%04x\n",
      (int)reg_idx, (unsigned)reg_val);
    return false;
  }
  return true;
}

bool configure_imager(const uint8_t i)
{
  if (!write_imager_reg(i,  32, 0x4008)) return false; // enable logic clock
  if (!write_imager_reg(i,  20, 0x0001)) return false; // enable LVDS clock input
  if (!write_imager_reg(i,   9, 0x0000)) return false; // release clkgen soft-reset
  if (!write_imager_reg(i,  32, 0x400a)) return false; // enable logic clock
  if (!write_imager_reg(i,  34, 0x0001)) return false; // enable logic blocks

  // magic register settings... don't ask questions.
  if (!write_imager_reg(i,  41, 0x08aa)) return false;
  if (!write_imager_reg(i,  42, 0x4110)) return false;
  if (!write_imager_reg(i,  43, 0x0008)) return false;
  if (!write_imager_reg(i,  65, 0x382b)) return false;
  if (!write_imager_reg(i,  66, 0x53c8)) return false;  // bias current
  if (!write_imager_reg(i,  67, 0x0665)) return false;
  if (!write_imager_reg(i,  68, 0x0088)) return false;  // lvds comm+diff level
  if (!write_imager_reg(i,  70, 0x1111)) return false;
  if (!write_imager_reg(i,  72, 0x0017)) return false;
  if (!write_imager_reg(i, 128, 0x4714)) return false;
  if (!write_imager_reg(i, 129, 0xa001)) return false;  // 8-bit mode
  if (!write_imager_reg(i, 171, 0x1002)) return false;
  if (!write_imager_reg(i, 175, 0x0080)) return false;
  if (!write_imager_reg(i, 176, 0x00e6)) return false;
  if (!write_imager_reg(i, 177, 0x0400)) return false;
  //if (!write_imager_reg(0, 192, 0x103c)) return 1;
  if (!write_imager_reg(i, 192, 0x100c)) return false;  // sequencer general config
  if (!write_imager_reg(i, 194, 0x0224)) return false;  // integration_control
  if (!write_imager_reg(i, 197, 0x0306)) return false;  // black_lines
  if (!write_imager_reg(i, 204, 0x01e1)) return false;  // set gain to 1.0
  if (!write_imager_reg(i, 207, 0x0000)) return false;  // ref_lines
  if (!write_imager_reg(i, 211, 0x0e49)) return false;
  if (!write_imager_reg(i, 215, 0x111f)) return false;
  if (!write_imager_reg(i, 216, 0x7f00)) return false;
  if (!write_imager_reg(i, 219, 0x0020)) return false;
  if (!write_imager_reg(i, 220, 0x3a28)) return false;
  if (!write_imager_reg(i, 221, 0x624d)) return false;
  if (!write_imager_reg(i, 222, 0x624d)) return false;
  if (!write_imager_reg(i, 224, 0x3e5e)) return false;
  if (!write_imager_reg(i, 227, 0x0000)) return false;
  if (!write_imager_reg(i, 250, 0x2081)) return false;
  if (!write_imager_reg(i, 384, 0xc800)) return false;
  if (!write_imager_reg(i, 384, 0xC800)) return false;
  if (!write_imager_reg(i, 385, 0xFB1F)) return false;
  if (!write_imager_reg(i, 386, 0xFB1F)) return false;
  if (!write_imager_reg(i, 387, 0xFB12)) return false;
  if (!write_imager_reg(i, 388, 0xF903)) return false;
  if (!write_imager_reg(i, 389, 0xF802)) return false;
  if (!write_imager_reg(i, 390, 0xF30F)) return false;
  if (!write_imager_reg(i, 391, 0xF30F)) return false;
  if (!write_imager_reg(i, 392, 0xF30F)) return false;
  if (!write_imager_reg(i, 393, 0xF30A)) return false;
  if (!write_imager_reg(i, 394, 0xF101)) return false;
  if (!write_imager_reg(i, 395, 0xF00A)) return false;
  if (!write_imager_reg(i, 396, 0xF24B)) return false;
  if (!write_imager_reg(i, 397, 0xF226)) return false;
  if (!write_imager_reg(i, 398, 0xF001)) return false;
  if (!write_imager_reg(i, 399, 0xF402)) return false;
  if (!write_imager_reg(i, 400, 0xF001)) return false;
  if (!write_imager_reg(i, 401, 0xF402)) return false;
  if (!write_imager_reg(i, 402, 0xF001)) return false;
  if (!write_imager_reg(i, 403, 0xF401)) return false;
  if (!write_imager_reg(i, 404, 0xF007)) return false;
  if (!write_imager_reg(i, 405, 0xF20F)) return false;
  if (!write_imager_reg(i, 406, 0xF20F)) return false;
  if (!write_imager_reg(i, 407, 0xF202)) return false;
  if (!write_imager_reg(i, 408, 0xF006)) return false;
  if (!write_imager_reg(i, 409, 0xEC02)) return false;
  if (!write_imager_reg(i, 410, 0xE801)) return false;
  if (!write_imager_reg(i, 411, 0xEC02)) return false;
  if (!write_imager_reg(i, 412, 0xE801)) return false;
  if (!write_imager_reg(i, 413, 0xEC02)) return false;
  if (!write_imager_reg(i, 414, 0xC801)) return false;
  if (!write_imager_reg(i, 415, 0xC800)) return false;
  if (!write_imager_reg(i, 416, 0xC800)) return false;
  if (!write_imager_reg(i, 417, 0xCC02)) return false;
  if (!write_imager_reg(i, 418, 0xC801)) return false;
  if (!write_imager_reg(i, 419, 0xCC02)) return false;
  if (!write_imager_reg(i, 420, 0xC801)) return false;
  if (!write_imager_reg(i, 421, 0xCC02)) return false;
  if (!write_imager_reg(i, 422, 0xC805)) return false;
  if (!write_imager_reg(i, 423, 0xC800)) return false;
  if (!write_imager_reg(i, 424, 0x0030)) return false;
  if (!write_imager_reg(i, 425, 0x207C)) return false;
  if (!write_imager_reg(i, 426, 0x2071)) return false;
  if (!write_imager_reg(i, 427, 0x0074)) return false;
  if (!write_imager_reg(i, 428, 0x107F)) return false;
  if (!write_imager_reg(i, 429, 0x1072)) return false;
  if (!write_imager_reg(i, 430, 0x1074)) return false;
  if (!write_imager_reg(i, 431, 0x0076)) return false;
  if (!write_imager_reg(i, 432, 0x0031)) return false;
  if (!write_imager_reg(i, 433, 0x21BB)) return false;
  if (!write_imager_reg(i, 434, 0x20B1)) return false;
  if (!write_imager_reg(i, 435, 0x20B1)) return false;
  if (!write_imager_reg(i, 436, 0x00B1)) return false;
  if (!write_imager_reg(i, 437, 0x10BF)) return false;
  if (!write_imager_reg(i, 438, 0x10B2)) return false;
  if (!write_imager_reg(i, 439, 0x10B4)) return false;
  if (!write_imager_reg(i, 440, 0x00B1)) return false;
  if (!write_imager_reg(i, 441, 0x0030)) return false;
  if (!write_imager_reg(i, 442, 0x0030)) return false;
  if (!write_imager_reg(i, 443, 0x217B)) return false;
  if (!write_imager_reg(i, 444, 0x2071)) return false;
  if (!write_imager_reg(i, 445, 0x2071)) return false;
  if (!write_imager_reg(i, 446, 0x0074)) return false;
  if (!write_imager_reg(i, 447, 0x107F)) return false;
  if (!write_imager_reg(i, 448, 0x1072)) return false;
  if (!write_imager_reg(i, 449, 0x1074)) return false;
  if (!write_imager_reg(i, 450, 0x0076)) return false;
  if (!write_imager_reg(i, 451, 0x0031)) return false;
  if (!write_imager_reg(i, 452, 0x20BB)) return false;
  if (!write_imager_reg(i, 453, 0x20B1)) return false;
  if (!write_imager_reg(i, 454, 0x20B1)) return false;
  if (!write_imager_reg(i, 455, 0x00B1)) return false;
  if (!write_imager_reg(i, 456, 0x10BF)) return false;
  if (!write_imager_reg(i, 457, 0x10B2)) return false;
  if (!write_imager_reg(i, 458, 0x10B4)) return false;
  if (!write_imager_reg(i, 459, 0x00B1)) return false;
  if (!write_imager_reg(i, 460, 0x0030)) return false;
  if (!write_imager_reg(i, 461, 0x0030)) return false;
  if (!write_imager_reg(i, 462, 0x207C)) return false;
  if (!write_imager_reg(i, 463, 0x2071)) return false;
  if (!write_imager_reg(i, 464, 0x0073)) return false;
  if (!write_imager_reg(i, 465, 0x017A)) return false;
  if (!write_imager_reg(i, 466, 0x0078)) return false;
  if (!write_imager_reg(i, 467, 0x1074)) return false;
  if (!write_imager_reg(i, 468, 0x0076)) return false;
  if (!write_imager_reg(i, 469, 0x0031)) return false;
  if (!write_imager_reg(i, 470, 0x21BB)) return false;
  if (!write_imager_reg(i, 471, 0x20B1)) return false;
  if (!write_imager_reg(i, 472, 0x20B1)) return false;
  if (!write_imager_reg(i, 473, 0x00B1)) return false;
  if (!write_imager_reg(i, 474, 0x10BF)) return false;
  if (!write_imager_reg(i, 475, 0x10B2)) return false;
  if (!write_imager_reg(i, 476, 0x10B4)) return false;
  if (!write_imager_reg(i, 477, 0x00B1)) return false;
  if (!write_imager_reg(i, 478, 0x0030)) return false;
  if (!write_imager_reg(i, 206, 0x077f)) return false;
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
int main(int argc, char **argv)
{
  if (argc < 2)
    usage();
  const char *cmd = argv[1];
  g_fd = open("/dev/ovc", O_RDWR);
  if (g_fd < 0) {
    printf("oh noes. couldn't open /dev/ovc  :(\n");
    return 1;
  }
  signal(SIGINT, sigint_handler);
  if (!strcmp(cmd, "spi_read"))
    return spi_read(argc, argv);
  else if (!strcmp(cmd, "spi_write"))
    return spi_write(argc, argv);
  else if (!strcmp(cmd, "pio_set"))
    return pio_set(argc, argv);
  else if (!strcmp(cmd, "configure_imagers"))
    return configure_imagers();
  else if (!strcmp(cmd, "dma_test"))
    return dma_test(argc, argv);
  else if (!strcmp(cmd, "read_data"))
    return read_data(argc, argv);
  else if (!strcmp(cmd, "bitslip"))
    return bitslip(argc, argv);
  else if (!strcmp(cmd, "align"))
    return align();
  else if (!strcmp(cmd, "imu_read"))
    return imu_read(argc, argv);
  else if (!strcmp(cmd, "imu_configure"))
    return imu_configure();
  else if (!strcmp(cmd, "imu_stream"))
    return imu_stream();
  else if (!strcmp(cmd, "enable_reg_ram"))
    return enable_reg_ram();
  else {
    printf("unknown command: %s\n", cmd);
    usage();
  }
  return 0;
}

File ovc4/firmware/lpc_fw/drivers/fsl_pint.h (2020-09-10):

/*
 * Copyright (c) 2016, Freescale Semiconductor, Inc.
 * Copyright 2016-2017 NXP
 * All rights reserved.
 *
 * SPDX-License-Identifier: BSD-3-Clause
 */

#ifndef _FSL_PINT_H_
#define _FSL_PINT_H_

#include "fsl_common.h"

/*!
 * @addtogroup pint_driver
 * @{
 */

/*! @file */

/*******************************************************************************
 * Definitions
 ******************************************************************************/

/*! @name Driver version */
/*@{*/
#define FSL_PINT_DRIVER_VERSION (MAKE_VERSION(2, 1, 6)) /*!< Version 2.1.6 */
/*@}*/

/* Number of interrupt line supported by PINT */
#define PINT_PIN_INT_COUNT 8U

/* Number of interrupt line supported by SECURE PINT */
#define SEC_PINT_PIN_INT_COUNT 2U

/* Number of input sources supported by PINT */
#define PINT_INPUT_COUNT 8U

/* PININT Bit slice source register bits */
#define PININT_BITSLICE_SRC_START 8U
#define PININT_BITSLICE_SRC_MASK 7U

/* PININT Bit slice configuration register bits */
#define PININT_BITSLICE_CFG_START 8U
#define PININT_BITSLICE_CFG_MASK 7U
#define PININT_BITSLICE_ENDP_MASK 7U

#define PINT_PIN_INT_LEVEL 0x10U
#define PINT_PIN_INT_EDGE 0x00U
#define PINT_PIN_INT_FALL_OR_HIGH_LEVEL 0x02U
#define PINT_PIN_INT_RISE 0x01U
#define PINT_PIN_RISE_EDGE (PINT_PIN_INT_EDGE | PINT_PIN_INT_RISE)
#define PINT_PIN_FALL_EDGE (PINT_PIN_INT_EDGE | PINT_PIN_INT_FALL_OR_HIGH_LEVEL)
#define PINT_PIN_BOTH_EDGE (PINT_PIN_INT_EDGE | PINT_PIN_INT_RISE | PINT_PIN_INT_FALL_OR_HIGH_LEVEL)
#define PINT_PIN_LOW_LEVEL (PINT_PIN_INT_LEVEL)
#define PINT_PIN_HIGH_LEVEL (PINT_PIN_INT_LEVEL | PINT_PIN_INT_FALL_OR_HIGH_LEVEL)

/*! @brief PINT Pin Interrupt enable type */
typedef enum _pint_pin_enable
{
    kPINT_PinIntEnableNone      = 0U,                 /*!< Do not generate Pin Interrupt */
    kPINT_PinIntEnableRiseEdge  = PINT_PIN_RISE_EDGE, /*!< Generate Pin Interrupt on rising edge */
    kPINT_PinIntEnableFallEdge  = PINT_PIN_FALL_EDGE, /*!< Generate Pin Interrupt on falling edge */
    kPINT_PinIntEnableBothEdges = PINT_PIN_BOTH_EDGE, /*!< Generate Pin Interrupt on both edges */
    kPINT_PinIntEnableLowLevel  = PINT_PIN_LOW_LEVEL, /*!< Generate Pin Interrupt on low level */
    kPINT_PinIntEnableHighLevel = PINT_PIN_HIGH_LEVEL /*!< Generate Pin Interrupt on high level */
} pint_pin_enable_t;

/*! @brief PINT Pin Interrupt type */
typedef enum _pint_int
{
    kPINT_PinInt0 = 0U, /*!< Pin Interrupt  0 */
#if (FSL_FEATURE_PINT_NUMBER_OF_CONNECTED_OUTPUTS > 1U)
    kPINT_PinInt1 = 1U, /*!< Pin Interrupt  1 */
#endif
#if (FSL_FEATURE_PINT_NUMBER_OF_CONNECTED_OUTPUTS > 2U)
    kPINT_PinInt2 = 2U, /*!< Pin Interrupt  2 */
#endif
#if (FSL_FEATURE_PINT_NUMBER_OF_CONNECTED_OUTPUTS > 3U)
    kPINT_PinInt3 = 3U, /*!< Pin Interrupt  3 */
#endif
#if (FSL_FEATURE_PINT_NUMBER_OF_CONNECTED_OUTPUTS > 4U)
    kPINT_PinInt4 = 4U, /*!< Pin Interrupt  4 */
#endif
#if (FSL_FEATURE_PINT_NUMBER_OF_CONNECTED_OUTPUTS > 5U)
    kPINT_PinInt5 = 5U, /*!< Pin Interrupt  5 */
#endif
#if (FSL_FEATURE_PINT_NUMBER_OF_CONNECTED_OUTPUTS > 6U)
    kPINT_PinInt6 = 6U, /*!< Pin Interrupt  6 */
#endif
#if (FSL_FEATURE_PINT_NUMBER_OF_CONNECTED_OUTPUTS > 7U)
    kPINT_PinInt7 = 7U, /*!< Pin Interrupt  7 */
#endif
#if (FSL_FEATURE_SECPINT_NUMBER_OF_CONNECTED_OUTPUTS > 0U)
    kPINT_SecPinInt0 = 8U, /*!< Secure Pin Interrupt  0 */
#endif
#if (FSL_FEATURE_SECPINT_NUMBER_OF_CONNECTED_OUTPUTS > 1U)
    kPINT_SecPinInt1 = 9U, /*!< Secure Pin Interrupt  1 */
#endif
} pint_pin_int_t;

/*! @brief PINT Pattern Match bit slice input source type */
typedef enum _pint_pmatch_input_src
{
    kPINT_PatternMatchInp0Src = 0U, /*!< Input source 0 */
    kPINT_PatternMatchInp1Src = 1U, /*!< Input source 1 */
    kPINT_PatternMatchInp2Src = 2U, /*!< Input source 2 */
    kPINT_PatternMatchInp3Src = 3U, /*!< Input source 3 */
    kPINT_PatternMatchInp4Src = 4U, /*!< Input source 4 */
    kPINT_PatternMatchInp5Src = 5U, /*!< Input source 5 */
    kPINT_PatternMatchInp6Src = 6U, /*!< Input source 6 */
    kPINT_PatternMatchInp7Src = 7U, /*!< Input source 7 */
} pint_pmatch_input_src_t;
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

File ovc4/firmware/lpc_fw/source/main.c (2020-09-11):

/*
 * Copyright (c) 2015 - 2016, Freescale Semiconductor, Inc.
 * Copyright 2016 - 2017, 2019 NXP
 * All rights reserved.
 *
 * SPDX-License-Identifier: BSD-3-Clause
 */
#include "fsl_device_registers.h"
#include "clock_config.h"
#include "board.h"

#include "ovc_hw_defs.h"

#include <stdio.h>
#include <stdlib.h>

#include "usb_device_config.h"
#include "usb.h"
#include "usb_device.h"

#include "usb_device_ch9.h"
#include "fsl_debug_console.h"

#include "camera_i2c.h"
#include "camera_gpio.h"
#include "imu_spi.h"
#include "usb_packetdef.h"

#include "usb_device_descriptor.h"

#if ((defined FSL_FEATURE_SOC_USBPHY_COUNT) && (FSL_FEATURE_SOC_USBPHY_COUNT > 0U))
#include "usb_phy.h"
#endif

void BOARD_InitHardware(void);
void USB_DeviceClockInit(void);
void USB_DeviceIsrEnable(void);
#if USB_DEVICE_CONFIG_USE_TASK
void USB_DeviceTaskFn(void *deviceHandle);
#endif

void BOARD_DbgConsole_Deinit(void);
void BOARD_DbgConsole_Init(void);
#include "pin_mux.h"
#include <stdbool.h>
#include "fsl_power.h"
/*******************************************************************************
 * Definitions
 ******************************************************************************/

/*******************************************************************************
 * Variables
 ******************************************************************************/
/* Data structure of virtual com device */
usb_device_handle usb_handle; /* USB device handle. */

usb_tx_packet_t tx_packet;
usb_rx_packet_t rx_packet;
volatile int packet_received = 0;

/* Data buffer for receiving and sending*/
USB_DMA_NONINIT_DATA_ALIGN(USB_DATA_ALIGN_SIZE) static uint8_t s_SetupOutBuffer[8];
/*******************************************************************************
 * Prototypes
 ******************************************************************************/

/*******************************************************************************
 * Code
 ******************************************************************************/
void USB1_IRQHandler(void)
{
    USB_DeviceLpcIp3511IsrFunction(usb_handle);
}

void USB_DeviceClockInit(void)
{
    /* enable USB IP clock */
    CLOCK_EnableUsbhs0PhyPllClock(kCLOCK_UsbPhySrcExt, BOARD_XTAL0_CLK_HZ);
    CLOCK_EnableUsbhs0DeviceClock(kCLOCK_UsbSrcUnused, 0U);
    USB_EhciPhyInit(USB_CONTROLLER_ID, BOARD_XTAL0_CLK_HZ, NULL);
    for (int i = 0; i < FSL_FEATURE_USBHSD_USB_RAM; i++)
    {
        ((uint8_t *)FSL_FEATURE_USBHSD_USB_RAM_BASE_ADDRESS)[i] = 0x00U;
    }

}
void USB_DeviceIsrEnable(void)
{
    uint8_t irqNumber;
    uint8_t usbDeviceIP3511Irq[] = USBHSD_IRQS;
    irqNumber                    = usbDeviceIP3511Irq[USB_CONTROLLER_ID - kUSB_ControllerLpcIp3511Hs0];
    /* Install isr, set priority, and enable IRQ. */
    NVIC_SetPriority((IRQn_Type)irqNumber, USB_DEVICE_INTERRUPT_PRIORITY);
    EnableIRQ((IRQn_Type)irqNumber);
}
/*!
 * @brief Bulk in pipe callback function.
 *
 * This function serves as the callback function for bulk in pipe.
 *
 * @param handle The USB device handle.
 * @param message The endpoint callback message
 * @param callbackParam The parameter of the callback.
 *
 * @return A USB error code or kStatus_USB_Success.
 */
usb_status_t USB_DeviceCdcAcmBulkIn(usb_device_handle handle,
                                    usb_device_endpoint_callback_message_struct_t *message,
                                    void *callbackParam)
{
    usb_status_t error = kStatus_USB_Error;

    if ((message->length != 0) && (!(message->length % HS_BULK_OUT_PACKET_SIZE)))
    {
        /* If the last packet is the size of endpoint, then send also zero-ended packet,
         ** meaning that we want to inform the host that we do not have any additional
         ** data, so it can flush the output.
         */
        USB_DeviceSendRequest(handle, USB_BULK_IN_ENDPOINT, NULL, 0);
    }
    else if ((message->buffer != NULL) || ((message->buffer == NULL) && (message->length == 0)))
    {
        /* User: add your own code for send complete event */
        /* Schedule buffer for next receive event */
        USB_DeviceRecvRequest(handle, USB_BULK_OUT_ENDPOINT, rx_packet.data, HS_BULK_OUT_PACKET_SIZE);
    }
    return error;
}

/*!
 * @brief Bulk out pipe callback function.
 *
 * This function serves as the callback function for bulk out pipe.
 *
 * @param handle The USB device handle.
 * @param message The endpoint callback message
 * @param callbackParam The parameter of the callback.
 *
 * @return A USB error code or kStatus_USB_Success.
 */
usb_status_t USB_DeviceCdcAcmBulkOut(usb_device_handle handle,
                                     usb_device_endpoint_callback_message_struct_t *message,
                                     void *callbackParam)
{
    packet_received++;
    usb_status_t error = kStatus_USB_Success;

    if (!message->length)
    {
        /* Schedule buffer for next receive event */
        USB_DeviceRecvRequest(handle, USB_BULK_OUT_ENDPOINT, rx_packet.data, HS_BULK_OUT_PACKET_SIZE);
    }
    return error;
}

/*!
 * @brief Get the setup packet buffer.
 *
 * This function provides the buffer for setup packet.
 *
 * @param handle The USB device handle.
 * @param setupBuffer The pointer to the address of setup packet buffer.
 *
 * @return A USB error code or kStatus_USB_Success.
 */
usb_status_t USB_DeviceGetSetupBuffer(usb_device_handle handle, usb_setup_struct_t **setupBuffer)
{
    static uint32_t cdcVcomSetup[2];
    if (NULL == setupBuffer)
    {
        return kStatus_USB_InvalidParameter;
    }
    *setupBuffer = (usb_setup_struct_t *)&cdcVcomSetup;
    return kStatus_USB_Success;
}
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

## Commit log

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2016-01-28 update 3d model paths and created first 3D renderings
    [Artix7Bank14.sch, Artix7Bank15.sch, Artix7Bank16.sch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]
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2016-01-28 added 3d models and exported complete board as step
    [HarleyFullMC.kicad_pcb]
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2016-01-30 added via for better decoupling + changed IMU power supply
    [HarleyFullMC.kicad_pcb, HarleyFullMC.sch]
2016-01-30 fixed things based on Harley Notes, not ready for fab yet
    [Artix7Bank14.sch, Artix7Bank15.sch, Artix7Bank16.sch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]
2016-02-01 fixed footprints and rerouted imager
    [HarleyFullMC.csv, HarleyFullMC.kicad_pcb, HarleyFullMC.sch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]
2016-02-02 switched to lever 3 stack, changed USB shielding capacitor, cleaned some traces
    [Artix7Bank14.sch, HarleyFullMC.csv, HarleyFullMC.kicad_pcb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]
2016-02-03 backup before attempting to solve Mask/Paste issue
    [HarleyFullMC.kicad_pcb]
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2016-02-03 updated step file + copied new version of stepup script from osrf_hw
    [ksu-config.cfg]
2016-02-04 fixed no net vias under imager chip
    [HarleyFullMC.kicad_pcb]
2016-02-05 set global pad-to-mask clearance to 0.5mm, and repour polygons
    [HarleyFullMC.kicad_pcb]
2016-02-05 fixed net of free vias + remove vias too close to each other
    [HarleyFullMC.kicad_pcb]
2016-02-08 a bit of pcb cleanup and fab ZIP generation script tweaks, and README fab/asm notes
    [DDR3.sch, HarleyFullMC.kicad_pcb]
2016-02-08 updated part number for available components and generated archive for quote
    [Artix7Bank14.sch, Artix7Bank15.sch, Artix7Bank16.sch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]
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2016-02-09 added missing capacitors for XC7A100T + updated BOM
    [Artix7Bank14.sch, Artix7Bank15.sch, Artix7Bank16.sch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]
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2016-02-10 first routing of connection board on 6 layers stackup from sunstone
    [HarleyConnect1Bro.kicad_pcb, HarleyConnect1Bro.sch]
2016-02-11 first routing of Trinocular connector board. Length and skewness tuned. using 6 layer standard stackup from sunstone. Added extensions for mounting holes
    [HarleyConnect2Bros.kicad_pcb, HarleyConnect2Bros.sch]
2016-02-11 fixed skewness and pass DRC for Connect1Bro board, updated connector footprint
    [HarleyConnect1Bro.kicad_pcb, HarleyConnect1Bro.sch]
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2016-02-13 updated footprints and 3d models, huge diff but very few actual changes
    [HarleyConnect1Bro.kicad_pcb, HarleyConnect1Bro.sch, HarleyConnect2Bros.kicad_pcb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]
2016-02-20 started fixing all the issues from revA in a new project
    [Artix7Bank14.sch, Artix7Bank15.sch, Artix7Bank16.sch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]
2016-02-20 rename folder to match project name + fixed issues references in fixlistRevb.txt file
    [Artix7Bank14.sch, Artix7Bank15.sch, Artix7Bank16.sch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]
2016-02-22 update fixlist and port all the changes to HarleyFullMCrevB project
    [Artix7Bank14.sch, Artix7Bank15.sch, Artix7Bank16.sch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]
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2016-03-25 modified copper zones to reduce weight and remove discontinuities on reference planes of LVDS lanes
    [HarleyConnect2Bros.kicad_pcb]
2016-04-05 add Imager IBIAS resistor to fixlist
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2016-04-26 reorder JTAG signal to match Xilinx connector pinout, add cam RST signal to connector
    [Artix7Bank14.sch, Artix7Bank15.sch, Artix7Bank16.sch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]
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2016-04-28 Fixed LVDS lane bank assignment and added missing signals. Routing with connector on top
    [Artix7Bank14.sch, Artix7Bank15.sch, Artix7Bank16.sch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]
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2016-05-04 added missing termination resistor and tied input pins to gnd
    [HarleyTandem.kicad_pcb, HarleyTandem.sch, IMU.sch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]
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2016-05-06 tuned skewness, fixed silkscreen and reported lvds lanes length in lvds_lengths.csv
    [HarleyGhostRider.kicad_pcb, lvds_lengths.csv]
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2016-05-11 tweak library search paths a bit so that if osrf_hw and opencam are sibling checkouts, a relative path will find the eeschema symbols
    [HarleyTandem.sch]
2016-05-11 fixed JTAG pinout
    [HarleyGhostRider.kicad_pcb, HarleyGhostRider.sch, HarleyTandem.kicad_pcb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]
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2016-05-11 checked component availability and replaced the ones that cannot be sources
    [HarleyTandem.csv, HarleyTandem.sch, Imagers.sch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]
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2016-05-11 tieds unused level shifter pins to GND, updated BOM, just missing VectorNav information
    [HarleyIMU.csv, HarleyIMU.kicad_pcb, HarleyIMU.sch]
2016-05-12 Swaped Pinout JTAG connector + added prob header for power supplies
    [HarleyGhostRider.kicad_pcb, HarleyGhostRider.sch, HarleyTandem.kicad_pcb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]
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2016-05-12 fixed level shifter footprint
    [HarleyTandem.kicad_pcb, LevelShifters.sch]
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2016-05-14 [HarleyTandem]removed bottom paste and useless sikscreen, fixed U2 connection, rounded corners and addresse other remarks from Morgans review
    [HarleyTandem.kicad_pcb, HarleyTandem.sch, IMU.sch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]
2016-05-14 moved avery component out of lensholder way, need to work on capacitor reference silkscreen
    [HarleyTandem.kicad_pcb]
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2016-05-17 fixed LDO digikey link and Mounting holes size/silkscreen
    [HarleyIMU.csv, HarleyIMU.kicad_pcb, HarleyIMU.sch]
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2016-05-17 tweak library paths and remove the edge-mounted JTAG connector from the SMD xy file
    [HarleyTandem.kicad_pcb]
2016-05-17 increase clearance around mounting holes and a few trivial cleanups
    [HarleyTandem.kicad_pcb]
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2018-03-29 fix IMU time jumps when the image thread moves the hw/sw time offset
    [ovc.cpp]
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2018-05-01 initial route of stereo board complete. lots of cleanup to do now.
    [fpga_io.sch, fpga_power.sch, ovc2_mobo.kicad_pcb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]
2018-05-02 start routing high speed on mobo and swap some pcie lane polarity
    [fpga_pcie.sch, jetson_sdcard.sch, jetson_usb.sch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]
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2018-05-09 fix mobo BOM and start working on fixing stereo power supply to use available parts
    [jetson_hdmi.sch, jetson_uarts.sch, ovc2_stereo.kicad_pcb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]
2018-05-10 working on stereo board power supply design around mpm3630 since tps82130 are out of stock
    [jetson_usb.sch, ovc2_stereo.kicad_pcb, power.sch]
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2018-05-15 fix some capacitor part numbers
    [jetson_hdmi.sch, jetson_pcie.sch, jetson_sdcard.sch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]
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2018-07-18 kernel fixups, working towards dual-chip SPI
    [ovc2.cpp, ovc2_core.c]
2018-07-20 fixme annotation for rev.A stereo boards
    [fpga_config.sch, fpga_io.sch, fpga_pcie.sch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]
2018-07-31 imager spi bus 2 works ok after rework
    [ovc2.cpp]
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2018-08-14 IMU byteswaps in hardware so it reads un-swapped on little-endian machines
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2018-08-29 reduce lvds current to avoid almost-overdriving the Cyclone 10 GX LVDS receiver
    [ovc2.cpp]
2018-09-14 starting to add power protection IC and clean up power input debris
    [power.sch]
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2018-09-20 [GhostRider] fixed part number of some passives and updated BOM
    [Artix7Bank15.sch, Artix7Config.sch, DDR3.sch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]
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2018-09-20 added reset pullup, removed unused components
    [HarleyuIMU2.kicad_pcb, HarleyuIMU2.sch]
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2018-09-20 revert crazy planes, use beads and caps
    [HarleyTandem.sch, HarleyTandemRevB.kicad_pcb, IMU.sch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]
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2018-09-20 upgrade kicad version and fix imager footprints
    [HarleyTandem.sch, IMU.sch, Imagers.sch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]
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2018-10-10 implement tps2660 input power protection for under/over/reverse polarity
    [jetson_power.sch, ovc2_mobo.kicad_pcb, power.sch]
2018-10-10 fix ethernet pinout
    [jetson_enet.sch, ovc2_mobo.kicad_pcb]
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2018-10-11 move power/reset/recovery switches to more logical locations. add fan connector and interface components
    [jetson_jtag.sch, jetson_power.sch, ovc2_mobo.kicad_pcb]
2018-10-12 fix outstanding problem items: buffer i/o, fix ethernet skew, etc.
    [jetson_gpio.sch, jetson_power.sch, ovc2_mobo.kicad_pcb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]
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2018-10-15 clean up schematics a bit. improve clearance around fan connector
    [jetson_pcie.sch, ovc2_mobo.kicad_pcb, ovc2_mobo.sch]
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2018-10-15 fix cam2 miso/mosi swap
    [fpga_config.sch, fpga_io.sch, fpga_pcie.sch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]
2018-10-15 remove solder paste from IMU modules that have to be hand-soldered. Improve silkscreen notes for them.
    [ovc2_stereo.kicad_pcb]
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2018-10-16 reduce imager footprints and use smaller lens holders. start shuffling capacitors and routes around to deal with those changes.
    [imagers.sch, imu.sch, ovc2_stereo.kicad_pcb]
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2018-10-16 move lvds routes on left imager to bottom side to avoid impedance mismatch with metal lens holder on top side. start working through ripple effects of doing that...
    [fpga_io.sch, ovc2_stereo.kicad_pcb]
2018-10-17 moving jtag and fpga configuration interface to test points instead of 100mil header since basically nobody else cares about them
    [fpga_io.sch, ovc2_stereo.kicad_pcb]
2018-10-17 routing new placement of fpga config header and pcie reset translator
    [fpga_io.sch, ovc2_stereo.kicad_pcb]
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2018-10-18 cleaning up routing, working left to right across the board. creating new buffered i/o headers where possible.
    [fpga_io.sch, imu.sch, ovc2_stereo.kicad_pcb]
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2018-10-20 clean up RHS imager routing from congestion issues with small lens mount.
    [fpga_io.sch, imagers.sch, imu.sch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]
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2018-10-21 finish north expansion header. start exposing east imager configuration interface to test points.
    [fpga_io.sch, imagers.sch, ovc2_stereo.kicad_pcb]
2018-10-22 all layout FIXME items are done now.
    [fpga_io.sch, imagers.sch, ovc2_stereo.kicad_pcb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]
2018-10-22 fix dowel pin location on lens holders and clean up schematics/layout some more
    [fpga_io.sch, ovc2_stereo.kicad_pcb, power.sch]
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2018-10-23 put mounting hole between micro-usb and power connectors on mobo to improve spacing and allow connectors to actually fit...
    [bom.csv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]
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2018-11-14 fix up ovc scripts to not refer to opencam. fire flash for 1ms beyond exposure, for testing
    [ovc.cpp]
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2019-01-23 Shifted TE0820 module to make space for connectors, fixed library paths
    [imagers.sch, misc.sch, ovc3.kicad_pcb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]
2019-01-23 Fixed SD power to 3.3V
    [misc.sch]
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2019-01-26 ovc3a camera pcb work
    * ignore fp-info-cache files
    * reduce size of enet led resistors to 0403.
    * route enet and micro-sd interfaces
    * align lens holders to 90 degrees
    * push outer imagers down a bit to reduce width of pcb to 138mm
    [misc.sch, ovc3.kicad_pcb]
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2019-02-12 Added missing library and fixed device names
    [te0820.sch]
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2019-03-04 place/route progress
    * rotate imagers 180 degrees
    * re-route east imager
    * assign east 1v2-1v8 outbound shifter signals
    * move IMU chip to east side of board
    * power plane cleanup on east side
    [imu.sch, ovc3.kicad_pcb, te0820.sch]
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2019-03-08 Routed all imagers, completed power regulation circuitry, routed GPIO, UART and JTAG
    [misc.sch, ovc3.kicad_pcb, ovc3.sch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]
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2019-03-18 Minor replacement and reroute of bonus camera
    [ovc3.kicad_pcb, te0820.sch]
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2019-04-15 hacking on backpack board. also add camera FIXME note
    [backpack.kicad_pcb, backpack.sch, te0820.sch]
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2019-07-04 add tx/rx LEDs to the root console USB-UART converter and add silkscreen labels
    [backpack.kicad_pcb, backpack.sch]
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2019-08-19 Add frame_id and remove redundant variable
    The IMU message is missing a frame_id, so we include it.
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2019-09-02 Refactor Image and IMU Publishers
    The previous method of publishing IMU messages led to a possible lag in the updating of the shared time accessed by the Image Publishers. This leads to some images getting sent with duplicate timestamps, which can break some algorithms.
    This issue was solved by splitting the IMU reading and time updating tasks into separate threads, and by using a condition variable to signal when a new sample has been read.
    This in effect allows the image timestamps to update quickly, without risk of delay due to IMU readings, which would originally lead to duplicate image timestamps occuring if the delay is too great.
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2019-09-06 Added hack to remove warnings from spidev in device-tree
    "For some reason" when the second spidev device was added USB bringup in "some" machines became very long (ranging from 1 minute to 30 minutes). Removing spidev from being listed directly in the device tree seems to fix it, as well as removing warnings printed in the kernel log at every boot.
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2019-09-20 add bulk cap to 1v2 and skew length corrections to mipi lines
    [external_camera.kicad_pcb, external_camera.sch]
2019-09-20 Added possibility of shorting I2C and only using one for both sensors (reduce number of I2C devices)
    [external_camera.kicad_pcb, external_camera.sch, external_camera_bom_A.csv]
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2019-11-07 Fixed VDMA bug with shared I2C devices, addede multithreaded publisher for bonus cameras
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2019-11-25 Create hardware for ovc3b from ovc3a
    Fix swapped pins and wrong level shifter direction
    [bom.csv, bonus_cameras.sch, imagers.sch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]
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2019-12-12 Fixed silkscreen
    [ovc3.kicad_pcb]
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2020-01-09 move sdio level shifter to top side. migrate aux header towards west side.
    [misc.sch, ovc3.kicad_pcb, te0820.sch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]
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2020-02-21 Fixed TPS2121 footprint and layout
    [ovc3.kicad_pcb, usb3.sch]
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2020-05-12 Fixed pin assignment of MCU
    [cameras.kicad_sch, interfaces.kicad_sch, mcu.kicad_sch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]
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2020-05-20 WIP reworking power logic
    [cameras.kicad_sch, interfaces.kicad_sch, mcu.kicad_sch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]
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2020-05-26 Increase voltage of 1.8V regulator to avoid MCU brownout
    [cameras.kicad_sch, interfaces.kicad_sch, mcu.kicad_sch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]
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2020-06-16 Lots of improvements and fixes to routing
    [cameras.kicad_sch, interfaces.kicad_sch, mcu.kicad_sch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]
2020-06-22 Minor fixes
    [cameras.kicad_sch, interfaces.kicad_sch, mcu.kicad_sch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]
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2020-07-17 Fix BOM resistor value
    [bom.csv, cameras.kicad_sch, interfaces.kicad_sch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]
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2020-09-10 Fix picam probe logic
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2020-09-10 WIP PI HQ camera (not working yet)
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2020-09-10 Fix memory leak, get all sensor modes
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2020-09-10 Fix endianness of multibyte I2C transactions
2020-09-10 Implement hard reset on powerup / powerdown
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2021-03-30 Add kicad project for OVC5 (#36)
    * Start placing components
    * Finish main schematics, start placing
    * Place and route USB and MIPI lanes
    * Finished most placing and routing
    * Finish placement and routing
    * Add parts for BOM
    * Routing and FPGA pin assignment optimizations
    Also fixed some pins that were NC by accident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
    [BOM.csv, cameras.kicad_sch, enclustra_module.kicad_sch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]
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2021-04-13 Fix MIPI IO bank being at wrong voltage (#45)
    * Fix MIPI IO bank being at wrong voltage
    * Removed stray via
    * Added fabrication files
    [BOM.csv, cameras.kicad_sch, enclustra_module.kicad_sch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]
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2021-04-27 ROS Drivers for OVC5 (#46)
    * ROS1 driver for ovc
    * libovc
    * libovc based ros drivers
    * Default app uses libovc
    * Draw image wrt screen width
    * Fixed color issue and added makefile for testing convenience
    * Remove iostream
    * Dynamic config document
    * Dynamic re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
    [Params.cfg]
2021-07-06 OVC3B pinout (#52)
    * Pinout converted from OVC3a to OVC3b
    * Update README.md with pinout of OVC3a and 3b
    * Fixed constraints for GPIO18 and GPIO19
    * Created a root README for OVC3
    * Update zusys with new pinout
    * Improved README with steps for FSBL and PMUFW for ovc3 firmware
    * Add comments regarding GPIOs for OVC3
    * Booting with the vectornav_carrier AND usb connection may halt bootloader in OVC3. Add note in README.md.
    * Move setup and calibration for OVC into main README.md
    * Add instructions for PetaLinux generation
    * Fixed typo in EMIO title for ovc3
    * Add clarification to create boot image for ovc3
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2021-07-23 OVC5 Carrier Firmware (#54)
    * WIP Vivado project for the carrier board
    * Swap 0/1 inputs
    * Update petalinux config
    * Update device tree
    * dhcpd starts correctly on boot, USB gadget is hot-pluggable
    * uio device mem location output
    * Triggers are now driver via GPIO as TRIG0 cannot be configured as an input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
    [config.yaml, debug_constraints.xdc, gpio_driver.cpp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]
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2021-08-12 Imager Datatype Passthrough (#59)
    * Images now transmitted with color format
    * Workaround for GCC compiler bug
    * Correcting color map keys and adding documentation.
    * Fix string issues
    * Grab correct color format and fix hconcat issue with mismatched imager resolutions
    * Formatting
    * Add comment regarding compiler bug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
    [ovc.cpp]
2021-08-19 Host address configurable (#60)
    * Host address configurable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
    [config.yaml]
2021-08-19 Dynamic Parameters (#61)
    * Exposure adjustment
    * Remove dynamic bit-field init
    * Update exposure configuration to use floats instead of doubles
    * Frame rate param to host side (need to implement on device)
    * Device code to support frame rate
    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
    [Params.cfg]
2021-08-23 OVC5 Rev B Hardware (#56)
    * Correct board thickness. Switched P/N of top USB connector.
    * Holes on enclustra module corrected (layout correction still required)
    * Ignore autosaves and correct DIP switch part number
    * Swap RX/TX in schematic for FPGA USB3
    * Fixed picam connector orientations
    * Replace unidirectional level shifters with bidirectional level shifter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
    [BOM.csv, cameras.kicad_sch, enclustra_module.kicad_sch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]
2021-08-27 Json Messaging (#64)
    * Configure all cameras simultaneously (unconnected slots will be auto-ignored
    * JSON messages on device
    * libjsoncpp-dev requirement added to setup script
    * Host-side json support
    * Ros1 driver json support
    * Correct jsoncpp behavior
    * Adding clarification to the JSON form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
    [Params.cfg]
2021-08-30 Publish OVC3 VectorNav magnetometer (#70)
    * Fix compilation of current code in repo
    * Publish VNAV magnetometer
    * Frame id for VNAV mag and better topic names
2021-09-03 Dynamic camera count (#69)
    * Adjusting drivers to handle any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
    [ovc.cpp]
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2022-02-16 Update OVC5 to Xilinx tools version 2021.2 (#79)
    * WIP before update
    * Update to Vivado 2021.2
    * Add back udmabuf
    * Update driver config
    * Update comment
    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
    [bsp.cfg, u-boot.cfg]
2022-03-28 [Docs] Update link to KiCAD install instructions (#81)
    The previous KiCAD install instructions look is now invalid, and
    as such has been substituted for a working replacement.
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

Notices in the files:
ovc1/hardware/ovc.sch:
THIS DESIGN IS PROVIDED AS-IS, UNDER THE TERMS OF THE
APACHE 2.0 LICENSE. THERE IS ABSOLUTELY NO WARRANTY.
